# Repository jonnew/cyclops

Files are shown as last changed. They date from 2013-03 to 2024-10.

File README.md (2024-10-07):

## Cyclops LED Driver
Precision, wide-bandwidth current source with optional optical feedback mode
for driving high-power LEDs and laser diodes. Good for sneaking optogenetic
stimuli between fast things (e.g. galvo flyback on a 2P system). Good for
_really_ controlling the amount of light you deliver during 1P imaging or
optogenetic stimulation.

If you have questions or comments, please come talk on the [open-ephys discord server](https://discord.gg/H2pH4Cp8xb) 
in the #stimulation channel.

### Features
- Ultra-precise
- High power
- Up to 1.5A per LED
- Wide bandwidth
    - \~2.5 MHz -3 dB bandwidth
    - Maximum 100 ns 1.0A rise and fall times
- Current and optical feedback modes
- Built-in waveform generation
- Over-current protection
- Modular
    - Arduino compatible: internal waveform generation
    - Also, accepts external analog, gate, or trigger inputs

### Stimulus generation options
- External stimulus sequencer
- External digital trigger
    - TTL logic level
- External analog waveform generator
    - 0-5V analog signals
- Internal 12-bit DAC
    - Synchronized across up to 4 drivers
    - Arduino library
    - Programmable triggering logic
    - Respond to USB input

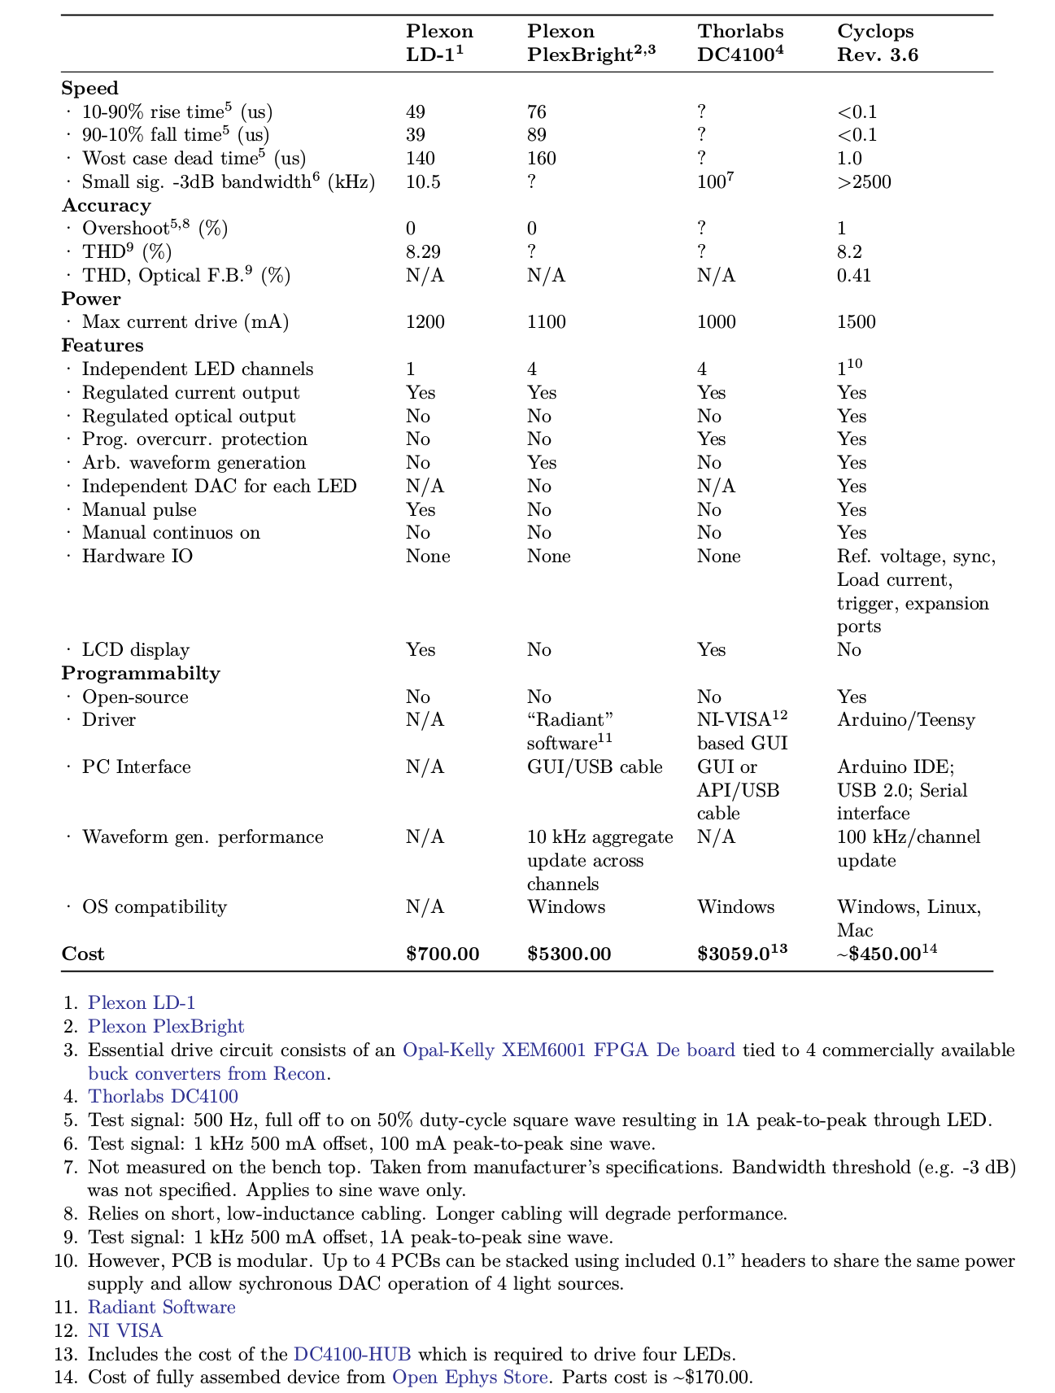
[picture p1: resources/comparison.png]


### Buying one
You can purchase a fully assembled cyclops driver from the [open-ephys
store](https://open-ephys.org/cyclops-led-driver). All profits go towards continued
operation of open-ephys.

### Documentation
Documentation and usage information are here: [MANUAL.pdf](./MANUAL.pdf). If you
have questions concerning usage, performance, etc., please direct them toward
the [Open Ephys forum](https://groups.google.com/forum/#!forum/open-ephys).

### Hardware Licensing
Copyright Jonathan P. Newman 2020.

This work is licensed under CC BY-NC-SA 4.0. To view a copy of this license,
visit https://creativecommons.org/licenses/by-nc-sa/4.0

__Note__: This license applies to hardware designs and documentation which reside
in the 'device', 'experimental', 'resources' folders of this repository along
with information in 'MANUAL.md' and 'MANUAL.pdf'

### Software Licensing
Copyright (c) Jonathan P. Newman 2017. All right reserved.

The code associated with the Cyclops project is free software: you can
redistribute it and/or modify it under the terms of the GNU General Public
License as published by the Free Software Foundation, either version 3 of the
License, or (at your option) any later version.

The code associated with the Cyclops project is distributed in the hope that it
will be useful, but WITHOUT ANY WARRANTY; without even the implied warranty of
MERCHANTABILITY or FITNESS FOR A PARTICULAR PURPOSE.  See the GNU General
Public License for more details.

You should have received a copy of the GNU General Public License along with
this code.  If not, see <http://www.gnu.org/licenses/>.

__Note__: This license applies to software/fireware source code which resides in in
the 'lib' folder of this repository

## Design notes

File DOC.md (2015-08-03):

__Cyclops__ is a high-power LED driver that enables precise control of light
power for optogenetic stimulation. The circuit was developed by Jon Newman
while in Steve Potter's lab at Georgia Tech in order to complete his thesis
work, which required the delivery of ultra-precise, continuously time-varying
light waveforms for optogenetic stimulation [1].  This was, and still is, not
possible with commercial hardware for optogenetic stimulation. Since its first
use, the circuit has been improved in terms of speed, precision,
programmability, and ease of use. This document provides construction, usage,
and performance documentation for the Cyclops LED driver. This document evolves
with the repository. To view old revisions, checkout tags or old commits using
their SHA.

<!-- START doctoc generated TOC please keep comment here to allow auto update -->
<!-- DON'T EDIT THIS SECTION, INSTEAD RE-RUN doctoc TO UPDATE -->
**Table of Contents**  *generated with [DocToc](https://github.com/thlorenz/doctoc)*

- [Features](#features)
- [Performance Specifications](#performance-specifications)
- [Usage](#usage)
  - [Feedback Modes](#feedback-modes)
    - [Current Feedback Mode](#current-feedback-mode)
    - [Auxiliary Feedback Mode](#auxiliary-feedback-mode)
  - [Stimulus Generation Options](#stimulus-generation-options)
- [Construction](#construction)
  - [Components](#components)
  - [PCB Assembly](#pcb-assembly)
  - [Enclosure](#enclosure)
  - [Circuit testing](#circuit-testing)
- [License](#license)
  - [Hardware Licensing <a rel="license"](#hardware-licensing-a-rellicense)
  - [Software Licensing](#software-licensing)
- [References](#references)
- [TODO](#todo)

<!-- END doctoc generated TOC please keep comment here to allow auto update -->

### Features
**Circuit Features**

- Ultra-precise
- High power
- Up to 1.5A per LED
- Wide bandwidth
  - ~2.5 MHz -3 dB bandwidth
  - <200 ns 1.0A rise-time
- Current and optical feedback modes
- Built-in waveform generation
- Over-current protection
- Modular
  - Arduino compatible
  - 4 synchronizable optical channels
  - Accepts external analog, gate, or trigger inputs

**Stimulus Generation Options**

- External stimulus sequencer
- External digital trigger
  - TTL logic level
- External analog waveform generator
  - 0-5V analog signals
- Internal 12-bit DAC
  - Synchronized across up to 4 drivers
  - Powerful Arduino library
  - Programmable triggering logic
  - Respond to USB input

### Performance Specifications
TODO

### Usage
#### Feedback Modes
The main functional component of the device is a feedback assisted, power,
enhancement-mode N-MOSFET
([IRF510](http://www.vishay.com/docs/91015/sihf510.pdf)). Current is drawn from
the source pin of the FET in accordance with one of two feedback modes: **current
feedback** or **auxiliary feedback**. In both modes, the FET acts as a variable
resistor whose resistance is changed in inverse relation to the gate voltage.
The difference between the two modes is in how the gate voltage is regulated.

- In **current feedback mode**, the gate voltage is adjusted such that the
  voltage drop across the sense resistor (RSENSE = 1 ohm in the schematic) is
  equal to a supplied reference voltage.
- In **auxiliary feedback mode**, some external voltage that has a positive and
  monotonic relationship with optical power is provided as a feedback signal.
  This is feedback voltage is typically supplied by an amplified photodiode

##### Current Feedback Mode
To use current feedback mode, push the rear slide switch to the CURR position (Current feedback mode.).
Using the circuit in current feedback mode ensures that the forward current
across the LED is precisely regulated according the voltage at the VREF pin.
This configuration is a standard method for driving LEDs because the
relationship between current and LED irradiance is smooth and monotonic. This
means that more current across the LED will generate more light power (while
staying within the LED's maximum ratings, of course). However, the relationship
between current and irradiance is not linear. For most LEDs, it looks like a
logarithmic function. Additionally, the efficiency of the LED is inversely
related to its temperature. So, as the LED operates and heats up, the amount of
light it produces drops even when the current is held constant. The severity of
an LED's temperature dependence and current/irradiance nonlinearity depend on
the type of LED (roughly, the color and who made it). These properties should
be clearly documented in the LED's data sheet. With a quality LED and proper
thermal management, the effects of temperature and static current/irradiance
nonlinearity are fairly minimal and can be ignored in most situations.

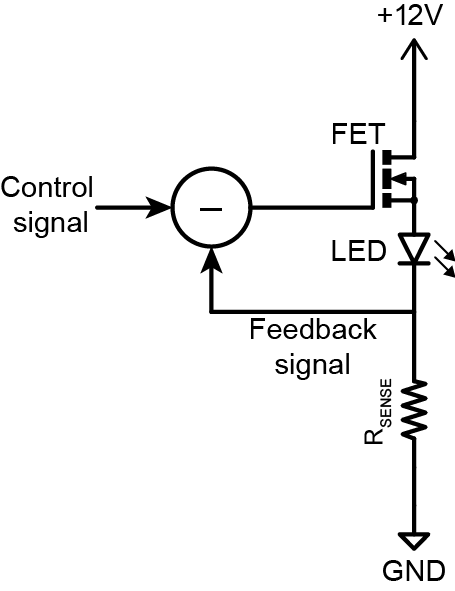
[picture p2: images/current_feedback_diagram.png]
Current feedback configuration.


##### Auxiliary Feedback Mode
To use auxilary feedback mode, push the rear slide switch to the AUX position (Auxilary feedback mode.).
When extremely stable, linear control of light power is required, the auxiliary
feedback input can be used to used to compensate for the temperature dependence
and static nonlinearity of the current/irradiance relationship of the LED. For
example, when the auxiliary voltage is supplied by an amplified photodiode that
is somewhere indecent to radiation from the LED, or is sampled from the fiber
transporting LED light, the gate voltage is adjusted such that the measured
light power matches a DAC-supplied reference voltage.  This is the case in the
circuit diagram. This configuration is referred to as optical feedback mode.
The [PDA36A](https://www.thorlabs.com/thorProduct.cfm?partNumber=PDA36A)
adjustable amplified photodiode from Thorlabs is a good option for supplying
optical feedback. However, you can make your own amplified photodiode for a
fraction of the price, and a design is included within the cyclops repository.
Optical feedback completely linearizes the relationship between a supplied
reference voltage and the light power produced by the LED by compensating for
the current/irradiance nonlinearities and temperature dependence.

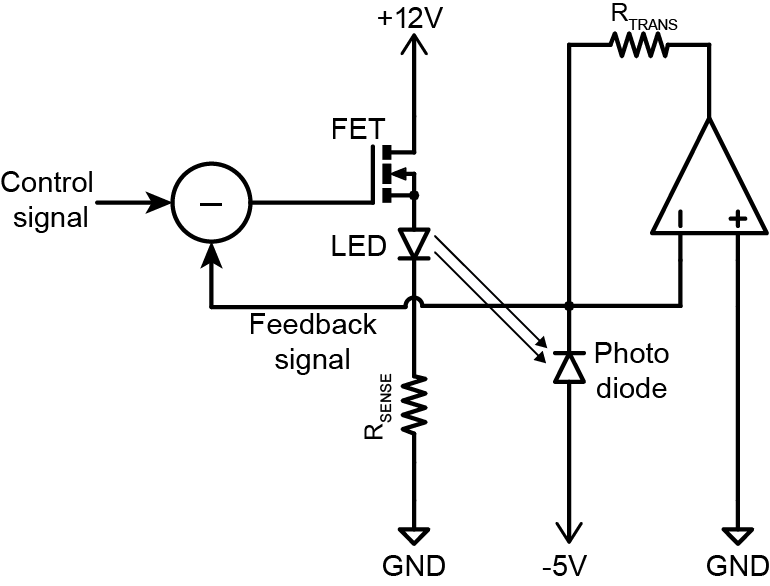
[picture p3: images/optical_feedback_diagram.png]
Optical feedback configuration.


#### Stimulus Generation Options
There are three ways to generate light signals using the driver. The behavior
of each of these options is dependent on the feedback mode being used. The
behavior of each input option is described in relation to the feedback mode of
the driver.

1. Test button. The test button is always available and will override all other input
   modes. Using the `TEST` button the behavior of the circuit is:

  - Current feedback mode. Source the current specified by the MAX CURR. dial.
  - Auxilary feedback mode. Generate the optical power specified by the h * mW
    level that is  specified by the MAX POWER dial. The intensity of the LED
    will be dependent on the auxiliary feedback signal used which defines the
    'h' parameter. 

2. EXT mode. External input mode is engaged when the SOURCE switch is moved to the EXT
position and user supplied voltage waveforms are present at the EXT BNC input.
If the user attempts to supply more than 5V to the EXT input, the circuit will
clamp the input signal to 5V. Using `EXT` mode, the behavior of the circuit is:

  - Current feedback mode. Source the current specified by (EXT Voltage / 5V) *
    MAX CURR. 
  - Auxilary feedback mode. Generate the optical power specified by (EXT
    Voltage/5V) * h  * mW. The intensity of the LED will be dependent on the
    auxiliary feedback signal used which defines the 'h' parameter. 

3. DAC mode. The internal DAC is engaged when the SOURCE switch is moved to the
DAC position and can be used to generate pre-programmed waveforms and waveform
sequences triggered by a digital pulse to the TRIG input. This feature relies
on optional Arduino installation and programming the device using its API.
Using the `DAC` mode, the behavior of the circuit is:

  - Current feedback mode. Source the current specified by (DAC Voltage / 5V) *
    MAX CURR. 
  - Auxilary feedback mode. Generate the optical power specified by (DAC
    Voltage/5V) * h  * mW. The intensity of the LED will be dependent on the
    auxiliary feedback signal used which defines the 'h' parameter. 

### Construction 
If you have questions during device assembly, please direct them to the
[open-ephys forum](https://groups.google.com/forum/#!forum/open-ephys) so that
others may benefit.

#### Components 
The bill of materials (BOM) required to build a 1,2,3, or 4 devices is
available on [this google
doc](https://docs.google.com/spreadsheets/d/1YQR_ujrZgILNx3XjomLKWgzDvirwKrKaRbVVzmBgk-s/edit?usp=sharing).
Most of the parts can be purchased from Digikey, but there are a few components
that need to be bought from other sources such as Newark, Adafruit, and Samtec.
All vendor, part number, and quantity information is listed on the BOM. If you
are having trouble getting a part, check the BOM since there are alternative
suppliers listed for some parts. As a convenience, the spreadsheet contains
links to a pre-populated Digikey cart (which are optimized for quantity
discounts).

The PCB can be purchased from OSH park
[here](https://oshpark.com/shared_projects/N5vW5JmD) or Seed Studio
[here](http://www.seeedstudio.com/service/). This is a four layer PCB. Note
that OSH park sells a minimum of 3 boards per order and Seed studio sells a
minimum of 5 boards per order. PCB stencils, useful for those performing reflow
or hot-air soldering, can be purchased from a service like [OSH
stencils](https://www.oshstencils.com) using the gerber files located in
`./cyclops/stencil`. If you plan to hand solder the board, then you do not need
to purchase these stencils.

The BOM includes several optional components, which are not in the
pre-populated Digikey cart. These include:

- An __extruded aluminum enclosure__, which houses the completed board. The
  enclosure is recommended because the large voltages and current transients
  used to drive high power LEDs can cause capacitive and inductive interference
  with nearby recording equipment. Acrylic front and rear panels can be
  purchased from Ponoko using the links supplied in the BOM. The instructions
  below show how these plastic pieces are modified to provide proper electrical
  shielding.
- An __M8-4 connector__. This is a rather expensive connector that allows
  cyclops to drive [Thorlabs LED
  modules](https://www.thorlabs.com/newgrouppage9.cfm?objectgroup_id=5206) or
  [Doric LED modules](http://doriclenses.com/life-sciences/243-led-modules).
    
#### PCB 
The cyclops PCB can be constructed by purchasing from one of the
pre-uploaded options:

- [OSH Park](https://oshpark.com/shared_projects/N5vW5JmD) - made in America, excellent quality.
- [Seeed Studio]() - made in China, very good quality.

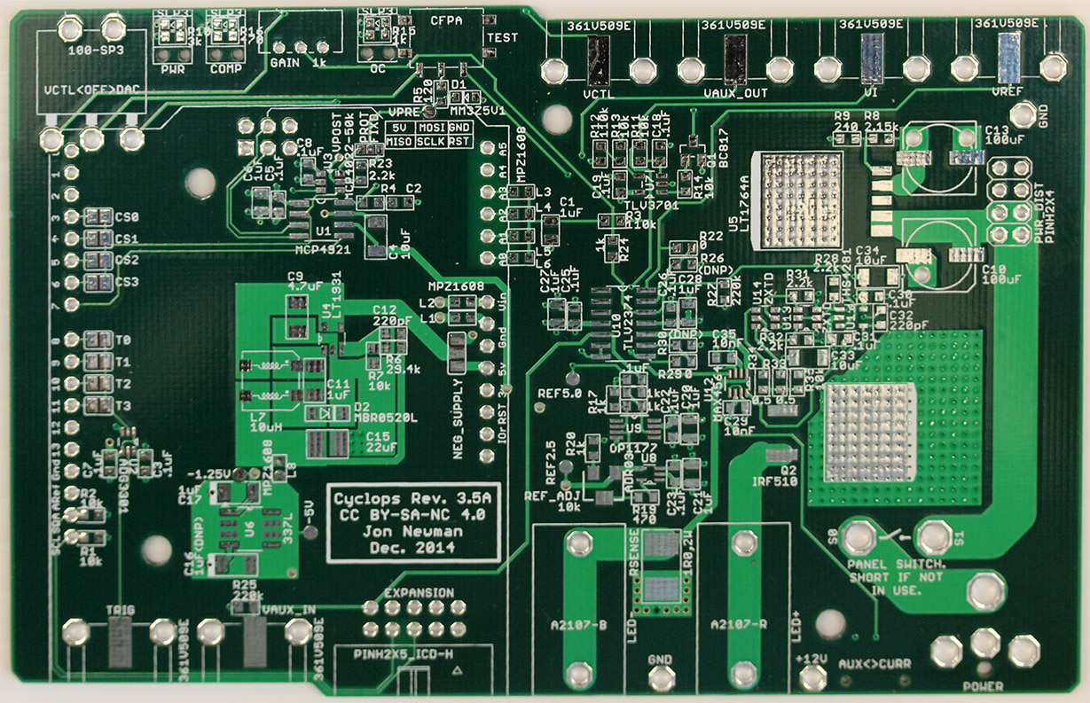
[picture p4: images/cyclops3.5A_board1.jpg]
A bare Cyclops PCB, top side, purchased from Seeed Studio.


Alternatively, the [gerber files](./cyclops/gerber/) can be uploaded to the PCB
fabrication service of your choice. The layer of each gerber file is identified
by its file extension:

     *.GKO = board outline 
     *.GTS = top solder mask 
     *.GBS = bottom solder mask
     *.GTO = top silk screen 
     *.GBO = bottom silk screen 
     *.GTL = top copper
     *.G2L = inner layer 2 copper 
     *.G3L = inner layer 3 copper 
     *.GBL = bottom copper 
     *.XLN = drill hits and sizes

#### PCB Assembly 
To assemble the PCB, you will need the following materials

- A soldering device. At minimum, a soldering iron regulated to ~370 deg.  c)
  will do the job. However, a hot-air rework tool or reflow oven are
  recommended and the assembly instructions below assume you are using one of
  these two options. A low cost, high-quality hot-air rework station can be
  purchased from SparkFun [here](https://www.sparkfun.com/products/10706).
- Copper braid ('solder wick') for solder removal (e.g
  [this](https://www.sparkfun.com/products/9327))
- Stereoscope or loupe (Optional) 
- Liquid flux (No-clean variants are easiest since they don't have to be
  removed after use)
- Isopropyl alcohol for cleaning flux off the board (e.g.
  [thos](http://amzn.com/B0047YB3OW); Optional)
- An anti-static mat (e.g. [this](http://amzn.com/B00009XT3H); Optional)

PCB component population and soldering is fairly straightforward and requires
standard surface mount construction techniques.

- A tutorial on hot-air soldering can be found [here](https://youtu.be/1z0IiuQ35HU).
- A great tutorial filled with general tips and tricks for surface mount soldering can be
found [here](https://youtu.be/pdGSFc7VjBE).

The following steps provide a visual guide to construct your own board. The
goal is to create a fully populated PCB like this one: 

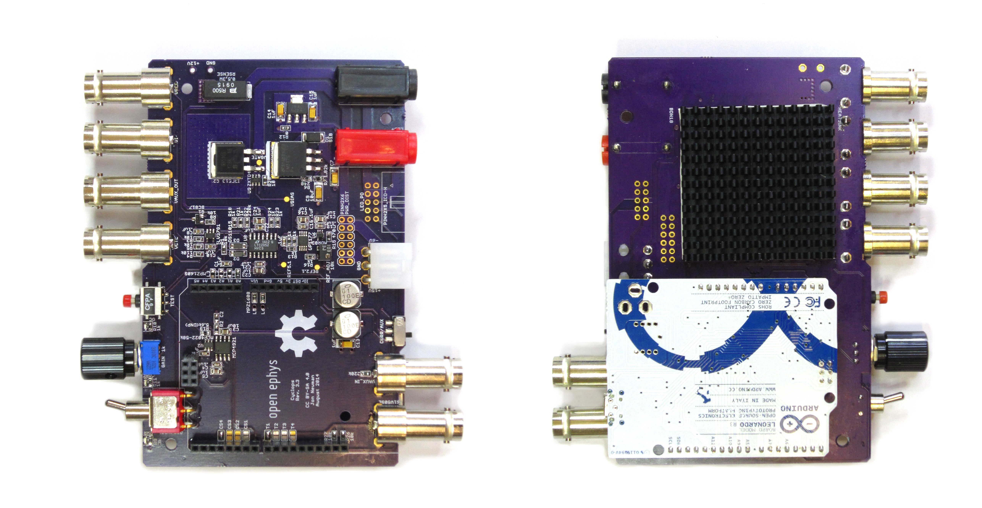
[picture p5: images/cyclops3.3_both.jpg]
Finished device (revision 3.3).


_After construction, you should run through the electrical tests outlined in
the next section before applying power to the board._

0. Place the bare PCB on a flat surface, preferably one that is static
   dissipative or anti-static. 

0. Below are pictured some of the materials you will need to construct a board.

    ![Wire solder and an soldering iron can be used to construct the PCB, but
    solder paste combined with a hot air rework station or a reflow oven makes
    things much easier. We use [Chipquik
    291ax10](http://www.digikey.com/product-detail/en/SMD291AX10T5/SMD291AX10T5-ND/3972568).](./images/SolderPaste.jpg)
  
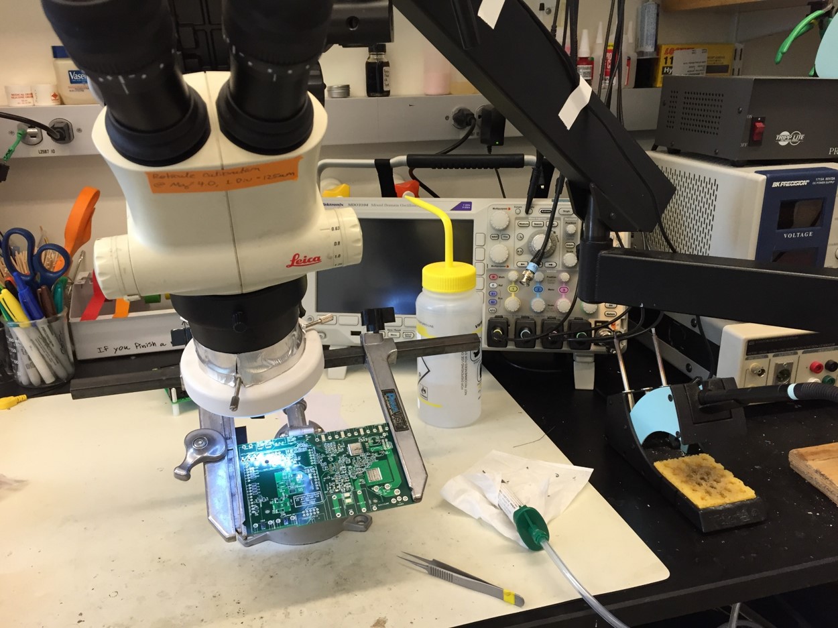
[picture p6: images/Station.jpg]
Instead of populating components on a table, holding the PCB using a PanaVise can be helpful.
    
  
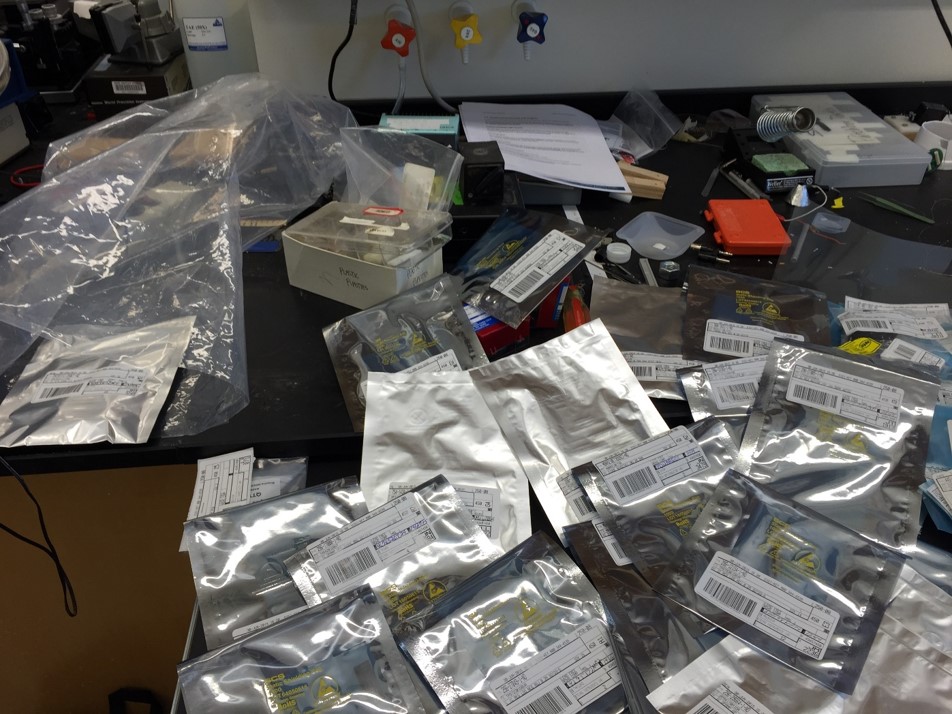
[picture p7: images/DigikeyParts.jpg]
Circuit components. A complete bill of materials is provided in the [BOM](https://docs.google.com/spreadsheets/d/1YQR_ujrZgILNx3XjomLKWgzDvirwKrKaRbVVzmBgk-s/edit?usp=sharing).
    
  
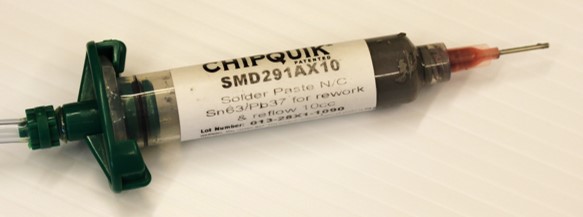
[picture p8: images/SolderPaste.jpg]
A soldering iron can be used to assemble the PCB, but a hot air rework station makes things much easier. These can be purchased from [Sparkfun](https://www.sparkfun.com/products/10706).
    

0. The silkscreen layer on the PCB (white text) has almost all the information
   you will need to properly populated the PCB. However, its a good ideal to to
   open the [cyclops design](./cyclops/cyclops_r3.brd) in
   [EAGLE](http://www.cadsoftusa.com/eagle-pcb-design-software/). This will
   allow you to get detailed information on components before placing them on
   the board.

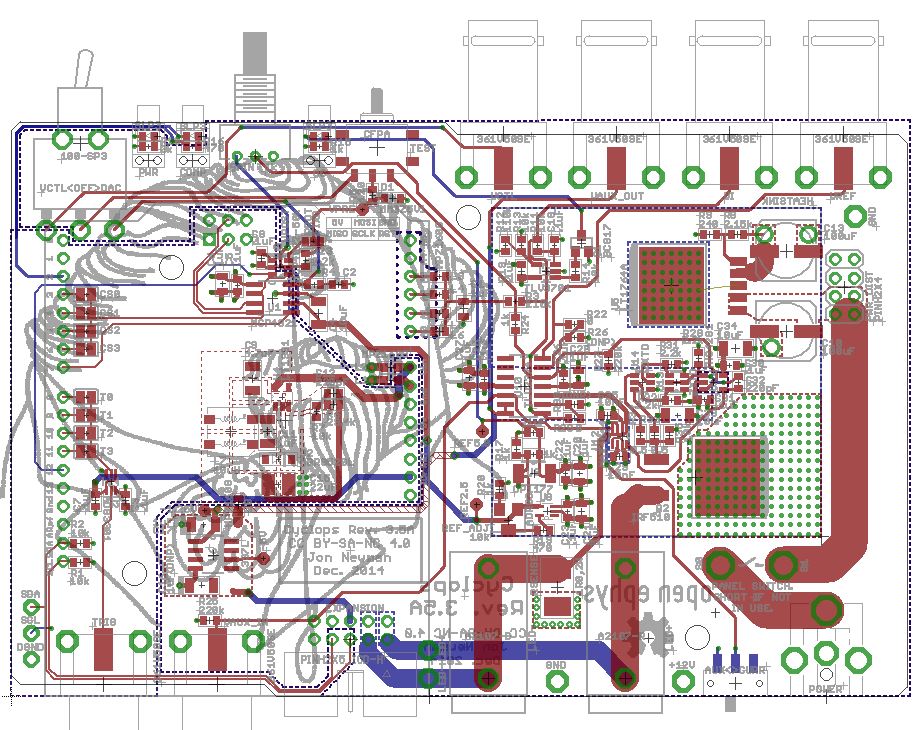
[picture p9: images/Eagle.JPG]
The cyclops PCB design in CadSoft EAGLE
    
  
    You can then the `information` tool to get detailed information on each
    component, e.g. to ensure you are placing the correct value resistor or
    capacitor.
  
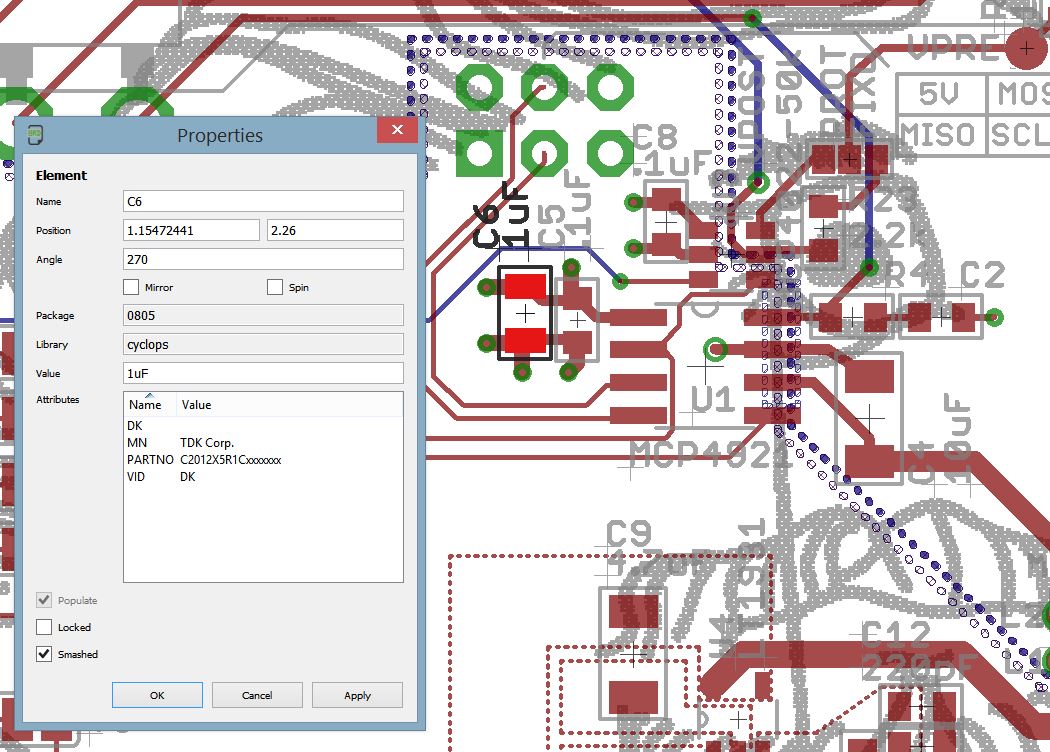
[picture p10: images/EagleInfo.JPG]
By selecting the information tool and clicking the cross at the center of a component, you can pull up detailed info (e.g. part number)
    

0. After cleaning the surface of the board with isopropyl acholhol or similar,
   apply solder paste to each of the pads. For an excellent series of tips on
   effective methods for dispensing solder paste, see [Mike's video on the
   subject](https://youtu.be/pdGSFc7VjBE). Do not apply solder paste to
   through-holes or the pads shown outlined in red in the following image.
   These will be hand soldered later in the assembly process.

    Do not apply paste these solder pads.
  
    The correct amount of solder paste to apply is 'enough'. Each component
    contact should sit in a small amount of paste, but blobs of paste that
    envelop the component pad or pin may later result in a short. The following images
    show examples of good and bad solder placement.
  
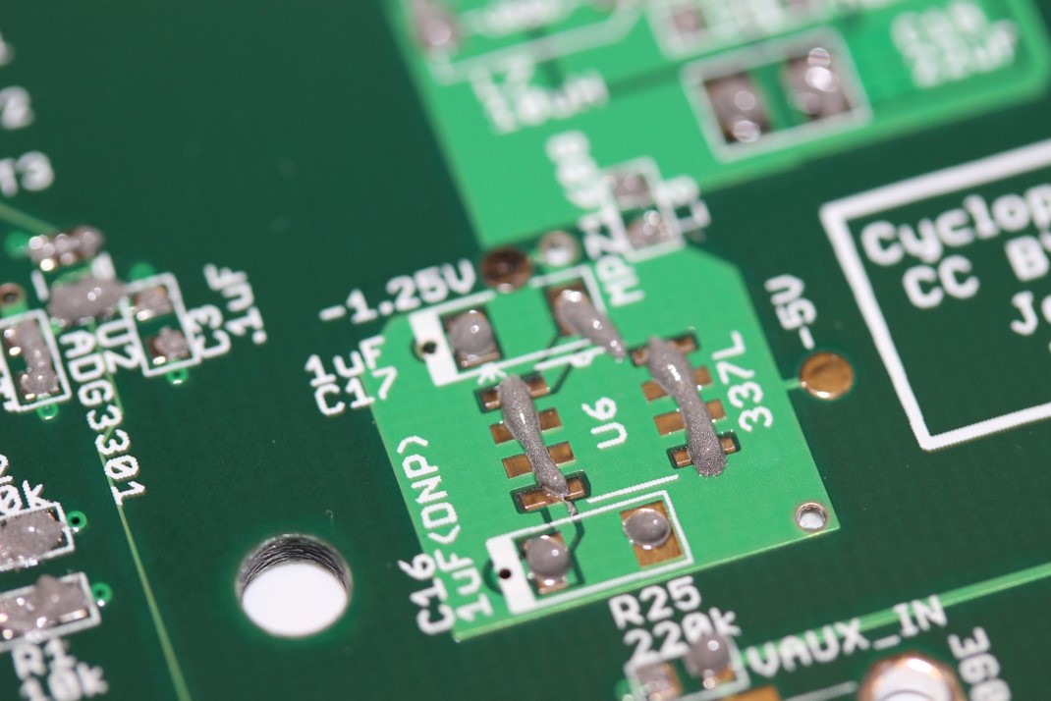
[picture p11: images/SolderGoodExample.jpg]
Good solder placement.
    
  
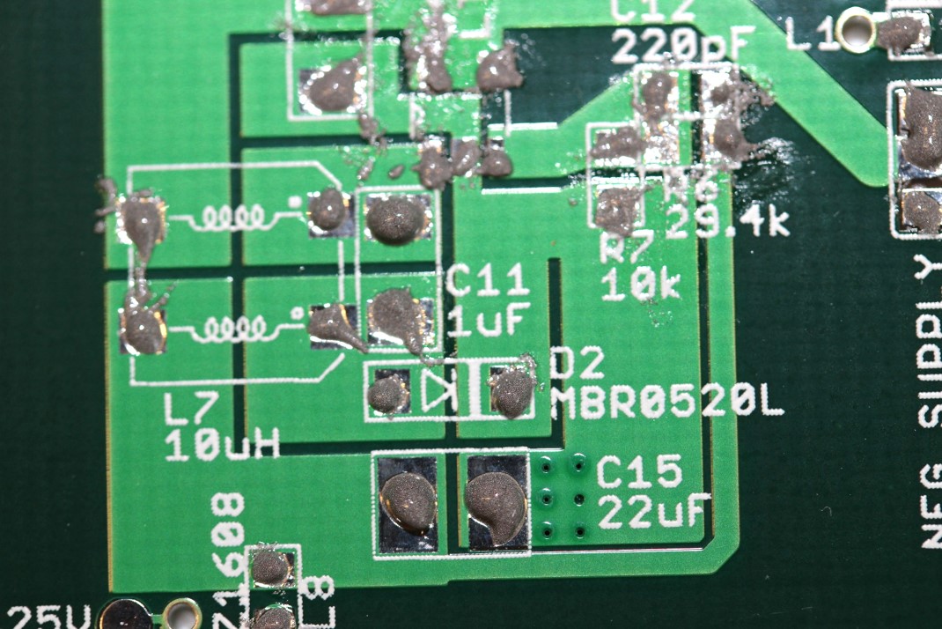
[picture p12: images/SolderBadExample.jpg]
Bad solder placement. Too much paste!
    

    If you need to pause at any point, you should store place the PCB in the
    fridge to prevent the flux in the solder paste from breaking down. 

0. You can look at the picture below and put solder on the exact same gold plates as in the picture. I actually missed some gold plates at this step, but don't worry for now. You can put solder just like this.

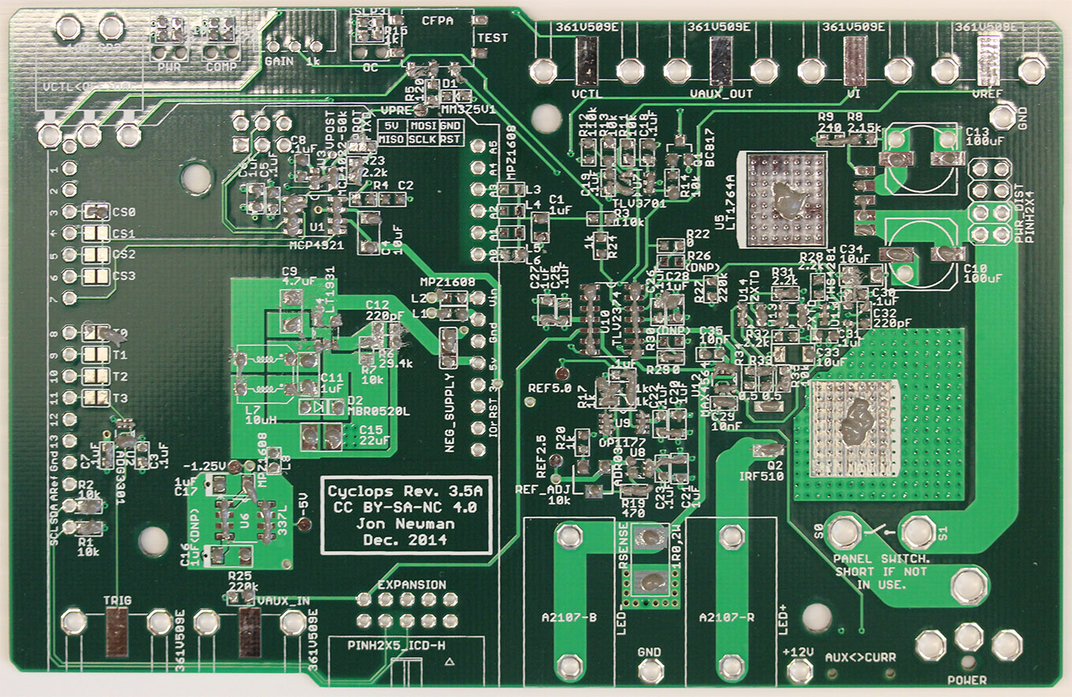
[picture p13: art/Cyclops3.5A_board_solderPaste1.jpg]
    <div align="center">  <br> <b>Fig. 7</b> <i>After putting solder paste to all necessary slots (a few are missing here) </i> </div>

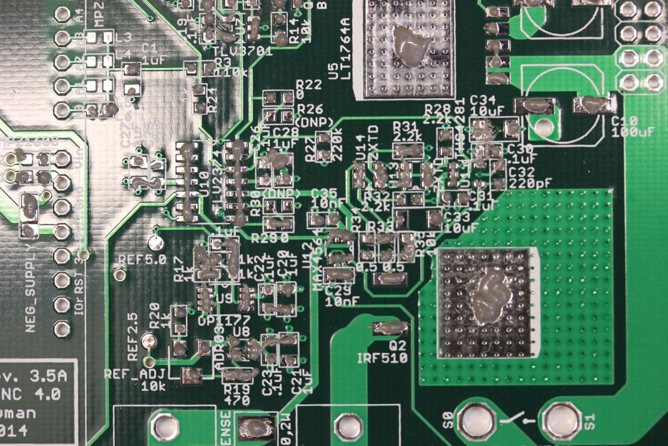
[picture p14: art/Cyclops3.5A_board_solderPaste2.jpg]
    <div align="center">  <br> <b>Fig. 8</b> <i>Closer look 1. Too much solder in general, but will work</i> </div>

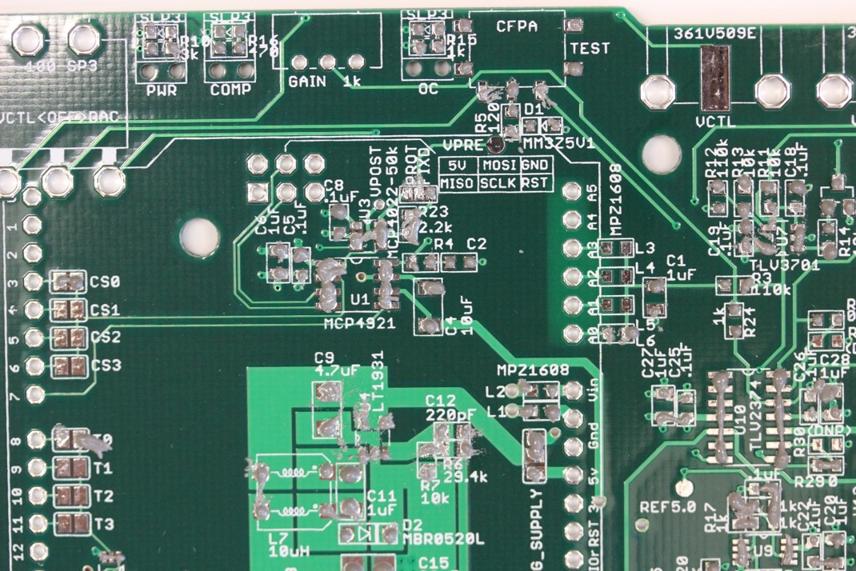
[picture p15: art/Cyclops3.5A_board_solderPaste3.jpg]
    <div align="center">  <br> <b>Fig. 9</b> <i>Closer look 2. Too much solder in general, but will work</i> </div>

0. Populate all __top-side surface mount__ components on the board. There is a
   single surface mount switch on the back of the board that will be hand
   soldered later. Additionally, all through hole components (e.g. power jack,
   BNC connectors, etc) will be populated later. Start by placing the
   integrated circuits (ICs). Use the stereoscope or loupe to ensure that pads
   are making contact with the pins of the placed components.  Precise
   component alignment is not necessary.  Components will self-align during the
   reflow process.

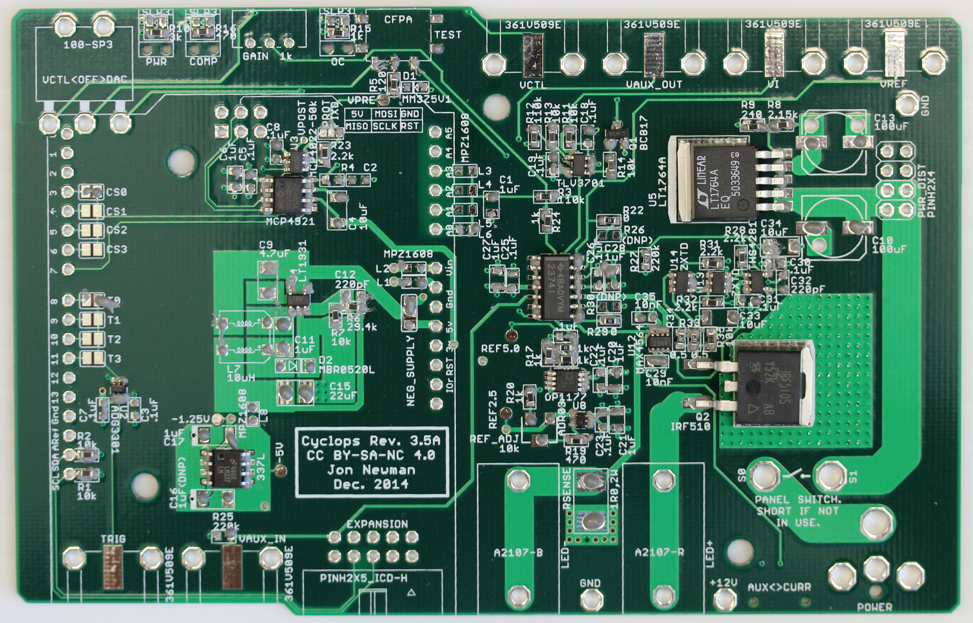
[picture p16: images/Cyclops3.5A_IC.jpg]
    

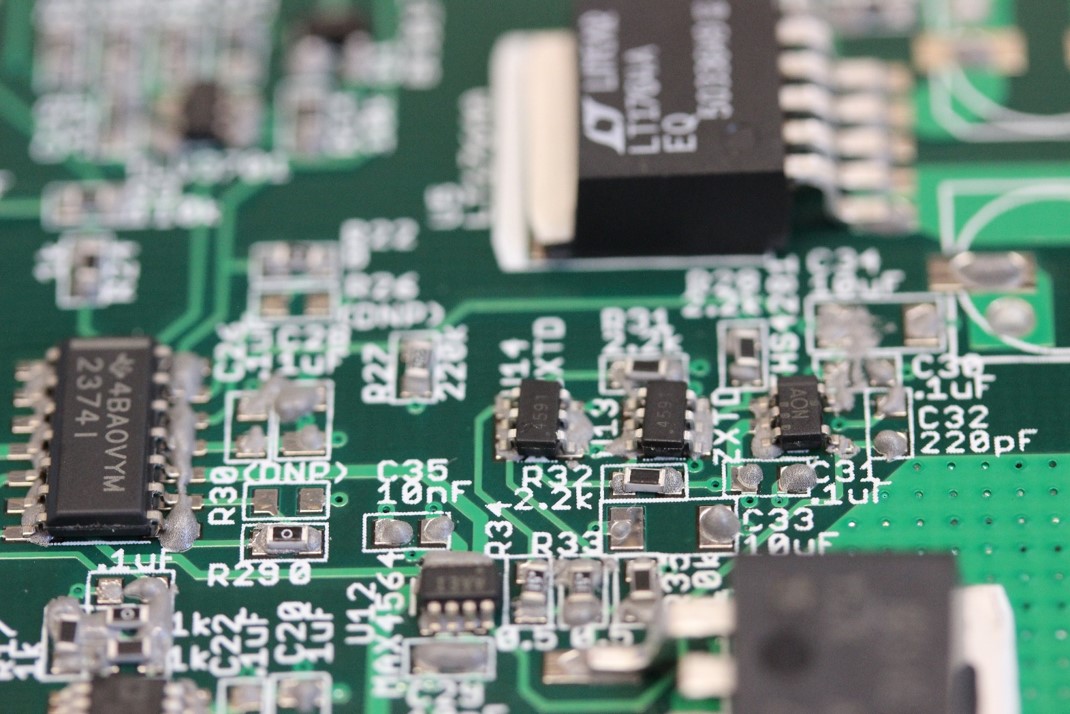
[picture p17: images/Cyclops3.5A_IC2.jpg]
Zoomed view of ingegrated circuit placement.
    

0. After placing the ICs, place the passive components (resistors,
   capacitors, inductors, and diodes).  

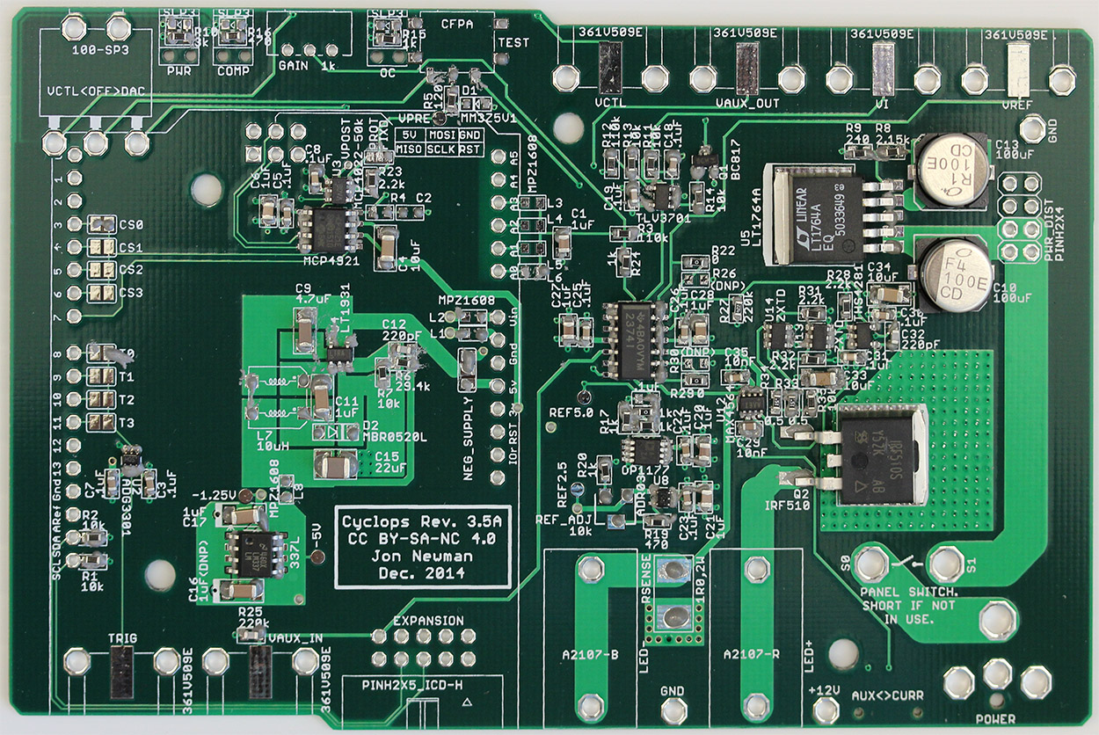
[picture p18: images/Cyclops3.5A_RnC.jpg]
    

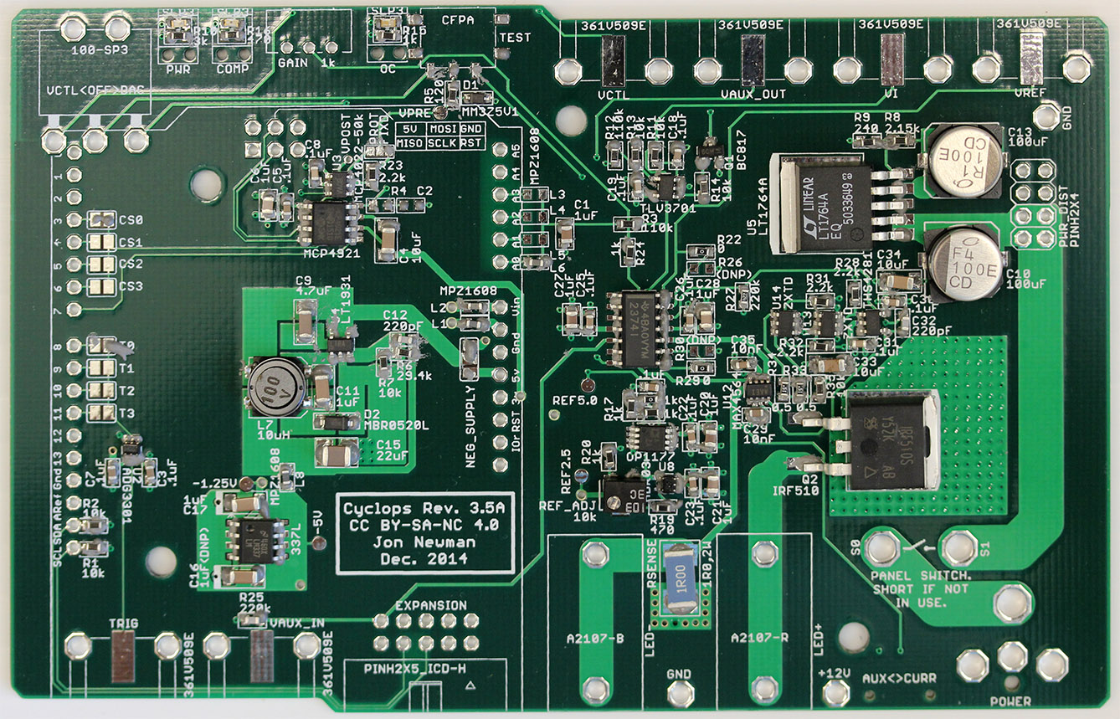
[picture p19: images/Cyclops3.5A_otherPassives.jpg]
    

0. Next step is to reflow solder. Let me show my homemade reflow oven. You can make a similar one or use a commercial one. Reflow the solder paste on the board using your oven or hot air gun as
described in the links above.  After the solder has cooled, examine solder pads
using the stereoscope of loupe for solder bridges between pins, solder that has
not melted, or pads lacking a decent solder joint Fix any issues using a
standard soldering iron If there are solder bridges present, get rid of them
using some solder wick before moving on.  Solder through-hole components in
place using a standard soldering iron. A low cost reflow oven can be made form a toaster oven as shown here. This link also
contains useful information on the basics of the reflow soldering process,

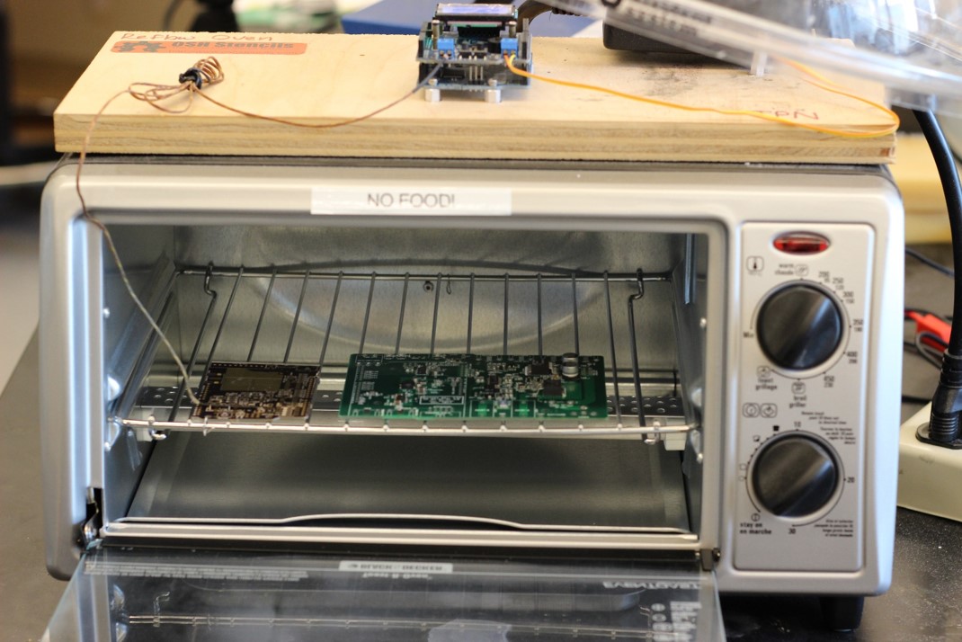
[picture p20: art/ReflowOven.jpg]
    <div align="center">  <br> <b>Fig. 14</b> <i>Carefully bring the PCB and place it in the oven like this.</i> </div>

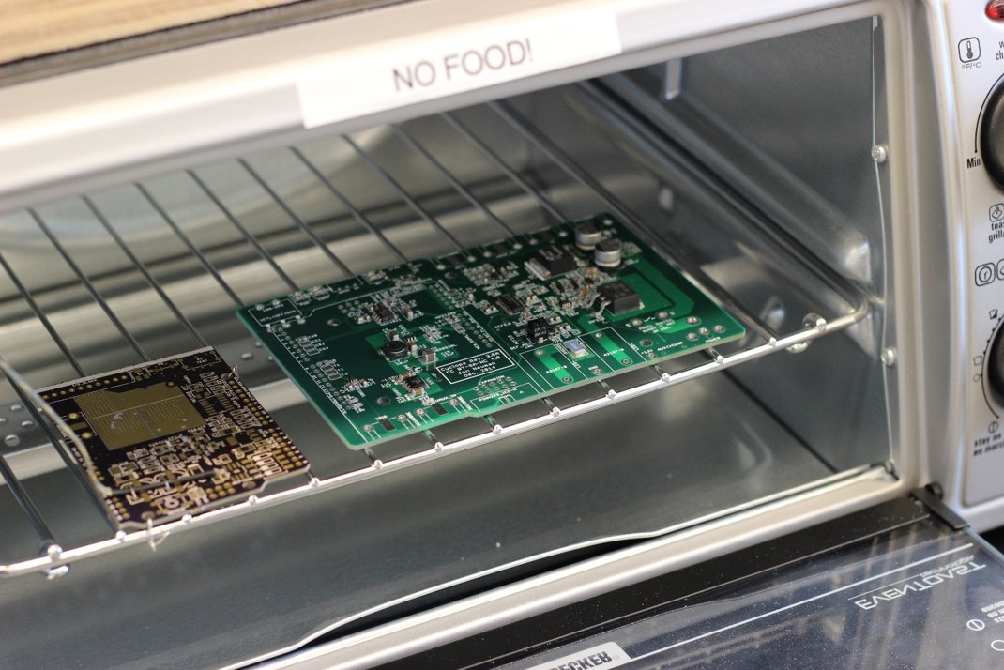
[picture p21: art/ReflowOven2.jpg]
    <div align="center">  <br> <i>Here is a closer look.</i> </div>

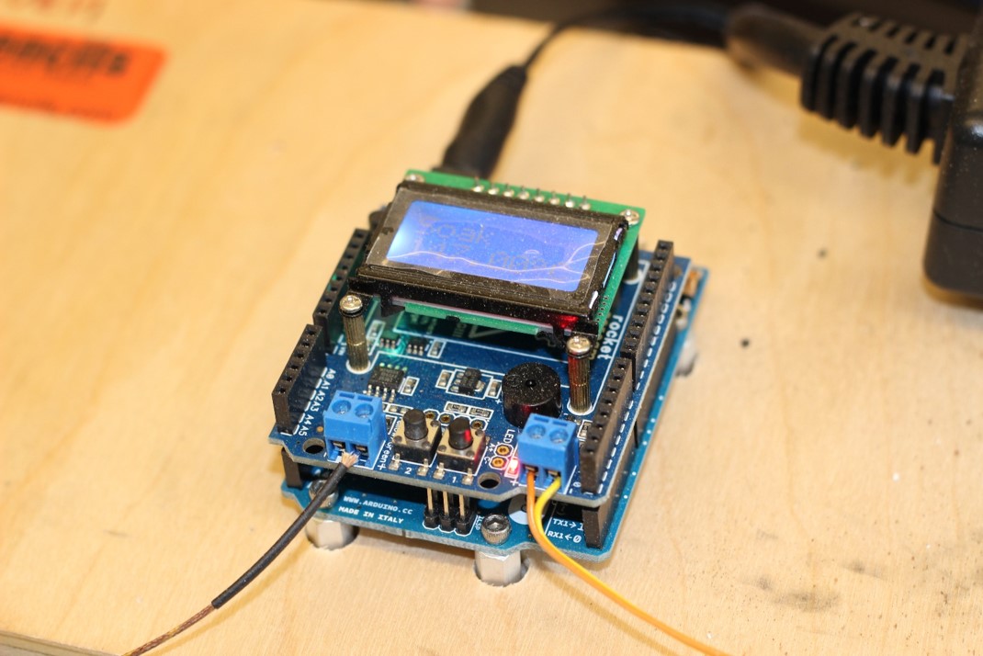
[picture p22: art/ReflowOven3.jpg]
    <div align="center">  <br> <i>A board...</i> </div>

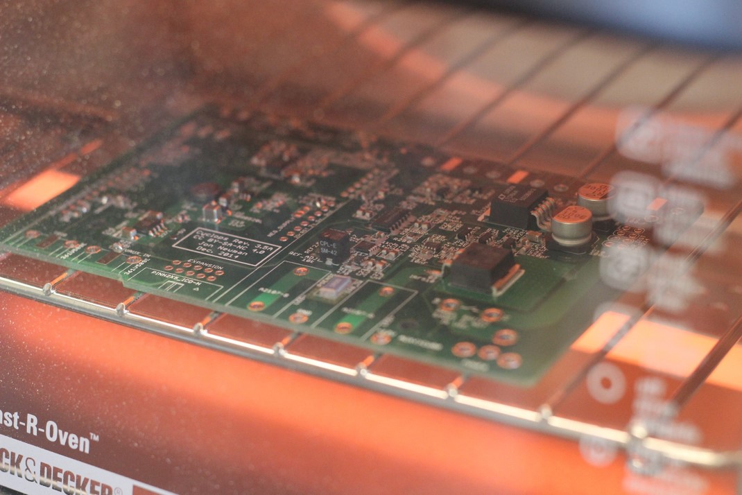
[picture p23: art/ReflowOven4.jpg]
    <div align="center">  <br> <i>As it goes above 200C, the solder starts to reflow. Like a live worm</i> </div>

0. After reflow, take the PCB out and check for possible shorts. We need to fix it.

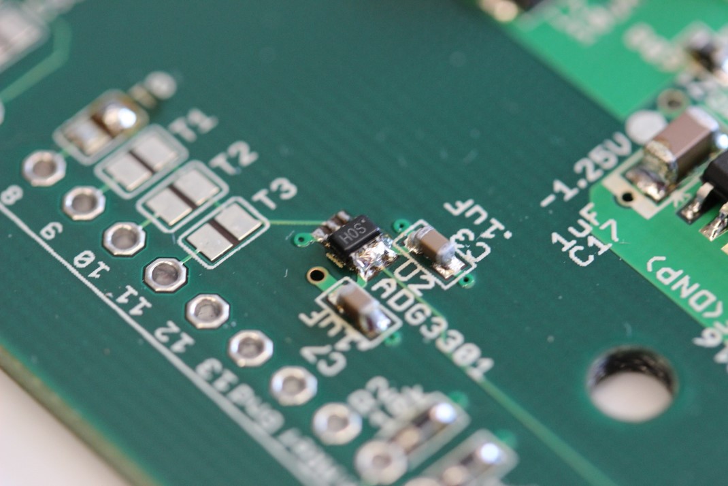
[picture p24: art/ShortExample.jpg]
    <div align="center">  <br> <b>Fig. 15</b> <i>See the blob of solder there?</i> </div>

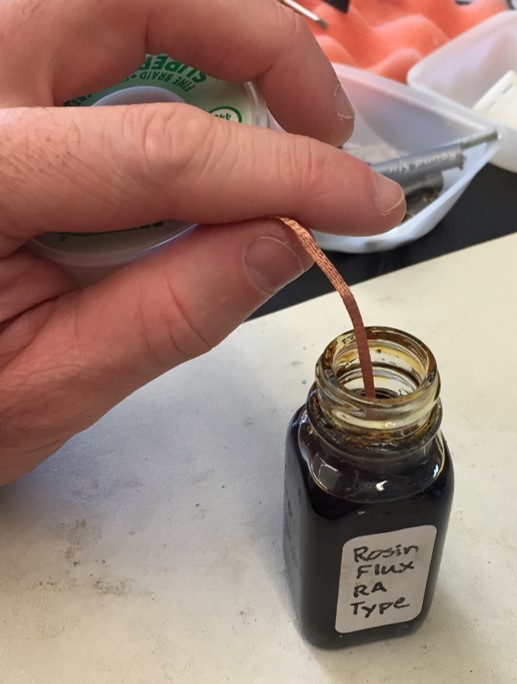
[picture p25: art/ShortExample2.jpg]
    <div align="center">  <br> <b>Fig. 16</b> <i>Use this solder remover and flux</i> </div>

    <div align="center">  <br> <b>Fig. 17</b> <i>Bring it to the solder blob and sort of press it down with solder. Then the solder gets absorbed to the remover.</i> </div>

    <div align="center">  <br> <b>Fig. 18</b> <i>Problem fixed! There is enough solder after removal, so mostly you don't need to worry about connection.</i> </div>

    <div align="center">  <br> <i>By the way, there are some differences between different versions of the board. For example, 1 kOhm there in the middle of the picture was replaced to a 0 ohm one in the newer version.</i> </div>

0. Now populate all electromechanical parts. The barrel power jack (name: "POWER", value: PJ-063BH on the schematic)
should be mounted on the _bottom_ of the board. It fits on both the top and the
bottom, and will properly supply the board with power if mounted on the top.
However, if the barrel jack is mounted on the top side of the board, it will
not fit inside the enclosure.

    <div align="center">  <br> <b>Fig. 19</b> <i>After populating all electromechanicals. Front side.</i> </div>

    <div align="center">  <br> <b>Fig. 20</b> <i>After populating all electromechanicals. Back side.</i> </div>

    <div align="center">  <br> <i>Front side..</i> </div>

    <div align="center">  <br> <i>Front side, with different camera focus..</i> </div>

    <div align="center">  <br> <i>Back side..</i> </div>

    <div align="center">  <br> <i>Back side, with different camera focus..</i> </div>

0. Don't forget to install the heatsink.

0. The light pipes over the front LEDs need to be seated firmly for the board
to fit inside the enclosure.

0. Each board has an address (0 through 3) that is defined by two solder
jumpers and the location of a ferrite chip. This allows cyclops boards to be
stacked to share a power supply while being driven by a common microcontroller.
For each board that will share a microcontroller, a unique address must be
specified and the solder jumpers and ferrite chip must be soldered in
appropriate positions to reflect this address. See the picture below to better
understand this addressing scheme.

0. Finally, let's install the power switch. You need to hookup wire capable of
handling the currents that the driver requires. AWG 20 (~0.8 mm diameter)
braided copper wire or thicker is recommended. Even if you don't want to use
the power switch, jumper the switch solder points using AWG 20 wire or thicker.

    <div align="center">  <br> <b>Fig. 21</b> <i>Power switch.</i> </div>

    <div align="center">  <br> <b>Fig. 22</b> <i>Front side.</i> </div>

    <div align="center">  <br> <b>Fig. 23</b> <i>Back side.</i> </div>

#### Enclosure
To construct the enclosure, you we will use the following materials

- Phillips head screwdriver (if
you are using the enclosure) 
- A white paint pen (e.g. these)
- Conductive coating for EMI suppression (e.g. this).

#### Circuit testing
To perform basic electrical testing, you we will use the following materials

- Multimeter. A low cost mulitmeter is available from
[sparkfun](https://www.sparkfun.com/products/12966).
- Jeweler's flat head screwdriver.
- Oscilloscope (optional, but recommended for performance verification)

0. Before powering on the device, check for shorts
between power traces on the board. Put your multimeter in continuity mode
Check for shorts between the Digital rail (TPXX) and ground (TPGND) Analog rail
and ground If there is a short, you must track it down and get rid of it before
applying power. If you find a short, test the same contact points on an unpopluated PCB to ensure that it is not due to a PCB fabrication defect. If so, contact your PCB for a return.

### License 
#### Hardware Licensing <a rel="license"
href="http://creativecommons.org/licenses/by-nc-sa/4.0/"></a><br /><span
xmlns:dct="http://purl.org/dc/terms/" property="dct:title">Cyclops LED
Driver</span> by <a xmlns:cc="http://creativecommons.org/ns#"
href="https://github.com/jonnew/cyclops" property="cc:attributionName"
rel="cc:attributionURL">Jonathan P. Newman</a> is licensed under a <a
rel="license" href="http://creativecommons.org/licenses/by-nc-sa/4.0/">Creative
Commons Attribution-NonCommercial-ShareAlike 4.0 International License</a>.<br
/>Based on a work at <a xmlns:dct="http://purl.org/dc/terms/"
href="https://github.com/jonnew/cyclops"
rel="dct:source">https://github.com/jonnew/cyclops</a>.

#### Software Licensing 
Copyright (c) Jonathan P. Newman All right reserved.

The code associated with the Cyclops project is free software: you can
redistribute it and/or modify it under the terms of the GNU General Public
License as published by the Free Software Foundation, either version 3 of the
License, or (at your option) any later version.

The code associated with the Cyclops project is distributed in the hope that it
will be useful, but WITHOUT ANY WARRANTY; without even the implied warranty of
MERCHANTABILITY or FITNESS FOR A PARTICULAR PURPOSE.  See the GNU General
Public License for more details.

You should have received a copy of the GNU General Public License along with
this code.  If not, see <http://www.gnu.org/licenses/>.

### References 
[1] T. Tchumatchenko\*, J.P. Newman\*, M.-f. Fong, S.M. Potter.
[Delivery of time-varying stimuli using
ChR2](http://journal.frontiersin.org/article/10.3389/fncir.2013.00184/full#).
(\* - equal contributions, co-first authors) Front. Neural Circuits (7:184)
2013.  doi: 10.3389/fncir.2013.00184

### TODO
**Revision 3.6**
- [ ] Get [DOC.md](DOC.md) in working order
- [ ] Create an fiber coupled LED interface with integrated optical power
  measurements
  - [In progress](https://github.com/jonnew/cyclops/tree/master/photodiode)
- [ ] High side current sense
- [ ] Arduino gets replaced with a
  [Teensy](https://www.pjrc.com/teensy/teensy31.html).

**Revision 3.5B**
- [ ] Get the board on CircuitHub
- [ ] Get the device on the Open Ephys store
- [ ] The rear panel holes seems to have slight vertical offsets
  - LED jacks: 1 mm to low 
  - Expansion header: 1 mm to low 
  - Aux/curr switch: 0.25 mm to low
  - *EDIT* After further inspection it seems like the expansion header might
    be 90% of the problem. Recheck before making changes.
- [x] The LED polarity labels on the panel are reversed 
- [x] Sometimes, because of intrinsic tolerance issues, the 5.1V zener's
  reverse breakdown is too low and it affects valid signals in the 0-5V range.
  Get a more reasonable value, e.g. 6V, zener.
  - *EDIT* This was due to a bad zener. Ignore this change. 
- [x] Trade out the LT1964A for a LT1764A, which has a 3A output capability and
  a will allow the circuit to read 1.5A instead of crapping out at 1.25 since
  the quiescent circuit is current hog.
- [x] Put some extra through holes in for wire-to-board access to +/- LED,
  digital GND, and I2C bus for EEPROM on thorlabs leds.

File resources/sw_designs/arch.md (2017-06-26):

# Handling multiple Waveform channels
The problem we have here is because multiple channels have to utilise a shared resource (SPI bus) asynchronously. This is a well studied Operating Systems problem and there are 2 solutions: *Synchronised Access* (using "locks" / "global flags") or *Scheduling*.  
Scheduling of arbitrarily timed requests is not possible, but enforcing some assumptions *(or restrictions)* on the nature of requests helps simplify design.  
Synchronisation ignores timing altogether and is hence not an option for Cyclops.

>Note, 2B can be transfered on SPI in no less than 640 ns (25MHz). Typical SPI speeds are 15MHz => 1067 ns.

# Naive Approach [4 timers]

Setup one timer for each channel. Also, a separate Latch Line should be made available as the channels might not always be in sync. (Separate Latch Lines are available already, or probably some change is needed on the PCB?)

Consider a square wave of period \\(P\\) and duty cycle of 40%.
At each timer interrupt,

1. the period would change from \\(0.4 \times P\\) to \\(0.6 \times P\\) or vice versa.
2. the corresponding voltage would be written via SPI to Cyclops DAC.
3. Latch line would be activated, for this particular DAC.

## Cons
What would happen if timer triggers overlap? There is only 1 SPI resource which must be shared by all 4 channels. This means, a channel trigger might have to wait, effectively *"glitching"* that channel's waveform.  
We cannot guarantee precise waveforms with this approach.

# Single Timer, with lazy Latch and quick SPI write

A single hardware timer is used. It's period is updated at each "event" (interrupt).
> Using multiple timers would require proper synchronisation. Scheduling is not possible with multiple timers, and hence no guarantees on precise updates can be made.

This would require implementation of waveform objects and a task queue. These objects have various other benefits too.
Assumption #3 *(below)* could be asserted by the Cyclops library, giving a warning like
```
Precise updates cannot be guaranteed because few waveforms have very small update times.
```

(atleast for stored waveforms) after compilation.

## Some Assumptions and Notations
1. Say \\(N\\) Waveform channels (\\(W_{i}\\)) are active.
2. SPI writes require \\(\gamma\\) seconds for a 2B write.
3. A waveform would *never* require an update within \\(N \times \gamma\\) seconds.
4. Separate Latch Lines to each DAC are available.
5. Timer Interrupt has highest priority. (This does not increase latency of implementing commands from PC. Teensy has programmable interrupt priorities.)

>**Note that the Naive approach does not guarantee precise updates even under assumption #3.**

#### Explanation of Assumption #3
To guarantee precise waveform updates, our minimum time-period is limited by the SPI transfer speed. To update \\(N\\) channels even once we require a minimum of \\(N \times \gamma\\) seconds, since the updates cannot be done parallely.

Minimum N-gamma period

If the set of writes violates #3, no schedule of these writes can ensure precise updates of *all channels*, even in the future. But even when assumption #3 is valid, proper scheduling is required or glitching would occur, as shown below.

More than N-gamma period

## Waveform objects
These provide methods `nextVoltage()` and `holdTime()` which return the voltage needed at next interrupt point and the time to hold that voltage level resp.
Waveform objects can be in one of 3 states: 

* `init`
    - Just after boot, nothing written to DAC.
* `prepared`
    - "Next" value has been written in DAC.
* `latched`
    - DAC has been latched after the timer interrupt. DAC needs to be prepared for next interrupt.
    - transition from `prepared` to `latched` happens in an ISR, whereas `latched` to `prepared` does not.

Waveform State Diagram

Every waveform object has a `time_remaining` field. `time_remaining` field is the time for which the voltage needs to held at the current level from "this" interupt-instance onwards.

## Modus Operandi

The CPU is primarily tasked with `Preparing_DACs`. It tries to prepare DACs as fast as possible with their `nextVoltage`. The DACs are latched by the CPU when the timer interupts.
Just after boot, timer interrupts are ignored till all active channels have moved from `init` to `prepared`.
When there are no more channels in `init`, CPU latches all of them together and sets the timer-period to the smallest `holdTime`.

### Interrupts
Take a leap of faith and say, at some point in operation, an interrupt has fired:
The timer interrupts CPU to latch a [prepared DAC](#prepared).
Say the interrupt was for latching \\(W_{2}\\).

0. Disable interrupts.
3. Find which channel *(explained below)* needs to be latched now. (\\(W_{2}\\))
1. If \\(W_{2}\\) is `prepared` => `3i` else `4`
    2. Latch the value already in the `DAC2` *(which was meant to be latched* **now** *)*, using it's dedicated Latch Line.
7. Store the `W2.holdTime()` in `W2.time_remaining`.
4. Find which Channel *(explained below)* would require an update first, say \\(W_{0}\\). **This is the most important step.**
5. Update the timer period to trigger for \\(W_{0}\\), use `W0.time_remining` to compute the new period.
10. Subtract `W0.time_remining` from all others `WX.time_remaining`.
6. Increment the sequence count of \\(W_{2}\\).
8. \\(W_{2}\\) is now `latched`!
9. Enable interrupts. 

>The ISR is very short.

>An `SPI_DONE` interrupt desects all chips.

At the next timer interrupt, \\(W_{0}\\)'s DAC would be latched first thing, guranteeing a precisely timed update.
The system behaviour can be dscribed as `latch the prepared DAC` -> `prepare the next DAC` -> `latch next DAC on next interrupt`.

Interrupt Activity Diagram

#### How does ISR determine next Timer Period?
The CPU finds out which channel needs to be "Latched" **now**. Every waveform object has a `time_remaining` field. `time_remaining` field is the time for which the voltage needs to held as such from "this" interupt-instance onwards.
At *"this"* interrupt instance, `W2.time_remaining == 0`, and say,
```
W0.time_remaining = 50 ns
W1.time_remaining = 65 ns
W2.time_remaining = 0 ns
W3.time_remaining = 184 ns
```

This means, \\(W_{2}\\) needs latching right now and \\(W_{0}\\) is the next candidate.
The ISR subtracts `W0.time_remaining` from all `prepared` Waveforms' `time_remaining`, because, at the next timer interrupt, `W0.time_remaining` nano-seconds would have elapsed.
>If assumption #3 is not violated, `time_remaining` would always be non-negative. 

This would make:
```
W0.time_remaining = 0 ns
W1.time_remaining = 15 ns
W2.time_remaining = 30 ns = W2.holdTime() - 50 (say 80 - 50 ns)
W3.time_remaining = 134 ns
```

The next interrupt would latch \\(W_{0}\\) and update all `time_remaining` for the correct execution of the next to next interrupt.  
Below is a sample timing diagram.

An example Timing Diagram

See the `time_remaining` tables, which are updated at each "latch event".

1. The first common latch event enables the timer and `W2.time_remaining` was set as the timer-period (3.2 \\(\gamma\\)).  
2. When \\(W_{2}\\) was latched, `W1.time_remaining` was set as the timer period (0.6 \\(\gamma\\)).  
Also notice that the CPU was able to initiate an SPI transfer (bus was free ,CPU was free and \\(W_{2}\\) was not `prepared`) right after exiting previous ISR. No time is wasted.  
3. \\(W_{1}\\) was latched as soon as timer triggered an interrupt because CPU was essentially free, it only *inititates* SPI transfers. `W3.time_remaining` was set as the timer period (0.8 \\(\gamma\\)). And so on...

### CPU's task
Continuing the scenario, the CPU has just serviced an interrupt for \\(W_{2}\\) and *(obviously)* atleast \\(W_{2}\\) is in `latched` state. That means CPU needs to prepare them by initiating an SPI transfer if the SPI bus is free. If it is not, CPU doesn't need to wait, whenever it is not servicing an interrupt it would try to "prepare" this DAC.

To enable a PC link, Reading and parsing Serial data also becomes a task. Timer interrupt is above all tasks, though.  
Below is the detailed CPU task diagram.

CPU tasks diagram

#### Implement PC Command
Commands like update waveform type, play, pause, reset, sync, phase shift etc would be handled by the CPU when it is not in the Timer ISR. In the rare case that a change was made to the very Waveform which is being serviced in an ISR, the change would be reflected as soon as CPU returns from the ISR: inducing a delay of atmost \\(N \times \gamma\\) seconds.

Commands which have long data streams can be assigned to the DMA controller. Say, a new waveform is being downloaded, the CPU only needs to setup memory for it and then leave the rest to DMA controller. The DMA controller would place all the data from the Serial buffer into the allocted memory. The `Waveforms::nextVoltage()` would do the rest.

### Overview

Combined with Task Queue, the lazy-latch-early-write gurantees minimal "glitches" in waveforms and never forces the CPU in `busy-wait` . DMA controller simply cannot produce "glitch free" waveforms.  
I believe this is the best that can be done.

The following is a Class diagram.
Class diagram

The following depicts a typical instantiation of the system.
Deployment diagram

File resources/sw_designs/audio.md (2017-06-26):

# Teensy Audio

The Teensy Audio library supports the following without any new hardware:

* synthesis of tones and waveforms and o/p using DAC / PWM
* DSP on waveforms
	- stored in memory (also SD card)
	- recieved as analog signal on ADC

The Audio Adapter board (SGTL5000) and the Teensy share signals on the I2S lines. Teensy uses I2C to control/program SGTL5000.

## Sending audio to Teensy
Analog signals from PC `Audio Out` can be fed to the Audio board and recieved by the Teensy via I2S.
```
PC --headphone out--> Audio Board --I2S--> Teensy --SPI--> Cyclops
```

As the waveform is generated by the OE GUI, it can be "played" on the Teensy via I2S.
> Since sound is stereo, 2 channels can be recieved in real time at 44kHz.

`44 kHz * 16b * 2 = 1.4112 MHz`
Tha baud rate of Serial interface is comparable ~1.152Mhz (and higher too).
_The benefit_ of using the Audio board is that `(1)` the USART link to OE GUI would be available for low latency control, waveform updates and not be busy with high bandwidth data from GUI.
Also, the DSP on the Teensy can be setup to perform transforms on incoming data (though the GUI would probably apply the transform before sending?).

This would make it easy for the Teensy to be responsive.`(2)` I2S Rx and Tx have DMA support. When the (`8 * 32b`) FIFO is filled, DMA interrupt is triggered, which could move the `32B` into the `Source.voltage_data`._Ideally we must forward the recieved 32b to `Source.voltage_data` asap_.

## Using Teensy DSP to synth waveforms

We should synthesise all waveforms (@ max 44kHz) audio using the DSP. The signal data-points can be sent to Cyclops over SPI. There is significant speedup in data-point generation when using the DSP (much faster 32b floating point complex mathematics).

## Audio System Design GUI

The functionality of this tool can be replicated easily. I suppose we would only be using the board as an input, and not for synthesis (no mixer / mux).
The OE GUI would be able to realise the design of the Audio System and auto-generate code for the Teensy.

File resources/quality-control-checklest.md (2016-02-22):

### Cyclops Quality Control Procedure
The following procedure is to be performed on boards purchased from an external vendor and sold in a kit or fully assembled state.

Board Serial Number:
Date:
Initials:

#### Setup
- Insert alligator clip across power switch solder points
- Insert device into PCB clamp
- Power from 15V, 1.5A capable bench-top power supply.

- [ ] Power indicator LED turns on.

#### DC Levels
- Using a multimeter, probe the 12V, 2.5V, -5V, and -1.25V test points

- [ ] 12V good
- [ ] -5V good
- [ ] -1.25V good
- [ ] While probing the 2.5V test point, use a ESD-safe screwdriver on the trimpot to get exactly 2.5V. 

#### Dynamic characteristics
- Set MDO3000's AFG to produce 0-2.5V, 100 Hz, 10% duty cycle square wave terminated in 50 Ohms.
- Insert test LED/amplified photodiode into banana sockets and AUX BNC port.
- Insert AFG output of MDO3000 output into VCTL BNC port of device with a 50 Ohm series coax terminator.
- Bring CURR output of device to Ch1 of MDO3000
- Bring photodiode output of device to Ch2 of MDO3000
- Triggering on CURR Channel set scope to measure rise and fall times
- Bring front panel potentiometer to 100% position.
- Input switch to EXT source

- [ ] Examine waveshape and rise/fall times in current FB mode. Rise/fall times < 300 ns. No ringing on waveform.
- [ ] Return input switch to OFF (middle) position

#### Overcurrent indication
- Bring gain potentiometer to full on position
- Briefly tap on the TEST button.

- [ ] Ensure that the >1A indicator LED turned on during pulse.
- [ ] __RETURN GAIN POT. TO ZERO POSITION__

#### Finish
- [ ] Remove all power connectors. 
- [ ] Remove alligator clip.
- [ ] Initial and serial number the board using sharpie on the large power trace on the right side of the board.
- [ ] Enter board serial number into the spreadsheet.

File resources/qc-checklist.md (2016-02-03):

### Quality Control Procedure
The following procedure is to be performed on boards purchased from an 
external vendor and sold in a kit or fully assembled state.

Board Serial Number:
Date:
Intitials:

#### Setup
- Insert alligator clip across power switch solder points
- Insert device into PCB clamp
- Power from 15V, 1.5A capable bench-top power supply.

- [ ] Power indicator LED turns on.

#### DC Levels
- Using a multimeter, probe the 12V, 2.5V, -5V, and -1.25V test points

- [ ] 12V good
- [ ] -5V good
- [ ] -1.25V good
- [ ] While probing the 2.5V test point, use a ESD-safe screwdriver on the
  trimpot to get exactly 2.5V. 
- [ ] Seal the pot with a dab of hot-glue.

#### Dynamic characteristics
- Set MDO3000's AFG to produce 1-5V, 100 Hz, 10% duty cycle square wave.
- Insert LED/amplified photodiode test fixture into banana sockets, IDC
  connector, and AUX BNC port.
- Insert AFG output of MDO3000 output into VCTL BNC port of device
- Bring CURR output of device to Ch1 of MDO3000
- Bring VREF output to MD3000
- Triggering on VREF Channel set scope to measure rise and fall times
- Bring front panel potentiometer to 50% position.
- Input switch to EXT source

- [ ] Examine wave shape and rise/fall times in __current__ FB mode. Rise/fall
  times < 300 ns. No ringing on waveform.
- [ ] Examine wave shape and rise/fall times in __optical__ FB mode. Rise/fall
  times < 300 ns. No ringing on waveform.
- [ ] __RETURN FB SWITCH TO CURR POSITION__
- [ ] Return input switch to OFF (middle) position

#### Overcurrent indication
- Bring gain potentiometer to full on position
- Briefly tap on the TEST button.

- [ ] Ensure that the >1A indicator LED turned on during pulse.
- [ ] __RETURN GAIN POT. TO ZERO POSITION__

#### Finish
- [ ] Remove all power connectors. 
- [ ] Remove alligator clip.
- [ ] Initial and serial number the board using sharpie on the large power
  trace on the right side of the board.
- [ ] Enter board serial number into the spreadsheet.

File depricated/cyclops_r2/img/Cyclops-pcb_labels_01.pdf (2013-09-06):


REG ADJ.

REF ADJ.

I_MEAS Gain CTL Gain | Curr vs. | TEST Aux | V_CURR | V_REF | V_CTL V_REG | LED +/- | POWER

V_AUX
V_CURR
V_REF
V_CTL

V_AUX

GND

Output
Adjust

Input

Switch

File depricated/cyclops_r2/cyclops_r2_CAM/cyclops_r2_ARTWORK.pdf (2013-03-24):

hossdrivercircuit25GERBERzip; Layer: hossdrivercircuit_25.plc; 07 Sep 2012,10:31 AM

hossdrivercircuit25GERBERzip; Layer: hossdrivercircuit_25.cmp; 07 Sep 2012,10:31 AM

hossdrivercircuit25GERBERzip; Layer: hossdrivercircuit_25.sol; 07 Sep 2012,10:31 AM

hossdrivercircuit25GERBERzip; Layer: hossdrivercircuit_25.stc; 07 Sep 2012,10:31 AM

hossdrivercircuit25GERBERzip; Layer: hossdrivercircuit_25.sts; 07 Sep 2012,10:31 AM

hossdrivercircuit25GERBERzip; Layer: hossdrivercircuit_25.drd; 07 Sep 2012,10:31 AM

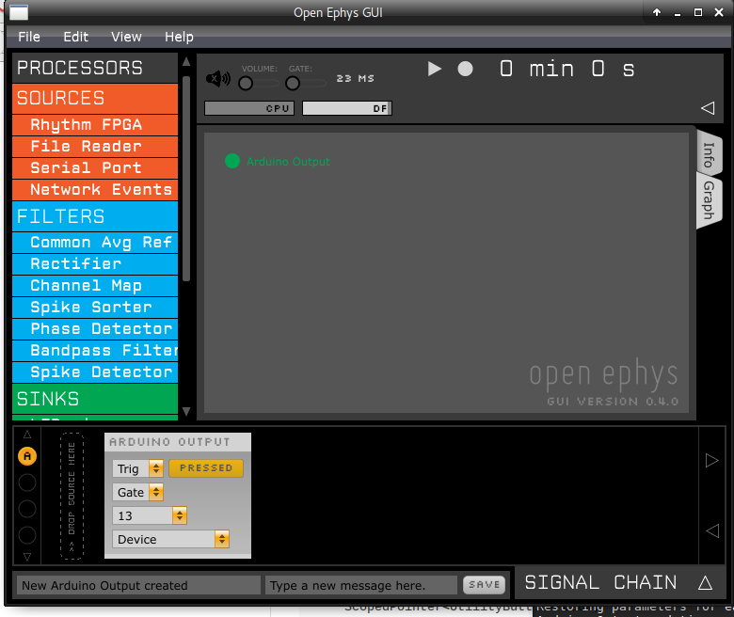
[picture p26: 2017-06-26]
resources/sw_designs/img/pressed.png

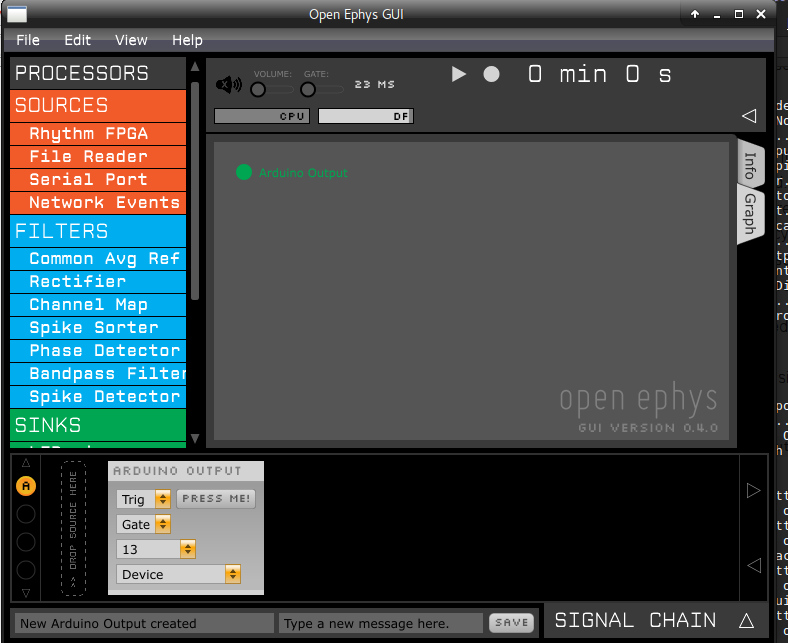
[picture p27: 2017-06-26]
resources/sw_designs/img/not_pressed.png

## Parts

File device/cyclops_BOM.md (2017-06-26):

### Cyclops Bill of Materials

Fully assembled cyclops PCBs can be purchased from Circuit Hub

    [Cyclops on Circuit Hub](https://circuithub.com/projects/jonnew_/cyclops-3v6)

This also includes an up-to-date parts list for each PCB with optimized prices. Note that these parts are for a single PCB without the enclosure, power supply, etc. Those parts can be found on the "Device Kit" tab of the Google spreadsheet above.

    [Google Doc List](https://docs.google.com/spreadsheets/d/1YQR_ujrZgILNx3XjomLKWgzDvirwKrKaRbVVzmBgk-s/edit?usp=sharing)

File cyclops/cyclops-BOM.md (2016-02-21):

### Cyclops Bill of Materials

1. This google sheet contains a reasonably up-to-date parts list. However, it is manually managed and therefore prone to errors. It is recommended that method 2 be used instead

    [Google Doc List](https://docs.google.com/spreadsheets/d/1YQR_ujrZgILNx3XjomLKWgzDvirwKrKaRbVVzmBgk-s/edit?usp=sharing)

2. Fully assembled cyclops PCBs can be purchased from circuithub

    [Cyclops on Circuit Hub](https://circuithub.com/projects/jonnew_/cyclops)

This also includes an up-to-date parts list for each PCB with optimized prices. Note that these parts are for a single PCB without the enclosure, power supply, etc. Those parts can be found on the "Circuit Hub Kit" tab of the Google spreadsheet above.

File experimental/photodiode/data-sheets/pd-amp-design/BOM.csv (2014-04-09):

Quantity | Reference Designator | Model
1 | Rf | 1.24k ohm, 0603, Thin Film, 0.5%
1 | Rg2 | 78.7 ohm, 0603, Thin Film, 0.5%
1 | Rf2 | 237 ohm, 0603, Thin Film, 0.5%
1 | Rfilter | 140 ohm, 0603, Thin Film, 0.5%
1 | Cf | 15pF, 0603, C0G, 5%
1 | Cfilter | 57pF, 0603, C0G, 5%
4 | Cbp+, Cbp-, Cbp2+, Cbp2- | 100nF, 0603, X7R, 20%
2 | Ctant+, Ctant- | 10uF, 6032, tantalum, 20%
1 | U1 | ADA4899
1 | U2 | AD829
1 | D1 | Custom

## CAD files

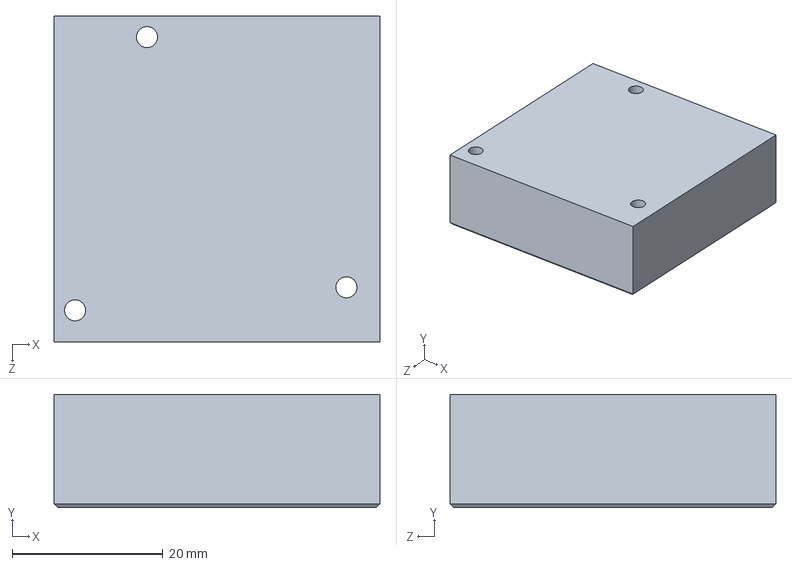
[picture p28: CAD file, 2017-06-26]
device/heatsink/alu-heatsink.SLDPRT
43.2 x 15.0 x 43.2 mm

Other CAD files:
device/heatsink/alu-heatsink.SLDDRW

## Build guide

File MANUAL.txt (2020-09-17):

---
title: Cyclops LED/Laser Diode Driver User Manual
author:
    - Jonathan P. Newman (github [jonnew](http://www.mit.edu/~jpnewman/))
date: \today{}
geometry: margin=2cm
header-includes:
    - \usepackage{setspace}
    - \usepackage{placeins}
    - \usepackage[multiple]{footmisc}
colorlinks: true
toc: true
toc-depth: 2
secnumdepth: 2
colwidth: 1000
reference-section-title: true
---

\newpage

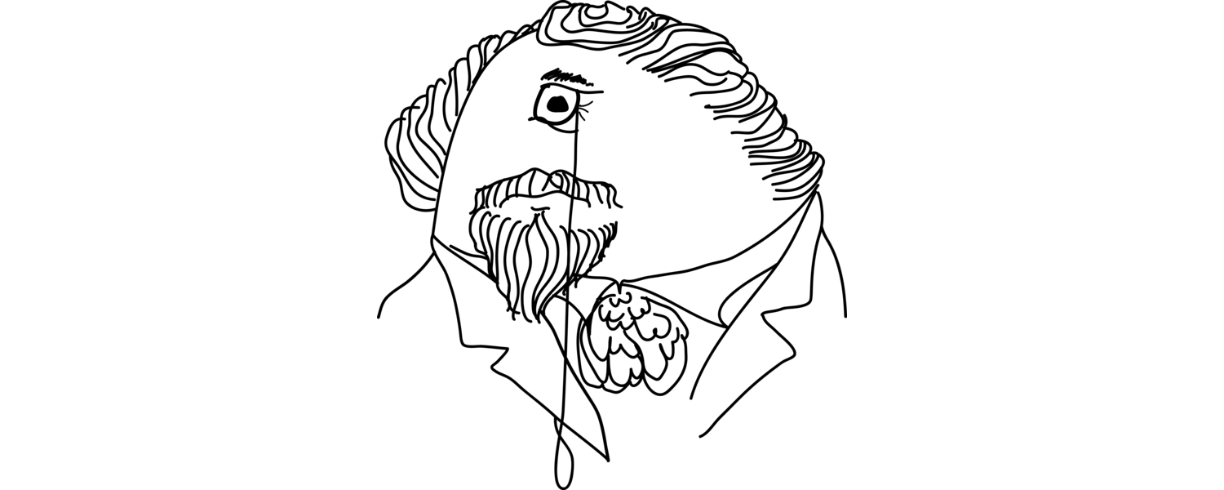
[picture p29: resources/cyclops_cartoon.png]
 \

**Cyclops** is a high-power LED/laser diode driver that enables precise control
of light power. The circuit was developed by Jon Newman while in Steve Potter's
lab at Georgia Tech in order to complete his thesis work, which required the
delivery of ultra-precise, continuously time-varying light waveforms for
optogenetic stimulation \[1,2\]. This was, and still is, not possible with
commercial hardware for optogenetic stimulation.  Since its first use, the
circuit has been improved in terms of speed, precision, programmability, and
ease of use. This document provides construction, usage, and performance
documentation for the Cyclops LED driver. This document evolves with the
repository. To view old revisions, checkout tags or old commits using their SHA.

\FloatBarrier
\newpage

# Note From the Maintainer
I am very happy that this device may enable your scientific endeavors and I'm
sincerely grateful for your interest in the project. In general, I hope this
project will eventually be one small module in a of growing set of
__high-quality__, __open-source__, and __afforable__ tools that facilitate your
research and enable an __open__, __community-oriented__ approach to science.

Profits from the sale of Cyclops devices from the [official
store](http://www.open-ephys.org/store/cyclops-led-driver) go to funding the
Open Ephys non-profit organization. Since I receive no monetary compensation
from the sale of these devices, it would mean a great deal to me if you would
consider referencing the following paper (for which the Cyclops was developed)
in published work that makes use of the device.

> J.P. Newman, et. al. Optogenetic feedback control of neural activity. _eLife_
> (4:e07192) 2015. doi: 10.7554/eLife.07192
> [[link]](http://elifesciences.org/content/4/e07192v1)

For instance, in your methods section:

> Optical stimuli were delivered using the open-source Cyclops LED driver
> (Newman et al., 2015; www.github.com/jonnew/Cyclops).

Pull requests and issue submissions are __welcome__ on the github repo and
open ephys forum. If you have criticisms, fixes, suggestions for improvement
in the docs etc, please let us know so we can implement them ASAP.

Happy stimulating.

Jon Newman MWL@MIT

\newpage

# License

## Hardware Licensing
Copyright Jonathan P. Newman.

This work is licensed under CC BY-NC-SA 4.0. To view a copy of this license,
visit https://creativecommons.org/licenses/by-nc-sa/4.0

__Note__: This license applies to hardware designs and documentation which reside
in the 'device', 'experimental', 'resources' folders of this repository along
with information in 'MANUAL.md' and 'MANUAL.pdf'

## Software Licensing
Copyright (c) Jonathan P. Newman. All right reserved.

The code associated with the Cyclops project is free software: you can
redistribute it and/or modify it under the terms of the GNU General Public
License as published by the Free Software Foundation, either version 3 of the
License, or (at your option) any later version.

The code associated with the Cyclops project is distributed in the hope that it
will be useful, but WITHOUT ANY WARRANTY; without even the implied warranty of
MERCHANTABILITY or FITNESS FOR A PARTICULAR PURPOSE.  See the GNU General
Public License for more details.

You should have received a copy of the GNU General Public License along with
this code.  If not, see <http://www.gnu.org/licenses/>.

__Note__: This license applies to software/fireware source code which resides in in
the 'lib' folder of this repository

\newpage

# Features

## Circuit Features
- Ultra-precise
- High power
- Up to 1.5A per LED
- Wide bandwidth
    - \~2.5 MHz -3 dB bandwidth
    - Maximum 100 ns 1.0A rise and fall times
- Current and optical feedback modes
- Built-in waveform generation
- Over-current protection
- Modular
    - Arduino compatible: internal waveform generation
    - Also, accepts external analog, gate, or trigger inputs

## Multiple stimulus generation options
- External stimulus sequencer
- External digital trigger
    - TTL logic level
- External analog waveform generator
    - 0-5V analog signals
- Internal 12-bit DAC
    - Synchronized across up to 4 drivers
    - Arduino library
    - Programmable triggering logic
    - Respond to USB input

\newpage

# Performance Specifications

## Dynamic Characteristics
The following oscilloscope traces give indications of the circuit's precision
and speed. These traces are taken from Rev. 3.5c. Rev 3.6 provides considerable
improvements but I have not had time to update. Note that time series traces
are **not** averaged - these traces display per-pulse temporal characteristics.
Optical characteristics and optical feedback signal for the Cyclops driver were
provided by a Thorlabs PDA36 amplified photodiode set to 0 dB of transimpedance
gain. Measurements were performed using a single blue Osram golden dragon LED.
The current-feedback mode -3dB bandwidth was determined by applying a flat
noise signal over 50 MHz with mean = 1.0V and Vpp = 500 mV into the `SIGNAL IN`
port with maximal current gain. It occurs at around 2.3 MHz.

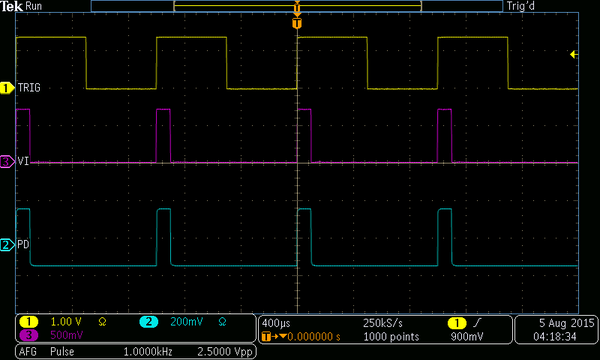
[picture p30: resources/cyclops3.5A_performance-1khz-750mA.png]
Trigger (yellow), current (pink), and light power (blue) traces during pulsed operation in current feedback mode. Input waveform is a 1 kHz 0 to 750 mV, 10% duty cycle square wave.


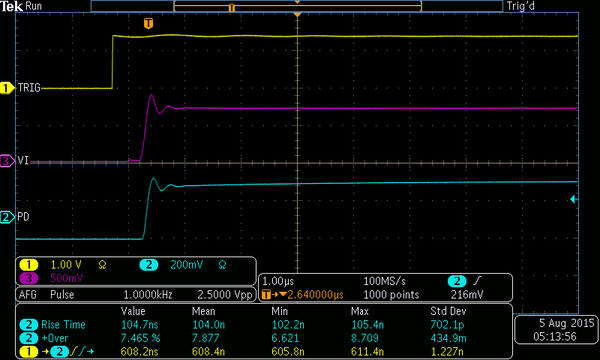
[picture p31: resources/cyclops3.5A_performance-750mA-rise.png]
Zoomed traces showing waveform 10-90% rise times. Optical rise time statistics are shown at the bottom of the image.


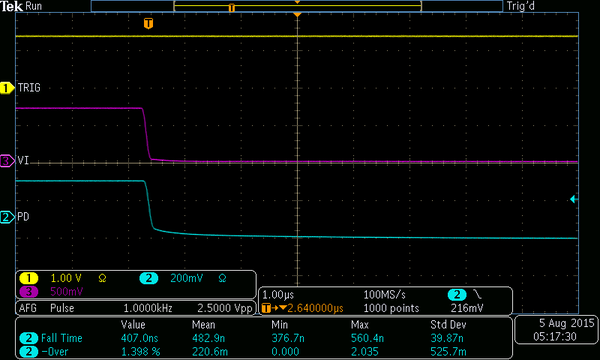
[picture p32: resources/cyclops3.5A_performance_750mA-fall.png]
Zoomed traces showing waveform 10-90% fall times. Optical fall time statistics are shown at the bottom of the image.


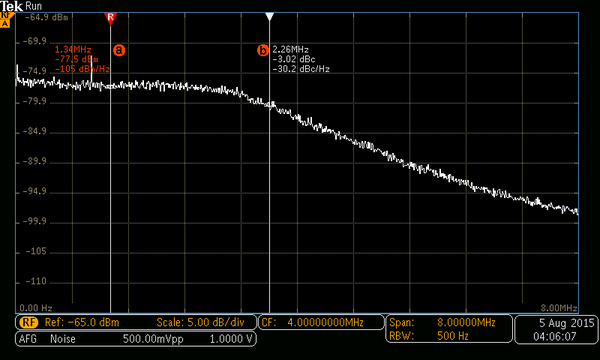
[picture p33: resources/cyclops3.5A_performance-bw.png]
Optical bandwidth in current feedback mode. -3dBm occurs at \~2.3 MHz. Input signal was was noise, flat over 50 MHz, mean = 1.0V, Vpp = 500 mV.


\FloatBarrier

The following traces are the same as the previous ones except that the
amplified photodiode was used to provide optical feedback. The slowdown
compared to current feedback is due to a speed of the photodiode. A
faster amplified photodiode would provide crisper rise and fall times

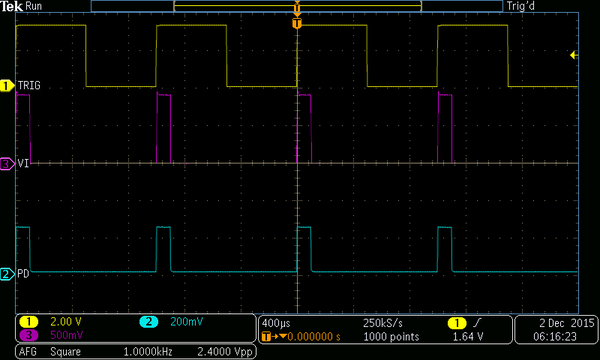
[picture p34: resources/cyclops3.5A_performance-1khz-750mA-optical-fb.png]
Trigger (yellow), current (pink), and light power (blue) traces during pulsed operation in optical feedback mode. Input waveform is a 1 kHz 0 to 750 mV, 10% duty cycle square wave.


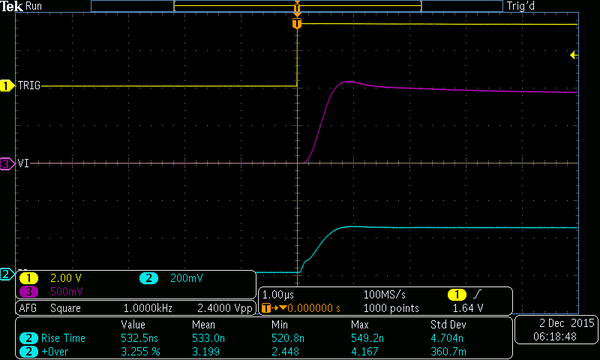
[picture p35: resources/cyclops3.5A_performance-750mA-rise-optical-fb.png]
Zoomed traces showing waveform 10-90% rise times in optical feedback mode. Optical rise time statistics are shown at the bottom of the image.


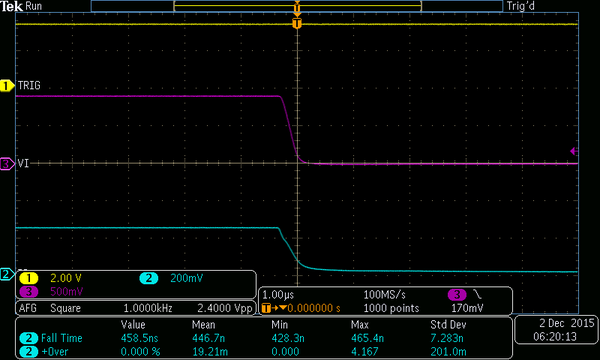
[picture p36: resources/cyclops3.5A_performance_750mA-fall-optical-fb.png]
Zoomed traces showing waveform 10-90% fall times in optical feedback mode. Optical fall time statistics are shown at the bottom of the image.


\newpage

## Head to Head Comparison
The following table provides a comparison between Cyclops Rev. 3.6 and
commercial LED drivers.

---------------------------------------------------------------------------------------------------------------------------------------
                                                    **Plexon**      **Plexon**             **Thorlabs**       **Cyclops**
                                                    **LD-1^1^**     **PlexBright^2,3^**    **DC4100^4^**      **Rev. 3.6**
--------------------------------------------------- --------------  ---------------------- ------------------ -------------------------
**Speed**

· 10-90% rise time^5^ (us)                           49              76                     ?                  <0.1

· 90-10% fall time^5^ (us)                           39              89                     ?                  <0.1

· Wost case dead time^5^ (us)                        140             160                    ?                  1.0

· Small sig. -3dB bandwidth^6^ (kHz)                 10.5            ?                      100^7^             >2500

**Accuracy**

· Overshoot^5,8^ (%)                                 0               0                      ?                  1

· THD^9^ (%)                                         8.29            ?                      ?                  8.2

· THD, Optical F.B.^9^ (%)                           N/A             N/A                    N/A                0.41

**Power**

· Max current drive (mA)                             1200            1100                   1000               1500

**Features**

· Independent LED channels                           1               4                      4                  1^10^

· Regulated current output                           Yes             Yes                    Yes                Yes

· Regulated optical output                           No              No                     No                 Yes

· Prog. overcurr. protection                         No              No                     Yes                Yes

· Arb. waveform generation                           No              Yes                    No                 Yes

· Independent DAC for each LED                       N/A             No                     N/A                Yes

· Manual pulse                                       Yes             No                     No                 Yes

· Manual continuos on                                No              No                     No                 Yes

· Hardware IO                                        None            None                   None               Ref. voltage,
                                                                                                               sync,
                                                                                                               Load current,
                                                                                                               trigger,
                                                                                                               expansion
                                                                                                               ports

· LCD display                                        Yes             No                     Yes                No

**Programmabilty**

· Open-source                                        No              No                     No                 Yes

· Driver                                             N/A            "Radiant"               NI-VISA^12^        Arduino/Teensy
                                                                    software^11^            based GUI

· PC Interface                                       N/A            GUI/USB cable           GUI or API/USB     Arduino IDE;
                                                                                            cable              USB 2.0;
                                                                                                               Serial
                                                                                                               interface

· Waveform gen. performance                          N/A            10 kHz aggregate        N/A                100 kHz/channel
                                                                    update across                              update
                                                                    channels

· OS compatibility                                   N/A            Windows                 Windows            Windows,
                                                                                                               Linux, Mac

**Cost**                                             **\$700.00**   **\$5300.00**           **\$3059.0^13^**   **\~\$450.00**^14^

------------------------------------------------------------------------------------------------------------------------------------

1.  [Plexon LD-1](http://www.plexon.com/products/plexbright-ld-1-single-channel-led-driver)
2.  [Plexon PlexBright](http://www.plexon.com/products/plexbright-4-channel-controller-radiant-20)
3.  Essential drive circuit consists of an [Opal-Kelly XEM6001 FPGA De
    board](http://www.opalkelly.com/products/xem6001/) tied to 4
    commercially available [buck converters from
    Recon](http://www.recom-power.com/pdf/Lightline/RCD-24.pdf).
4.  [Thorlabs DC4100](http://www.thorlabs.com/newgrouppage9.cfm?objectgroup_id=3832&pn=DC4100)
5.  Test signal: 500 Hz, full off to on 50% duty-cycle square wave
    resulting in 1A peak-to-peak through LED.
6.  Test signal: 1 kHz 500 mA offset, 100 mA peak-to-peak sine wave.
7.  Not measured on the bench top. Taken from manufacturer's specifications.
    Bandwidth threshold (e.g. -3 dB) was not specified. Applies to sine
    wave only.
8.  Relies on short, low-inductance cabling. Longer cabling will degrade
    performance.
9.  Test signal: 1 kHz 500 mA offset, 1A peak-to-peak sine wave.
10. However, PCB is modular. Up to 4 PCBs can be stacked using included 0.1"
    headers to share the same power supply and allow sychronous DAC operation of 4
    light sources.
11. [Radiant Software](https://plexon.com/plexbright-radiant-v2-0-for-optogenetic-stimulation/)
12. [NI VISA](https://www.ni.com/visa/)
13. Includes the cost of the
    [DC4100-HUB](http://www.thorlabs.com/thorproduct.cfm?partnumber=DC4100-HUB)
    which is required to drive four LEDs.
14. Cost of fully assembed device from [Open Ephys
    Store](http://www.open-ephys.org/store/cyclops-led-driver). Parts cost is
    ~\$170.00.
\newpage

# Usage {#usage}

The cyclops is a device that is capable of transforming voltage signals (e.g.
sine waves, square pulses, etc.) into optical signals from high-power LEDs or
laser diodes.  Voltage signals to drive the device can be generated internally
using an on-board digital to analog converter or can be delivered from an
external source, such as a function generator or stimulus sequencer. The
cyclops provides numerous measurements of circuit operation that can be
recorded during an experiment such as LED current and stimulus reference
voltages. The device can also be controlled over a USB interface using its
onboard, Arduino-compatible [Teensy
3.2](https://www.pjrc.com/teensy/teensy31.html#specs) microcontroller board in
combination with the Cyclops Arduino library: `./lib/cyclops`. The device can
be used to drive commercially available LED modules from Thorlabs and Doric
using its expansion ports.

Below we provide device control and input/output definitions, an explanation of
the operational modes of the device, and the different ways it can be used to
generate optical stimuli. Refer to the above diagram to locate the physical
switches, dials, and connectors corresponding to verbal or iconic descriptions
device settings.

## Control and IO Definitions
Please refer to the [IO diagram](#fig-io) while reading these definitions.

**`REF OUT`: **
This output operates in two modes depending on the position of the slide switch
below the BNC connector:

- When the switch is set to SYNC, this output is set to 5V when the LED is on
  (>10 mA) and 0 volts when off. 
- When the switch is set to V. REF, this output will copy the reference signal
  that the current source attempts to follow _after_ it has been subjected to
  the GAIN setting. In constant current mode, this means that the voltage at
  this pin specifies 1 A/V. During successul operation in Current F.B. mode,
  this signal will match that off `LED CURR`.  During successul operation in
  `AUX F.B.` mode, this signal will match that of `AUX OUT`.

**`LED CURR.`: **
The voltage on this output measures to the current passed by the load at 1 V/A.

**`AUX. OUT`: **
This output provides a buffered version of the signal at the
`AUX. IN` connector.

**`SIGNAL IN`: **
To use this input, the `INPUT SELECT` toggle switch must be set to `SIG. IN`.
This input operates in two modes depending on the position of the verical slide
switch below the BNC connector:

- When the slide switch below the `SIGNAL IN` connector is set to the square,
  triangle, sine icon, `SIGNAL IN` is used to provide an external target
  voltage signal for the feedback circuit that drives the load. This voltage is
  always subjected to the attenuation imposed by the `GAIN` dial. 
- When the local switch is set to 5V CONT, 5V is generated internally and
  constantly as a reference to drive the load and, again, is subject to the
  GAIN setting.

**`TEST`: **
When this button is pressed, the `SIGNAL IN` line is temporarly disconnected
from the BNC connector and tied to an internal internal 5V reference. This
reference is then subject to the current `GAIN` setting as it would be if it
was produced externally and passed to the `SIGNAL IN` BNC.

**`GAIN`: **
Specifies the transimpedance gain between the reference voltage at `SIGNAL IN`
or produced by the DAC and currented to the load. During `CURR F.B.`, the gain
is given by:

$$
Load\ Current = Dial\ Position * \frac{SIGNAL\ IN\ Voltage }{5V}
$$

During `AUX F.B.` operation, the gain depends on how the optical to AUX signal
conversion gain.

**`INPUT SELECT`: **
Select the source of the reference voltage. `SIG. IN` selects the `SIGNAL IN`
connector. `OFF` ties the reference voltage to 0 so that no current is driven
through the load. `DAC` indicates that the onboard DAC should be used in
concert with the integrated Teensy 3.2 to generate a reference voltage
waveform. Refer to the [Programming the Onboard Microcontroller](#sec-mcu)
section for details on how to do this.

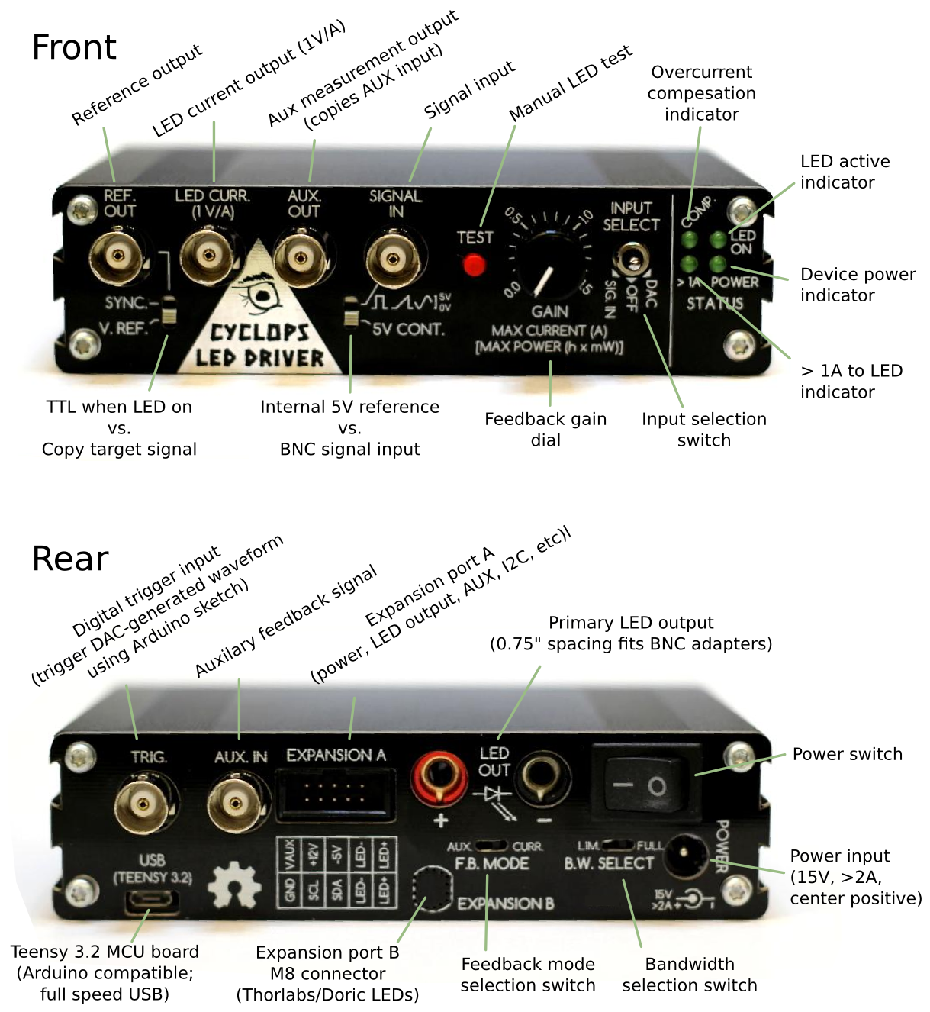
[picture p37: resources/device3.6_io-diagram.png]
Cyclops panel defintions (Rev. 3.6).


\FloatBarrier

**`COMP`: **
This LED indicates that overcurrent compensation is being performed
by the integrated microcontroller. In this case, the load is toggled off to
mainain an _average_ (~100's of milliseconds time constant) current below the
maximimum specified by the firmware running on the Arduino.  This value
defaults to 1A on devices purchased through the Open Ephys store.

**`LED ON`: **
This LED indicates that the load is passing more than 10 mA.

**`>1A`: **
This LED indicates that the load is passing more than 1A, a typical
upper limit for high power LEDs.

**`POWER`: **
This LED indicates that the device has power.

**`TRIG`: **
This input provides GPIO access to the onboard microcontroller. It
can be used as an input or output depending on how the microcontroller is
programmed. It has a bi-directional logic level converter. Output will be 5V
logic high. 5V or 3.3V logic input can be used.

**`AUX. IN`: **
Auxiliary feedback signal for use in auxiliary (e.g. optical)
feedback mode. This pin is pulled high when not in use which protects the load
if the user accidentally switches the device to AUX. feedback mode during
operation.

**`USB`: **
Programming and serial access to the onboard Teensy 3.2.

**`EXPANSION A`: **
0.1" pitch, IDC expansion header. Exposes several signals,
power rails and LED outputs. This can be used to create and integrated load
/photodiode amplifier, for instance.

**`LED OUT`: **
Main LED or laser diode output. Standard banana connectors are
used.

**`F.B. MODE`: **
Slide switch used to toggle the device between constant current (`CURR`) and
auxilary (`AUX`) feedback modes. See the [Feedback Modes](#sec-fb-modes)
section for a detailed explaination.

**`B.W. SELECT`: **
Bandwidth selection switch. When in the `LIM` position, the bandwidth of the
device is limited and one can expect ~1 usec 1A rise and fall times. If long
cables (> 0.5 m) are used between the device and the load, this option must be
used to ensure device stability. When set to `FULL`, the device operates at
full bandwidth with rise times in the 10s of nanoseconds. When operating a full
bandwidth, the user takes steps to ensure circuit stability: short low
inductance cabling to the load. See the [Bandwidth Selection](#sec-bw) section
for details.

**`POWER`: **
Power connector. Center positive, 15V supply with >2A current
sourcing capabilities. Batteries can be used but must be capable of handing
large load transients to maintain device stability.

## Feedback modes {#sec-fb-modes}

### Current Feedback Mode
To use current feedback mode, push the `F.B. MODE` slide switch to the `CURR`
position (Current feedback mode.). Using
the circuit in current feedback mode ensures that the forward current across
the LED is precisely regulated according the voltage at the `VREF` pin. This
configuration is a standard method for driving LEDs because the relationship
between current and LED irradiance is smooth and monotonic.  This means that
more current across the LED will generate more light power (while staying
within the LED's maximum ratings, of course).  However, the relationship
between current and irradiance is not linear.  For most LEDs, it looks like a
logarithmic function. Additionally, the efficiency of the LED is inversely
related to its temperature. So, as the LED operates and heats up, the amount of
light it produces drops even when the current is held constant. The severity of
an LED's temperature dependence and current/irradiance nonlinearity depend on
the type of LED (roughly, the color and who made it). These properties should
be clearly documented in the LED's data sheet. With a quality LED and proper
thermal management, the effects of temperature and static current/irradiance
nonlinearity are fairly minimal and can be ignored in most situations.

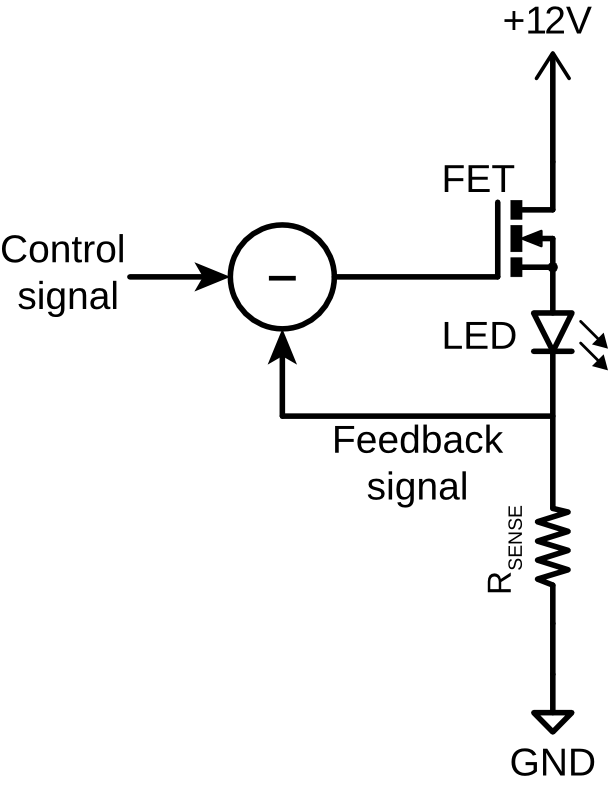
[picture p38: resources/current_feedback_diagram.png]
Current feedback configuration.


### Auxiliary Feedback Mode
To use auxiliary feedback mode, push the `F.B. MODE` slide switch to the `AUX`
position (Auxilary feedback mode.). When
extremely stable, linear control of light power is required, the auxiliary
feedback input can be used to used to compensate for the temperature dependence
and static nonlinearity of the current/irradiance relationship of the LED. For
example, when the auxiliary voltage is supplied by an amplified photodiode that
is somewhere indecent to radiation from the LED, or is sampled from the fiber
transporting LED light, the gate voltage is adjusted such that the measured
light power matches a DAC-supplied reference voltage. This is the case in the
circuit diagram. This configuration is referred to as optical feedback mode.
The [PDA36A](https://www.thorlabs.com/thorProduct.cfm?partNumber=PDA36A)
adjustable amplified photodiode from Thorlabs is a good option for supplying
optical feedback. However, you can make your own amplified photodiode for a
fraction of the price, and a design is included within the cyclops repository.
Optical feedback completely linearizes the relationship between a supplied
reference voltage and the light power produced by the LED by compensating for
the current/irradiance nonlinearities and temperature dependence.

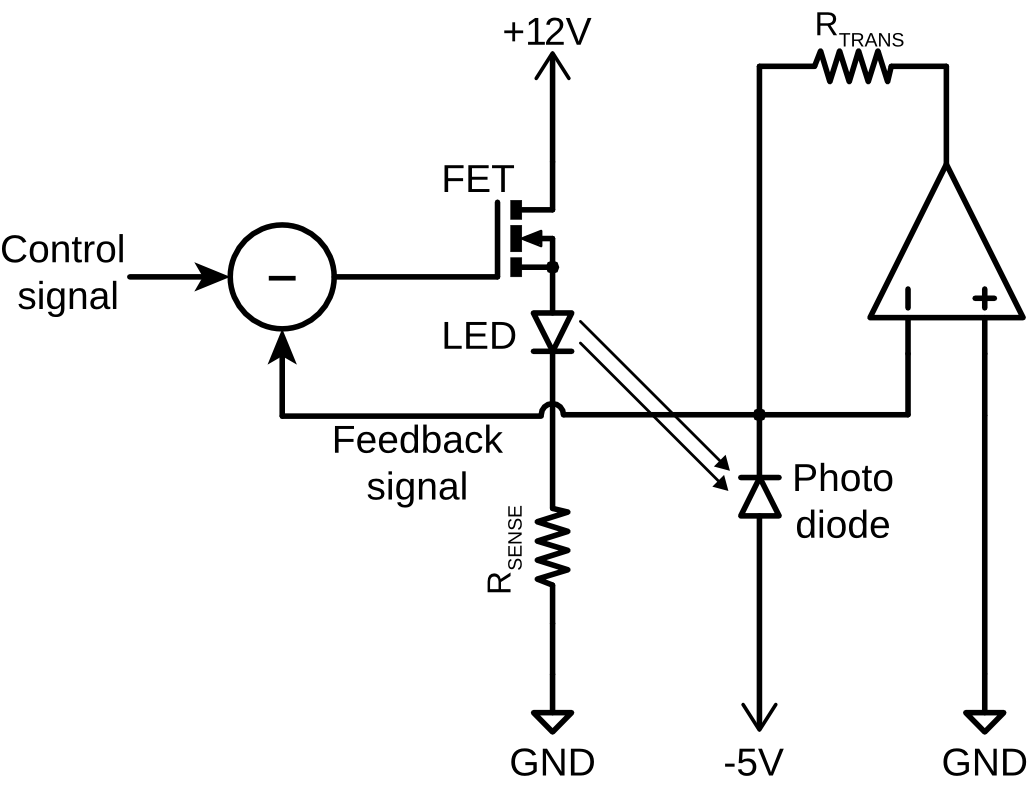
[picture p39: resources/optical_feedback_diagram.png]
Optical feedback configuration.


## Bandwidth Selection {#sec-bw}
The Cyclops can be operated in two bandwidth modes: `FULL` and `LIM`. This
provides user-selectable control over the speed at which the LED can be turned
on/off.

### Full Bandwidth Mode
To operate the device in full bandwidth mode, move the `B.W. SELECT` switch to
the `FULL` position (Full bandwidth mode.).
When the device is operated at full bandwidth, the user can take advantage very
short turn on/off times (1.0 A in about 100 ns rise/fall times). Additionally,
continuously varying optical signals are accurately represented up to about 2
MHz. That said, Cyclops is a fairly high-power circuit. The currents and
voltage used to drive high power LEDs are many orders of magnitude (like 6 or
more...) greater than those recorded during electrophysiology experiments.
Also, the Cyclops is a fast circuit. Fast circuits hate long cables because
they introduce appreciable delays and parasitics that can adversely affect
operating characteristics. Very long cables will introduce ringing into light
waveforms with fast edges!  Ideally, the LED should be right next to the
device. I typically mount my fiber coupled LEDs directly into the banana
sockets on the back of the device using copper-clad printed circuit board so
that my 'cables' are about 2 cm in length.  In any case, the following is
allways good advice: **keep the cabling to the LED as short as possible and
'fat' enough to handle high currents (AWG 18 or thicker)**.

### Limited Bandwidth Mode
To operate the device in full bandwidth mode, move the `B.W. SELECT` switch to
the `LIM.` position (Limited bandwidth bandwidth mode.).  In this mode, the feedback circuit
within the cyclops will operate at lower speeds. This is useful in situations
where the use wishes to place the Cyclops device far away from the LED being
driven (e.g. when it is mounted on the head of an animal rather than light
being transmitted via optic fiber).  In this case, the bandwidth of the device
can be lowered to avoid ringing and instability when a long, potentially thin
cable is used. I have driven LEDs at 1.5A over AWG 30 cable that is several
meters long without issue in bandwidth limit mode. This would cause the device
to oscillate wildy in full bandwidth operation. When the device is operated in
bandwidth limit mode, the rise and fall times of LED pulse will increase to
about 1.5 microseconds, and the -3 dB bandwidth will degrade to ~200 kHz or so.
This is plenty fast for almost all neuroscience applications.

## Stimulus Generation Options
There are three ways to generate light signals using the driver. The
behavior of each of these options is dependent on the feedback mode
being used. The behavior of each input option is described in relation
to the feedback mode of the driver.

1. Test button.: The test button is
   always available and will override all other input modes. Using the
   `TEST` button the behavior of the circuit is:
    - Current feedback mode.: Source
      the current specified by the `GAIN` dial.
    - Auxilary feedback mode.: Generate
      the optical power specified by the _h_ \* mW level that is specified
      by the `GAIN` dial. The intensity of the LED will be dependent
      on the auxiliary feedback signal used which defines the
      'h' parameter.
2. EXT mode.: External input mode is
   engaged when the `INPUT SELECT` switch is moved to the `EXT` position and
   user supplied voltage waveforms are present at the `EXT` BNC input.
   If the user attempts to supply more than 5V to the `EXT` input, the
   circuit will clamp the input signal to 5V. Using `EXT` mode, the
   behavior of the circuit is:
    - Current feedback mode.: Source
      the current specified by: 
      $$
      Load\ Current = GAIN\ Position * \frac{SIGNAL\ IN\ Voltage }{5V}
      $$
    - Auxilary feedback mode.: Generate
      the optical power specified by:
      $$
      Power = GAIN\ Position * h * \frac{SIGNAL\ IN\ Voltage }{5V}
      $$
      The intensity of the LED will be dependent on the auxiliary feedback
      gain which defines the _h_ parameter.
3. DAC mode.: The internal digital
   to analog converter (DAC) is engaged when the `INPUT SELECT` switch is
   moved to the `DAC` position and can be used to generate
   pre-programmed waveforms and waveform sequences triggered by a
   digital pulse to the `TRIG` input. This feature relies on optional
   Arduino installation and programming the device using the [API](#sec-api). Using
   the `DAC` mode, the behavior of the circuit is:
    - Current feedback mode. Source
      the current specified by:
      $$
      Load\ Current = GAIN\ Position * \frac{DAC\ Voltage }{5V}
      $$
    - Auxilary feedback mode. Generate
      the optical power specified by:
      $$
      Power = GAIN\ Position * h * \frac{DAC\ Voltage }{5V}
      $$
      The intensity of the LED will be dependent on the auxiliary feedback
      signal used which defines the 'h' parameter.

\FloatBarrier
\newpage

## Using the Onboard Microcontroller {#sec-api}
Cyclops devices include an onboard, Arudino-compatible microcontroller board
(Teensy 3.2) that can:

- Generate custom waveforms
- Respond to trigger input
- Provide background over-current protection

The Teensy can be programmed and uploaded to the device using the [Arduino
IDE](https://www.arduino.cc/en/Main/Software) in combination with the Cyclops
Arduino library: `./lib/cyclops`. _Note that you will need to add the
[Teensyduino add-on](https://www.pjrc.com/teensy/teensyduino.html) to to the
Arduino IDE to program the Teensy_. The Cyclops library contains several
examples to help you get started. The relevant public programming interface is
shown below. Functions are fully documented in the comments.

``` c++
// Each 'channel' defines a board address. A single microcontroller supports up
// to 4 stacked Cyclops boards.
typedef enum
{
    CH0 = 0,
    CH1,
    CH2,
    CH3,
} Channel;

// One Cyclops object should be created for each LED channel. For single LED
// devices (most cases) only CH0 is used.
class Cyclops {

public:
    // Construct a Cyclops object
    //   chan:             Cyclops channel to control
    //   current_limit_mA: Optional current limit for this Cyclops channel
    Cyclops(Channel chan, float current_limit_mA = 1500);

    // Program the DAC output register
    //    voltage: 12-bit integer (0-4095) specify the voltage to program the
    //             DAC with. Voltage is scaled into a 0-5V range.
    //    returns: 0 on success, 1 otherwise.
    int dac_prog_voltage(const uint16_t voltage) const;

    // Load the DAC output register to affect a voltage change on the output
    // pin. This function affects all running cyclops devices that have had
    // their DAC's programmed using the dac_prog_voltage() function.
    static void dac_load(void);

    // Convenience method for programming and loading a DAC voltage. Equivalent
    // to calling dac_prog_voltage() followed by dac_load()
    //    voltage: 12-bit integer (0-4095) specify the voltage to program the
    //             DAC with. Voltage is scaled into a 0-5V range.
    //    returns: 0 on success, 1 otherwise.
    int dac_load_voltage(const uint16_t voltage) const;

    // Use the DAC to generate a period waveform
    //    sample_period_us: Sample period of voltage sequence in microseconds.
    //    voltage: Pointer to array of 12-bit integers (0-4095) specify the
    //             voltage sequence to program the DAC with. Voltage is scaled
    //             into a 0-5V range.
    //    length: Length of voltage sequence.
    void dac_generate_waveform(const uint32_t sample_period_us,
                               const uint16_t *voltage,
                               uint16_t length) const;

    // Get an LED current measurement in milliamps
    //    returns: LED current measurement in milliamps.
    inline float measure_current(void) const;

    // Attach/detach user provided interrupt function to TRIG pin
    // mode indicates the pin trasition state at which the function is called,
    // RISING, FALLING or CHANGED
    //    user_func: User define function specifying action to take when the
    //               TRIG pin transtions according the the mode arguement. e.g.
    //               can be a function that generates a wavefomr using
    //               dac_load_voltage() or similar.
    //    mode:      Indicates the TRIG trasition state at which the user_func
    //               is called. Can be either RISING, FALLING, CHANGED, HIGH,
    //               or LOW. See AttachInterput() Arduino function for more
    //               detail.
    void set_trigger(void (*user_func)(void), const int mode);

    // Call this static method after creating all cyclops channels to start the
    // internal overcurent protection engine and waveform generation machinery.
    // This funciton is used to start all channels.
    static void begin(void);

    // *this's channel ID
    const Channel channel;
};
```

\newpage
A simple example Arduino sketch, which uses the Cyclops to produce a [sinusodal
chirp](https://en.wikipedia.org/wiki/Chirp), is shown here:

```c++
#include <Cyclops.h>

#define PI_CONST 3.14159265358979323846

// Parameters of the chirp waveform
#define CHIRP_TIME_MS 5000 // Length of chirp waveform in msec
#define FREQ_START 0.5f    // Start frequency in Hz
#define FREQ_END 30.0f     // End frequency in Hz

// Create a single cyclops object. CH0 corresponds to a physical board with
// jumper pads soldered so that OC0, CS0, TRIG0, and A0 are used. Set the
// current limit to 1A on this channel.
Cyclops cyclops0(CH0, 1000);

// Chirp frequency ramp parameter
float beta = 1.0;

void setup()
{
    // Chirp parameter
    beta = (FREQ_END - FREQ_START) / (((float)CHIRP_TIME_MS) / 1000.0);

    // Start the device and zero out its DAC
    Cyclops::begin();
    cyclops0.dac_load_voltage(0);
}

void loop()
{
    // Calculate current chirp amplitude
    float now = ((float)(millis() % CHIRP_TIME_MS)) / 1000.0;
    float freq
        = 2.0 * PI_CONST * (FREQ_START * now + (beta / 2.0) * pow(now, 2));
    unsigned int voltage = (unsigned int)(4095.0 * (sin(freq) / 2.0 + 0.5));

    // Program the DAC and load the voltage
    cyclops0.dac_load_voltage(voltage);
}
```

\FloatBarrier
\newpage

# LEDs and Laser Diodes {#sec-led}
There are several things to consider when determining the type of LED or laser
diode you wish to drive with the Cyclops:

- Will optical stimulation be used in-vivo or through a microscope?
- Do you need to take advantage of the full device bandwidth or are slower (~1
  usec) optical dynamics acceptable?
- Will it be performed on freely behaving animals?
- Do you need to perform bilateral stimulation?
- Will you need to incorporate an amplified photodiode into your
  stimulator to measure optical power or use use optical feedback to
  produce ultra precise light waveforms?
- What wavelength do you require?
- Will the LED or laser diode need a heatsink to maintain operation at the
  power levels you require?
- Should light be launched into a fiber or placed directly at the target?

The answers to these questions will determine the type of LED or laser diode
you use, how it is coupled to the preparation (e.g. collimated for the back
aperture of your microscope objective lens or, fiber coupled for in-vivo
stimulation), and whether or not it needs to be commutated in some way. The
following provide a few simple options for LED configurations, but there are
many more to consider for your experiments.

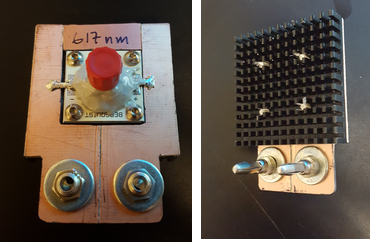
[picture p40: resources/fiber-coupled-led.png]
A simple 'pigtailed' LED module. A female SMA connector is cemented over a lens-free high power LED to form a near optimal butt-coupling between the fiber and the LED die.


## Fiber-Coupled LED

### DIY Solution
Anders Asp has contributed the following PDF document containing detailed
instructions for fabricating a bilateral, commutated fiber-coupled LED for use
in freely moving animals that works with the Cyclops driver:

[Bilateral fiber-coupled
LED](https://github.com/andersjasp/cyclops/blob/master/resources/Open_source_fiber-coupled_bilateral_LED_for_in_vivo_applications.pdf)

### Thorlabs fiber-Coupled LED modules
The cyclops can be used to drive [Thorlabs fiber-coupled LED
modules](https://www.thorlabs.com/newgrouppage9.cfm?objectgroup_id=5206).
You will need to install the [M8 4-position
connector](http://www.thorlabs.com/newgrouppage9.cfm?objectgroup_id=2615&pn=CON8ML-4#5315)
in EXPANSION PORT B to drive these LEDs. Solder the wires from the connector to
the cyclops PCB as shown in the following image __after__ you have
installed the connector into the rear panel of the device.

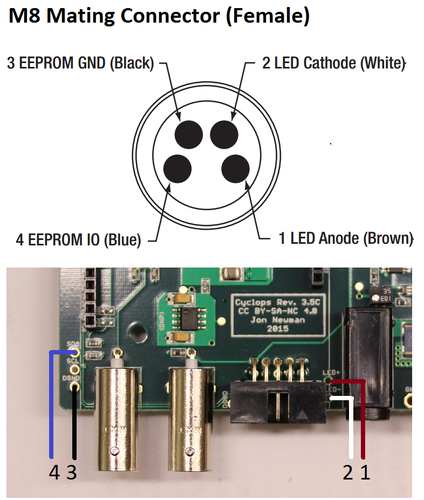
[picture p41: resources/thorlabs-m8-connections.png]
Thorlabs LED M8 connector pinout


### Doric LED fiber-coupled modules
The cyclops can be used to Drive [Doric fiber-coupled LED
modules](http://doriclenses.com/life-sciences/home/783-connectorized-single-led.html).
You will need to install the [M8 4-position
connector](http://www.thorlabs.com/newgrouppage9.cfm?objectgroup_id=2615&pn=CON8ML-4#5315)
in EXPANSION PORT B to drive these LEDs.

TODO: Pictures/instructions for M8 installation process in Doric
configuration

## Microscope mounted LEDs
The cyclops can be used to Drive [Thorlabs collimated
LEDs](http://www.thorlabs.com/newgrouppage9.cfm?objectgroup_id=2615&pn=CON8ML-4#5315)
for microscope-based stimulation. You will need to install the [M8
4-position
connector](http://www.thorlabs.com/newgrouppage9.cfm?objectgroup_id=2615&pn=CON8ML-4#5315)
in expansion port B to drive these LEDs. See [Thorlab fiber-coupled LED
instructions](#thorlabs-fieber-coupled-led) for instructions.

## Laser Diodes
In addition to LEDs, cyclops can be used to drive laser diodes. This can be an
appealing alternative to DPSS lasers for optogenetic stimulation. Cheap DPSS
lasers common for optogenetic use typically have very poor power stability and
temporal control characteristics. Laser diodes driven by cyclops behave
similarly to LEDs but offer much better fiber coupling efficiency. It is easy
to produce 100's of mW at the fiber tip simply by butt-coupling to a laser
diode.  Alternatively, a [focusing
tube](https://www.thorlabs.com/newgrouppage9.cfm?objectgroup_id=1379) can be
used to launch laser diode light into a bench top fiber-coupling system as a
direct replacement for a DPSS laser. Further, due to the cyclops' on/off speed,
a collimator can be used to send LD light into a 2P imaging system in between
row scans. This process occurs so quickly that it is averaged out by the opsin
kinetics to look like continuous power.

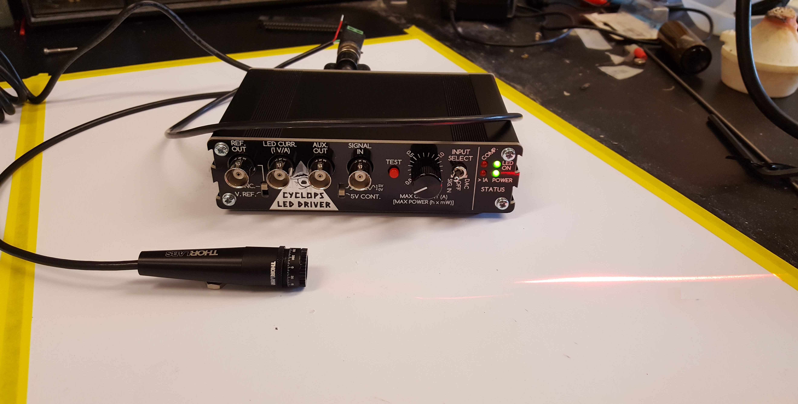
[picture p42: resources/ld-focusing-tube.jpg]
Thorlabs LD focusing tube


\FloatBarrier
\newpage

# Construction
If you have questions during device assembly, please direct them to the
[open-ephys forum](https://groups.google.com/forum/#!forum/open-ephys)
so that others may benefit. Pull requests improving this documentation
are welcome.

This portion of the manual provides instructions for assembling a Cyclops
device. If you have any questions, do not hesitate to post them to the
open-ephys mailing list:

> https://groups.google.com/forum/#!forum/open-ephys

Also, __pull requests and bug reports are welcome__. I would love your help in
improving this device and its documentation!

> https://github.com/jonnew/cyclops/issues

## Components

### PCB {#sec-pcb}
Unpopulated Cyclops PCBs can be fabricated by uploading the [gerber
files](./cyclops/pcb/gerber/) to the PCB fabrication service of your choice. I have
had success with:

-   [OSH Park](https://oshpark.com) - made in America, excellent quality.
    Minimum of 3 boards per order
-   [Seeed Studio](http://www.seeedstudio.com/service/index.php?r=pcb) - made
    in China, passable quality. Minimum of 5 boards per order.

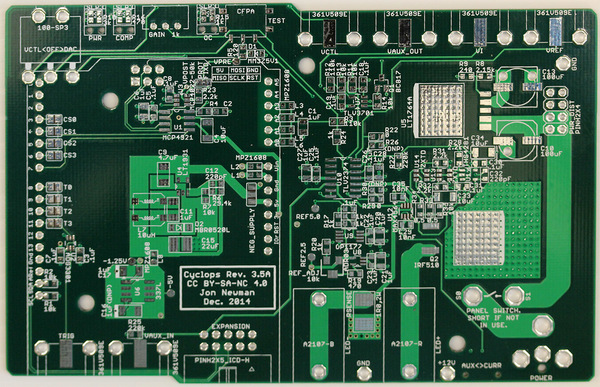
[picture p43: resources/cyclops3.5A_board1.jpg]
A bare Cyclops PCB, top side, fabricated by Seeed Studio.


The layer of each gerber file is identified by its file extension:

     *.GKO = board outline
     *.GTS = top solder mask
     *.GBS = bottom solder mask
     *.GTO = top silk screen
     *.GBO = bottom silk screen
     *.GTL = top copper
     *.G2L = inner layer 2 copper
     *.G3L = inner layer 3 copper
     *.GBL = bottom copper
     *.XLN = drill hits and sizes

PCB stencils, which are useful for applying solder paste to the boards, can be
purchased from a service like [Seeed
Studio](http://www.seeedstudio.com/service/index.php?r=stencil) using the
gerber files located in `/cyclops/device/stencil/` folder. If you plan to hand solder
the board, or don't mind dispensing solder paste yourself, then you do not need
to purchase these stencils.

### PCB Bill of Materials {#sec-pcb-bom}
The PCB bill of materials is availabe on [this google sheet](https://docs.google.com/spreadsheets/d/1YQR_ujrZgILNx3XjomLKWgzDvirwKrKaRbVVzmBgk-s/edit#gid=1630015426)

### Other Materials
A complete device requires several additional components aside from the
assembled PCB itself. These pre-populated Digikey cart. These can be found
following the PCB parts on [this google
sheet](https://docs.google.com/spreadsheets/d/1YQR_ujrZgILNx3XjomLKWgzDvirwKrKaRbVVzmBgk-s/edit#gid=765977278).
These parts include
- An **extruded aluminum enclosure**, which houses the completed board. The
  enclosure is recommended because the large voltages and current transients
  used to drive high power LEDs can cause capacitive and inductive interference
  with nearby recording equipment. Acrylic front and rear panels can be
  purchased from Ponoko using the links supplied in the BOM. The instructions
  below show how these plastic pieces are modified to provide proper electrical
  shielding.
- **Custom heatsink**, a waterjet-cut aluminum heatsink. Designs can be found
  in the `./device/heatsink` folder.
- **Teensy 3.2 MCU**, a 32-bit microcontroller development board. Can be
  purchased [here](https://www.pjrc.com/store/teensy32.html)
- An **M8-4 connector** (Optional). This is a rather expensive connector that
  allows cyclops to drive [Thorlabs LED
  modules](https://www.thorlabs.com/newgrouppage9.cfm?objectgroup_id=5206) or
  [Doric LED modules](http://doriclenses.com/life-sciences/243-led-modules).

## Device Assembly Manual

### Required Parts and Tools

Before starting, please ensure you have the following components. Suggested
part numbers and suppliers are provided on this [google spreadsheet](https://docs.google.com/spreadsheets/d/1YQR_ujrZgILNx3XjomLKWgzDvirwKrKaRbVVzmBgk-s/edit?usp=sharing).
In the lists below, numbers (#XX) correspond to the labels on the image below.

1. Assembled Cyclops PCB (#6, 1x)
2. Extruded aluminum enclosure (#1,1x)
3. Enclosure panels (front: #20, 1x; rear: #21, 1x)
4. Rocker switch (#18, 1x)
5. 18 AWG silicone insulated hookup wire (#17, 2x)
6. Shrink tube (#19, 2x)
7. Gain knob (#7, 1x), jam nut (#8, 1x), and toothed washer (#9, 1x)
10. Button cover (#10, 1x)
11. Waterjet-cut aluminum heatsink (#13, 1x)
12. 6mm length, M3 thread-forming screws (#11, 11x)
13. Nylon washers (#12, 3x)
14. Silicon thermal compound (#4)
15. Thermal tape (#5)
16. Teensy 3.2 MCU board (#15, 1x)
17. 0.1" sockets for Teensy 3.1 (#16, 2x 1x14 pin; 1x 1x2 pin; 1x 2x7 pin SMD)

You will also need the following tools.

1. Scissors
2. Soldering iron
3. Hot air gun or lighter
4. T10 Torx key or driver (#2)
5. XX Allen key or driver (#3)
6. Teensy soldering jig made from breadboard with male headers (#14)

Additionally, to use your device once it is assembled, you will need:

1. An LED or laser diode to drive [Required]

    - See the [LED/laser diode section](#sec-led) for options.

1. A power supply [Required]

    - Any wall-wart, battery pack, or bench-top power supply providing 15-20 VDC
      that can source >=2A will work.
    - The power jack is __center positive__ (but reversing this will not ruin the
      device, it just wont turn on).
    - Look around and see if you have a wall-wart laying around the lab that
      meets the specs. They are pretty common and the jack is likely to fit.
    - [Digikey part number
      1470-3096-ND](http://www.digikey.com/product-search/en?keywords=1470-3096-ND)
      or equivalent is a good option for those that need to buy a supply.

1. An M8, 4-pin connector [Optional]

    - An inexpensive, standard, non-insane, 2x5 header (`EXPANSION A`) provides
      access to most of the internal signals on the Cyclops board, e.g. for
      driving an LED or providing auxiliary feedback using an amplified
      photodiode etc.
    - An expensive, strange, moderately insane, M8 expansion connector that is
      used by two major companies in the optics space (`EXPANSION B`) is left
      unpopulated. You can populate this port if you wish to drive Thorlabs or
      Doric LED modules using the Cyclops. For instructions, see this the
      complete manual.
    
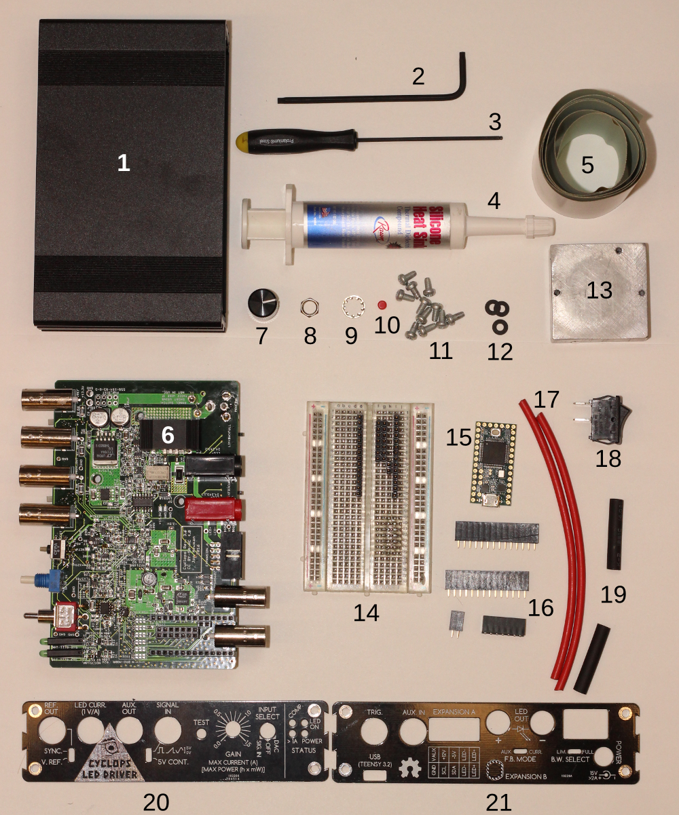
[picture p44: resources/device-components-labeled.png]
Cyclops device parts and tools
      

\FloatBarrier

### Device Assembly Instructions

1. Assemble the teensy 3.2

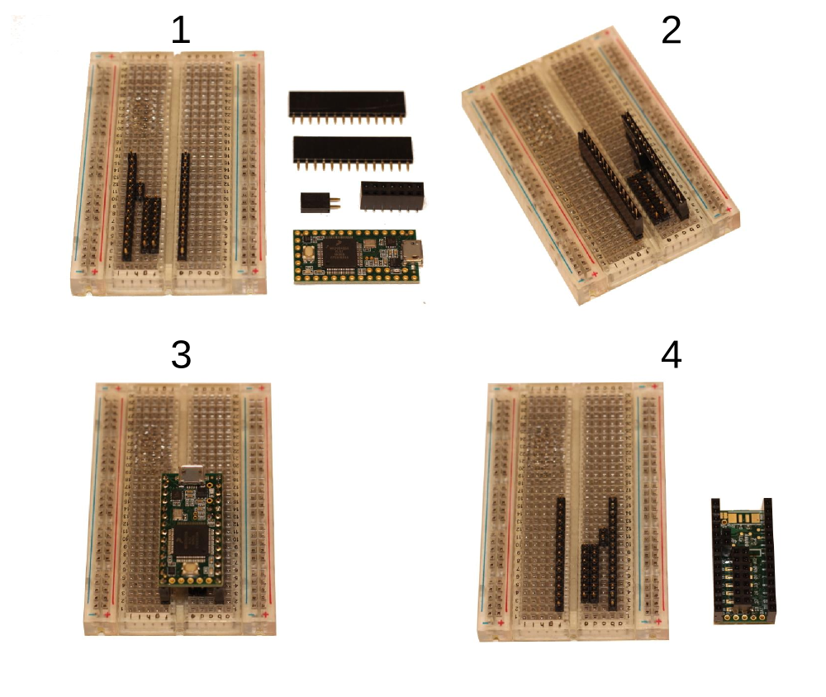
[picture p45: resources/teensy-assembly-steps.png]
Teensy MCU assembly
    

    - Solder the surface mount, 2x7 pin header to the bottom of the teensy. It
      is important to do this first because its very hard to get to after the
      other headers are installed.
    - Put the single row headers on the soldering jig (panel 2, above),
      followed by the Teensy (panel 3, above).  The microcontroller chip should
      be facing up.
    - Solder the headers in place.

2. Assemble the power switch

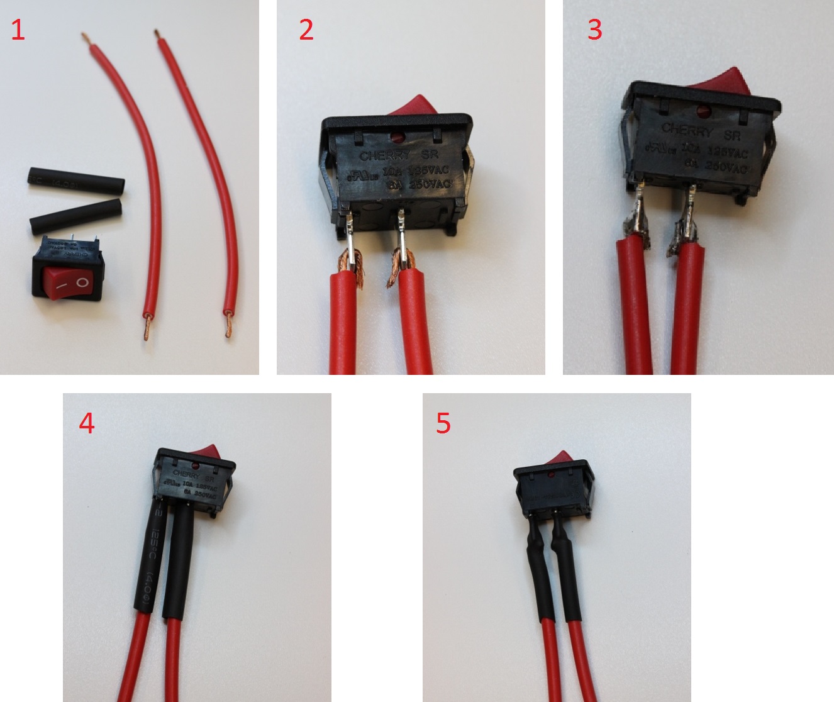
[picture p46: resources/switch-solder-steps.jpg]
Power switch assembly
    

    - Strip about 1 cm of insulation from each end of the hookup wires
    - Thread the stripped portion of the wire halfway through each of the
      switch's solder terminals. Fold the wire back, so that the stripped part
      is touching both sides of the terminal.
    - Solder the hookup wire to the terminals. Make sure the solder flows
      between the wires' copper braid and the switch terminals.
    - Slide the heat shrink from the back of each wire, over the solder joints.
      Hit then with a hot air gun or pass a lighter underneath them to shrink
      them into place over the solder joints.

3. Prepare the back panel

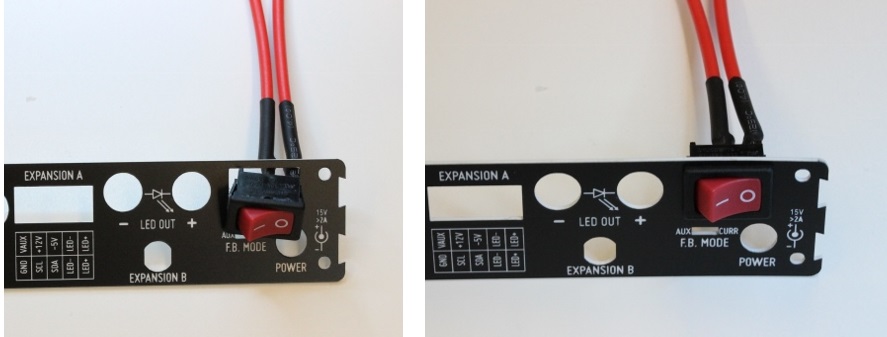
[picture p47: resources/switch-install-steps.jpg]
Power switch installation
    

    - Press the  power switch into position on the back panel. Orient the
      switch so that the 'on' symbol (-) is toward the middle of the panel and
      the 'off' symbol (o) is toward the outside. This will make the panel
      easier to mount on the enclosure.
    - The switch will snap into place.

4. Install the teensy on the cyclops

    - Press the previously assembled teensy onto the 0.1" pitch male headers. It
      should be _upside down_ on the bottom of the cyclops PCB.

5. Put thermally conductive tape on the heatsink

    - Cut a square of thermal tape from the roll
    - Peal off the backing and press the tape on the back of the heatsink.
    - Poke holes through the tape to expose the bolt holes in the heatsink.

6. Install the heatsink on the PCB

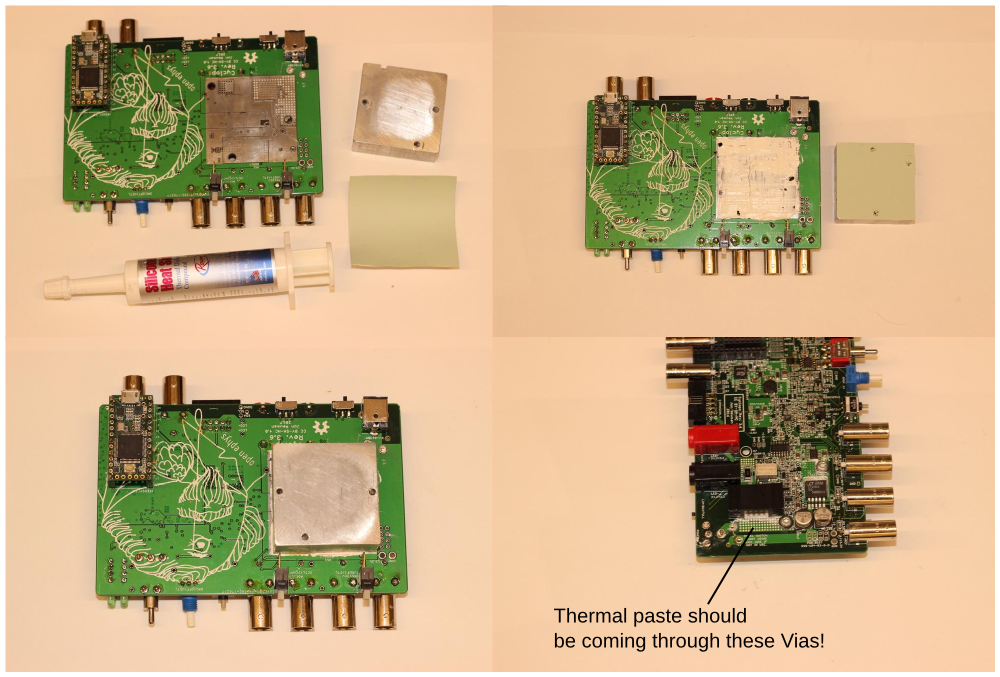
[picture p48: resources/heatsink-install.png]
Heatsink installation
    

    - Flip the PCB so that the bottom is exposed.
    - Locate the large white square surrounding the exposed copper pad indicating
      the heatsink mounting location
    - Apply an even layer of thermal paste to the area.
    - Remove the paper backing from the tape on the heatsink to expose the adhesive surface
    - Press the heatsink into place on the PCB
    - Filp the PCB so the top is up and locate the three holes used to mount the
      heatsink to the PCB. Thead three self-tapping screws through a nylon washer
      and then into the heatsink itself. Hand tighten until the heat sink is
      firmly head against the back of the PCB. You should see thermal compount
      coming through the numerious vias in the PCB. This is disired because it
      provides a low thermal resistance path between the PCB and the heatsink.

6. Solder the power switch to the PCB.

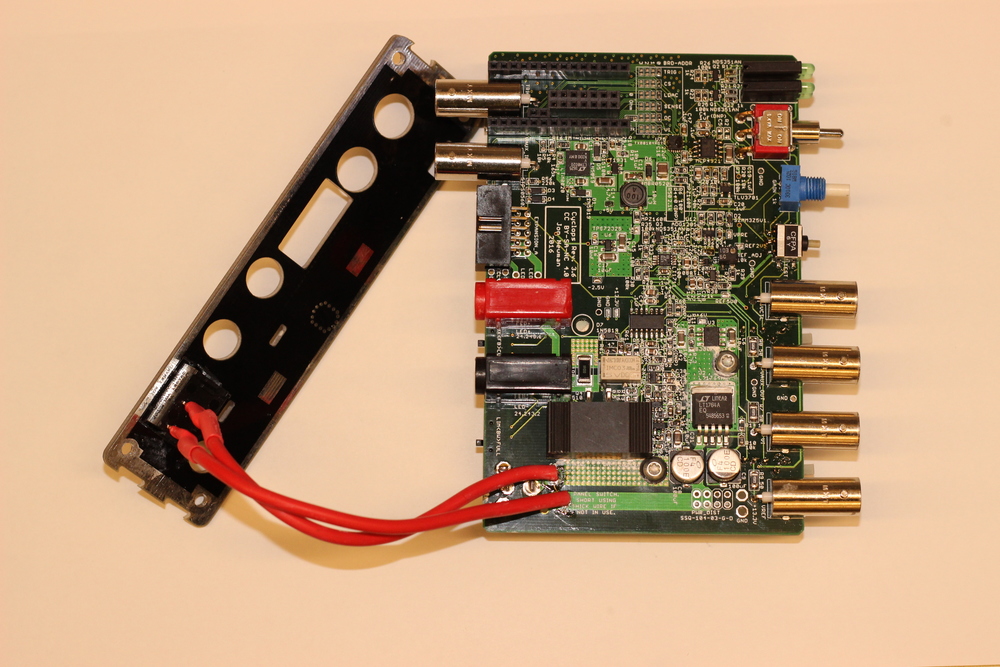
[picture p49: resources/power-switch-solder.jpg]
Power switch soldering
    

    - Solder the power switch to the two indicated terminals on the PCB.
    - Make sure you do this __after__ you have installed the switch in the rear
      panel.
    - The wires can be soldered to either solder point, orientation does not
      matter since this is a SPST switch.

7. Install the front panel on the enclosure

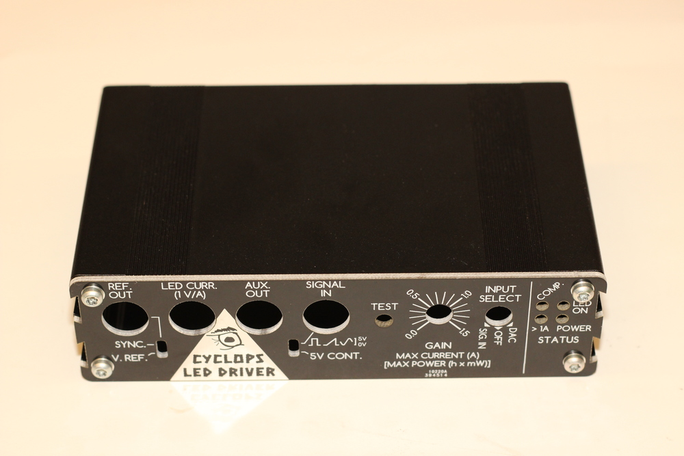
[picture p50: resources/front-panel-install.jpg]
Front panel installation
    

    - Using 4 of the 11 self-trapping screws, install the front panel on the enclosure.
    - __Note:__ The orientation of the enclosure matters. The top of the
      enclosure is indicated by rows of decorative lines as indicated in the
      above figure.

8. Install the PCB in the enclosure.

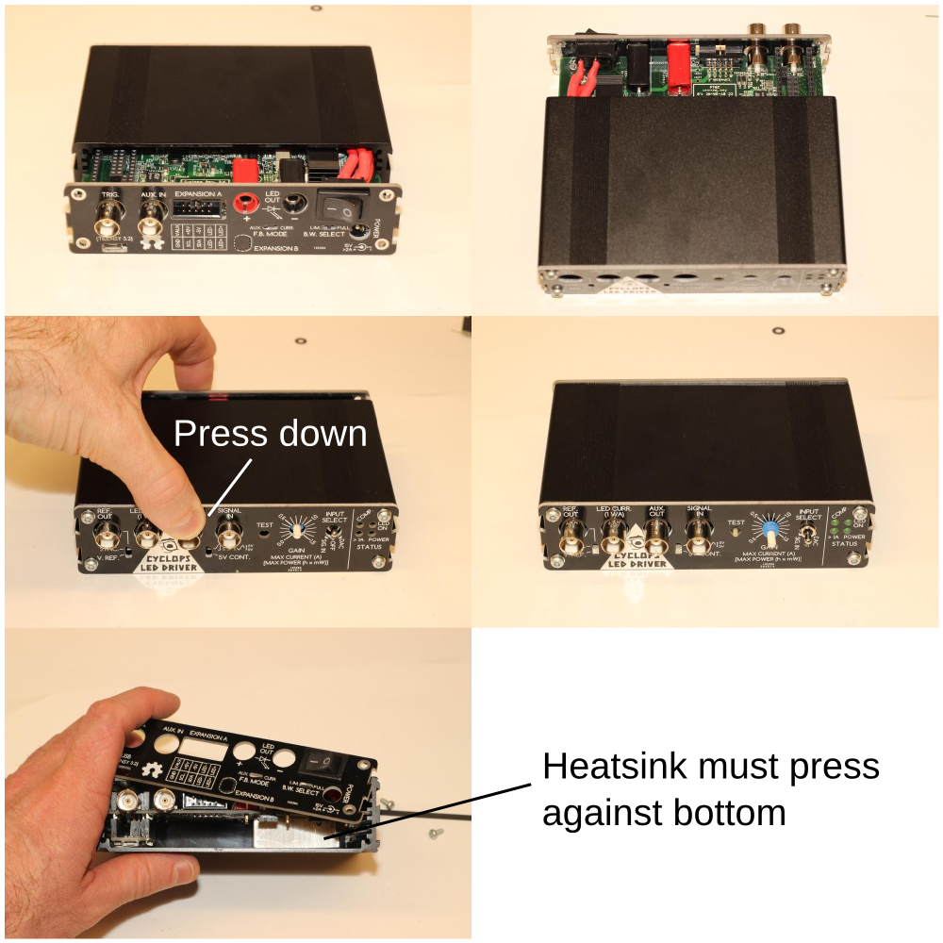
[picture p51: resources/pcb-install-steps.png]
    

    - Slide the PCB into the box using the __middle__ mounting rail.
    - __Note:__ The heatsink should be making firm contact with the bottom of
      the enclosure. If it is not, you should add thermal paste to the bottom of
      the heatsink to fill the gap. The heatsink must have a low thermal
      resistance path to the enclosure to dissipate heat during operation.
    - __Note:__ When the BNC connectors come through the front panel, you will
      need to push them down a bit, slightly flexing the PCB to get the panel
      mount controls through the front panel.

9. Install the rear panel.

    - Loop the two hook up wires and push them into the enclosure on top of the
      PCB.
    - Use the panel the push the remaining wire into the enclosure.
    - Use the remaining 4 screws to install the rear panel.

10. Install gain knob and button cover.

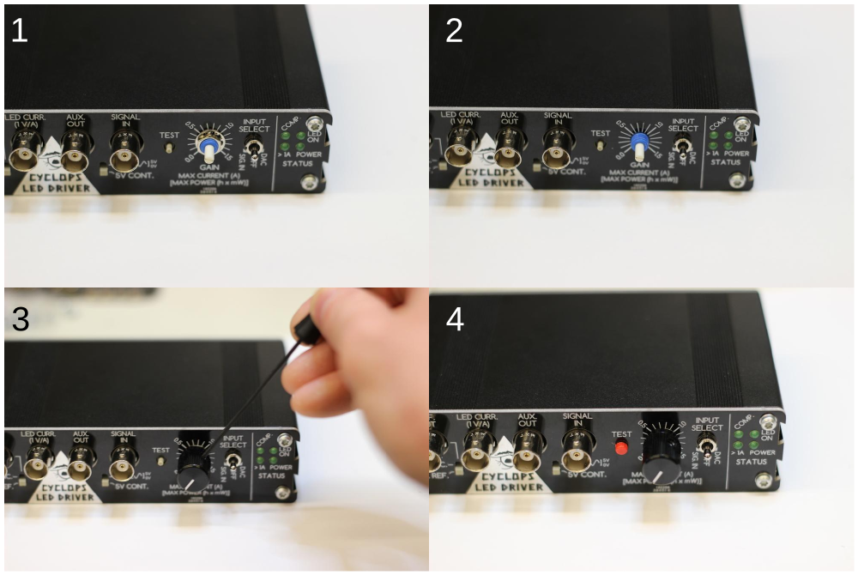
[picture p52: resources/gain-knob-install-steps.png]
Gain knob installation
    

    - Slip the toothed washer over the gain dial.
    - Tighten the jam nut on the gain dial's threads until just past finger tight
      using a pair of needle nose pliers.
    - __Note:__ Do not over-tighten using a combination spanner or you will
      strip the threads.
    - Turn the dial on the front panel _fully counter-clockwise_.
    - Slip the gain knob over the dial with the tick mark pointed slightly below
      the 0 position.
    - Tighten the set screw on the side of the knob to lock it into place using
      an Allen key.
    - When you turn the knob fully clockwise, the tick mark should be pointing
      close to the 1.5A position.
    - Press the red cover over the `TEST` switch until it snaps into place.

This concludes device assembly. To begin using your device, please refer to the
[usage](#usage) section above.

\FloatBarrier
\newpage

## Board Assembly Manual

### Board Assembly Materials
To assemble a Cyclops board, you will need the following materials

- Cyclops [PCB](#sec-pcb)
- PCB [Bill of Materials](#sec-pcb-bom)
- A soldering iron and, if possible, a hot-air reflow device.
    - At minimum, a soldering iron regulated to \~370 deg. c) will do
      the job.
    - In addition to the iron, a hot-air rework tool or reflow oven
      are recommended and the assembly instructions below assume you
      are using one of these two options. A low cost, high-quality
      hot-air rework station can be purchased from SparkFun
      [here](https://www.sparkfun.com/products/10706).

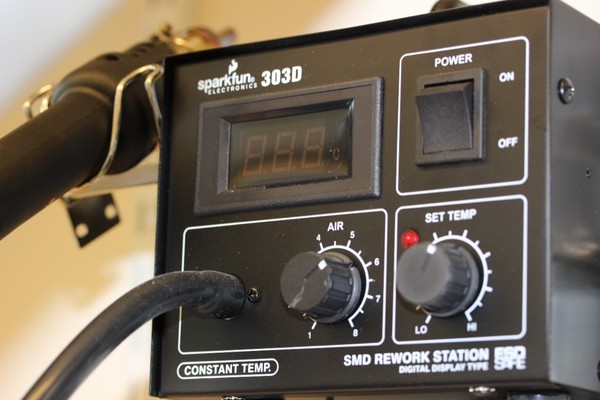
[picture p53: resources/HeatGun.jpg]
A soldering iron can be used to assemble the PCB, but a hot air rework station makes things much easier. These can be purchased from [Sparkfun](https://www.sparkfun.com/products/10706).
    

- Copper braid ('solder wick') for solder removal (e.g
  [this](https://www.sparkfun.com/products/9327))
- Liquid flux (`no-clean` variants are easiest since they don't have
  to be thoroughly removed after use)
- Solder paste (e.g.
  [this](http://www.digikey.com/product-detail/en/SMD291AX10T5/SMD291AX10T5-ND/3972568))

    ![Wire solder and an soldering iron can be used to construct the
    PCB, but solder paste combined with a hot air rework station or a
    reflow oven makes things much easier. We use [Chipquik
    291ax10](http://www.digikey.com/product-detail/en/SMD291AX10T5/SMD291AX10T5-ND/3972568).](./resources/SolderPaste.jpg)

- Stereoscope or loupe (optional but nice for tracking down shorts.)
- Isopropyl alcohol for cleaning flux off the board (e.g.
  [this](http://amzn.com/B0047YB3OW); optional)
- An anti-static mat (e.g. [this](http://amzn.com/B00009XT3H);
  optional but recommended to protect your work...)

### Board Assembly Instructions
PCB component population and soldering is fairly straightforward and
requires standard surface mount construction techniques.

- A tutorial on hot-air soldering can be found
  [here](https://youtu.be/1z0IiuQ35HU).
- A great tutorial filled with general tips and tricks for surface
  mount soldering can be found [here](https://youtu.be/pdGSFc7VjBE).

The following steps provide a visual guide to construct your own board.
The goal is to create a fully populated PCB like this one:

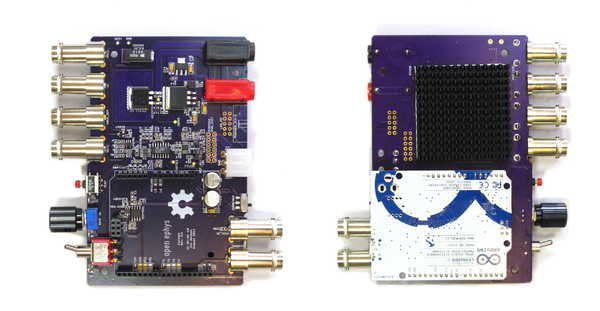
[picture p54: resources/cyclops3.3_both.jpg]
Finished device (revision 3.3).


*Following board construction, you should run through the electrical
tests outlined in the next section before applying power.*

1. Place the bare PCB on a flat surface, preferably one that is static
   dissipative or anti-static. Alternatively, the board can be mounted
   in a PCB vice.

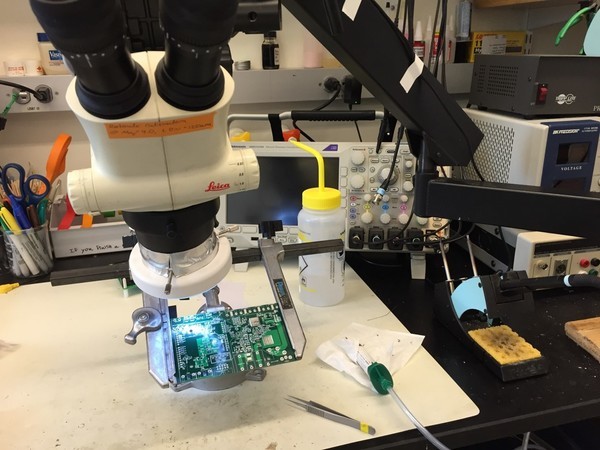
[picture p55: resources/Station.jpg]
Instead of populating components on a table, holding the PCB using a PanaVise can be helpful.
   

2. The silkscreen layer on the PCB (white text) has almost all the
   information you will need to properly populated the PCB. However,
   its a good ideal to to open the [cyclops
   design](./cyclops/cyclops_r3.brd) in
   [EAGLE](http://www.cadsoftusa.com/eagle-pcb-design-software/). This
   will allow you to get detailed information on components before
   placing them on the board.

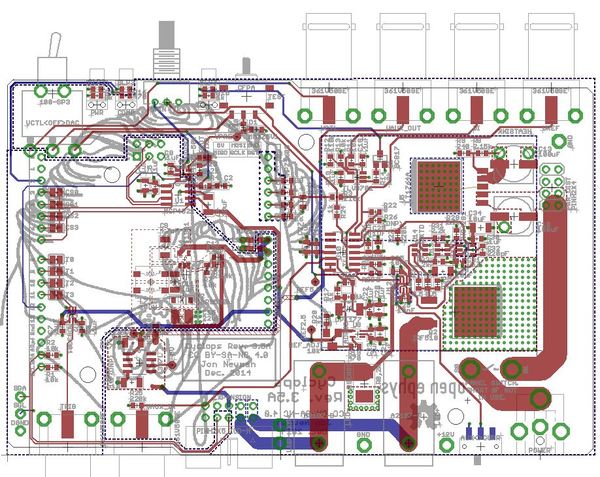
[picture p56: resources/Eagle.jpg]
The cyclops PCB design in CadSoft EAGLE
   

   You can then the `information` tool to get detailed information on
   each component, e.g. to ensure you are placing the correct value
   resistor or capacitor.

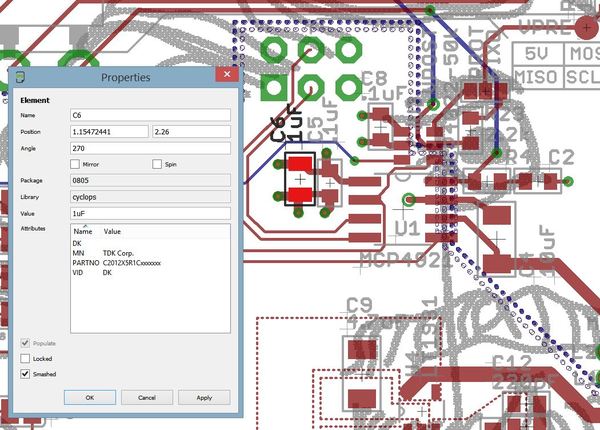
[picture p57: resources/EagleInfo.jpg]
By selecting the information tool and clicking the cross at the center of a component, you can pull up detailed info (e.g. part number)
   

3. After cleaning the surface of the board with isopropyl acholhol or
   similar, apply solder paste to each of the pads. For an excellent
   series of tips on effective methods for dispensing solder paste, see
   [Mike's video on the subject](https://youtu.be/pdGSFc7VjBE). Do not
   apply solder paste to through-holes or the pads shown outlined in
   red in the following image. These will be hand soldered later in the
   assembly process.

   The correct amount of solder paste to apply is \`enough'. Each
   component contact should sit in a small amount of paste, but blobs
   of paste that envelop the component pad or pin may later result in
   a short. The following images show examples of good and bad
   solder placement.

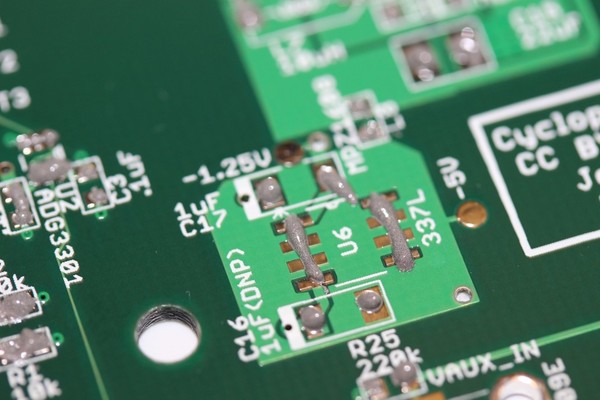
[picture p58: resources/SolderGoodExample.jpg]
Good solder placement.
   

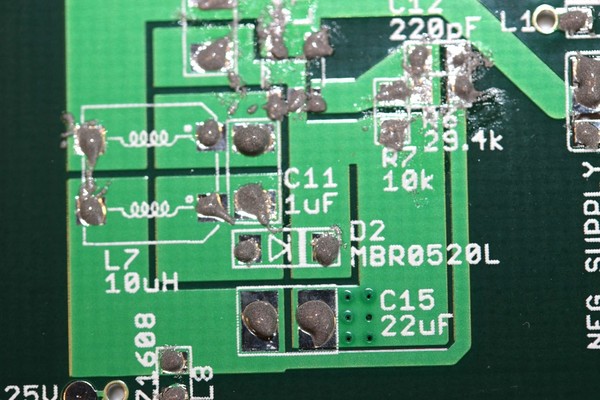
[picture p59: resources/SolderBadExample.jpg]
Bad solder placement. Too much paste!
   

   If you need to pause at any point, you should store place the PCB in
   the fridge to prevent the flux in the solder paste from
   breaking down.

4. Populate all **top-side surface mount** components on the board.
   There is a single surface mount switch on the back of the board that
   will be hand soldered later. Additionally, all through hole
   components (e.g. power jack, BNC connectors, etc) will be
   populated later. Start by placing the integrated circuits (ICs). Use
   the stereoscope or loupe to ensure that pads are making contact with
   the pins of the placed components. Precise component alignment is
   not necessary. Components will self-align during the reflow process.

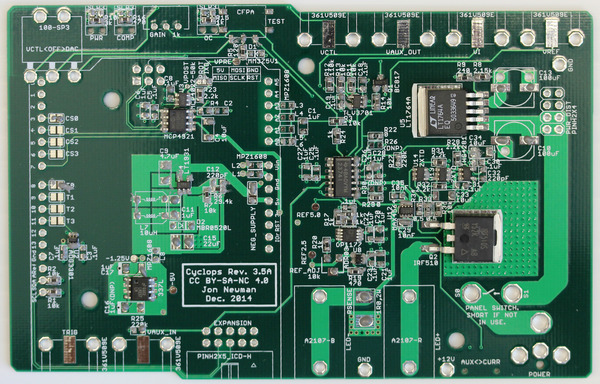
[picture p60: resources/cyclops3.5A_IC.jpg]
Integrated circuit population.
   

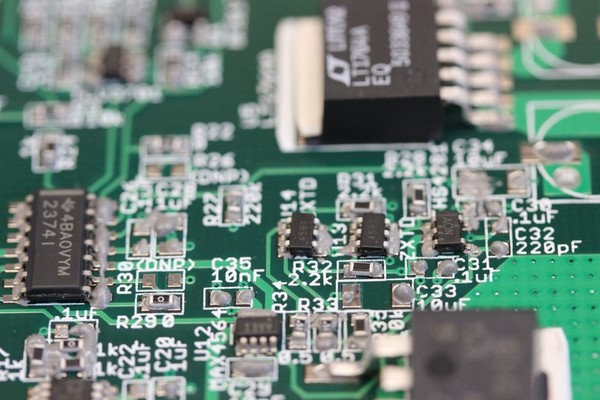
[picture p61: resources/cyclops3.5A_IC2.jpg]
Zoomed view of integrated circuit placement.
   

5. After placing the ICs, place the passive components (resistors,
   capacitors, inductors, diodes, and ferrite chips).

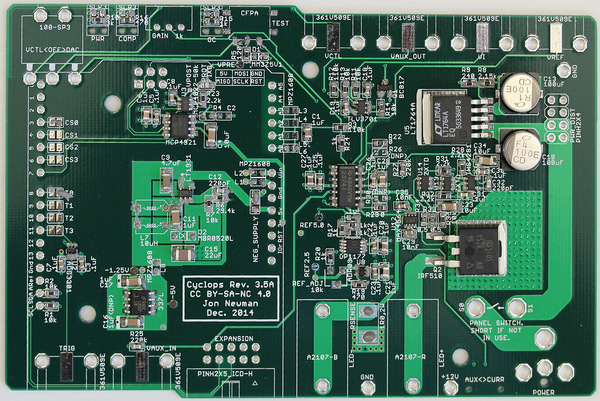
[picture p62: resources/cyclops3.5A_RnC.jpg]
Board following resistor and capacitor population.
   

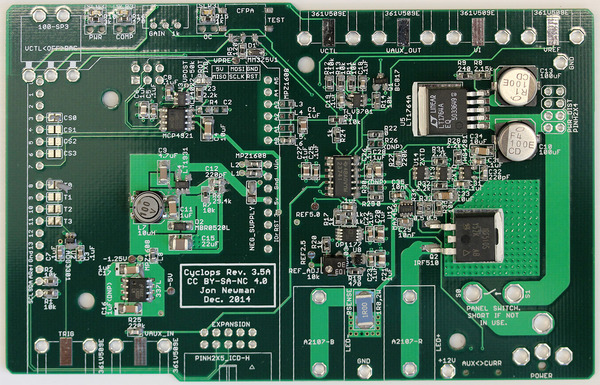
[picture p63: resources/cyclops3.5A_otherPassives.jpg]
Board with all top-side surface mount components installed.
   

6. Next, reflow solder the board. We use a homemade reflow oven constructed
   from a toaster oven, Arduino board, [reflow oven control
   shield](http://www.rocketscream.com/shop/reflow-oven-controller-shield-arduino-compatiblee),
   and [mains relay](https://www.adafruit.com/products/268). You can make a
   similar one, use a commercial reflow oven, or use the hot air station.
   Reflow the solder paste on the board using your oven or hot air gun as
   described in the links above.

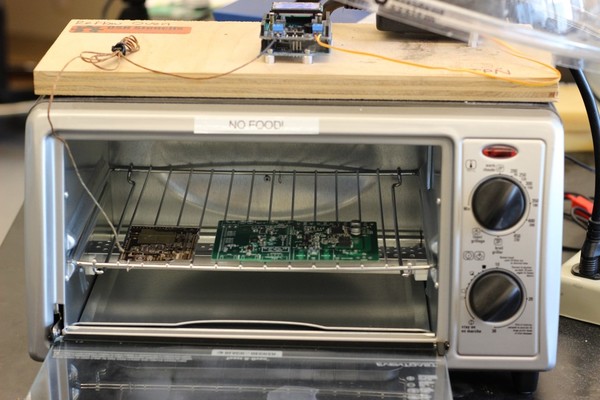
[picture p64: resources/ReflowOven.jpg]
Homemade reflow oven with the populated board inside.
   

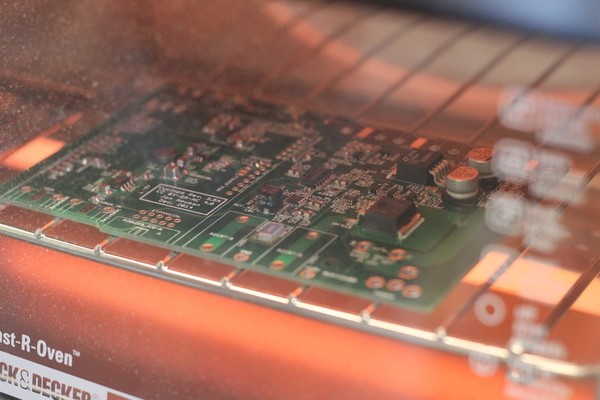
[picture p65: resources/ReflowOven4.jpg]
The board is shown after the reflow temperature has been reached. Reflow will occur at different temperatures depending on the specification of the solder paste you are using.
   

7. After the solder has cooled, examine solder pads using the
   stereoscope of loupe for solder bridges between pins, solder that
   has not melted, or pads lacking a decent solder joint. Fix any
   issues using a standard soldering iron If there are solder bridges
   present, get rid of them using some solder wick before moving on.
   Solder through-hole components in place using a standard
   soldering iron. A low cost reflow oven can be made from a toaster
   oven as shown [here](http://whizoo.com/reflowoven).

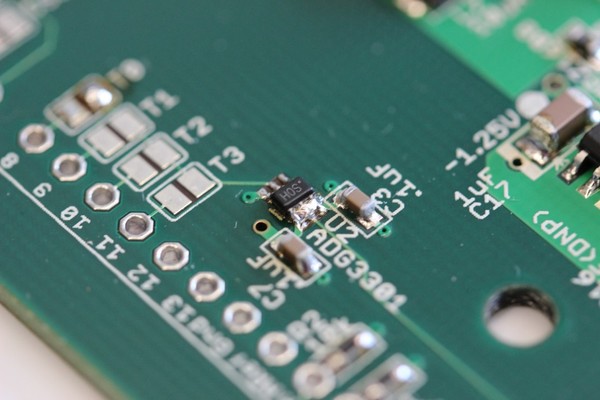
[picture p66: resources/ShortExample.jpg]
Example of a short between IC pins. This must be resolved before moving forward.
   

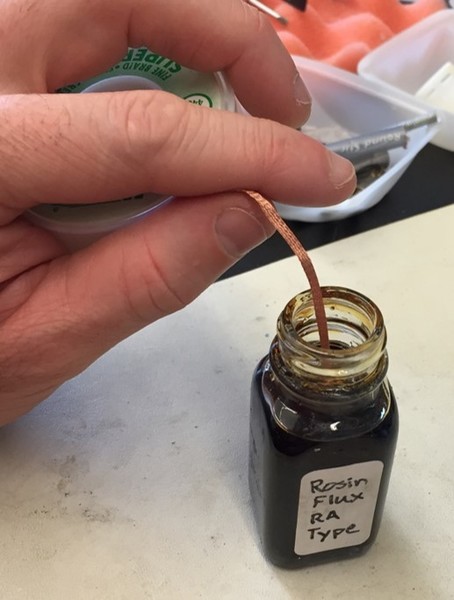
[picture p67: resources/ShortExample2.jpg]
Dipping the copper braid in flux will make the solder wick much more redily.
   

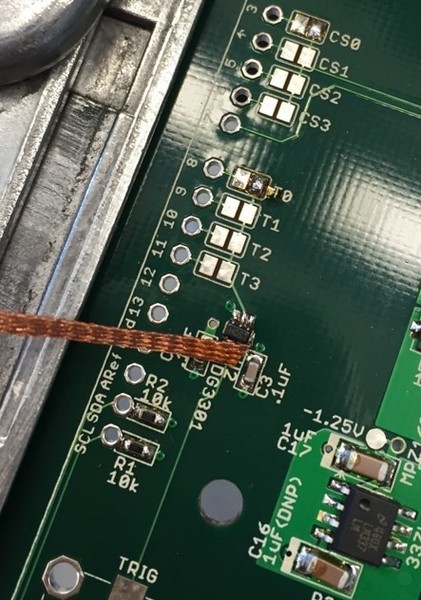
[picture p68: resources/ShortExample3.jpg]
Place the copper braid over the solder blob and then press with the soldering iron. You should see the excess solder wick up the copper braid.
   

   Often you will not have to re-apply solder after this process because there will be enough left over to maintain a good electrical contact. Once you are satisfied the flux residue can be cleaned using isopropyl alcohol

8. Each board has an address (0 through 3) that is defined by two
   solder jumpers and the location of a ferrite chip. This allows
   cyclops boards to be stacked to share a power supply while being
   driven by a common microcontroller. For each board that will share a
   microcontroller, a unique address must be specified and the solder
   jumpers and ferrite chip must be soldered in appropriate positions
   to reflect this address. See the picture below to better understand
   this addressing scheme.

   TODO: Pictures of circled 0 ohm jumpers

9. Flip the board over and install the final surface mount component,
   the `AUX<>CURR` and `BW LIM` slide switches, by hand soldering.

10. Next, populate all electromechanical components. This can be
    soldered in place with a standard soldering iron and a large
    chisel tip.

    Top side of board following electromechanical component installation.

    Bottom side of board following electromechanical component installation.

    **Note:** The the barrel power jack (name: `POWER`, value: PJ-063BH
    on the schematic) should be mounted on the **bottom** of the board.
    It fits on both the top and the bottom, and will properly supply the
    board with power if mounted on the top. However, if the barrel jack
    is mounted on the top side of the board, it will not fit inside
    the enclosure.

11. If you are not planning on putting the PCB in an enclosure, jumper the
    solder points for the power switch together using AWG 20 (\~1.8 mm
    diameter) braided copper wire or thicker.

\FloatBarrier
\newpage

# Quality Control Procedure
The following procedure can be performed on assembled boards to ensure
functionality. It is performed on devices sold by open ephys.

## Setup
- Insert alligator clip across power switch solder points
- Power from 15V, 1.5A capable bench-top power supply.
    - Power indicator LED turns on?

## DC Levels
- Using a multimeter, probe the 12V, 2.5V, -5V, and -1.25V test points
    - 12V good?
    - -5V good?
    - -1.25V good?
- While probing the 2.5V test point, use a ESD-safe screwdriver on the trimpot
  to get exactly 2.5V.
- Seal the pot with a dab of hot-glue.

## Dynamic characteristics
- Use external waveform generator to produce 1-5V, 100 Hz, 10% duty cycle
  square wave.
- Insert LED/amplified photodiode test fixture into banana sockets,
  IDC connector, and AUX BNC port.
- Insert AFG output of MDO3000 output into VCTL BNC port of device
- Bring CURR output of device to scope
- Bring VREF output to scope
- Triggering on VREF Channel set scope to measure rise and fall times
- Bring front panel potentiometer to 50% position.
- Input switch to EXT source
- Examine wave shape and rise/fall times in **current** FB mode.
    - Rise/fall times &lt; 300 ns? No ringing on waveform?
- Examine wave shape and rise/fall times in **optical** FB mode.
    - Rise/fall times &lt; 300 ns? No ringing on waveform?
-  **Return FB switch to curr position**
-  Return input switch to OFF (middle) position

## Overcurrent indication
- Bring gain potentiometer to full on position
- Briefly tap on the TEST button.
- Ensure that the &gt;1A indicator LED turned on during pulse.
- **Return gain potentiometer to zero position**

## Finish
- Remove all power connectors.
- Remove alligator clip.
- Initial and serial number the board using sharpie on the large
  power trace on the right side of the board.
- Enter board serial number into the spreadsheet.

\FloatBarrier
\newpage

\FloatBarrier
\newpage

# References

\[1\] J.P. Newman, M.-f. Fong, D.C. Millard, C.J. Whitmire, G.B.
Stanley, S.M. Potter. S.M. Potter. [Optogenetic feedback control of
neural activity.](http://elifesciences.org/content/4/e07192v1) *eLife*
(4:e07192) 2015. doi: 10.7554/eLife.07192

\[2\] T. Tchumatchenko\*, J.P. Newman\*, M.-f. Fong, S.M. Potter.
[Delivery of time-varying stimuli using
ChR2](http://journal.frontiersin.org/article/10.3389/fncir.2013.00184/full#).
(\* - equal contributions, co-first authors) *Front. Neural Circuits*
(7:184) 2013. doi: 10.3389/fncir.2013.00184

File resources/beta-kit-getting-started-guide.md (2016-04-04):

## Thank you for purchasing a Cyclops kit!
This guide provides instructions for assembling your Cyclops kit.  For more
details on performance specifications, usage, and assembly, please have a look
at the complete manual available in PDF or markdown form on the Github
repository.

> https://github.com/jonnew/Cyclops/blob/master/MANUAL.md
> https://github.com/jonnew/Cyclops/blob/master/MANUAL.pdf

If you have any questions, do not hesitate to post them to the open-ephys
mailing list where I will try to reply with great precision and speed:

> https://groups.google.com/forum/#!forum/open-ephys

Also, __pull requests and bug reports are welcome__. I would love your help in
improving this device and its documentation!

> https://github.com/jonnew/cyclops/issues

## Attribution
It has been a long road to design and test the Cyclops, coordinate the
acquisition of materials, coordinate the manufacturing processes, and to
distribute the device to the community. This process has been a lot of work but
also a very rewarding learning experience. I am very happy that this
device may enable your scientific endeavors and I'm sincerely grateful
for your interest in the project. In general, I hope this project will
eventually be one small module in a of growing set of __high-quality__,
__open-source__, and __afforable__ tools that facilitate your research and
enable an __open__, __community-oriented__ approach to science.

All profits from the sale of Cyclops kits go to funding the Open Ephys
non-profit organization. Since I receive no monetary compensation from the sale
of these devices, it would mean a great deal to me if you would consider
referencing the following paper (for which the Cyclops was developed) in
published work that makes use of the device.

> J.P. Newman, M.-f. Fong, D.C. Millard, C.J. Whitmire, G.B. Stanley, S.M.
> Potter. S.M. Potter. Optogenetic feedback control of neural activity. _eLife_
> (4:e07192) 2015. doi: 10.7554/eLife.07192
> [[link]](http://elifesciences.org/content/4/e07192v1)

For instance, in your methods section:

> Optical stimuli were delivered using the Cyclops LED driver (Newman et al.,
> 2015; www.github.com/jonnew/Cyclops).

Thanks again for taking the leap and helping to take this project to the next
level. OK, let's get started.

## Kit Assembly Manual
### Beta "Features"
Tricked you. Before we actually get started, I wanted to let you in on a few
awesome features only available to pioneering beta users like yourself. I
assure you (see feature 4), that despite these very neat beta-only
characteristics, your Cyclops will kick just as much butt as those from the
next production round.

1. __Rad hidden power switch solder points__

    Somehow the solder resist mask got put over the through-holes where the
    power switch is soldered to the board.

	Gah.

   This makes soldering to these points a bit tricky, because you must make
   sure the solder flows into the hole, where there is exposed copper. If you
   think you might have trouble with this, take an utility blade and scrape the
   solder resist layer off the pad in the back of the board, as show in the
   figure.

   Scrape off solder resist.

2. __Cool manually soldered linear regulator__

    It turns out that LT1764AEQ-1.8 is not the same as LT1764AEQ.

	Not equal.

    For this reason, I had to manually replace every board's linear regulator
    after they had been been professionally assembled. Thank goodness for
    podcasts! The little marker dot on the large power trace at the front right
    corner of the board indicates that the replacement was made, just for you.

3. __Awesome minimal silkscreen layer__

    When I got the boards back from the assembler, I noticed they looked very
    minimal and streamlined. "Must be a result of those super precise pick and
    place machines", I thought to myself. "Amazing how much cleaner a robot can
    solder than......where the f\*\*\* are the component labels?"

    Come on...

    This one was my fault. I failed to adequately RTFM. At least the Cyclops
    artwork is still on the back of the PCB. Without that, it doesn't work. If you
    want to know the value of the components and names of solder points on the
    board (e.g. to hack it, which I thoroughly encourage), this image shows the
    complete silkscreen.

    Beta vs. complete silkscreen

4. __Sweet quality control check__

    Given the aforementioned kinks in the manufacturing process, I wanted to ensure
    the functionality of each board. Therefore, we performed pretty extensive quality
    control testing on each PCB that we shipped. The results are included with
    your kit. This is a true beta-only feature. I don't plan on doing this for
    any more production runs, especially since 75/75 boards passed the test with
    flying colors :).

### Kit Contents
OK, for real this time, lets get started.

Your kit contains the following items

1. Assembled Cyclops PCB (1x)
1. Extruded aluminum enclosure (1x)
1. Laser-cut enclosure panels (1x front, 1x rear)
1. Rocker switch (1x)
1. Hookup wire (2x)
1. Shrink tube (2x)
1. Gain knob (1x)
1. Toothed washer (1x)
1. Jam nut (1x)
1. Light pipes (3x)
1. Button cover (1x)
1. Heatsink (1x)
1. Screws to install panels (8x)

Ensure that the kit is complete before starting. If not, contact me at
jpnewman@mit.edu, and I will send the missing parts immediately.

Your kit does __not__ contain the following items:

1. An LED to drive [Required]

  - See the [complete manual](../MANUAL.md) for options.

1. A power supply [Required]

  - Any wall-wart, battery pack, or bench-top power supply providing 15-20 VDC that
    can source >=2A will work.
  - The power jack is __center positive__ (but reversing this will not ruin the
    device, it just wont turn on).
  - Look around and see if you have a wall-wart laying around the lab that
    meets the specs. They are pretty common and the jack is likely to fit.
  - [Digikey part number 1470-3096-ND](http://www.digikey.com/product-search/en?keywords=1470-3096-ND)
    or equivalent is a good option for those that need to buy a supply.

1. Arduino [Optional]

  - The Cyclops contains onboard overcurrent protection circuitry, a 12-bit
    digital to analog converter to generate arbitrary optical patterns, and a
    trigger input to provide fast waveform generation to an incoming logic
    signal. These features require an Arduino Leonardo or
    equivalent to be installed on the cyclops, and for the device to be programmed using the
    [Cyclops Arduino Library](https://github.com/jonnew/cyclops/tree/master/arduino).
  - This is __not__ required to use the Cyclops for optical stimulation:
    without the Arduino, you just need to provide stimulus waveforms or
    triggers to the EXT IN BNC from some other source.

1. An M8, 4-pin connector [Optional]

  - An inexpensive, standard, non-insane, 2x5 header (`EXPANSION A`) provides
    access to most of the internal signals on the Cyclops board, e.g. for
    driving an LED or providing auxiliary feedback using an amplified photodiode
    etc.
  - An expensive, strange, moderately insane, M8 expansion connector that is used by two
    major companies in the optics space (`EXPANSION B`) is left unpopulated. You can populate
    this port if you wish to drive Thorlabs or Doric LED modules using the
    Cyclops. For instructions, see this the complete manual.

### Assembly Instructions

1. Assemble the power switch

    Power switch assembly

  - Strip about 1 cm of insulation from each end of the hookup wires
  - Thread the stripped portion of the wire halfway through each of the
    switch's solder terminals. Fold the wire back, so that the stripped part is
    touching both sides of the terminal.
  - Solder the hookup wire to the terminals. Make sure the solder flows between the
    wires' copper braid and the switch terminals.
  - Slide the heat shrink from the back of each wire, over the solder joints.
    Hit then with a hot air gun or pass a lighter underneath them to shrink
    them into place over the solder joints.

1. Prepare the panels

    Power switch installation

  - Pull the paper backing off the panels.
  - Press the  power switch into position on the back panel. Orient the switch
    so that the 'on' symbol (-) is toward the middle of the panel and the 'off'
    symbol (o) is toward the outside. This will make the panel easier to mount
    on the enclosure. Hold the panel close to hole you are pushing the switch
    into as the panel material is pretty thin and could break if it is bent too
    much.
  - The switch will snap into place.

1. Install the heatsink on the PCB

    Heatsink installation

  - Flip the PCB so that the bottom is exposed.
  - Locate the large white square surrounding the exposed copper pad indicating
    the heatsink mounting location
  - Remove the paper backing from the heatsink to expose the adhesive surface
  - Press the heatsink into place on the PCB

1. Solder the power switch to the PCB.

    Power switch soldering

  - Solder the power switch to the two indicated terminals on the PCB.
  - Make sure you do this __after__ you have installed the switch in the rear
    panel.
  - The wires can be soldered to either solder point, orientation does not
    matter since this is a SPST switch.
  - __Note:__ The solder points are mistakenly covered in solder mask material.
    See [beta "feature" #1](#beta-"features") above if you are having trouble
    soldering the wires in these through holes.

1. Install the light pipes on the PCB.

    Light pipe installation

  - Insert the light pipes in the mounting positions in the front of the PCB.
  - Squeeze them into place firmly using some needle nose pliers or sturdy forceps.

1. Install the front panel on the enclosure

    Front panel installation

  - Using 4 of the 8 mount screws that came in the little plastic bag _outside_
    of the enclosure box, install the front panel on the enclosure.
  - __Note:__ Although they may work, I don't recommend use the screws that
    came with the box: they are are too tight and weak. I had to get the the
    enclosure manufacturer to send me the replacement screws because of this,
    which are supplied in the little baggie along with the other hardware.
  - __Final Note:__ The holes should not have to be tapped. The screws should just
    kind of jam themselves into the holes. Godspeed.
  - __The long story__: The reason for all this screw complexity is that the
    supplier of the enclosures (Box Inc.) was in the middle of replacing the
    dies used to create extrusions from which the enclosures are cut. If your
    enclosure happened to be made the with the old die, the screw holes will
    feel to tight and you should use the screws in the baggie. If those don't
    work try the ones that actually shipped with the enclosure in the white
    box. If nothing works, then you might have to drill out the holes with a
    drill. I have not had to resort to this yet.
  - __Final Note II:__ The screws that come with the enclosure are what I would
    call "cheese grade". They are zinc or something. The ones in the baggie are
    mild steel (I think) so those might be stronger. The reason I'm saying this
    is that it is possible to break the screws that actually ship with the
    enclosure (in the white box) so be cautious when turning them in.

1. Install the PCB in the enclosure.

    Front panel installation

  - Slide the PCB into the box using the __middle__ mounting rail.
  - __Note:__ When the BNC connectors come through the front panel, you will
    need to push them down a bit, slightly flexing the PCB to get the light
    pipes through the front panel. This is required to hold the light pipes in
    place.

1. Install the rear panel.

    Rear panel installation

  - Loop the two hook up wires and push them into the enclosure on top of the
    PCB.
  - Use the panel the push the remaining wire into the enclosure.
  - Use the remaining 4 screws to install the rear panel.

1. Install gain knob and button cover.

    Gain knob installation

  - Slip the toothed washer over the gain dial.
  - Tighten the jam nut on the gain dial's threads until just past finger tight
    using a pair of needle nose pliers.
  - __Note:__ Do not over-tighten using a combination spanner or you will
    strip the threads.
  - Turn the dial on the front panel _fully counter-clockwise_.
  - Slip the gain knob over the dial with the tick mark pointed slightly below
    the 0 position.
  - Tighten the set screw on the side of the knob to lock it into place using
    an Allen key.
  - When you turn the knob fully clockwise, the tick mark should be pointing
    close to the 1.5A position.
  - Press the red cover over the `TEST` switch until it snaps into place.

Congratulations, you are the proud owner of a high-precision, high-power,
high-speed LED driver that will make commercial drives feel a bit ridiculous
for costing so much and very self-conscious about their performance
characteristics. For further usage instructions, performance specs, theory of
operations, etc, etc, please refer to the complete manual located on the
repository. As stated previously:

1. If you have trouble during the assembly process, please don't hesitate to
   contact the [open-ephys
   forum](https://groups.google.com/forum/#!forum/open-ephys), where I will do
   my best to provide a quick and accurate response.
1. Pull requests and issue submissions are __welcome__ on the github repo and
   open ephys forum. If you have criticisms, fixes, suggestions for improvement
   in the docs etc, please let us know so we can implement them ASAP.

Happy stimulating.

Jon Newman  MWL@MIT  2016-02-20

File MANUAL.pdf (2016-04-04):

Cyclops is a high-power LED driver that enables precise control of light power for optogenetic stimulation. The circuit was developed by Jon Newman while in Steve Potter’s lab at Georgia Tech in order to complete his thesis work, which required the delivery of ultra-precise, continuously time-varying light waveforms for optogenetic stimulation [1,2]. This was, and still is, not possible with commercial hardware for optogenetic stimulation. Since its first use, the circuit has been improved in terms of speed, precision, programmability, and ease of use. This document provides construction, usage, and performance documentation for the Cyclops LED driver. This document evolves with the repository. To view old revisions, checkout tags or old commits using their SHA.

Note Github does not render alt text specified in Markdown figures as captions. Therefore, if you are viewing this document on Github, you will need to hover over figures to see their captions.

1

Contributors

- jonnew (http://www.mit.edu/~jpnewman/)
- Sung-Yon Kim (http://www.sungyonkimlab.org/)
- andersjasp (https://mndrive.umn.edu/brain/people)

Table of Contents

- Attribution
- Features
- Circuit Features
- Multiple stimulus generation options
- Performance Specifications
- Usage
- Feedback modes

– Current Feedback Mode
– Auxiliary Feedback Mode
- Stimulus Generation Options
- Construction
- Components
- Board Assembly
- Enclosure
- LED
- Quality Control Procedure
- License
- Hardware Licensing
- Software Licensing
- References

2

Attribution

It has been a long road to design and test the Cyclops to the point where it is in active use in many neuroscience labs around the world. This process has been a lot of work but also a very rewarding learning experience. I am very happy that this device may enable your scientific endeavours and I hope it will eventually be one small module in a of growing set of high-quality, open-source, and afforable tools that facilitate your research and enable an open, community-oriented approach to neuroscience.

I receive no monetary compensation from the sale of these devices. It would mean a great deal to me if you would consider referencing the following paper (for which the Cyclops was developed) in published work that makes use of the Cyclops.

J.P. Newman, M.-f. Fong, D.C. Millard, C.J. Whitmire, G.B. Stanley, S.M. Potter. S.M. Potter. Optogenetic feedback control of neural activity. eLife (4:e07192) 2015. doi: 10.7554/eLife.07192 [link] (http://elifesciences.org/content/4/e07192v1)

For instance, in your methods section:

Optical stimuli were delivered using the Cyclops LED driver (Newman et al., 2015; www.github.com/jonnew/Cyclops).

3

Features

Circuit Features

- Ultra-precise
- High power
- Up to 1.5A per LED
- Wide bandwidth

– ~2.5 MHz -3 dB bandwidth
– Maximum 200 ns 1.0A rise-time
- Current and optical feedback modes
- Built-in waveform generation
- Over-current protection
- Modular

– Arduino compatible
– 4 synchronizable optical channels
– Accepts external analog, gate, or trigger inputs

Multiple stimulus generation options

- External stimulus sequencer
- External digital trigger

– TTL logic level

- External analog waveform generator

– 0-5V analog signals

- Internal 12-bit DAC

– Synchronized across up to 4 drivers – Powerful Arduino library
– Programmable triggering logic
– Respond to USB input

4

Performance Specifications

The following oscilloscope traces give indicates of the circuit’s precision and speed. Note that time series traces are not averaged - these traces display per-pulse temporal characteristics. Optical characteristics and optical feedback signal for the Cyclops driver were provided by a Thorlabs PDA36 amplified photodiode set to 0 dB of transimpedance gain. Measurements were performed a single Osram golden dragon LED.


Figure 1: Trigger (yellow), current (pink), and light power (blue) traces during pulsed operation in current feedback mode. Input waveform is a 1 kHz 0 to 750 mV, 10% duty cycle square wave.

The following traces are the same as the previous ones except that the amplified photodiode was used to provide optical feedback. The slowdown compared to current feedback is due to a speed of the photodiode. A faster amplified photodiode would provide crisper rise and fall times

The current-feedback mode -3dB bandwidth was determined by applying a flat noise signal over 50 MHz with mean = 1.0V and Vpp = 500 mV into the EXT port with maximal current gain. It occurs at around 2.5 MHz.

5


Figure 2: Zoomed traces showing waveform 10-90% rise times. Optical rise time statistics are shown at the bottom of the image.


Figure 3: Zoomed traces showing waveform 10-90% fall times. Optical fall time statistics are shown at the bottom of the image.

6


Figure 4: Trigger (yellow), current (pink), and light power (blue) traces during pulsed operation in optical feedback mode. Input waveform is a 1 kHz 0 to 750 mV, 10% duty cycle square wave.

Figure 5: Zoomed traces showing waveform 10-90% rise times in optical feedback mode. Optical rise time statistics are shown at the bottom of the image.

7


Figure 6: Zoomed traces showing waveform 10-90% fall times in optical feedback mode. Optical fall time statistics are shown at the bottom of the image.

Figure 7: Optical bandwidth in current feedback mode. -3dBm occurs at ~2.4 MHz. Input signal was was noise, flat over 50 MHz, mean = 1.0V, Vpp = 500 mV.

8

Usage

The cyclops is a device that is capable of transforming voltage signals (e.g. sine waves, square pulses, etc.) into optical signals from high-power LEDs. Voltage signals to drive the device can be generated internally using an on-board digital to analog converter or can be delivered from an external source, such as a function generator or stimulus sequencer. The cyclops provides numerous measurements of circuit operation that can be recorded during an experiment such as LED current and stimulus reference voltages. The device can be controlled over a USB interface using its Arduino library. The device also can be configured to drive commercially available LED modules from Thorlabs and Doric.

Figure 8: Cyclops physical interface.

Below we provide an explanation of the operational modes of the device and the different ways it can be used to generate optical stimuli. Refer to the above diagram to locate the physical switches, dials, and connectors corresponding to verbal or iconic descriptions device settings.

Feedback modes

Current Feedback Mode

To use current feedback mode, push the F.B. MODE slide switch to the CURR

position ( | ). Using the circuit in current feedback mode ensures
that the forward current across the LED is precisely regulated according the voltage at the VREF pin. This configuration is a standard method for driving LEDs because the relationship between current and LED irradiance is smooth and monotonic. This means that more current across the LED will generate more light power (while staying within the LED’s maximum ratings, of course). However, the relationship between current and irradiance is not linear. For most LEDs, it looks like a logarithmic function. Additionally, the efficiency of the LED

9

is inversely related to its temperature. So, as the LED operates and heats up, the amount of light it produces drops even when the current is held constant. The severity of an LED’s temperature dependence and current/irradiance nonlinearity depend on the type of LED (roughly, the color and who made it). These properties should be clearly documented in the LED’s data sheet. With a quality LED and proper thermal management, the effects of temperature and static current/irradiance nonlinearity are fairly minimal and can be ignored in most situations.

Figure 9: Current feedback configuration.

Auxiliary Feedback Mode

To use auxiliary feedback mode, push the F.B. MODE slide switch to the AUX

position ( | ). When extremely stable, linear control of light power
is required, the auxiliary feedback input can be used to used to compensate for the temperature dependence and static nonlinearity of the current/irradiance relationship of the LED. For example, when the auxiliary voltage is supplied by an amplified photodiode that is somewhere indecent to radiation from the LED, or is sampled from the fiber transporting LED light, the gate voltage is adjusted such that the measured light power matches a DAC-supplied reference voltage. This is the case in the circuit diagram. This configuration is referred to as optical feedback mode. The PDA36A (https://www.thorlabs.com/thorProduct.cfm?partNumber=PDA36A) adjustable amplified photodiode from Thorlabs is a good option for supplying optical feedback. However, you can make your own amplified photodiode for a fraction of the price, and a design is included within the cyclops repository. Optical feedback completely linearizes the relationship between a supplied reference voltage and the light power produced by the LED by compensating for the current/irradiance nonlinearities and temperature dependence.

Figure 10: Optical feedback configuration.

10

Stimulus Generation Options

There are three ways to generate light signals using the driver. The behavior of each of these options is dependent on the feedback mode being used. The behavior of each input option is described in relation to the feedback mode of the driver.

1. The test button is always available and will override all other input modes. Using the TEST button the behavior of the circuit is:
- Source the current specified by the MAX CURR. dial.
- Generate the optical power specified by the h * mW level that is specified by the MAX POWER dial. The intensity of the LED will be dependent on the auxiliary feedback signal used which defines the ‘h’ parameter.
2. External input mode is engaged when the SOURCE switch is moved to the EXT position and user supplied voltage waveforms are present at the EXT BNC input. If the user attempts to supply more than 5V to the EXT input, the circuit will clamp the input signal to 5V. Using EXT mode, the behavior of the circuit is:
- Source the current specified by (EXT Voltage / 5V) * MAX CURR.
- Generate the optical power specified by (EXT Voltage/5V) * h * mW. The intensity of the LED will be dependent on the auxiliary feedback signal used which defines the ‘h’ parameter.
3. The internal digital to analog converter (DAC) is engaged when the SOURCE switch is moved to the DAC position and can be used to generate pre-programmed waveforms and waveform sequences triggered by a digital pulse to the TRIG input. This feature relies on optional Arduino installation and programming the device using its API. Using the DAC mode, the behavior of the circuit is:
- Source the current specified by (DAC Voltage / 5V) * MAX CURR.
- Generate the optical power specified by (DAC Voltage/5V) * h * mW. The intensity of the LED will be dependent on the auxiliary feedback signal used which defines the ‘h’ parameter.

11

Programming the onboard microcontroller

TODO

Construction

If you have questions during device assembly, please direct them to the open-ephys forum (https://groups.google.com/forum/#!forum/open-ephys) so that others may benefit. Pull requests improving this documentation are welcome.

Components

1. This google sheet contains a reasonably up-to-date parts list. However, it is manually managed and therefore prone to errors. It is recommended that method 2 be used instead

Google Doc List (https://docs.google.com/spreadsheets/d/1YQR_ujrZgILNx3XjomLKWgzDvirwKrKaRbVVzmBgk-s/edit?usp=sharing)

2. Fully assembled cyclops PCBs can be purchased from Circuit Hub

Cyclops on Circuit Hub (https://circuithub.com/projects/jonnew_/cyclops)

This also includes an up-to-date parts list for each PCB with optimized prices. Note that these parts are for a single PCB without the enclosure, power supply, etc. Those parts can be found on the “Circuit Hub Kit” tab of the Google spreadsheet above.

Most of the parts can be purchased from Digikey, but there are a few components that need to be bought from other sources such as Newark, Adafruit, and Samtec. All vendor, part number, and quantity information is listed on the BOM. If you are having trouble getting a part, check the Google Sheet as there are alternative suppliers listed for some parts.

The cyclops PCB can be constructed by purchasing from one of the pre-uploaded options:

- OSH Park (https://oshpark.com/shared_projects/fOfw7acB) - made in America, excellent quality. Minimum of 3 boards per order
- Seeed Studio (http://www.seeedstudio.com/service/index.php?r=pcb) - made in China, very good quality. Minimum of 5 boards per order.

Alternatively, the gerber files can be uploaded to the PCB fabrication service of your choice. The layer of each gerber file is identified by its file extension:

*.GKO = board outline
*.GTS = top solder mask

12


Figure 11: A bare Cyclops PCB, top side, fabricated by Seeed Studio.

*.GBS = bottom solder mask
*.GTO = top silk screen
*.GBO = bottom silk screen *.GTL = top copper
*.G2L = inner layer 2 copper *.G3L = inner layer 3 copper *.GBL = bottom copper
*.XLN = drill hits and sizes

PCB stencils, which are useful for applying solder paste to the boards, can be purchased from a service like OSH stencils (https://www.oshstencils.com) using the gerber files located in ./cyclops/stencil/. If you plan to hand solder the board, or don’t mind dispensing solder paste yourself, then you do not need to purchase these stencils.

The BOM includes several optional components, which are not in the pre-populated Digikey cart. These include:

- An extruded aluminum enclosure, which houses the completed board. The enclosure is recommended because the large voltages and current transients used to drive high power LEDs can cause capacitive and inductive interference with nearby recording equipment. Acrylic front and rear panels can be purchased from Ponoko using the links supplied in the BOM. The instructions below show how these plastic pieces are modified to provide proper electrical shielding.

13

- An M8-4 connector. This is a rather expensive connector that allows cyclops to drive Thorlabs LED modules (https://www.thorlabs.com/newgrouppage9.cfm?objectgroup_id=5206) or Doric LED modules. (http://doriclenses.com/life-sciences/243-led-modules)

Board Assembly

Materials

To assemble a Cyclops board, you will need the following materials

- A soldering iron and, if possible, a hot-air reflow device.

– At minimum, a soldering iron regulated to ~370 deg. c) will do the job.
– In addition to the iron, a hot-air rework tool or reflow oven are recommended and the assembly instructions below assume you are using one of these two options. A low cost, high-quality hot-air rework station can be purchased from SparkFun here. (https://www.sparkfun.com/products/10706)


Figure 12: A soldering iron can be used to assemble the PCB, but a hot air rework station makes things much easier. These can be purchased from Sparkfun. (https://www.sparkfun.com/products/10706)

- Copper braid (‘solder wick’) for solder removal (e.g this) (https://www.sparkfun.com/products/9327)
- Liquid flux (no-clean variants are easiest since they don’t have to be thoroughly removed after use)
- Solder paste (e.g. this) (http://www.digikey.com/product-detail/en/SMD291AX10T5/SMD291AX10T5-ND/3972568)
- Stereoscope or loupe (optional but nice for tracking down shorts.)

14

Figure 13: Wire solder and an soldering iron can be used to construct the PCB, but solder paste combined with a hot air rework station or a reflow oven makes things much easier. We use Chipquik 291ax10. (http://www.digikey.com/product-detail/en/SMD291AX10T5/SMD291AX10T5-ND/3972568)

- Isopropyl alcohol for cleaning flux off the board (e.g. this; (http://amzn.com/B0047YB3OW) optional)
- An anti-static mat (e.g. this; (http://amzn.com/B00009XT3H) optional but recommended to protect your work. . . )

Assembly Instructions

PCB component population and soldering is fairly straightforward and requires standard surface mount construction techniques.

- A tutorial on hot-air soldering can be found here. (https://youtu.be/1z0IiuQ35HU)
- A great tutorial filled with general tips and tricks for surface mount soldering can be found here. (https://youtu.be/pdGSFc7VjBE)

The following steps provide a visual guide to construct your own board. The goal is to create a fully populated PCB like this one:


Figure 14: Finished device (revision 3.3).

Following board construction, you should run through the electrical tests outlined in the next section before applying power.

15

1. Place the bare PCB on a flat surface, preferably one that is static dissipative or anti-static. Alternatively, the board can be mounted in a PCB vice.


Figure 15: Instead of populating components on a table, holding the PCB using a PanaVise can be helpful.

2. The silkscreen layer on the PCB (white text) has almost all the information you will need to properly populated the PCB. However, its a good ideal to to open the cyclops design in EAGLE. (http://www.cadsoftusa.com/eagle-pcb-design-software/) This will allow you to get detailed information on components before placing them on the board.

You can then the information tool to get detailed information on each component, e.g. to ensure you are placing the correct value resistor or capacitor.

3. After cleaning the surface of the board with isopropyl acholhol or similar, apply solder paste to each of the pads. For an excellent series of tips on effective methods for dispensing solder paste, see Mike’s video on the subject. (https://youtu.be/pdGSFc7VjBE) Do not apply solder paste to through-holes or the pads shown outlined in red in the following image. These will be hand soldered later in the assembly process.

The correct amount of solder paste to apply is ‘enough’. Each component contact should sit in a small amount of paste, but blobs of paste that envelop the component pad or pin may later result in a short. The following images show examples of good and bad solder placement.

If you need to pause at any point, you should store place the PCB in the fridge to prevent the flux in the solder paste from breaking down.

16

Figure 16: The cyclops PCB design in CadSoft EAGLE

17


Figure 17: By selecting the information tool and clicking the cross at the center of a component, you can pull up detailed info (e.g. part number)

Figure 18: Good solder placement.

18


Figure 19: Bad solder placement. Too much paste!

4. Populate all top-side surface mount components on the board. There is a single surface mount switch on the back of the board that will be hand soldered later. Additionally, all through hole components (e.g. power jack, BNC connectors, etc) will be populated later. Start by placing the integrated circuits (ICs). Use the stereoscope or loupe to ensure that pads are making contact with the pins of the placed components. Precise component alignment is not necessary. Components will self-align during the reflow process.
5. After placing the ICs, place the passive components (resistors, capacitors, inductors, diodes, and ferrite chips).
6. Next, reflow solder the board. We use a homemade reflow oven constructed from a toaster oven, Arduino board, reflow oven control shield, (http://www.rocketscream.com/shop/reflow-oven-controller-shield-arduino-compatiblee) and mains relay. (https://www.adafruit.com/products/268) You can make a similar one, use a commercial reflow oven, or use the hot air station. Reflow the solder paste on the board using your oven or hot air gun as described in the links above.
7. After the solder has cooled, examine solder pads using the stereoscope of loupe for solder bridges between pins, solder that has not melted, or pads lacking a decent solder joint. Fix any issues using a standard soldering iron If there are solder bridges present, get rid of them using some solder wick before moving on. Solder through-hole components in place using a standard soldering iron. A low cost reflow oven can be made form a toaster oven as shown here. This link also contains useful information on the basics of the reflow soldering process,

19


Figure 20: Integrated circuit population.

Figure 21: Zoomed view of integrated circuit placement.

20


Figure 22: Board following resistor and capacitor population.

Figure 23: Board with all top-side surface mount components installed.

21


Figure 24: Homemade reflow oven with the populated board inside.

Figure 25: The board is shown after the reflow temperature has been reached. Reflow will occur at different temperatures depending on the specification of the solder paste you are using.

22


Figure 26: Example of a short between IC pins. This must be resolved before moving forward.

8. Each board has an address (0 through 3) that is defined by two solder jumpers and the location of a ferrite chip. This allows cyclops boards to be stacked to share a power supply while being driven by a common microcontroller. For each board that will share a microcontroller, a unique address must be specified and the solder jumpers and ferrite chip must be soldered in appropriate positions to reflect this address. See the picture below to better understand this addressing scheme.
TODO: Pictures of circled 0 ohm jumpers
9. Flip the board over and install the final surface mount component, the AUX<>CURR slide switch, by hand soldering.
10. Next, populate all electromechanical components. This can be soldered in place with a standard soldering iron and a large chisel tip.
Note: The the barrel power jack (name: POWER, value: PJ-063BH on the schematic) should be mounted on the bottom of the board. It fits on both the top and the bottom, and will properly supply the board with power if mounted on the top. However, if the barrel jack is mounted on the top side of the board, it will not fit inside the enclosure.
11. If you are not planning on putting the PCB in an enclosure, jumper the solder points for the power switch together using AWG 20 (~1.8 mm diameter) braided copper wire or thicker.

TODO: Picture of jumpered switch solder points

12. Install the heatsink on the PCB

23


Figure 27: Dipping the copper braid in flux will make the solder wick much more redily.

24

Figure 28: Place the copper braid over the solder blob and then press with the soldering iron. You should see the excess solder wick up the copper braid.

25


Figure 29: Often you will not have to re-apply solder after this process because there will be enough left over to maintain a good electrical contact. Once you are satisfied the flux residue can be cleaned using isopropyl alcohol

Figure 30: Top side of board following electromechanical component installation.

26


Figure 31: Bottom side of board following electromechanical component installation.

27


Figure 32: Heatsink installation

Flip the PCB so that the bottom is exposed. Locate the large white square surrounding the exposed copper pad indicating the heatsink mounting location. Remove the paper backing from the heatsink to expose the adhesive surface Press the heatsink into place on the PCB.

13. [Optional] Install the Arduino

TODO: Image of desoldering and mounting

Remove the power jack from the Arduino using a hot air gun or desoldering tool. Press the Arduino the dedicated headers.

28

Enclosure

Materials

To construct the enclosure, you will use the following materials

Parts

1. Assembled Cyclops PCB (1x)
2. Extruded aluminum enclosure (1x)
3. Laser-cut enclosure panels (1x front, 1x rear)
4. Rocker switch (1x)
5. Hookup wire (2x, 15 cm lengths, 20 Ga or thicker)
6. Shrink tube (2x)
7. Gain knob (1x)
8. Toothed washer (1x)
9. Jam nut (1x)
10. Light pipes (3x)
11. Button cover (1x)
12. Screws to install panels (8x)
13. [optional] Conductive coating for EMI suppression (e.g. this). (http://amzn.com/B008OA931A)

Tools

- Soldering iron
- Hot air gun or lighter
- Phillips head screwdriver

Assembly Instructions

1. Assemble the power switch
- Strip about 1 cm of insulation from each end of the hookup wires
- Thread the stripped portion of the wire halfway through each of the switch’s solder terminals. Fold the wire back, so that the stripped part is touching both sides of the terminal.
- Solder the hookup wire to the terminals. Make sure the solder flows between the wires’ copper braid and the switch terminals.
- Slide the heat shrink from the back of each wire, over the solder joints. Hit then with a hot air gun or pass a lighter underneath them to shrink them into place over the solder joints.
2. Prepare the panels
- Pull the paper backing off the panels.

29

Figure 33: Power switch assembly


Figure 34: Power switch installation

30

- Optional: Spray the inside of each panel with conductive EMI suppression. Additionally, you may want to file the inner edge of the enclosure to reveal the bare alumnimum to ensure good contact between the coating the rest of the enclosure. Allow the coating to dry before proceeding.
- Press the power switch into position on the back panel. Orient the switch so that the ‘on’ symbol (-) is toward the middle of the panel and the ‘off’ symbol (o) is toward the outside. This will make the panel easier to mount on the enclosure. Hold the panel close to hole you are pushing the switch into as the panel material is pretty thin and could break if it is bent too much.
- The switch will snap into place.
3. Install the heatsink on the PCB if you have not already done so

Figure 35: Heatsink installation

- Flip the PCB so that the bottom is exposed.
- Locate the large white square surrounding the exposed copper pad indicating the heatsink mounting location
- Remove the paper backing from the heatsink to expose the adhesive surface
- Press the heatsink into place on the PCB
4. Solder the power switch to the PCB.
- Solder the power switch to the two indicated terminals on the PCB.

31

Figure 36: Power switch soldering

32

- Make sure you do this after you have installed the switch in the rear panel.
- The wires can be soldered to either solder point, orientation does not matter since this is a SPST switch.
- Optional: If you are using an EMI suppression coating, you should solder a third, fine gauge hookup wire to one of the GND test points on the board that you will eventually use to make electrical contact with the enclosure.
5. Install the light pipes on the PCB.


Figure 37: Light pipe installation

- Insert the light pipes in the mounting positions in the front of the PCB.
- Squeeze them into place firmly using some needle nose pliers or sturdy forceps.
6. Install the front panel on the enclosure
- Using 4 of the 8 mount screws that came in with the enclosure, install the front panel on the enclosure.
- Optional: If you are using an EMI suppression coating, strip the end of the fine wire that was soldered to GND and insert it into one of the screw holes before inserting the screws. When the screws are turned in, this will provide electrical contact with the enclosure.

33

Figure 38: Front panel installation

- Note: The holes should not have to be tapped. The screws should just kind of jam themselves into the holes. Godspeed.
- Note: The screws that come with the enclosure are what I would call “cheese grade”. It is possible to break these screws so be cautious when turning them in. If you think you will break the screws, then you might have to drill out the holes with twist drill to loosen them a bit. I have not had to resort to this yet.
7. Install the PCB in the enclosure.


Figure 39: Front panel installation

34

- Slide the PCB into the box using the middle mounting rail.
- Note: When the BNC connectors come through the front panel, you will need to push them down a bit, slightly flexing the PCB to get the light pipes through the front panel. This is required to hold the light pipes in place.
- Note: If you have installed an Arduino on your board, make sure you have removed the barrel jack power connector on the arduino first. If you leave it on the Arduino, it will press into the floor of the enclosure and possibly cause a short.
8. Install the rear panel.


Figure 40: Rear panel installation

- Loop the two hook up wires and push them into the enclosure on top of the PCB.
- Use the panel the push the remaining wire into the enclosure.
- Use the remaining 4 screws to install the rear panel.
9. Install gain knob and button cover.
- Slip the toothed washer over the gain dial.
- Tighten the jam nut on the gain dial’s threads until just past finger tight using a pair of needle nose pliers.
- Note: Do not over-tighten using a combination spanner or you will strip the threads.
- Turn the dial on the front panel fully counter-clockwise.
- Slip the gain knob over the dial with the tick mark pointed slightly below the 0 position.
- Tighten the set screw on the side of the knob to lock it into place using an Allen key.

35

Figure 41: Gain knob installation

- When you turn the knob fully clockwise, the tick mark should be pointing close to the 1.5A position.
- Press the red cover over the TEST switch until it snaps into place.

Congratulations, you are the proud owner of a high-precision, high-power, high-speed LED driver that will make commercial drives feel a bit ridiculous for costing so much and very self-conscious about their performance characteristics.

36

LED

There are several things to consider when determining the type of LED you wish to drive with the Cyclops and the configuration of the LED.

- Will optical stimulation be used in-vivo or through a microscope?
- Will it be performed on freely behaving animals?
- Do you need to perform bilateral stimulation?
- Will you need to incorporate an amplified photodiode into your stimulator to measure optical power or use use optical feedback to produce ultra precise light waveforms?

The answers to these questions will determine the type of LED you use, how it is coupled to the preparation (e.g. collimated for the back aperture of your microscope or, fiber coupled for in-vivo stimulation), and weather or not it needs to be commutated in some way. The following provide a few simple options for LED configurations, but there are many more to consider for your experiments.

Regardless of which you choose, the following is always true: keep the cabling to the LED as short as possible and ‘fat’ enough to handle high currents (AWG 18 or thicker). The currents and voltage used to drive high power LEDs are many orders of magnitude (like 6 or more. . . ) greater than those recorded during electrophysiology experiments. Also, the Cyclops is a fast circuit. Fast circuits hate long cables because they introduce appreciable delays and parasitics that can adversely affect operating characteristics. Very long cables will introduce ringing into light waveforms with fast edges! Ideally, the LED should be right next to the device. I typically mount my fiber coupled LEDs directly into the banana sockets on the back of the device using copper-clad printed circuit board so that my ‘cables’ are about 2 cm in length.

Fiber-coupled LED

DIY Solution

Anders Asp has contributed the following PDF document containing detailed instructions for fabricating a bilateral, commutated fiber-coupled LED for use in freely moving animals that works with the Cyclops driver:

Bilateral fiber-coupled LED (https://github.com/andersjasp/cyclops/blob/master/resources/Open_source_fiber-coupled_bilateral_LED_for_in_vivo_applications.pdf)

Thorlabs fiber-coupled LED modules

The cyclops can be used to Drive Thorlabs fiber-coupled LED modules. (https://www.thorlabs.com/newgrouppage9.cfm?objectgroup_id=5206) You will need to install the M8 4-position connector (http://www.thorlabs.com/newgrouppage9.cfm?objectgroup_id=2615&pn=CON8ML-4#5315) in expansion port B to drive these LEDs.

TODO: Pictures/instructions for M8 installation process in Thorlabs configuration

37


Figure 42: A simple ‘pigtailed’ LED module. A female SMA connector is cemented over a lens-free high power LED to form a near optimal butt-coupling between the fiber and the LED die.

38

Doric LED fiber-coupled modules

The cyclops can be used to Drive Doric fiber-coupled LED modules. (http://doriclenses.com/life-sciences/home/783-connectorized-single-led.html) You will need to install the M8 4-position connector (http://www.thorlabs.com/newgrouppage9.cfm?objectgroup_id=2615&pn=CON8ML-4#5315) in expansion port B to drive these LEDs.

TODO: Pictures/instructions for M8 installation process in Doric configuration

Microscope mounted LEDs

The cyclops can be used to Drive Thorlabs collimated LEDs (http://www.thorlabs.com/newgrouppage9.cfm?objectgroup_id=2615&pn=CON8ML-4#5315) for microscope-based stimulation. You will need to install the M8 4-position connector (http://www.thorlabs.com/newgrouppage9.cfm?objectgroup_id=2615&pn=CON8ML-4#5315) in expansion port B to drive these LEDs. See Thorlab fiber-coupled LED instructions for instructions.

39

Quality Control Procedure

The following procedure can be performed on assembled boards to ensure func-tionality.

Setup

- Insert alligator clip across power switch solder points
- Insert device into PCB clamp
- Power from 15V, 1.5A capable bench-top power supply.
- [ ] Power indicator LED turns on.

DC Levels

- Using a multimeter, probe the 12V, 2.5V, -5V, and -1.25V test points
- [ ] 12V good
- [ ] -5V good
- [ ] -1.25V good
- [ ] While probing the 2.5V test point, use a ESD-safe screwdriver on the trimpot to get exactly 2.5V.
- [ ] Seal the pot with a dab of hot-glue.

Dynamic characteristics

- Set MDO3000’s AFG to produce 1-5V, 100 Hz, 10% duty cycle square wave.
- Insert LED/amplified photodiode test fixture into banana sockets, IDC connector, and AUX BNC port.
- Insert AFG output of MDO3000 output into VCTL BNC port of device
- Bring CURR output of device to Ch1 of MDO3000
- Bring VREF output to MD3000
- Triggering on VREF Channel set scope to measure rise and fall times
- Bring front panel potentiometer to 50% position.
- Input switch to EXT source
- [ ] Examine wave shape and rise/fall times in current FB mode. Rise/fall times < 300 ns. No ringing on waveform.
- [ ] Examine wave shape and rise/fall times in optical FB mode. Rise/fall times < 300 ns. No ringing on waveform.
- [ ] Return FB switch to curr position
- [ ] Return input switch to OFF (middle) position

40

Overcurrent indication

- Bring gain potentiometer to full on position
- Briefly tap on the TEST button.
- [ ] Ensure that the >1A indicator LED turned on during pulse.
- [ ] Return gain potentiometer to zero position

Finish

- [ ] Remove all power connectors.
- [ ] Remove alligator clip.
- [ ] Initial and serial number the board using sharpie on the large power trace on the right side of the board.
- [ ] Enter board serial number into the spreadsheet.

License

Hardware Licensing

Cyclops LED Driver by Jonathan P. Newman is licensed under a Creative Com-mons Attribution-NonCommercial-ShareAlike 4.0 International License.Based on a work at https://github.com/jonnew/cyclops.

Software Licensing

Copyright (c) Jonathan P. Newman All right reserved.

The code associated with the Cyclops project is free software: you can redistribute it and/or modify it under the terms of the GNU General Public License as published by the Free Software Foundation, either version 3 of the License, or (at your option) any later version.

The code associated with the Cyclops project is distributed in the hope that it will be useful, but WITHOUT ANY WARRANTY; without even the implied warranty of MERCHANTABILITY or FITNESS FOR A PARTICULAR PURPOSE. See the GNU General Public License for more details.

You should have received a copy of the GNU General Public License along with this code. If not, see http://www.gnu.org/licenses/.

41

References

[1] J.P. Newman, M.-f. Fong, D.C. Millard, C.J. Whitmire, G.B. Stanley, S.M. Potter. S.M. Potter. Optogenetic feedback control of neural activity. (http://elifesciences.org/content/4/e07192v1) eLife (4:e07192) 2015. doi: 10.7554/eLife.07192
[2] T. Tchumatchenko*, J.P. Newman*, M.-f. Fong, S.M. Potter. Delivery of time-varying stimuli using ChR2. (http://journal.frontiersin.org/article/10.3389/fncir.2013.00184/full) (* - equal contributions, co-first authors) Front. Neural Circuits (7:184) 2013. doi: 10.3389/fncir.2013.00184

42

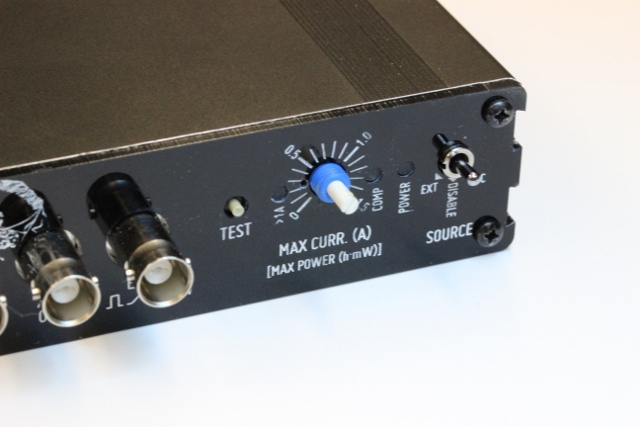
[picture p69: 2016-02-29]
resources/knob-install-1.jpg

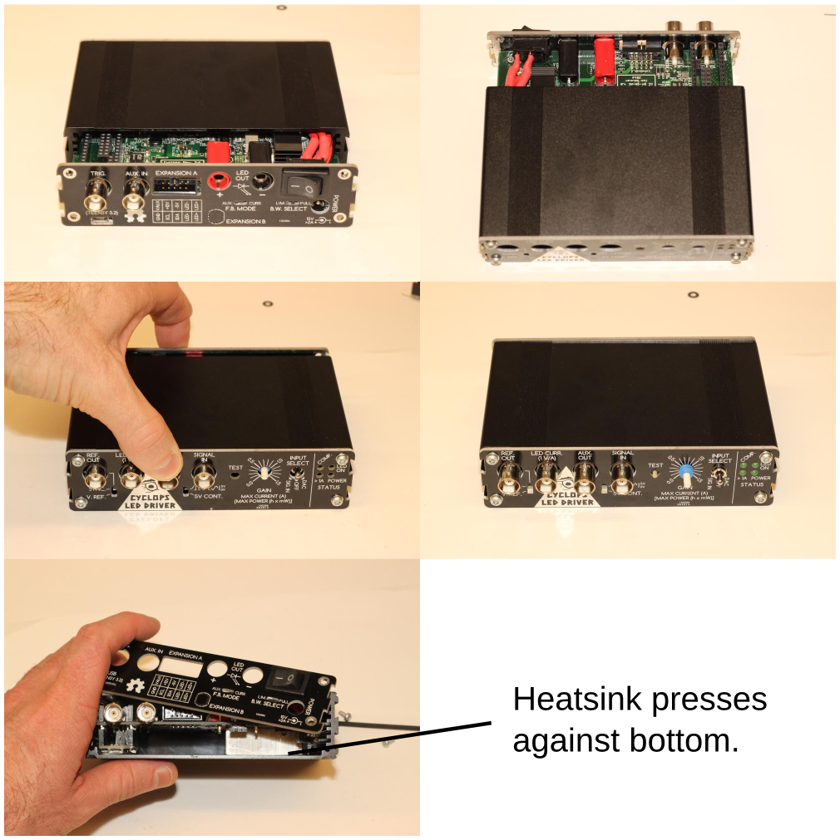
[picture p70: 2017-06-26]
resources/heatsink-install-steps.png

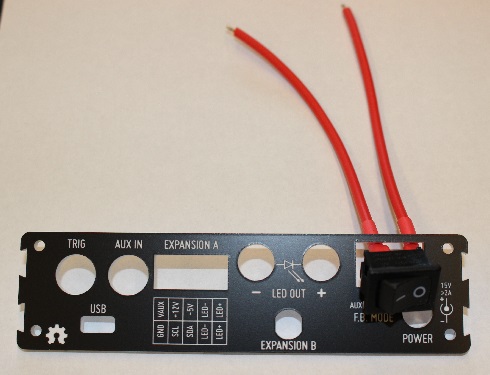
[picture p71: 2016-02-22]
resources/power-switch-install.jpg

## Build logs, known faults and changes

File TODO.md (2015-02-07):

TODO: R3.3 --> R3.5
=============

- [x] Move the banana jacks medial a touch to avoid hitting the enclosure when PCB is mounted on the middle rung.
  - Moved both banana jacks inward 0.075"
  - Also moved LED_PD connector inward 0.05"
- [x] Move the DAC/VCTL switch forward a touch so it is in line with the extent of the potentiometer knob.
  - Moved forward 0.025" since that is all the solder lug through hole connectors would allow.
- [x] CS1-4 are labeled backwards.
- [x] Put labels on the SPI (ICSP) connector.  
- [x] Trade out front panel pot for one with switch.
  - Instead, I just switched the DAC/VCTL switch to have a middle, disable position
- [x] The point of the OC protect circuit should be to deal with _mean_ overcurrent conditions. This means that the time constant of the filter in front of the analog current measurement pin should be on the order of 1 second.
  - Changed to 100 msec as compromise.
- [x] Add back panel cutouts for USB.
- [x] Move pcb mount plane down one level in enclosure.
- [x] Add a logic level converter to the trig input. This will allow the use of the arduino zero when it comes out.
- [x] Switching to the LT2052 was good because it allows the LED to turn fully off when the input signal is grounded. Its bad because it introduces small anomalies in the rising edge of the current/light waveform for large pulses from the off state. Can I find something that has really low input offset, is pretty fast, has RRIO, can handle the rails provided, and maybe, can allow the circuit to operate of of a single supply rail?
  - LMP7709? 
    - This is an de-compensated amplifier
    - Works very well for the current FB loop, but the follower configs are unstable
    - Use a single channel version for the optical loop and compensated amps for everything else.
    - Will require thought concerning the optical feedback loop since the loop gain cannot be determined a priori. Options are:
      - Adjustable attenuator (trimpot) on the VAUX input
      - Optical feedback path uses a compensated amplifier (e.g. LM7701)
  - The more I thought about this, the more apparent it became that my current design philosophy is being hindered by previous assumptions about circuit stability.
    - Now that the feedback path does not contain a secondary amplifier, it should be much more trivial to make the feedback loop stable even with an extremely fast amplifier
    - Enter the THS4281. 90 MHz GBWP, 35 V/us slew. And super stable in my control loop  according to spice simulations. Also has comparable voltage noise to the LMP7707 and rail to rail IO. Also can handle wider voltage rails. OK, lets use that!
- [x] The negative rail is not needed if you use a  low drift, precision amplifier that is RRO to ground. If this is the solution, then get rid of it, and use a simple barrel connector so people don't have to use a lab supply.
  - This is not actually true. To ensure the LED off, control signal must go slightly below ground.
- [x] Front panel holes are all too big, make their tolerances tighter.
- [x] Add on/off switch.
- [x] Simulate the usage of a class AB amplifier (diodes in series with base drive on totem pole) to decrease dead time during pulses.
  - Using a class A+AB amplifier really improves things. Response is very fast, reduced quiescent current compared to strait AB with diodes. Its been incorporated into r3.5.
- [x] The negative supply will be necessary because even RRIO amps can only approach the rails, they generally cannot go to them. This is true for the LMP7707, which I will be using for the gate drive circuit. Therefore, I need to generate a small negative supply.
  - Either a inverting switching regulator or a switched cap voltage inverter followed by a linear regulator.
  - Ended up using a Cuk inverter.
- [x] May want to consider the use of cold-switching on all front/rear panel switches
  - Switches control DC logic signals that open/close transistor switches near the circuitry of interest
  - Prevents high speed, precision signals from wandering to/from the front/back panels
  - I did this for the current/voltage optical feedback path since the switch was introducing a lot cabling, especially for the current feedback signal. 
- [x] Replace current negative LDO with something like the TPS7A30xx to combat the 1 MHz ripple produced by the new switching inverter from 15.
  - Just reuse the design on the puggleboard.
  - I'm not sure the increase in cost and complexity is worth it. The switching regulator has 1 mVP2P ripple at 1 MZ. The switching transients will be filtered by the ferrite separating linear and switching stages. The LM337 has ~20 dB PSRR at 1 MHz, which translates to a 10x reduction in ripple. I think we can deal with 100 uVP2P ripple given that the neg rail is being used for precision opamps with PSRRs in the 100's of dB.
- [x] Move the power jack to the right side of the board with a switch. Move the expansion port and banana jacks left to accommodate. Update the panel design to reflect this change.
  - Make sure the power jack is not going to run into the extruded enclosure (z direction)
- [x] Use the same package for the IRF510 and the LM317
- [x] Add non-pcb mount components to BOM
  - Suitable power supply
  - Trim pot dial
  - Power switch
  - Panels
  - M8 connector (optional)
  - Arduino
  - Test button cap
- [x] Replace LM317 with LT1963. Update supporting passives to make up for increased IC cost
  - Caps - do I even need the tantalum cap on the regulator output, or is my electrolytic in parallel with all of the bypass caps good enough?
    - I don't think I do, especially for a 12V output voltage. In this case, the ceramic bypass caps will work fine.
  - Loose over-voltage protection diode
  - Bring the positive rail up to 12V. The over-current warning circuit depends on this voltage so that will need to be updated. It would be better if this circuit used an actual reference instead of the positive rail to create a trigger for the OC led.  
  - Leave space for a tantalum or ceramic output cap, but do not populate.
    - These really should not be necessary, but I left a spot for a 10uF tantalum on the output side marked DNP.
  - Move one of the 100 uF caps to the input side of the regulator.
  - Loose all the output tantalums because their are enough paralleled ceramic bypass capacitors on isolated ICs to meet the stability requirements  
- [x] Increase Rsense to 1 ohm to get the most of the THS4281
  - Update the VI output amp to account for this, but leave the feedback network so that other sense resistors can be used without board modification.
- [x] Double check voltage ratings on ceramic caps.
- [ ] Final BOM update.
  - Account for (DNP) components on the spreadsheet that might be seen by others.
- [x] Increase the size of the 0603 outline silkscreen. Currently, it is not being printed because its too close to the pads.
- [x] For some reason, the labels on the CS and T jumpers are back to the old, wrong convention.
- [x] For the power jack, the middle pin and guide pins are too close to the board edge. Fix the package.
- [x] The holes for the banana jack connectors are a bit to small. Make them bigger and make their annulus bigger as well for easier soldering.
- [x] With a 1 Ohm current feedback resistor, I see a bit of ringing on the current waveform for low-mid currents (~100 mA or so). I should probably just a use a 0.5 Ohm resistor to increase the stability of the feedback loop at the cost of slightly degraded bandwidth (still sub 100 ns rise time though).
  - I'm starting to think that th THS4281 would be a cool idea if the LED was located inside the driver. This would ensure short cable lengths and prevent instabilities. But its not, so I'm questioning whether its worth it to use such a fast opamp instead of something slower that ensures stability even with ridiculous choices for cabling.
  - I don't know if this is the problem though. I ran a quick spice simulation and the change that most accurately captures the peaking I'm seeing is to add a series inductor to LED- terminal of around 80nF or so.

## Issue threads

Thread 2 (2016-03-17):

GUI - RPC Interface

command-paul, 2016-03-17:
A remote procedure call interface for the Cyclops Led driver for integration into the open-ephys software suite .

Prelim Report ::
Broadly settled on as to how to implement it and ways to further improve it.

Approach ::
•  Given the use of the attached microcontroller primarily serving purpouses for Signal generation / feedback, any operation [ISR/LWP] that ran concurrently with the main thread / procedure must be extremely small.

//-Possible approach 1
• queue RPC`s on the client side  and later transmit to the server when the server sends a "Free"/"Ready" State Signal. Doing this improves the precision of the output signal.
• In the case of a procedure having an infinite time of execution - bringing up the need for a terminate signal, a "Override"/ "accept next procedure “signal can be sent. since the serial TX is at the end of the procedure the precision of the signal is maintained.
• In order to implement the same, I could either modify the Serial ISR (finite/infinite time procedure) or check the number of waiting bytes in the serial buffer after each finite loop in an infinite time procedure.
• Could additionally take an execution time parameter and appropriately setup a timer interrupt / check, that returns to the parent.
• all procedures can be interleaved with breakpoints where (either the termination condition / ISR Terminate flag, is checked)

Issues/ Drawbacks::
• Sending the RPC after a "Free" signal increases latency. and a very small delay in the execution of the next RPC.
• Modifying the serial ISR May limit our maximum baud rate. (latency)
• Maintaining the queue on the client side is a small overhead.
• no way to soft reset the Arduino Micro controller in order to return to main.

ToDo::
•  add parameters to the procedure call input,
• modify the ISR and setup flags,
• work out a neat system to introduce break points.
• Write queue software for the client side

WIP code for the ^^ will be updated to https://github.com/command-paul/cyclops shortly.

jonnew, 2016-03-17:
In general, this looks quite promising. I'm greatly looking forward to a proof of concept on your fork. Don't worry about perfection. It will be much easier to talk about this once you have some proof of concept written.

If we switch to the 32 bit MCU, we will have a lot more processing power and therefore, the optimization will become less critical.

That said: its always good to think small IMO so I really like the approach you present. The RPC portion of the code should be primarily used to modify start/stop state of a waveform generation loop, as you suggest. Perhaps we should also have some atomic flag set by the waveform generation loop that indicates whether or not the MCU is in critical section of code. For instance, timing of pulses should take precedence over RPC input unless that input is specifically meant to interrupt the waveform generator.

Closed 2018-03-09.

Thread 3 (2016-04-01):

Power switch installation instructions

jsiegle, 2016-04-01:
The power switch needs to be placed through the appropriate hole in the enclosure before being soldered to the PCB. The instructions should be updated to reflect this.

jonnew, 2016-04-01:
Are you looking at the [Kit assembly guide](https://github.com/jonnew/cyclops/blob/master/resources/beta-kit-getting-started-guide.md) or the [main manual](https://github.com/jonnew/cyclops/blob/master/MANUAL.md)? This is mentioned in the kit assembly manual (step 2 is the switch in the panel, step 4 is solder the switch to the board. Some of the initial kits were shipped without a slip of paper directing people to the beta kit manual and that might be the problem.

I would like to combine the kit assembly manual with the main manual soon.

jsiegle, 2016-04-01:
I was reading the main manual. Looks good in the kit assembly guide!

jonnew, 2016-04-01:
I also now see that the main manual has a picture of the switch soldered in before being put in the panel, which is what you were saying, and is wrong. I will fix that.

Closed 2016-04-04.

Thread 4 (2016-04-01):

EMI shielding

jsiegle, 2016-04-01:
The manual recommends the use of conductive coating for EMI suppression. Is this really necessary?

jonnew, 2016-04-01:
Probably not in most situations. This is especially true if you are using a digital acquisition system, e.g. with Intan headstages and the cyclops is very far away from the analog portion of the circuit.

jsiegle, 2016-04-01:
I am, as it turns out

jonnew, 2016-04-01:
@jsiegle, sorry, I deleted your last comment when I clicked on it, can you repost?

jsiegle, 2016-04-01:
Just wanted to add that the power connector for the Arduino touches the bottom of the enclosure, so anyone using a conductive coating should be careful not to spray it there.

jonnew, 2016-04-01:
Ah, yes. I need to add this to the manual. When installing the arduino, I always remove the power jack using a hot air gun to prevent this.

jonnew, 2016-04-01:
Also to note: keeping cables short and low inductance is the best way to reduce EMI. I actually mount my LED right to the back of the device.

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

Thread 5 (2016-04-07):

Porting Cyclops to Teensy [32b MCU]

arrow-, 2016-04-07:
[Teensy](http://www.pjrc.com/teensy/index.html) is a powerful microcontroller development system built on the ARM Cortex Mx architecture. It can be programmed via USB using the [Teensyduino]() plugin on the Arduino IDE or the TeensyLoader application. With more hardware timers and DMA, the Teensy could provide lower latency in waveform updation and many more features like signal measurement and larger waveform storage.
## Feature Comparison (with Arduino)

The table [here](http://www.pjrc.com/teensy/teensyLC.html) (and [here](http://www.pjrc.com/teensy/teensy31.html)) from the Teensy main page summarises the major hardware features.

> The Arduino Due has similar capabilities as the Teensy. They use the same Cortex M4 architecture but different manufacturer. Also, Due is programmed using the [`bossac`](http://shumatech.com/web/products/bossa) toolchain whereas Teensy is programmed using the `avr-gcc` toolchain like all ATmega based Arduinos.

| Feature | Teensy LC | Teensy 3.2 | Arduino Uno [8b] | Arduino Mega [32b] |
| --- | --- | --- | --- | --- |
| Processor | Cortex-M0+ (MKL26Z64VFT4) | Cortex-M4 (MK20DX256VLH7) | Atmega328 | Atmega2560 |
| Clock Speed | 48MHz | upto 96MHz | 16MHz | 16MHz |
| Flash Mem | 62kB | 256kB | 32kB | 256kB |
| SRAM | 8kB | 64kB | 2kB | 8kB |
| EEPROM | ? | 2kB | 1kB | 4kB |
| DMA channels | 4 | 16 | 0 | 0 |
| ADC "inputs" | 13 | 21 | 6 | 16 |
| DAC "outputs" | 1 | 1 | 0 | 0 |
| Timers _(of all kinds)_ | 7 | 12 | 2 | 5 |
| USART | 3 | 4 | 1 | 3 |
| SPI | 2 | 2 | 1 | 1 |
| I2C | 2 | 2 | 1 | 1 |
## Porting Effort

Teensy uses the `avr-gcc` toolchain and allows user to run Arduino Sketches through the [Teensyduino](http://www.pjrc.com/teensy/teensyduino.html) plugin of Arduino IDE.
They have also [documented steps](http://www.pjrc.com/teensy/gcc.html) to utilise the `avr-gcc` toolchain directly _([baremetal Teensy development](http://www.seanet.com/~karllunt/bareteensy31.html))_, without using the Arduino headers.
Teensyduino has a large collection of general purpose [libraries](http://www.pjrc.com/teensy/td_libs.html).
Thus, we can choose to cherry-pick libraries that work without Arduino headers or work with Arduino compatible librarires.
## Teensy References and Links

[Teensy home page](http://www.pjrc.com/teensy/index.html)
[TeensyLoader CLI](http://www.pjrc.com/teensy/loader_cli.html)
[Teensy CPU datasheets](http://www.pjrc.com/teensy/datasheets.html), particularly the [K20 family](http://www.pjrc.com/teensy/K20P64M72SF1RM.pdf). All information on DMA was sourced from the `K20` datasheet.

arrow-, 2016-04-07:
Benefits to Cyclops
--------------------
* Higher Clock Speed and 32b word size give a great performance boost.
* There's a Native USB port and 3 other *(TTL)* Serial ports, allowing us to flash code while staying connected to other devices on (other) Serial ports.
* A lot of special timers are available. These timers can be chained (**not** in arbitrary configurations) to perform sets of tasks without the intervention from the CPU.
    - **FlexTimers** are general purpose timers which can be triggered from other modules like ADC, etc. The FlexTimer interrupts can be used to trigger user code in an `ISR` or trigger other modules.
    - **Periodic Interrupt Timers** (PIT) can be set up to trigger modules like DMA (4 channels of DMA can be *periodically triggered*), etc.
    - **Programmable Delay Blocks** (PDB) can be set up to control ADC, DAC, comparator.
* More digital I/O pins. And All I/O pins *can* be used as external interrupt pins on a Teensy.
>I/O pins on Teensy 2.0, 3.1 and Teensy++ 2.0 are 5V tolerant but on Teensy 3.2 and Teensy LC they are 3.3V tolerant.
* Typical "flashing" of the Teensy requires pressing of a `reset` push-button. There is a [guide](http://www.pjrc.com/teensy/jump_to_bootloader.html) that explains how to flash via a *software jump to bootloader*. This emulates "pressing of the push-button".
>Hence, the GUI can be used to program the Teensy and there would be no need to run TeensyLoader or invoke a `makefile` before an experiment.
* DMA can be used to write to almost any register on the CPU or peripherals without CPU intervention. DMA `transfer_done` interrupts can trigger other DMA transfers too!

Setting up DMA for SPI
----------------------
With a Teensy, we might be able to expolit the DMA to regularly write to the Cyclops DAC (via) SPI. This would free up the CPU to monitor the Serial interface and do waveform updates. The pipeline *could* be:
```
PIT -> DMA (2B transfer) to SPI `TXFIFO` -> `DMA_done` interrupt
```
Since the CPU is free to perform updates, it would just wait for `DMA-done`, after which it could update the contents of the DMA source for *"this"* iteration. Next DMA-SPI event would be triggered by the *next* PIT interrupt - maintaining a precise time-interval. The PIT periods can be updated by the CPU anytime.
>A Teensyduino library for use of DMA with SPI ([DmaSpi](https://github.com/crteensy/DmaSpi)) is available. There is also a `chip-select` option available, but the selection operation requires CPU intervention.

-------------------

IMO **it might not be possible to perform a DAC transfer to the Cyclops Driver without "any" intervention from CPU** in the way described. A complete transfer not only requires the DAC value to be pushed into SPI `TXFIFO`, but also

* selection of the DAC-slave-chip,
* the actual SPI transfer and,
* call to `load_dac()`.

The above described coordinated operations would require help from CPU. A complicated pipeline might work but, just like a CPU, even DMA can get overloaded.
**Moreover, since Teensy provides better clock speed, many hardware timers, and more memory; the best way to deliver precise signals would be making CPU handle all the waveform timing and SPI writes.**

This would *in theory* increase latency (delay in waveform updates), but compared to an Arduino, a Teensy runs 4 times faster anyway.
DMA can be utilised for other tasks *(see below)*.

Setup other USART ports as `DATASTREAM`
---------------------------------------
Other USART ports can be used for streaming data *into* the Teensy or streaming *out* to PC.
It might be possible to utilise the DMA triggers to do this operation without CPU intervention.

Measuring and recording signals
-----------------------------------
The Cyclops Driver,
>provides numerous measurements of circuit operation that can be recorded during an experiment such as LED current and stimulus reference voltages.

A PDB -> ADC -> DMA pipeline could be setup to record these analog signals and store them on the Teensy or send them to PC in chunks. PDB would ensure precise sampling intervals.
The `chunk-send` could also be be performed by the DMA over USART.

jonnew, 2016-04-08:
Just a quick note that I received this and I'm processing it. Looks good,
but I need to think about it a bit before replying.

On Thu, Apr 7, 2016 at 2:36 PM, Ananya Bahadur <notifications@github.com>
wrote:

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

--
Jonathan Newman
Postdoctoral Fellow, MIT
http://www.mit.edu/~jpnewman/

jonnew, 2016-04-11:
OK, I was able to go through this in detail. First of all, thanks for such a detailed feature request, its good that you have brought up so many potential ways to do this for our discussion. What these suggestions seem to boil down to are 4 major actions:

1. The PCB layout would need to change to accommodate the teensy over the Arduino (easy)
2. Remove Arduino dependencies from existing MCU library for the cyclops (easy). That said -- we need to think about users who might want to hack the cyclops using the Arduino IDE. Of course its bloated and the libraries are slow, etc. But its _easy_ and that is almost the most important thing.
3. Port current SPI implementation (which is CPU intensive arduino library, if I recall correctly) to a DMA based solution. I like the idea of using or adapting the [DmaSpi library](https://github.com/crteensy/DmaSpi/blob/master/ChipSelect.h) you mentioned, at least as a starting point.
  - While its always good to think about performance from the beginning, its more important to think about architecture and maintainability. It is OK to write low level, and even nasty code for doing things like driving SPI via DMA, but it __must__ be encapsulated away from  user-facing portions of the library. It needs to be wrapped up in a header with a nice interface that can be called transparently from the main functions that the user might want to use that are currently in cyclops.h.
  - One question: How will waveform updates in memory be synchronized with SPI writes to prevent waveform 'glitching'?
4. Use remaining processing power and potentially DMA for implementing the RPC handling engine.
  - I like the idea of having both input and output. That would be a pretty cool feature, but: most of the useful signals on the cyclops exist in the analog domain. How would these be digitized to be sent back to the OE interface.
  - The most important part is definitely a low bandwidth, low latency "trigger" stream from the host PC to the cyclops telling it to deliver pre-defined waveforms
  - A high bandwidth data stream with less emphasis on latency for uploading waveforms to flash memory that can be triggered later.

IMO: Best thing to do at this point is

1. Create a diagram of each component and how they will be linked (DMA, FIFOs, etc)
2. Assign classes and functions to each portion of the diagram
3. Get a POC going using simplified implementations of these components.

This will make problems in our thinking extremely obvious without wasting to much effort.

arrow-, 2016-04-17:
# Supporting Arduino IDE
We are (almost) completely dependent on the teensy (aka teensyduino) libraries, all device specific definitions are in there. The cyclops library would hence be fully compatible with the teensy environment. It's only that the user/developer can choose where they edit code and which tool they use to compile and flash it.
Developers can hack cyclops code on the Open Ephys GUI or the IDE (utilising teensyduino libraries in both cases) or even the [command line](http://www.seanet.com/%7Ekarllunt/bareteensy31.html). Cyclops Development on Arduino IDE is supported by default, out-of-the-box, no special effort needed.

# Not using DMA for SPI
I strongly discourage using the DmaSpi, simply because it doesn't fit our needs. DMA handled SPI makes sense only when there is a large amount of data (each byte of which requires no assistance from CPU) that needs to be moved into or out of memory via SPI, typically on a single channel.
Large writes or large reads hog CPU for no reason but we don't have *large* transfers; we have **frequent, small** transfers.
Each of these small transfers requires special assistance:

1. Chip Selection
2. Latch Activation on the Cyclops DACs

Moreover, the DMA controller can only offload burden from CPU but without CPU intervention, it will not be able to guarantee that waveforms don't "glitch".
And invloving CPU in scheduling DMA backed transfers would defeat the purpose of DMA, since the performance gain would be negligible (small transfers).
DMA Controller cannot schedule transfers.
If CPU is scheduling transfers, it could also do a few more instructions of Chip Select, Latching and Initiate-SPI-write at little extra cost.
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
jonnew, 2017-11-13:
The migration to Teensy 3.2 occurred in revision 3.6 of the device

Closed 2017-11-13.

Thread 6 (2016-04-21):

TRIG Pin Driving Capacitive Loads

jonnew, 2016-04-21:
There is a very nice automatic, bidirectional logic-level translator on the TRIG path that virtually ensures a user will not destroy the MCU due to incorrect logic level choice to the TRIG input. However, this device is very bad a driving capacitive loads and will go into an unstable oscillation if, e.g., a long coax is put on the TRIG BNC port when it is used as an output. May need to think of how to buffer the TRIG output when its used to send pulses rather than receive them.

Buffering may not even be necessary -- a series 100 Ohm resistor to decouple the output pin of the ADG3301 from the capacitance of the Coax will probably work in most circumstances at the cost of a slower rise time due to effective RC.

jonnew, 2017-08-07:
Fixed in 3.6.

Closed 2017-08-07.

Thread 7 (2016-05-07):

USB port on Cyclops betas

Callahanra, 2016-05-07:
Hi!
I have two cyclops kits and both are lacking the usb input port on the board. Do I need to install that myself? If so, I missed any reference to specs on what to use, do you have a recommendation?

Thanks!
Rebecca

jonnew, 2016-05-07:
Hi,

The cyclops is not supplied with an Arduino, which provides the USB input. To get access to that, you will need to get an Arduino Leonardo and install it on the cyclops during the assembly process.

Have you had a look at the getting started guide? Specifically, have a look at the "Kit Contents" section: https://github.com/jonnew/cyclops/blob/master/resources/beta-kit-getting-started-guide.md#kit-contents

jonnew, 2016-05-07:
Also, for general questions like this, feel free to email the open ephys forum: https://groups.google.com/forum/#!forum/open-ephys

That way the answer will be visible to a lot of other people that might also be confused. Let me know if this resolves your issues, BTW.

Callahanra, 2016-05-07:
Clears it up, thanks!

________________________________
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

Closed 2016-05-07.

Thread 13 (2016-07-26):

Overcurrent indicator always on

jsiegle, 2016-07-26:
I just assembled a Cyclops. The overcurrent indicator light turns on as soon as the module receives power and stays on indefinitely. I haven't tried hooking it up to an LED yet. Any idea what could be wrong?

jonnew, 2016-07-26:
Did you assemble it with the Arduino? If so, the LED is probably on because the default pin state corresponding to the overcurrent monitor is defaulted to HIGH. Try reprogramming the arduino with one of the [examples](https://github.com/jonnew/cyclops/tree/master/arduino/examples) and see if it turns off.

See this example for how to use the overcurrent protection feature:

https://github.com/jonnew/cyclops/blob/master/arduino/examples/over_current_protect/over_current_protect.ino

jsiegle, 2016-07-26:
Thanks, that fixed it.

Closed 2016-07-26.

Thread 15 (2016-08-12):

LED continuously on

jsiegle, 2016-08-12:
Whenever I turn on my Cyclops, there's a baseline LED current that won't go away. I can still modulate the signal with the Ext input, but the power never dips below the baseline level.

It was working fine last week, and I can't figure out what might have changed. Any suggestions for troubleshooting?

jonnew, 2016-08-12:
1. Are you referring to a measured baseline current? Does this translate to
perceiabel light being emitted from the LED? There is a baseline current
2. Physically remove the ext input. Does the problem go away? If so, your
ext input singal has a small non-zero voltage in its "off" position that
the cyclops is dutifully following
3. Move the source switch to the middle ("off") position. Still baseline
current?

On Fri, Aug 12, 2016 at 2:37 PM, Josh Siegle <notifications@github.com>
wrote:

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

--
Jonathan Newman
Postdoctoral Fellow, MIT
http://www.mit.edu/~jpnewman/

jsiegle, 2016-08-12:
1. The emitted light is quite bright (about 50% of max). I'm not measuring the current output.
2. Same thing happens when Ext is unconnected.
3. Same thing happens regardless of the position of the source switch.
4. Grounding the Ext input doesn't fix it either

jonnew, 2016-08-12:
That seems like a real issue with your circuit in particular (at least I hope so). What does the voltage on VREF look like?

jsiegle, 2016-08-12:
Ref Out = -0.005 V
LED Curr = 0.083 V
Ext In = 0.59 V (with nothing connected)

Seems like the DC offset on Ext In is the issue. But what could be causing it?

jonnew, 2016-08-12:
OK interesting.

- Voltage VREF is a direct reflection, with unity gain, of the control signal going into the current driver's feedback loop (see final page of the schematic https://github.com/jonnew/cyclops/blob/master/cyclops/cyclops_schematic.pdf). When this is zero, the current should be zero.
- Voltage on Ext In may or may not reflect anything given the state of the source switch (e.g. it could be floating when that is set to OFF or DAC; pg.1 one of schematic).

My new guess is that the circuit may be oscillating. Plug LED Curr measurement into an oscope and see if this is the case.

jonnew, 2016-08-24:
Any updates on this?

jsiegle, 2016-09-14:
No, I just switched to a different Cyclops board, which has been working great. The broken one still has the same issue. I don't see any oscillations, just a DC offset on the LED current.

jonnew, 2016-09-14:
Steven Flavell just brought down with a similar issue and it seems like it might be a PCB defect, which is very troubling. The issue there was the the 1.25V rail is shorted onto GND. This eventually destroys the Cuk inverter by overheating it. When you loose your negative rail all bets are off. To see if you are having a similar issue:

When you have a minute:

- Pull the PCB out of the enclosure
- Apply power
- Test the -5V, -1.25V, 2.5V, 5V, and 12V test points. Report measured voltages.

jsiegle, 2016-09-15:
-5V = -5.047
-1.25V = -1.26
2.5V = 2.50
5V = 5.00
12V = 12.06

If I plug in an LED, -1.25V goes up to -1.2. Not sure if that matters.

jonnew, 2016-09-15:
OK, I don't understand this issue then. Feel free to ship the board to me if you're not using it and I will see if I can figure this out. If its something general, I really want to fix it before the next production round...

jsiegle, 2016-09-16:
Shipping it back to you, should arrive early next week.

jonnew, 2016-09-16:
Awesome, thanks for that!

jonnew, 2016-09-19:
OK, it seems the issue is that my voltage rail -1.25V to 12V exceeds the maximum rating for this chip by 0.25V. This is likely what I causing the failure. This is bad because it will affect all devices. I will likely email the list with this as a know issue. The solution is to remove the chip and tie the feedback signal directly to the current sense resistor, loosing the ability to do optical FB. I don't think many people are using that option anyway.

It is fixed in the latest revision by the addition of a 6V rail.

jsiegle, 2016-09-19:
Cool, glad you figured it out!

cdeister, 2017-08-07:
Hey Jon. I had the same issue crop up. Do you still recommend to tie the feedback signal to the current sense resistor? Or, perhaps, is there some other chip I could swap it out for? Thanks as always for your work on this kind of stuff!

jonnew, 2017-08-07:
Hi Chris. Sorry to hear that. Please have a look at this post to for a fix. Also, if it works for you, please let me know!

https://groups.google.com/forum/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

jonnew, 2017-10-21:
This issue is fixed in revision 3.6

Closed 2017-10-21.

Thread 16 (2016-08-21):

Waveform Scheduler is not precise [Cyclops rev3.6]

oyeb, 2016-08-21:
**This affects only Teensy 3.2**
The Teensy loses time while in the ISR, while the code (and design) assumed that this _loss_ would be negligible. But, tests with an oscilloscope have confirmed that the _loss_ is significant ~20usec on avg. per ISR.

The only solution is to apply a compensation in the scheduling of _"the-coming-ISR"_. IMO, any design would require a compensation of this sort.

A portable solution is to **Measure time spent in ISR using another Timer and compensate**. This is better than hardcoding time spent in interrupts, because time depends on the clock speed (Teensy's clock speed can be changed easily!).

arrow-, 2016-08-21:
The :point_up_2: fix will also mitigate
* the error of cascading signal updates (will expand later)
* update period of 50usec but got period of ~70usec (or more)

Closed 2018-03-09.

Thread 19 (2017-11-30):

Can't trigger my Cyclops

Guennideluxe, 2017-11-30:
Hi Jon,

I'm Mathias from RWTH Aachen, Germany. We just bought 2 of the new  (already assembled) Cyclops 3.6 with tennsy 3.2 installed.
I worked in the past already with the old Cyclops with an arduino Leonardo and was quite happy with it.
But now I have a problem with the trigger.
I installed the recent version of the arduino IDE 1.8.5, installed the add on to program the teensy and the recent Cyclops library.
I loaded the trigger_pulse example to the teensy without a problem and set the feedback loop to current. I tried to trigger the Cyclops over the trig bnc port with a 5v spuare puls but nothing happens. I maked sure that the LED worked fine. I tried another example like chirp and it worked flawless. I have this problem on both Cyclops so i guess it's not a hardware problem.
I read already all documentation i could  find but didn't found a solution.
I hope you can help me out with this.
I'm looking forward to here from you.

Greetings from Germany

Mathias

jonnew, 2017-12-02:
Hi Mathias

This should now be fixed. It was simply a matter of the example script not being updated to match the new library (e.g. required called to static `Cyclops::begin()` and the addition of a direction argument (`RISING`, `FALLING`, `CHANGED`) to the `set_trigger` method.

Closed 2017-12-02.

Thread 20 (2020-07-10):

add Cyclops to open-neuroscience.com

amchagas, 2020-07-10:
Hello!

We are reaching out because we would love to have your project listed on [Open Neuroscience](<https://open-neuroscience.com>), and also share information about this project:

Open Neuroscience is a community run project, where we are curating and highlighting open source projects related to neurosciences!

Briefly, we have a website where short descritptions about projects are listed, with links to the projects themselves, their authors, together with images and other links.

Once a new entry is made, we make a quick check for spam, and publish it.

Once published, we make people aware of the new entry by [Twitter](https://twitter.com/openneurosci) and a [Facebook](https://www.facebook.com/OpenNeuroscience) group.

**To add information about their project, developers only need to fill out this [form](https://forms.gle/ByM8thAhZJkHBMQN8)**

In the form, people can add subfields and tags to their entries, so that projects are filterable and searchable on the website!

The reason why we have the form system is that it makes it open for everyone to contribute to the website and allows developers themselves to describe their projects!

Also, there are so many amazing projects coming out in Neurosciences that it would be impossible for us to keep track and log them all!

Please [get in touch](mailto:openeuroscience@gmail.com) if you have any questions or would like to collaborate!

jonnew, 2020-07-10:
You are free to use the materials here under the terms of the licenses.

Closed 2020-07-10.

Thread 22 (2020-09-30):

Get trigger input status in loop()

guidomeijer, 2020-09-30:
Hi Jon, I have a question. I want to have a pulse train going as long as the TRIG input is HIGH. I've tried doing this by using `set_trigger` to attach a function that starts the pulse train on the rising edge and another function that stops the pulse train on the falling edge. This didn't work out for me. I could only get one of the two functions to work, never both. And it doesn't seem like a very good way of doing this because I want to have the pulse train going as long as the trigger input is high (which varies from trail to trial). Is there a way to simply get whether the trigger is high or low in the loop() section?

guidomeijer, 2020-09-30:
Never mind, I figured it out, it was super easy. I just did `pinMode(TRIG0, INPUT); ` during `setup()` and then read it out with `digitalRead(TRIG0)`

jonnew, 2020-09-30:
yep that's a good solution. Just for the record, if you want to use the `set_trigger` function to do this, you can use the `mode` parameter `HIGH` as well. See the "parameters" section of the `attachInterrupt` docs, which is being used by this function

https://www.arduino.cc/reference/en/language/functions/external-interrupts/attachinterrupt/?setlang=it

When in doubt, your solution is better because it does not deal with asynchronous operations which interrupts inevitably do.

Closed 2020-09-30.

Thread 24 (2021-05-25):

LED warming up time course issue

polbech, 2021-05-25:
Hello!

I am currently using two Cyclops to deliver alternated pulsed light (8ms pulses) from 2 LEDs for imaging. I have noticed in my images a consistent artifact in the normalized fluorescence where it seems that a considerable number of frames start from very negative values. When checking the raw fluorescent traces in non-biological samples, it seems that the intensity of one of the LEDs progressively ramps up over the initial ~ 20 frames. The other LED shows an opposing trend, starting up higher and ramping down over a longer time span. Initially I figured it might be from the controller but when I checked in the oscilloscope, the output pulses seem to work fine. Image corresponds to an example of the fluorescent traces in a non biological sample, x axis represents frames, and y axis is normalized fluorescence.

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

With my limited knowledge about LEDs, I have figured out that at least the ramping down trend could be a junction temperature issue, but I still don't know if the ramping up behaviour is expected, if it can be fixed by compensating with the driver pulses, or if I should just replace the LED altogether. Has anyone observed a similar type of behaviour with their LEDs? Can this be fixed, perhaps compensating by tweaking the output from the driver in the initial frames, or should I just replace the LED altogether? In case this is an intrinsic LED thing, what would be the best way to correct this to minimize the contamination during real acquisition?

Thank you very much in advance and let me know if I can provide any further information!
Best,
Pol

PS: I am using the Luxeon Star LEDs from Quadica attached to a cylindrical aluminum heat sink with fins spanning the whole perimeter.

jonnew, 2021-05-25:
Hi,

This is interesting. It definitely seems like a thermal issue, although, as you've noted, this typically is inversely related with the LEDs output. The long time constant seems to indicate that the effect is integrating due to the heat sink.

A couple things:

- Do you have a a way to monitor the current output of the cyclops ("LED Curr") just to make sure you are actually getting correct constant current behavior over the course of the experiment? You can do this with an digital oscope by setting the trace persist to infinite and triggering on the rising edge of the current pulse.
- If the device is operating normally (delivering constant current), then you will need temperature or optical compensation. You can get optical compensation (the device controls optical power output instead of current) by using the optical-feedback mode along with an amplified photodiode. See page. 14 of the manual.

jonnew, 2021-05-25:
Another easier option is to simply let the system reach thermal equilibrium before opening the shutter for the LEDs' light path.

polbech, 2021-05-27:
Hi,

Thank you very much for your reply. The current output of the cyclops seemed to be stable from the beginning as measured from the oscilloscope. As you suggested in your second comment, I figured a way around it by letting the LED run in a low power offset in the non recorded periods, so at least the increasing trend is gone and the more normal, decreasing trend is now present.

Thanks for the tips!

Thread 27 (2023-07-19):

TRIG input remains at ~3V after receiving a single pulse

ThomasHainmueller, 2023-07-19:
Hi John,

When we use an arduino digital output (or any other 5V trigger pulse for that matter) we run into the following issue: The cyclops is triggered once as expected (attached LED blinks) but then the voltage at the 'TRIG' BNC input remains at a level of 2.9-3V persistently. We were able to mitigate this somewhat by connecting the 'TRIG' bnc pin and shield with a 100 kOhm resistor to allow that voltage to dissipate but it's not ideal and really doesn't work at all when the trigger comes from a 3.3V arduino (e.g. due).

Do you have any idea where that residual voltage comes from and is there any way to zero it out in arduino software or otherwise?

Thanks a lot for your help!
Thomas

jonnew, 2023-07-19:
Sounds like a hardware issue. Where did you get this device?

On Wed, Jul 19, 2023, 5:38 PM Thomas Hainmueller ***@***.***>
wrote:

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

jonnew, 2023-07-19:
Also trig is an input pin, how are you measuring it?

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

ThomasHainmueller, 2023-07-20:
Hi John,

Thanks a lot for the quick reply! The device has been in our lab for a bit. I'd have to ask around when/were it was bought, but it's not self-built. I have the same problem with two different cyclopses. I have a BNC with two separate leads attached and measure the voltage between the two with a voltmeter (see image below). The other ends of the cables go into the GND and Digital output pin of an arduino, respectively. The voltage is zero at baseline, rises to 5V when the pulse is given by the arduino but then stays at 2.9 and the cyclops can't be triggered anymore. With the resistor attached as shown on the photo, the voltage will settle back to zero after the pulse and the cyclops can be triggered repeatedly. Unfortunately I found no config where this would work with a 3.3V input pulse, mostly because that seems to leave only a very narrow range for resistors that would do the trick.

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

ThomasHainmueller, 2023-07-20:
The other ends are attached to the GND and Digital out pin of another Arduino (Due). However, I tried other 3.3V and 5V pulse generators instead and I get the same problem. The TRIG input on the cyclops will hold the 3V voltage even when the pulse generator is disconnected altogether, so it's unlikely to come from the input device. Also, when I attach the same input cable to the SIGNAL IN port on the cyclops, the voltage will go to zero when the input coming from the cables is set to zero.

jonnew, 2023-07-20:
Has any custom firmware been uploaded to the device that may have turned
those pins into outputs?

On Thu, Jul 20, 2023 at 4:08 PM Thomas Hainmueller ***@***.***>
wrote:

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

ThomasHainmueller, 2023-07-20:
To the best of my knowledge no (I 'inherited' the device). How would I re-upload the default firmware?

ThomasHainmueller, 2023-07-20:
Also, just to clarify: Does 'firmware' in this case mean the cyclops.h c++ library that's embedded in the teensy scripts or is there another piece of firmware that lives outside of that?

jonnew, 2023-07-20:
In the end, there is a teensy 3.2 in there that can be programmed in any
way (e.g. defining trig to be an output). You can use some of the example
scripts in there to get things back to normal if that has been changed.

https://github.com/jonnew/cyclops/tree/master/lib/cyclops/examples

On Thu, Jul 20, 2023 at 4:37 PM Thomas Hainmueller ***@***.***>
wrote:

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

ThomasHainmueller, 2023-07-20:
Unfortunately, that doesn't fix the issue. I just re-downloaded the entire library from github and re-uploaded the 'trigger pulse' example script, but I still get the same result. It doesn't make any sense to me, but it seems that somehow in this example the pin on the teensy stays high once it's triggered which prevents it from accepting further input until it's externally zeroed out...

jonnew, 2023-07-20:
OK. Sorry to hear that. At the end of the day, this is a copper trace connected to a pin on a micro controller. If that pin is programmed to be an input and is getting stuck at a voltage, then something seems like its wrong with the teensy. Perhaps an overvoltage condition of some sort occurred? These pins are 5V tolerant though.

You could get another Teensy 3.2 and replace the one thats in there if you want to see if that fixes your issue.

ThomasHainmueller, 2023-07-20:
No problem - I'm still somewhat optimistic we can figure this out. It's weird because the same problems comes up on three different cyclopses (just tried a third one) which are otherwise working fine. I was thinking to make some low-level tests with the built-in teensy to see if I can pin down the problem.

Is there a layout in the documentation that shows which pins of the teensy are connected to which in/outputs/actuators on the cyclops board and chassis? Maybe I'm blind but somehow I couldn't find it in the (otherwise excellent) manual. Thanks again for your help!

ThomasHainmueller, 2023-07-21:
...JK. Found it (cyclops_schematic.pdf).

ThomasHainmueller, 2023-07-21:
It's not a problem of your device directly, but others had issues with the pullup resistors of the teensy, too.
https://forum.pjrc.com/threads/46709-Teensy-3-2-INPUT_PULLUP-Problems-with-Pushbutton
It also does not have built-in pull-down resistors, so it is likely necessary to attach one externally as shown in the image, otherwise the pin floats like it did for me. I checked and the problem is also present with a bare-bone code that only reads from the digital pin without using any of the cyclops libraries, so it is a hardware issue (of the teensy itself).

ThomasHainmueller, 2023-07-21:
...Oook - finally got it to work. The issue with the pull-down resistor is really only an issue if the other end of the cable isn't (functionally) connected to anything - e.g. with a mechanical switch or something of that sort. With the Arduino on the input side, the problem only arises if you fail to declare the triggering input from the other device as an output (I'm an idiot...) once you do, the problem is solved. Leaving this here just in case it's useful to anybody else.

ThomasHainmueller, 2023-07-21:
Also, thank you again Jon for your input and bearing with me while figuring this out.

jonnew, 2023-07-21:
Yeah as you are getting at, if you are driving the pin with a low output impedance source, like a function generator or the output pin on another microcontroller, then the pull down/up state of that pin should not matter.

Glad you figured it out, you're not an idiot, have a good day.

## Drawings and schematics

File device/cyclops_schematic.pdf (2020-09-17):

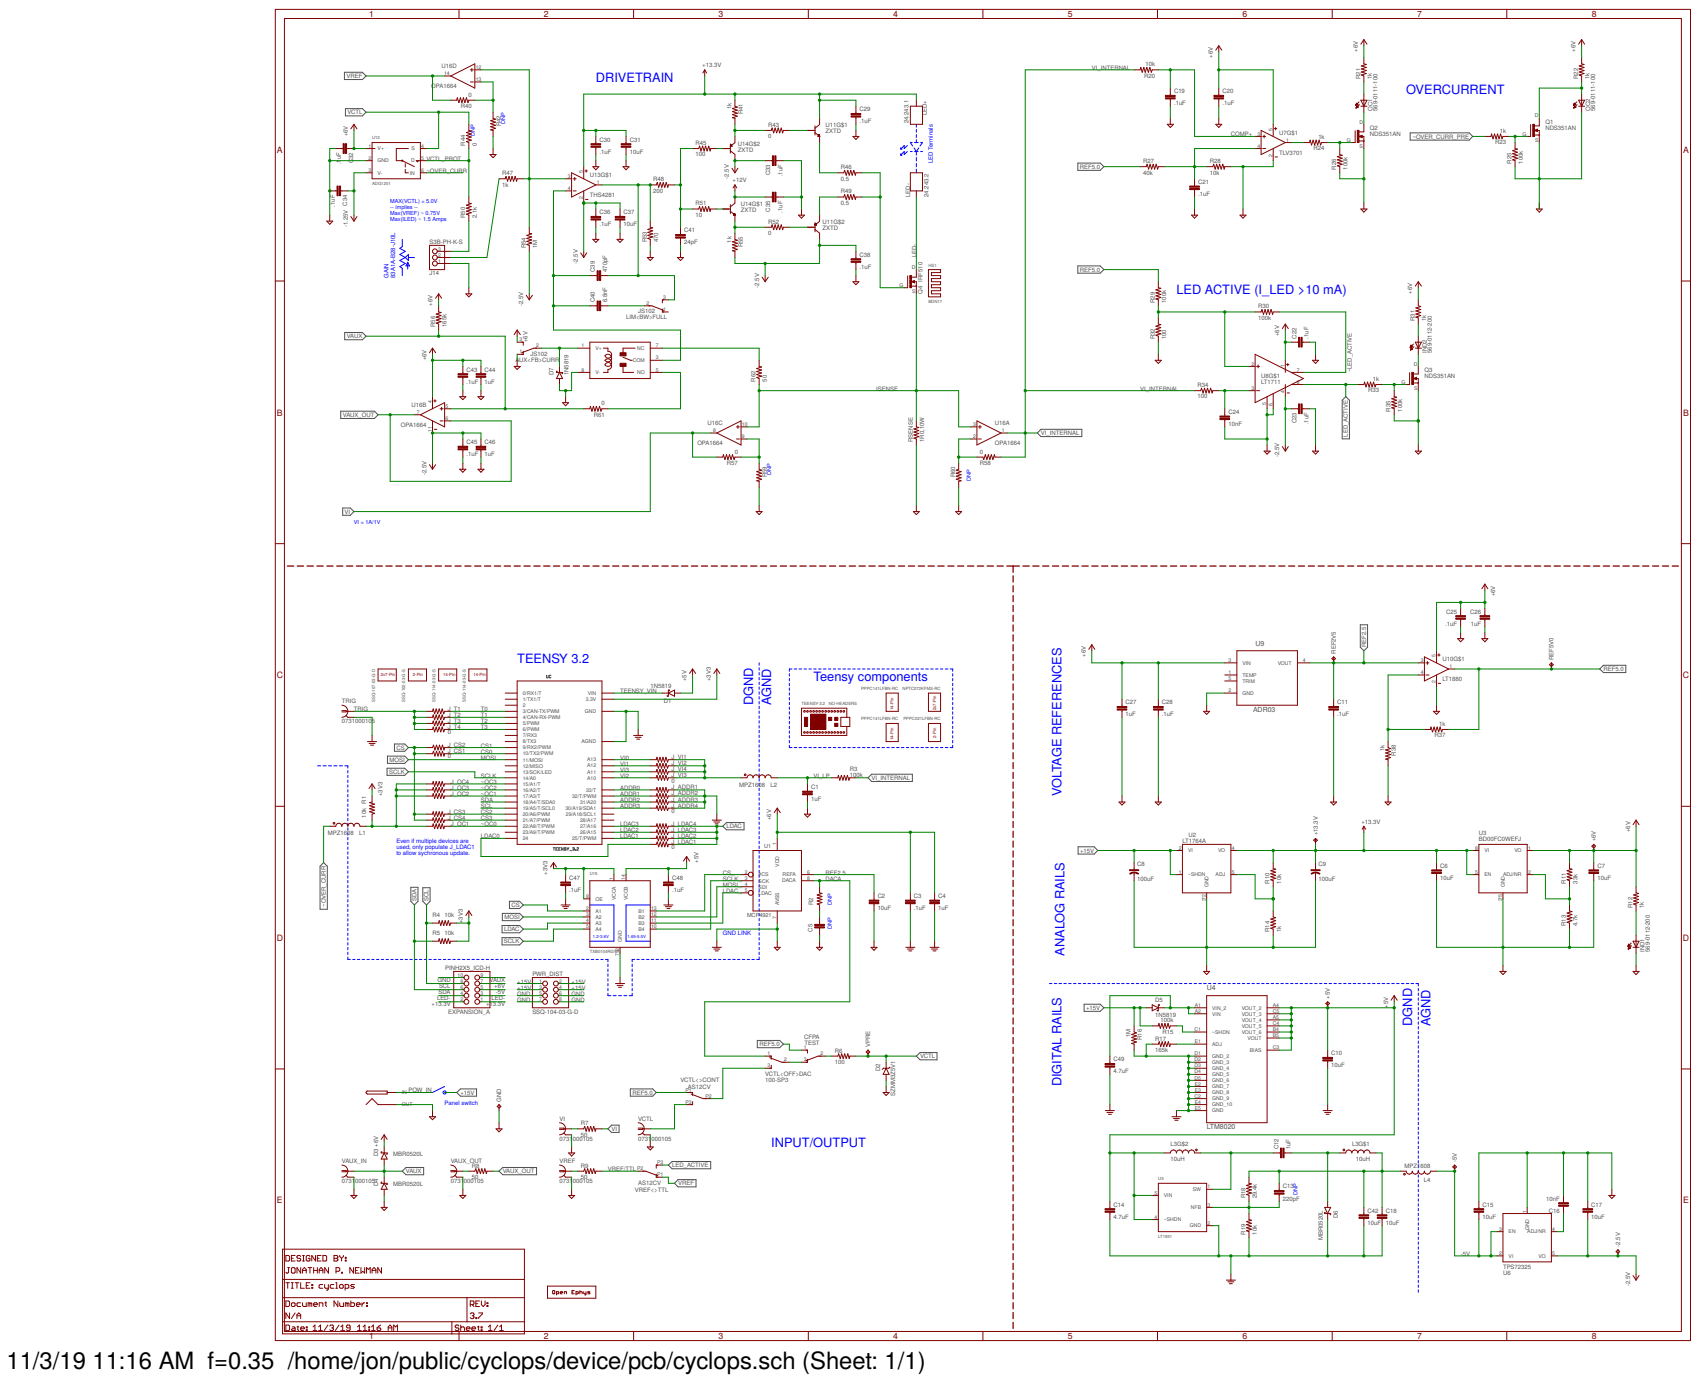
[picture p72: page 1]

MAX(VCTL) = 5.0V
-- implies -- Max(VREF) ~ 0.75V Max(ILED) ~ 1.5 Amps

SCLK | VI0 VI1 VI3 VI2 J_VI2

Even if multiple devices are
used, only populate J_LDAC1

LDAC_ SCLK_ MOSI_ CS_ | 8 REFA DACA

11/3/19 11:16 AM f=0.35 /home/jon/public/cyclops/device/pcb/cyclops.sch (Sheet: 1/1)

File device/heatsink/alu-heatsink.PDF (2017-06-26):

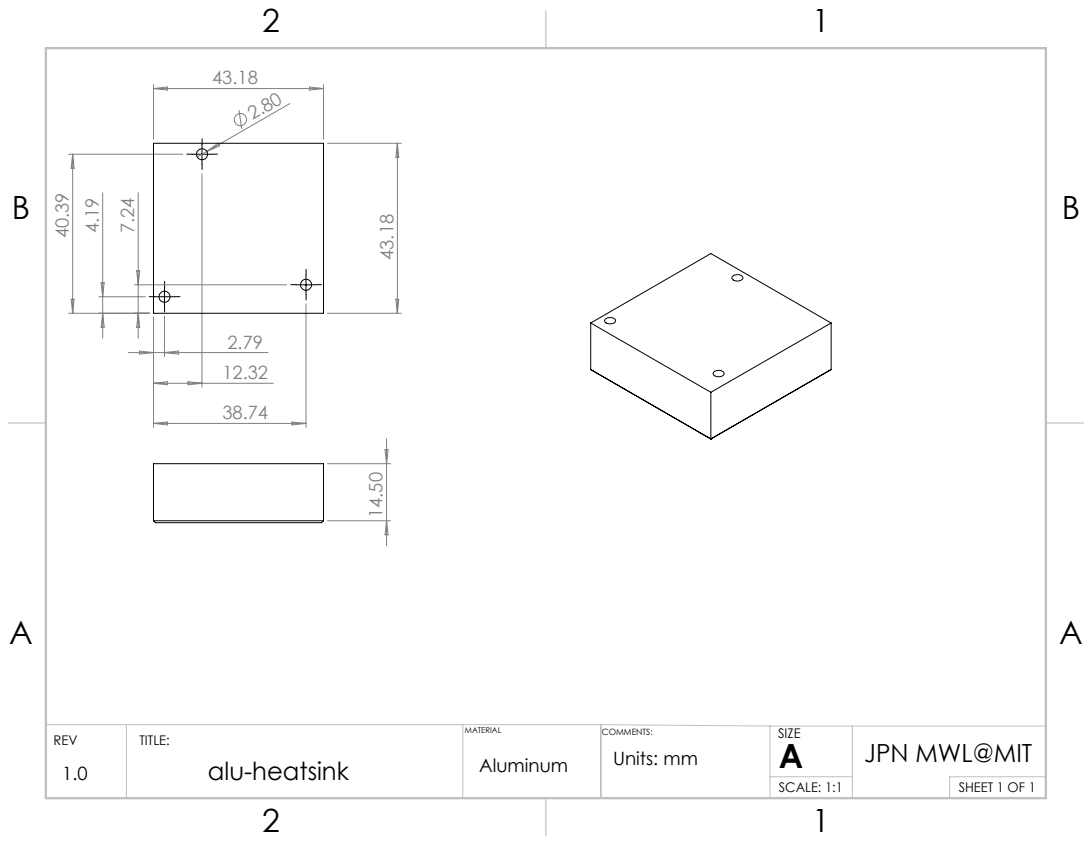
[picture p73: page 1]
SCALE: 1:1; SHEET 1 OF 1; SIZE TITLE:; MATERIAL; COMMENTS:; alu-heatsink; Aluminum; Units: mm

JPN MWL@MIT

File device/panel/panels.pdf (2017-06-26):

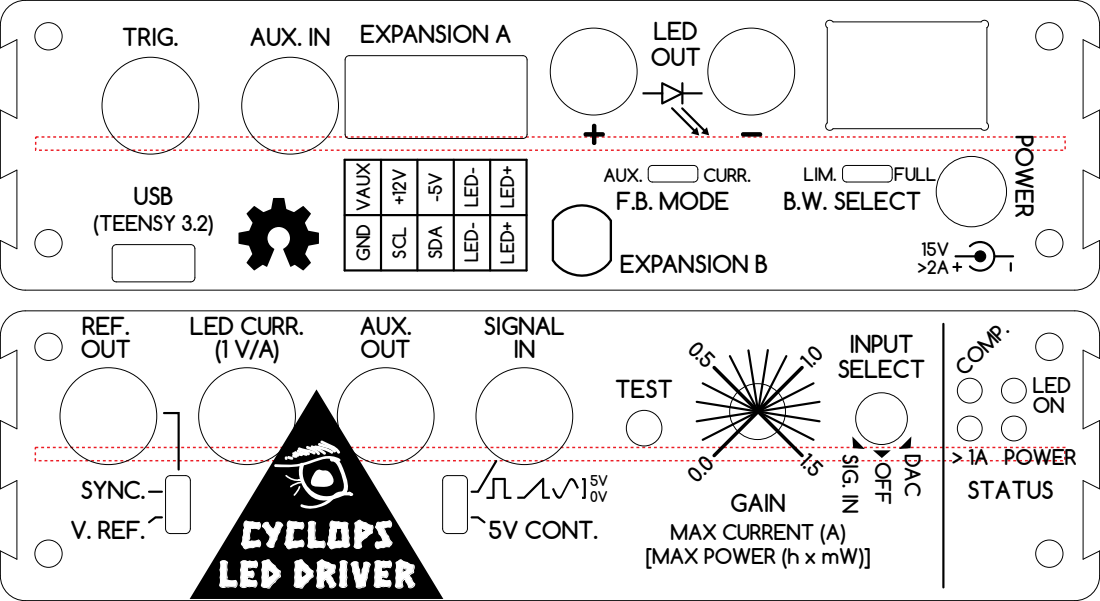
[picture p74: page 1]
CYCLOPS LED DRIVER; REF. OUT; LED CURR. (1 V/A); AUX. OUT; SIGNAL IN; V. REF.; 5V CONT.; TEST; INPUT SELECT; SYNC.; OFF; TRIG.; AUX. IN EXPANSION A; EXPANSION B; F.B. MODE; B.W. SELECT; POWER; USB (TEENSY 3.2); AUX.; CURR.; LIM.; FULL; VAUX; LED-; LED+; GND; SDA; SCL; LED OUT; SIG. IN; DAC; > 1A POWER; COMP.; LED ON; STATUS

GAIN
MAX CURRENT (A)
[MAX POWER (h x mW)]

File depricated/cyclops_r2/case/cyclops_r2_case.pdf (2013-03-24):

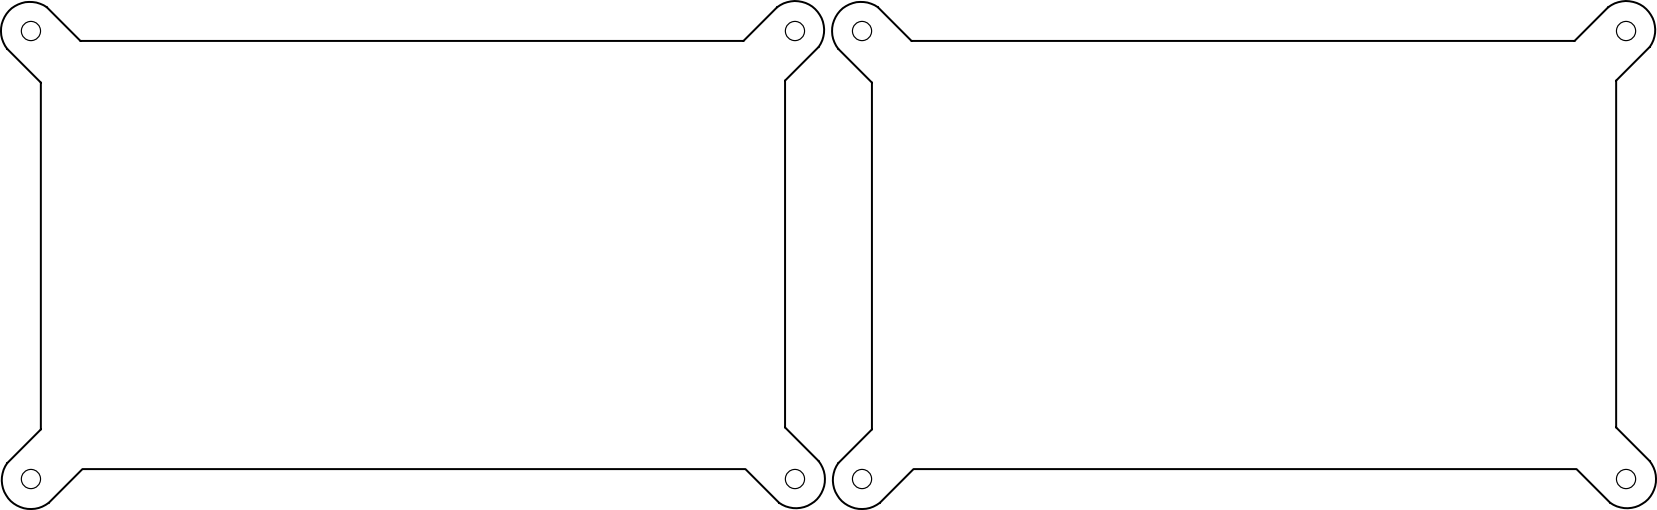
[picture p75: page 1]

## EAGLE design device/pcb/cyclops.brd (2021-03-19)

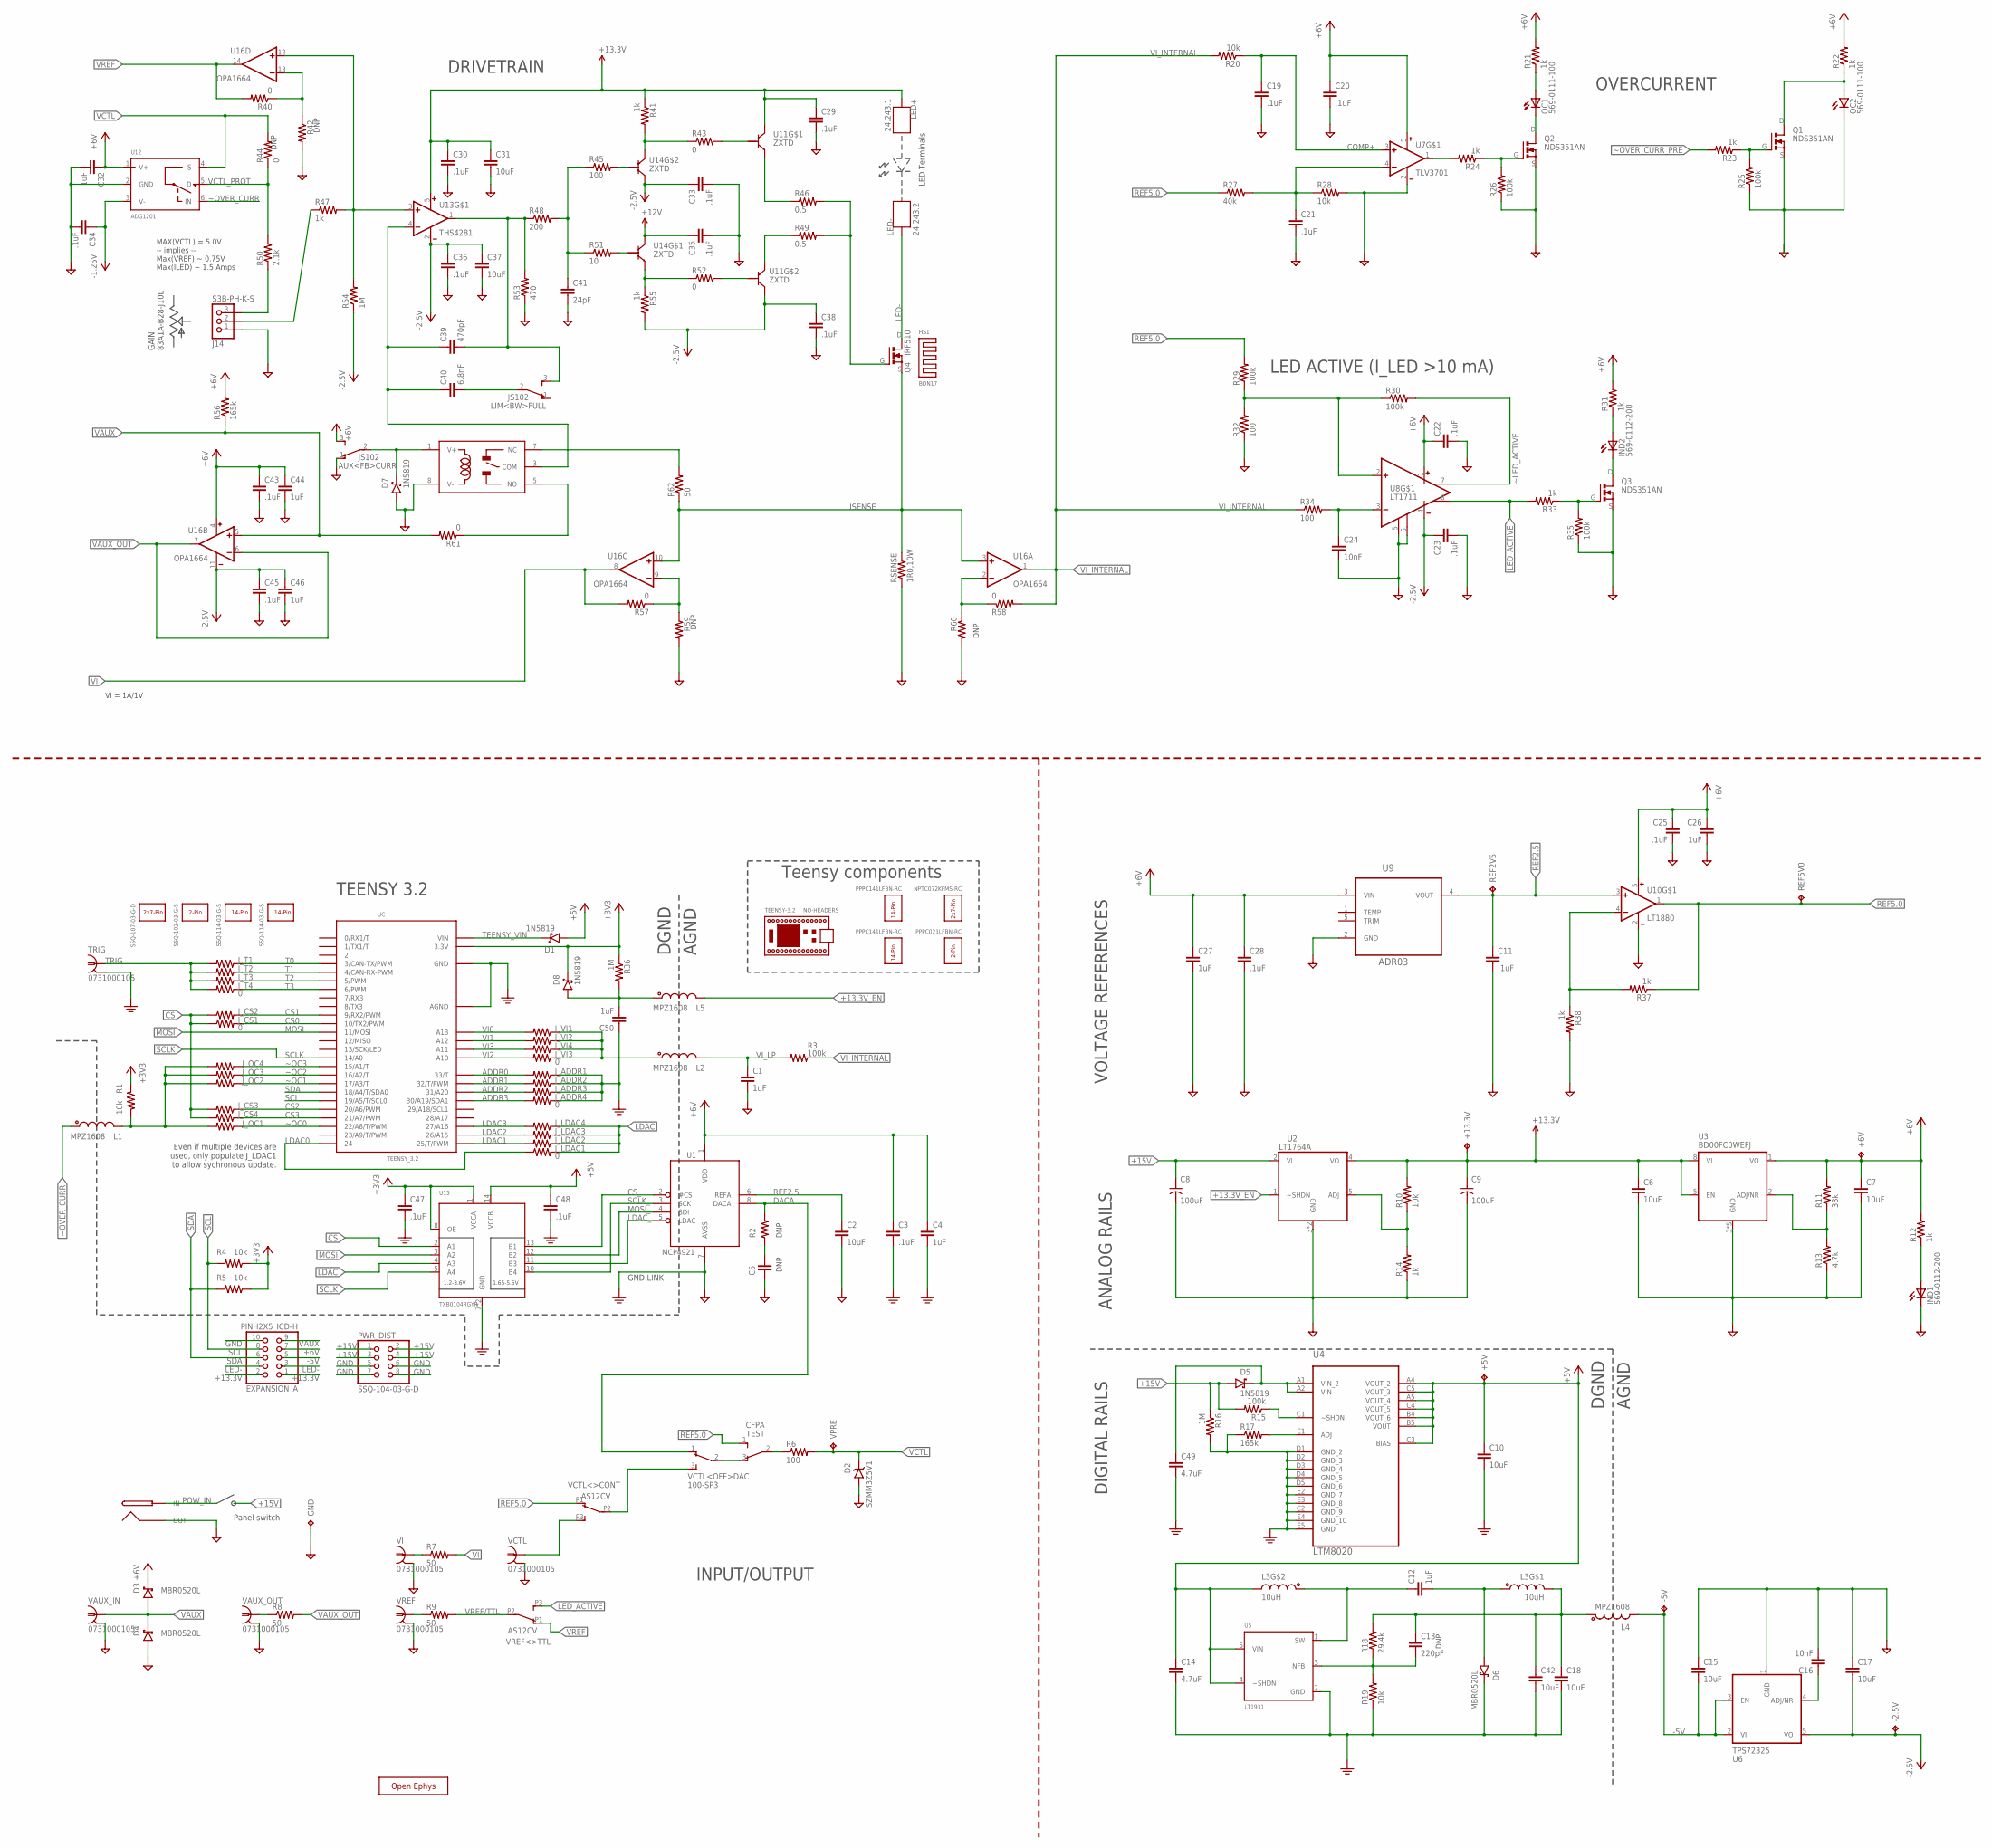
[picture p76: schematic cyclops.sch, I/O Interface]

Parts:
+5V, +6V, +13.3V: RCU-0C; RC0603
-2.5V, -5V: RCU-0C; RC0603
AUX<FB>CURR: JS102; JS102011SAQN
C1, C4, C12, C26, C27, C44, C46: 1uF; 0805
C2, C6, C7, C10, C15, C17, C18, C31, C37, C42: 10uF; 1206
C3, C11, C19, C20, C21, C22, C23, C25, C28, C29, C30, C32, C33, C34, C35, C36, C38, C43, C45, C47, C48, C50: .1uF; 0603
C5: C_0603; 0603
C8, C9: 100uF; 153CLV-0807
C13: 220pF; 0603
C14, C49: 4.7uF; 1206
C16, C24: 10nF; 0603
C39: 470pF; 0603
C40: 6.8nF; 0603
C41: 24pF; 0603
D1, D5, D7, D8: 1N5819; SOD123
D2: SZMM3Z5V1; SOD-323
D3, D4, D6: MBR0520L; SOD123
EXPANSION_A: PINH2X5_ICD-H; 2X05-IDC
GND: RCU-0C; RC0603
HS1: BDN17
IND: 569-0112-200; 569-011X-X00_LED_ARRAY
J14: S3B-PH-K-S
J_ADDR1, J_ADDR2, J_ADDR3, J_ADDR4: 0; 0402
J_CS1, J_CS2, J_CS3, J_CS4: 0; 0402
J_LDAC1, J_LDAC2, J_LDAC3, J_LDAC4: 0; 0402
J_OC1, J_OC2, J_OC3, J_OC4: 0; 0402
J_T1, J_T2, J_T3, J_T4: 0; 0402
J_VI1, J_VI2, J_VI3, J_VI4: 0; 0402
L1, L2, L4, L5: MPZ1608; 0603
L3: 10uH; CLS62
LED+: 24.243.1; A-2107
LED-: 24.243.2; A-2107
LIM<BW>FULL: JS102; JS102011SAQN
OC: 569-0111-100; 569-011X-X00_LED_ARRAY
POWER: PJ-063BH
PWR_DIST: SSQ-104-03-G-D; 2X04-BIG
Q1, Q2, Q3: NDS351AN; SOT23-GSD
Q4: IRF510; TO-262_01
R1, R4, R5, R10, R19, R20, R28: 10k; 0603
R2, R42, R59, R60: R_0603; 0603
R3, R15, R25, R26, R29, R30, R35: 100k; 0603
R6, R32, R34, R45: 100; 0603
R7, R8, R9, R62: 50; 1206
R11: 33k; 0603
R12, R14, R21, R22, R23, R24, R31, R33, R37, R38, R41, R47, R55: 1k; 0603
R13: 4.7k; 0603
R16, R36, R54: 1M; 0603
R17, R56: 165k; 0603
R18: 29.4k; 0603
R27: 40k; 0603
R40, R43, R44, R52, R57, R58, R61: 0; 0603
R46, R49: 0.5; 0603
R48: 200; 0603
R50: 2.1k; 0603
R51: 10; 0603
R53: 470; 0603
REF2V5, REF5V0: RCU-0C; RC0603
RSENSE: 1R0,10W; TO-252-THICK-FILM
S1: 1462042-8; 1462042
TEST: CFPA
TRIG: 0731000105
U1: MCP4921; SO08
U2: LT1764A; 5-DDPAK
U3: BD00FC0WEFJ; SOIC127P600X175-9N
U4: LTM8020; LGA21C127P5X5_625X625X242
U5: LT1931; SOT95P310X175-5N
U6: TPS72325; SOT-23-5
U7: TLV3701; SOT-23-5
U8: LT1711; SOP65P490X110-8N
U9: ADR03; SOT65P210X110-5N
U10: LT1880; SOT95P310X175-5N
U11, U14: ZXTD; SOT23-6
U12: ADG1201; SOT23-6
U13: THS4281; SOT95P310X175-5N
U15: TXB0104RGYR; 14QFN_2X6_2X2
U16: OPA1664; SO14
UC: TEENSY_3.2; TEENSY_3.1_CYCLOPS
VAUX_IN: 0731000105
VAUX_OUT: 0731000105
VCTL: 0731000105
VCTL<>CONT: AS12CV; AS12A*_SPDT
VCTL<OFF>DAC: 100-SP3; 2M1-SP1-T2-B4-M6RE
VI: 0731000105
VPRE: TPTP16R; RC0603
VREF: 0731000105
VREF<>TTL: AS12CV; AS12A*_SPDT
X1: OE-LOGO_14X10; OE-LOGO-14X10

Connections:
+3V3: C47.1, D8.C, R1.2, R4.1, R5.1, R36.1, U15.1 (VCCA), U15.8 (OE), UC.3.3V, UC.3.3V2 (3.3V)
+5V: +5V.1, C10.1, C14.1, C48.1, D1.A, L3.3 (2), U4.A4 (VOUT_2), U4.A5 (VOUT_4), U4.B4 (VOUT_6), U4.B5 (VOUT), U4.C3 (BIAS), U4.C4 (VOUT_5), U4.C5 (VOUT_3), U5.4 (~SHDN), U5.5 (VIN), U15.14 (VCCB)
+6V: +6V.1, AUX<FB>CURR.3, C3.1, C4.1, C7.1, C20.1, C22.1, C25.1, C26.1, C27.1, C28.1, C32.1, C43.1, C44.1, D3.C, EXPANSION_A.7, R11.2, R12.2, R21.2, R22.2, R31.2, R56.2, U1.1 (VDD), U3.1 (VO), U7.5 (V+), U8.1 (V+), U9.3 (VIN), U10.5 (V+), U12.1 (V+), U16.4 (V+)
+13.3V: +13.3V.1, C6.1, C9.+, C29.1, C30.1, C31.1, C35.1, EXPANSION_A.1, EXPANSION_A.2, LED+.1, LED+.2, R10.2, R41.1, U2.4 (VO), U3.5 (EN), U3.8 (VI), U11.1 (C), U13.5 (V+), U14.1 (C)
+13.3V_EN: L5.2, U2.1 (~SHDN)
+15V: C8.+, D5.A, PWR_DIST.1, PWR_DIST.2, PWR_DIST.3, PWR_DIST.4, R15.2, R16.1, U2.2 (VI)
-2.5V: -2.5V.1, C17.2, C23.1, C33.1, C34.1, C36.1, C37.1, C38.1, C45.1, C46.1, R54.1, R55.2, U6.5 (VO), U8.4 (V-), U11.3 (C), U12.3 (V-), U13.2 (V-), U14.3 (C), U16.11 (V-)
-5V: -5V.1, C15.2, EXPANSION_A.5, L4.2, U6.2 (VI), U6.3 (EN)
ADDR0: J_ADDR1.2, UC.33 (33/T)
ADDR1: J_ADDR2.2, UC.32 (32/T/PWM)
ADDR2: J_ADDR3.2, UC.31 (31/A20)
ADDR3: J_ADDR4.2, UC.30 (30/A19/SDA1)
COMP+: C19.1, R20.1, U7.3 (+IN)
CS: J_CS1.1, J_CS2.1, J_CS3.2, J_CS4.2, U15.2 (A1)
CS0: J_CS1.2, UC.10 (10/TX2/PWM)
CS1: J_CS2.2, UC.9 (9/RX2/PWM)
CS2: J_CS3.1, UC.20/A6 (20/A6/PWM)
CS3: J_CS4.1, UC.21/A7 (21/A7/PWM)
CS_: U1.2 (#CS), U15.13 (B1)
DACA: R2.2, U1.8 (DACA), VCTL<OFF>DAC.1
GND: AUX<FB>CURR.1, C1.2, C2.2, C3.2, C4.2, C5.2, C6.2, C7.2, C8.-, C9.-, C10.2, C11.2, C14.2, C15.1, C16.2, C17.1, C18.2, C19.2, C20.2, C21.2, C22.2, C23.2, C24.2, C25.2, C26.2, C27.2, C28.2, C29.2, C30.2, C31.2, C32.2, C33.2, C34.2, C35.2, C36.2, C37.2, C38.2, C41.2, C42.2, C43.2, C44.2, C45.2, C46.2, C47.2, C48.2, C49.2, C50.1, D2.A, D4.A, D6.C, D7.A, EXPANSION_A.10, GND.1, IND.C1 (C), J14.1, J_ADDR1.1, J_ADDR2.1, J_ADDR3.1, J_ADDR4.1, OC.C2 (C), POWER.2 (OUT), PWR_DIST.5, PWR_DIST.6, PWR_DIST.7, PWR_DIST.8, Q1.S, Q2.S, Q3.S, R13.1, R14.1, R16.2, R17.1, R19.1, R25.1, R26.1, R28.2, R32.1, R35.1, R38.2, R42.2, R53.1, R59.2, R60.2, RSENSE.1, S1.8 (V-), TRIG.2, TRIG.3 (2), U1.7 (AVSS), U2.3 (GND), U2.TAB (GND), U3.3 (GND), U3.4 (GND), U3.6 (GND), U3.7 (GND), U3.9 (GND), U4.C2 (GND_9), U4.D1 (GND_2), U4.D2 (GND_3), U4.D3 (GND_4), U4.D4 (GND_5), U4.D5 (GND_6), U4.E2 (GND_7), U4.E3 (GND_8), U4.E4 (GND_10), U4.E5 (GND), U5.2 (GND), U6.1 (GND), U7.2 (V-), U8.5 (LATCH), U8.6 (GND), U9.2 (GND), U10.2 (V-), U12.2 (GND), U15.7 (GND), U15.PAD (GND), UC.AGND, UC.GND, UC.GND2 (GND), VAUX_IN.2, VAUX_IN.3 (2), VAUX_OUT.2, VAUX_OUT.3 (2), VCTL.2, VCTL.3 (2), VI.2, VI.3 (2), VREF.2, VREF.3 (2)
IN: AUX<FB>CURR.2, D7.C, S1.1 (V+)
ISENSE: Q4.S, R62.1, RSENSE.2, U16.3 (+IN), U16.10 (+IN)
LDAC: J_LDAC1.2, J_LDAC2.1, J_LDAC3.1, J_LDAC4.1, U15.4 (A3)
LDAC0: J_LDAC1.1, UC.24
LDAC1: J_LDAC2.2, UC.25 (25/T/PWM)
LDAC2: J_LDAC3.2, UC.26 (26/A15)
LDAC3: J_LDAC4.2, UC.27 (27/A16)
LDAC_: U1.5 (LDAC), U15.11 (B3)
LED-: EXPANSION_A.3, EXPANSION_A.4, LED-.1, LED-.2, Q4.D
LED_ACTIVE: R33.2, U8.8 (~Q), VREF<>TTL.P3 (3)
MOSI: U15.3 (A2), UC.11 (11/MOSI)
MOSI_: U1.4 (SDI), U15.12 (B2)
unnamed: C5.1, R2.1
unnamed: OC.A1 (A), R21.1
unnamed: IND.A1 (A), R12.1
unnamed: R41.2, R43.1, U14.4 (E)
unnamed: C21.1, R27.2, R28.1, U7.4 (-IN)
unnamed: C50.2, D8.A, L5.1, R36.2
unnamed: C24.1, R34.2, U8.3 (-IN)
unnamed: R40.1, R42.1, U16.13 (-IN)
unnamed: OC.C1 (C), Q2.D
unnamed: R52.1, R55.1, U14.6 (E)
unnamed: R58.1, R60.1, U16.2 (-IN)
unnamed: R10.1, R14.2, U2.5 (ADJ)
unnamed: C39.2, LIM<BW>FULL.3, R48.1, R53.2, U13.1 (OUT)
unnamed: R6.1, TEST.2
unnamed: R57.1, R59.1, U16.9 (-IN)
unnamed: R37.2, R38.1, U10.4 (-IN)
unnamed: VCTL.1, VCTL<>CONT.P3 (3)
unnamed: C49.1, D5.C, U4.A1 (VIN_2), U4.A2 (VIN)
unnamed: R15.1, U4.C1 (~SHDN)
unnamed: R49.1, U11.4 (E)
unnamed: R46.1, U11.6 (E)
unnamed: Q4.G, R46.2, R49.2
unnamed: R24.2, U7.1 (OUT)
unnamed: Q2.G, R24.1, R26.2
unnamed: C12.1, L3.2 (1), U5.1 (SW)
unnamed: C12.2, D6.A, L3.1
unnamed: TEST.3 (1), VCTL<OFF>DAC.2
unnamed: C13.1, C18.1, C42.1, L3.4 (2), L4.1, R18.2
unnamed: C13.2, R18.1, R19.2, U5.3 (NFB)
unnamed: J14.2, R47.1
unnamed: R17.2, U4.E1 (ADJ)
unnamed: Q1.G, R23.1, R25.2
unnamed: C40.2, LIM<BW>FULL.2
unnamed: OC.A2 (A), Q1.D, R22.1
unnamed: R29.1, R30.1, R32.2, U8.2 (+IN)
unnamed: R11.1, R13.2, U3.2 (ADJ/NR)
unnamed: R52.2, U11.5 (B)
unnamed: R43.2, U11.2 (B)
unnamed: IND.A2 (A), R31.1
unnamed: IND.C2 (C), Q3.D
unnamed: R51.2, U14.2 (B)
unnamed: Q3.G, R33.1, R35.2
unnamed: R45.2, U14.5 (B)
unnamed: C16.1, U6.4 (ADJ/NR)
unnamed: R8.1, VAUX_OUT.1
unnamed: C39.1, C40.1, S1.3 (COM), U13.4 (-IN)
unnamed: R7.1, VI.1
unnamed: R9.1, VREF.1
unnamed: R62.2, S1.7 (NC)
unnamed: R61.1, S1.5 (NO)
unnamed: C41.1, R45.1, R48.2, R51.1
POW_IN: POWER.1 (IN)
REF2.5: C2.1, C11.1, REF2V5.1, U1.6 (REFA), U9.4 (VOUT), U10.3 (+IN)
REF5.0: R27.1, R29.2, R37.1, REF5V0.1, TEST.1 (3), U10.1 (OUT), VCTL<>CONT.P1 (1)
SCL: EXPANSION_A.8, R4.2, UC.19/A5 (19/A5/T/SCL0)
SCLK: U15.5 (A4), UC.14/A0
SCLK_: U1.3 (SCK), U15.10 (B4)
SDA: EXPANSION_A.6, R5.2, UC.18/A4 (18/A4/T/SDA0)
T0: J_T1.1, UC.3 (3/CAN-TX/PWM)
T1: J_T2.1, UC.4 (4/CAN-RX-PWM)
T2: J_T3.1, UC.5 (5/PWM)
T3: J_T4.1, UC.6 (6/PWM)
TEENSY_VIN: D1.C, UC.VIN
TRIG: J_T1.2, J_T2.2, J_T3.2, J_T4.2, TRIG.1
VAUX: D3.A, D4.C, EXPANSION_A.9, R56.1, R61.2, U16.5 (+IN), VAUX_IN.1
VAUX_OUT: R8.2, U16.6 (-IN), U16.7 (OUT)
VCTL: D2.C, R6.2, R44.2, U12.4 (S), VPRE.1
VCTL_PROT: R44.1, R50.2, U12.5 (D)
VCTL_PROTECT: J14.3, R50.1
VI: R7.2, R57.2, U16.8 (OUT)
VI0: J_VI1.2, UC.A13
VI1: J_VI2.2, UC.A12
VI2: J_VI3.2, UC.A10
VI3: J_VI4.2, UC.A11
VINPUT: VCTL<>CONT.P2 (2), VCTL<OFF>DAC.3
VI_IN: J_VI1.1, J_VI2.1, J_VI3.1, J_VI4.1, L2.1
VI_INTERNAL: R3.1, R20.2, R34.1, R58.2, U16.1 (OUT)
VI_LP: C1.1, L2.2, R3.2
VREF: R40.2, U16.14 (OUT), VREF<>TTL.P1 (1)
VREF/TTL: R9.2, VREF<>TTL.P2 (2)
_VREF: R47.2, R54.2, U13.3 (+IN), U16.12 (+IN)
~LED_ACTIVE: R30.2, U8.7 (Q)
~OC0: J_OC1.1, UC.22/A8 (22/A8/T/PWM)
~OC1: J_OC2.1, UC.17/A3 (17/A3/T)
~OC2: J_OC3.1, UC.16/A2 (16/A2/T)
~OC3: J_OC4.1, UC.15/A1 (15/A1/T)
~OVER_CURR: L1.1, U12.6 (IN)
~OVER_CURR_PRE: J_OC1.2, J_OC2.2, J_OC3.2, J_OC4.2, L1.2, R1.1, R23.2

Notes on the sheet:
GND LINK
INPUT/OUTPUT
Panel switch
AGND
DGND
Teensy components
DNP
Even if multiple devices are used, only populate J_LDAC1 to allow sychronous update.
ANALOG RAILS
DIGITAL RAILS
LED ACTIVE (I_LED >10 mA)
OVERCURRENT
VOLTAGE REFERENCES
LED Terminals
MAX(VCTL) = 5.0V -- implies -- Max(VREF) ~ 0.75V Max(ILED) ~ 1.5 Amps
VI = 1A/1V
DRIVETRAIN
GAIN 83A1A-B28-J10L
TEENSY 3.2

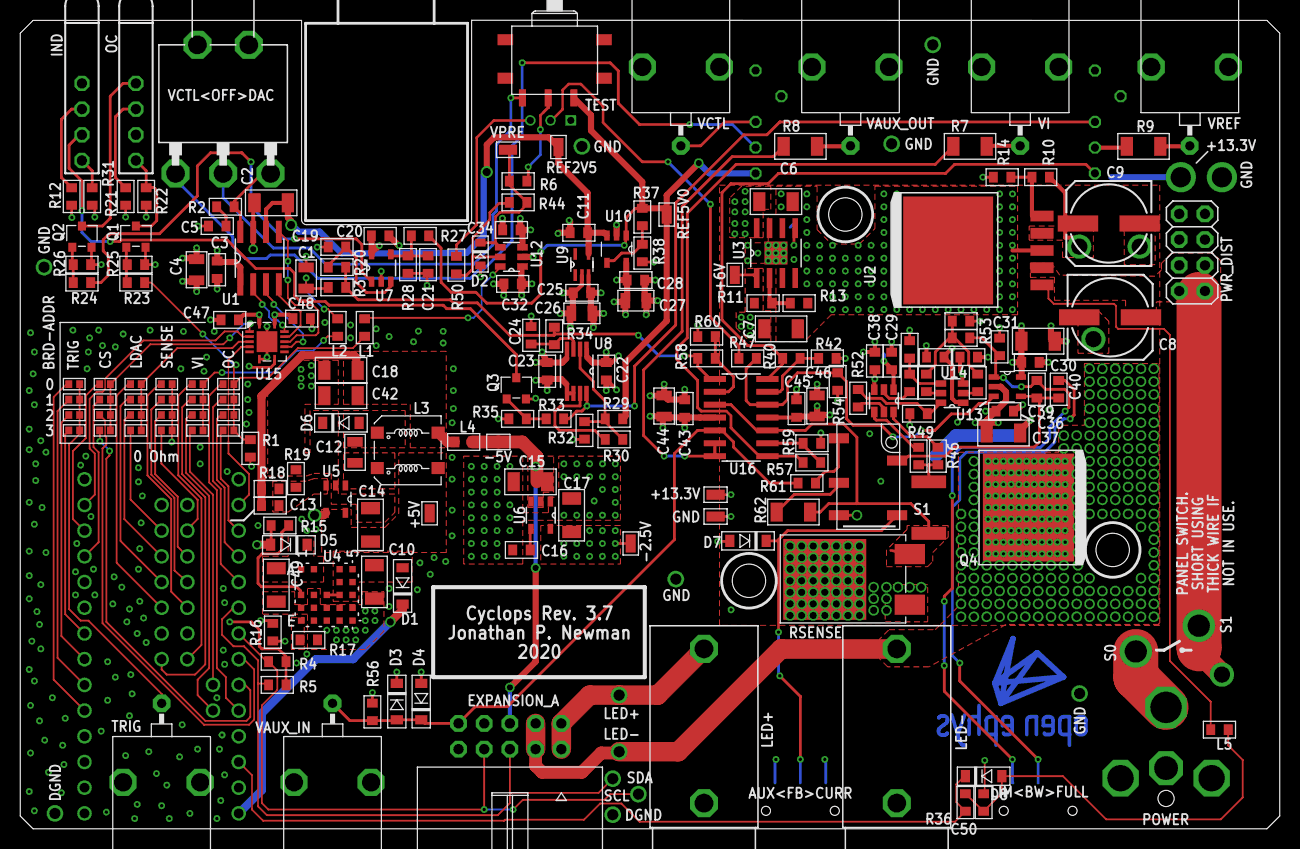
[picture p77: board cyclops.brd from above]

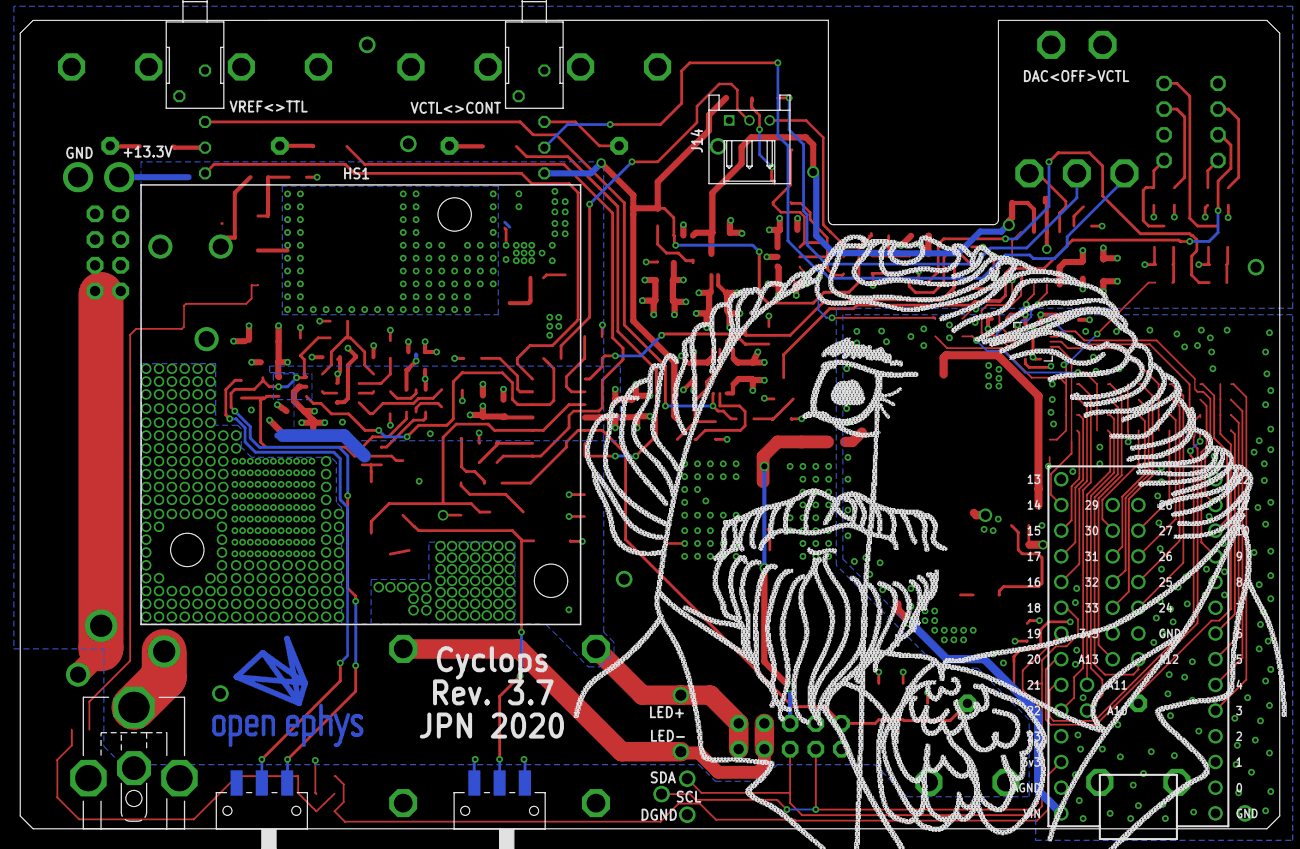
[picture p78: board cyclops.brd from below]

Board: 4 copper layers, 124.5 x 79.9 mm, 203 parts (10 on the bottom side), 120 nets.

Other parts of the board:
U$56: CYCLOPS_LOGO

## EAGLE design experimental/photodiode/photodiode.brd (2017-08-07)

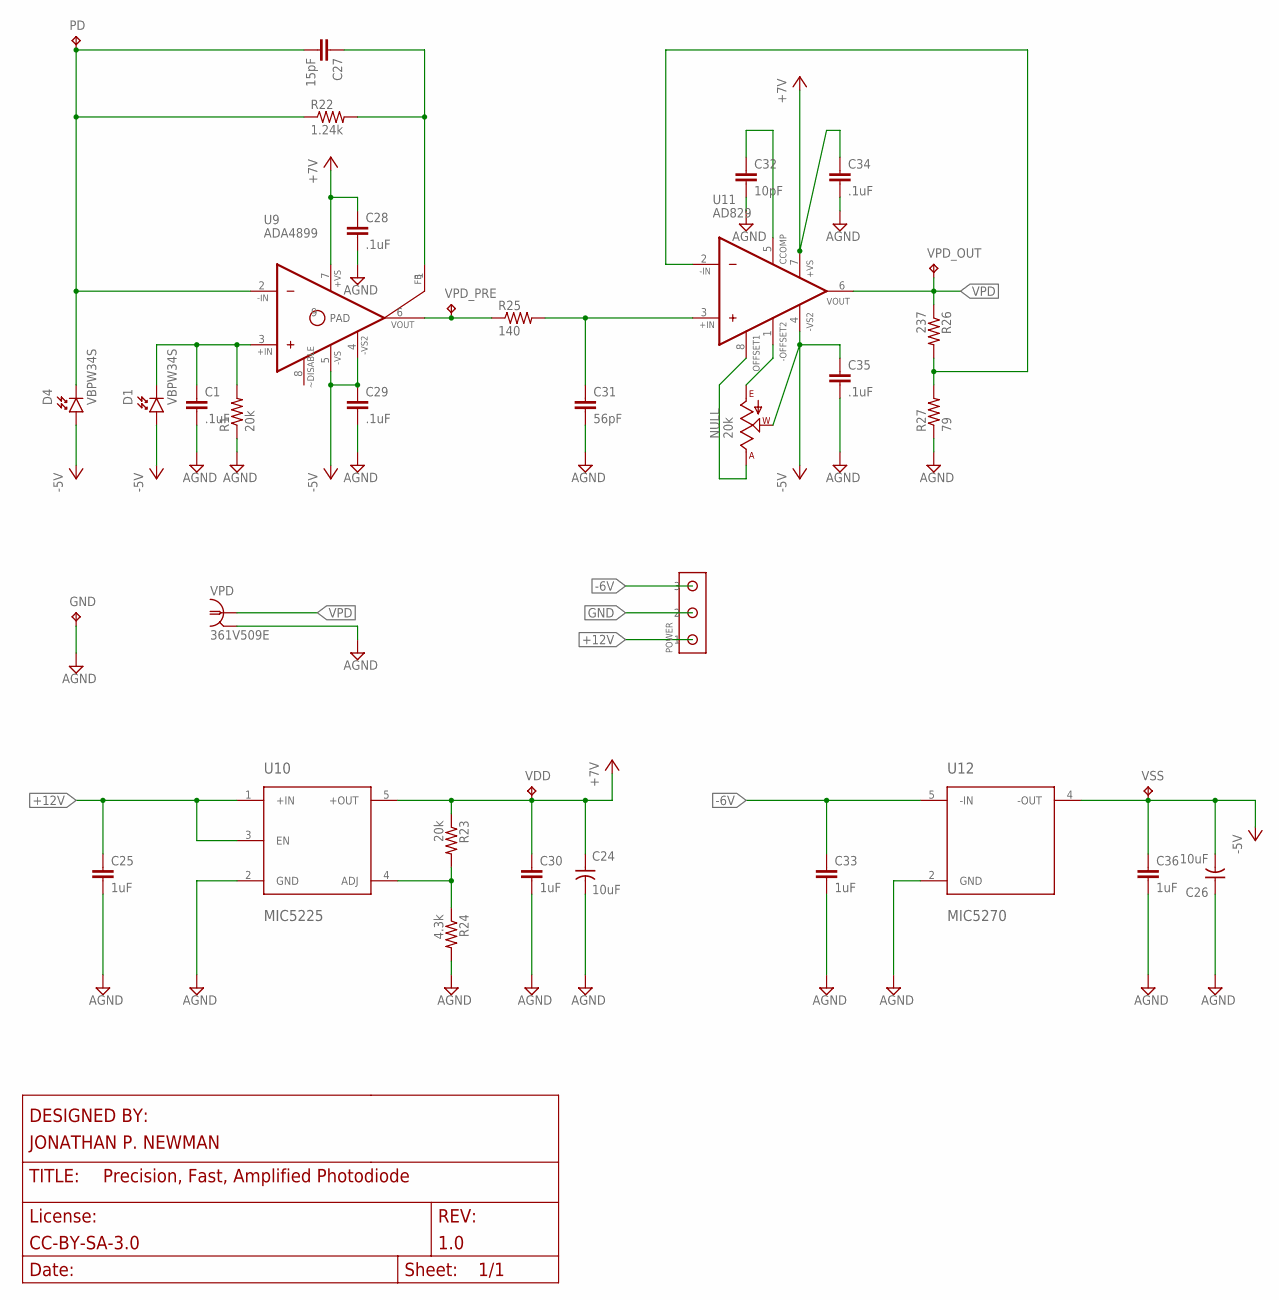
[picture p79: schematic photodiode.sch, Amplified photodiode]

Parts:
C1, C28, C29, C34, C35: .1uF; 0603
C24, C26: 10uF; 6032M-POL
C25, C30, C33, C36: 1uF; 0805
C27: 15pF; 0603
C31: 56pF; 0603
C32: 10pF; 0603
D1, D4: VBPW34S
GND: TPTP08R; TP08R
NULL: 20k; SM-42/43A
PD: TPTP08R; TP08R
POWER: S2B-PH-K-S; SCREW3
R1, R23: 20k; 0603
R22: 1.24k; 0603
R24: 4.3k; 0603
R25: 140; 0603
R26: 237; 0603
R27: 79; 0603
U9: ADA4899; SOIC127P600X175-9N
U10: MIC5225; SOT-23-5
U11: AD829; SOIC127P600X175-8N
U12: MIC5270; SOT-23-5
VDD: TPTP08R; TP08R
VPD: 361V509E
VPD_OUT: TPTP08R; TP08R
VPD_PRE: TPTP08R; TP08R
VSS: TPTP08R; TP08R

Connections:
+7V: C24.+, C28.1, C30.1, C34.1, R23.1, U9.7 (+VS), U10.5 (+OUT), U11.7 (+VS), VDD.TP
+12V: C25.1, POWER.P$1 (1), U10.1 (+IN), U10.3 (EN)
-5V: C26.-, C29.1, C35.1, C36.1, D1.A, D4.A, NULL.2 (W), U9.4 (-VS_2), U9.5 (-VS), U11.4 (-VS), U12.4 (-OUT), VSS.TP
-6V: C33.1, POWER.P$3 (3), U12.5 (-IN)
GND: C1.2, C24.-, C25.2, C26.+, C28.2, C29.2, C30.2, C31.2, C32.2, C33.2, C34.2, C35.2, C36.2, GND.TP, POWER.P$2 (2), R1.1, R24.2, R27.1, U10.2 (GND), U12.2 (GND), VPD.2, VPD.3 (2)
unnamed: C1.1, D1.C, R1.2, U9.3 (+IN)
unnamed: C27.1, R22.2, U9.1 (FEEDBACK)
unnamed: C27.2, D4.C, PD.TP, R22.1, U9.2 (-IN)
unnamed: NULL.3 (E), U11.1 (OFS_2)
unnamed: R25.1, U9.6 (VOUT), VPD_PRE.TP
unnamed: R23.2, R24.1, U10.4 (ADJ)
unnamed: R26.2, R27.2, U11.2 (-IN)
unnamed: NULL.1 (A), U11.8 (OFS)
unnamed: C32.1, U11.5 (CCOMP)
VPD: R26.1, U11.6 (OUTPUT), VPD.1, VPD_OUT.TP
VPD_PRE: C31.1, R25.2, U11.3 (+IN)

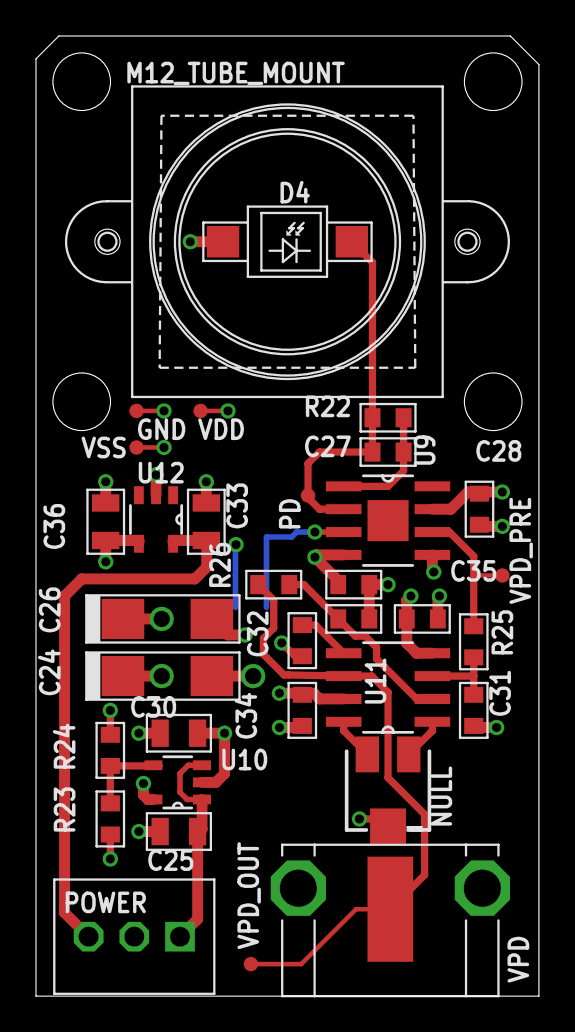
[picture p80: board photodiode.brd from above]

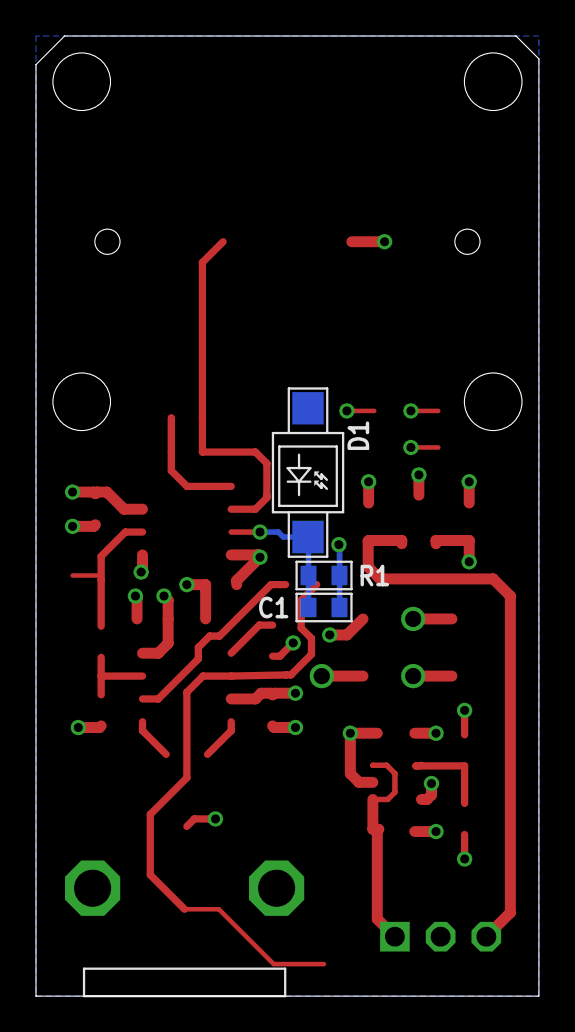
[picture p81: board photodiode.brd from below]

Board: 4 copper layers, 27.9 x 53.3 mm, 37 parts (3 on the bottom side), 16 nets.

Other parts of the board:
M12_TUBE_MOUNT: PT-LH001

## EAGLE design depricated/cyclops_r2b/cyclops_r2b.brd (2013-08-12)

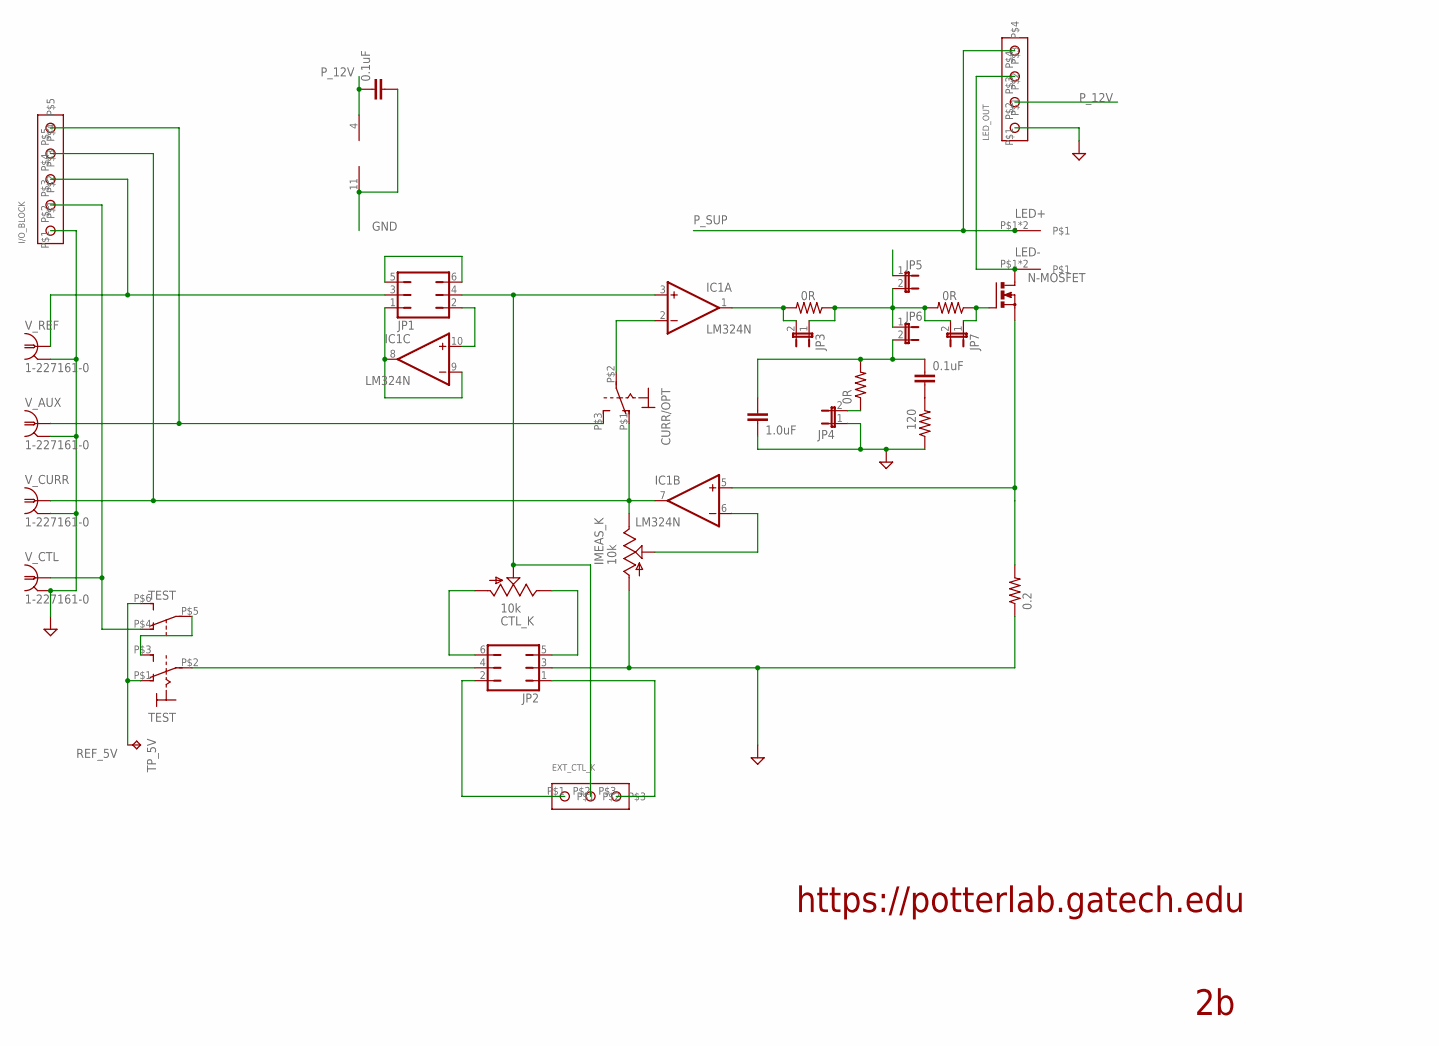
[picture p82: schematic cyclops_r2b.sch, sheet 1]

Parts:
C1, C3: 0.1uF; C050-024X044
C2: 1.0uF; C025-024X044
CTL_K: 10k; RJ6S
CURR/OPT: SPST_SWITCH; A_TOGGLE_SPST
EXT_CTL_K: SCREW3
I/O_BLOCK: SCREW5
IC1: LM324N; DIL14
IMEAS_K: 10k; RJ6S
JP1, JP2: JP3Q
JP3, JP4, JP5, JP6, JP7: JP1E; JP1
LED+: BANANA_TO_BOARD
LED-: BANANA_TO_BOARD
LED_OUT: SCREW4
N-MOSFET: PMOSFET_NTO220BH; TO220BH
R1, R2, R4: 0R; 0207/7
R3: 120; 0207/7
R_CURR: 0.2; IMEAS_R
TEST: SP3T_SWITCH; 320-938
TP_5V: TPPAD1-13; P1-13
V_AUX: 1-227161-0; AMP_227161
V_CTL: 1-227161-0; AMP_227161
V_CURR: 1-227161-0; AMP_227161
V_REF: 1-227161-0; AMP_227161

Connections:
GND: C1.2, C2.2, I/O_BLOCK.P$1, IC1.11 (V-), IMEAS_K.A, JP2.3, JP4.1, LED_OUT.P$1, R3.1, R_CURR.1, V_AUX.2 (GND), V_CTL.2 (GND), V_CURR.2 (GND), V_REF.2 (GND); also elsewhere on the board
unnamed: CURR/OPT.P$2, IC1.2 (-IN)
unnamed: IC1.5 (+IN), N-MOSFET.S, R_CURR.2
unnamed: IC1.1 (OUT), JP3.2, R1.2
unnamed: CURR/OPT.P$1 (O), I/O_BLOCK.P$4, IC1.7 (OUT), IMEAS_K.E, V_CURR.1
unnamed: CURR/OPT.P$3 (S), I/O_BLOCK.P$5, V_AUX.1
unnamed: JP2.4, TEST.P$2
unnamed: CTL_K.E, JP2.5
unnamed: CTL_K.S, EXT_CTL_K.P$2, IC1.3 (+IN), JP1.4
unnamed: IC1.8 (OUT), IC1.9 (-IN), JP1.1
unnamed: I/O_BLOCK.P$2, TEST.P$4 (O), V_CTL.1
unnamed: C2.1, C3.1, JP6.2, R2.2
unnamed: CTL_K.A, JP2.6
unnamed: C3.2, R3.2
unnamed: IC1.10 (+IN), JP1.2
unnamed: IC1.6 (-IN), IMEAS_K.S
unnamed: JP1.5, JP1.6
unnamed: I/O_BLOCK.P$3, JP1.3, V_REF.1
unnamed: LED-.P$1, LED-.P$2, LED_OUT.P$3, N-MOSFET.D
unnamed: TEST.P$3 (S), TEST.P$5
unnamed: EXT_CTL_K.P$1, JP2.2
unnamed: EXT_CTL_K.P$3, JP2.1
unnamed: JP4.2, R2.1
unnamed: JP3.1, JP5.2, JP6.1, JP7.2, R1.1, R4.2
unnamed: JP7.1, N-MOSFET.G, R4.1
P_12V: C1.1, IC1.4 (V+), LED_OUT.P$2; also elsewhere on the board
P_SUP: LED+.P$1, LED+.P$2, LED_OUT.P$4; also elsewhere on the board
REF_5V: TEST.P$1 (O), TEST.P$6 (S), TP_5V.TP; also elsewhere on the board

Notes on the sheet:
https://potterlab.gatech.edu

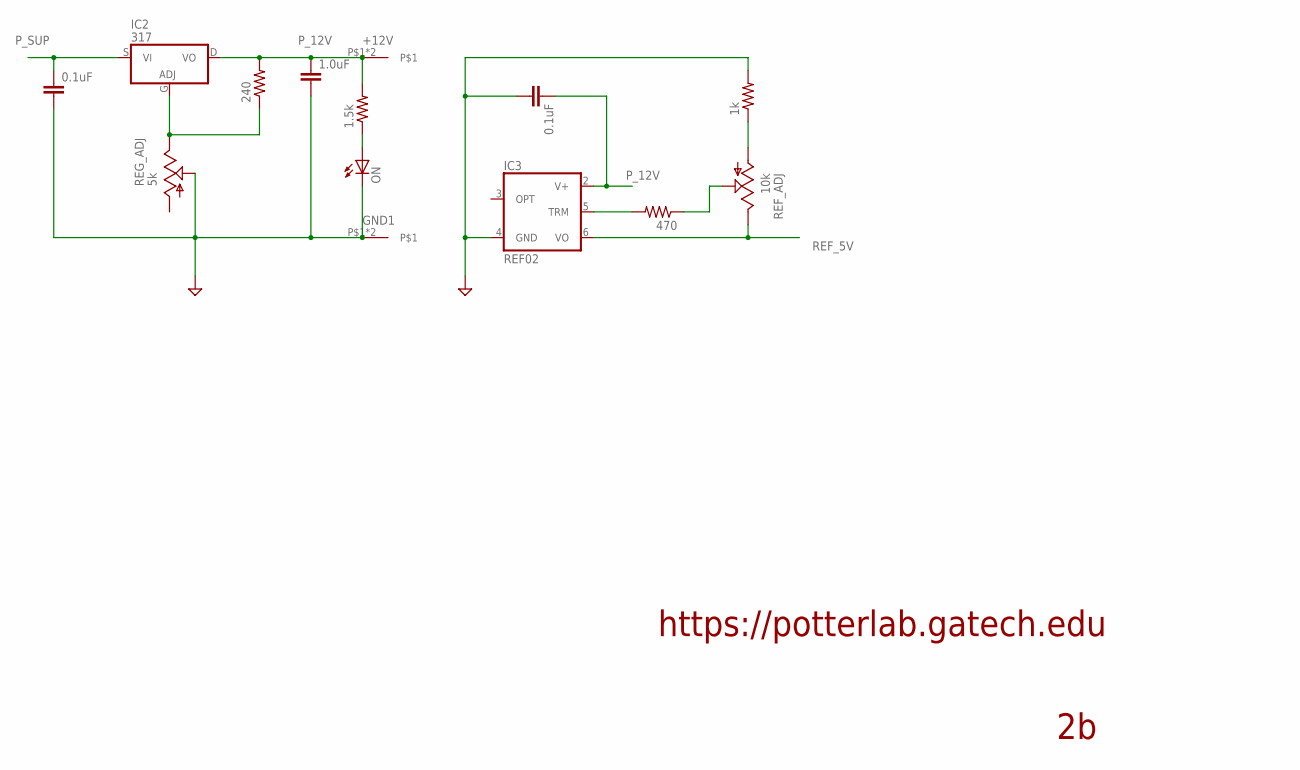
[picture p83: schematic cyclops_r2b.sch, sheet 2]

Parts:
+12V: BANANA_TO_BOARD
C4, C6: 0.1uF; C050-024X044
C5: 1.0uF; C025-024X044
GND1: BANANA_TO_BOARD
IC2: 317; TO220BH
IC3: REF02; DIL08-OVAL
ON: LED3MM
R5: 240; 0207/7
R6: 1.5k; 0207/7
R7: 470; 0207/7
R8: 1k; 0207/7
REF_ADJ: 10k; RJ6S
REG_ADJ: 5k; RJ6S

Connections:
GND: C4.2, C5.2, C6.2, GND1.P$1, GND1.P$2, IC3.4 (GND), ON.K (C), R8.2, REG_ADJ.S; also elsewhere on the board
unnamed: IC2.G (ADJ), R5.1, REG_ADJ.E
unnamed: IC3.5 (TRM), R7.2
unnamed: R7.1, REF_ADJ.S
unnamed: R8.1, REF_ADJ.A
unnamed: ON.A, R6.1
P_12V: +12V.P$1, +12V.P$2, C5.1, C6.1, IC2.D (VO), IC3.2 (V+), R5.2, R6.2; also elsewhere on the board
P_SUP: C4.1, IC2.S (VI); also elsewhere on the board
REF_5V: IC3.6 (VO), REF_ADJ.E; also elsewhere on the board

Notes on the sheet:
https://potterlab.gatech.edu

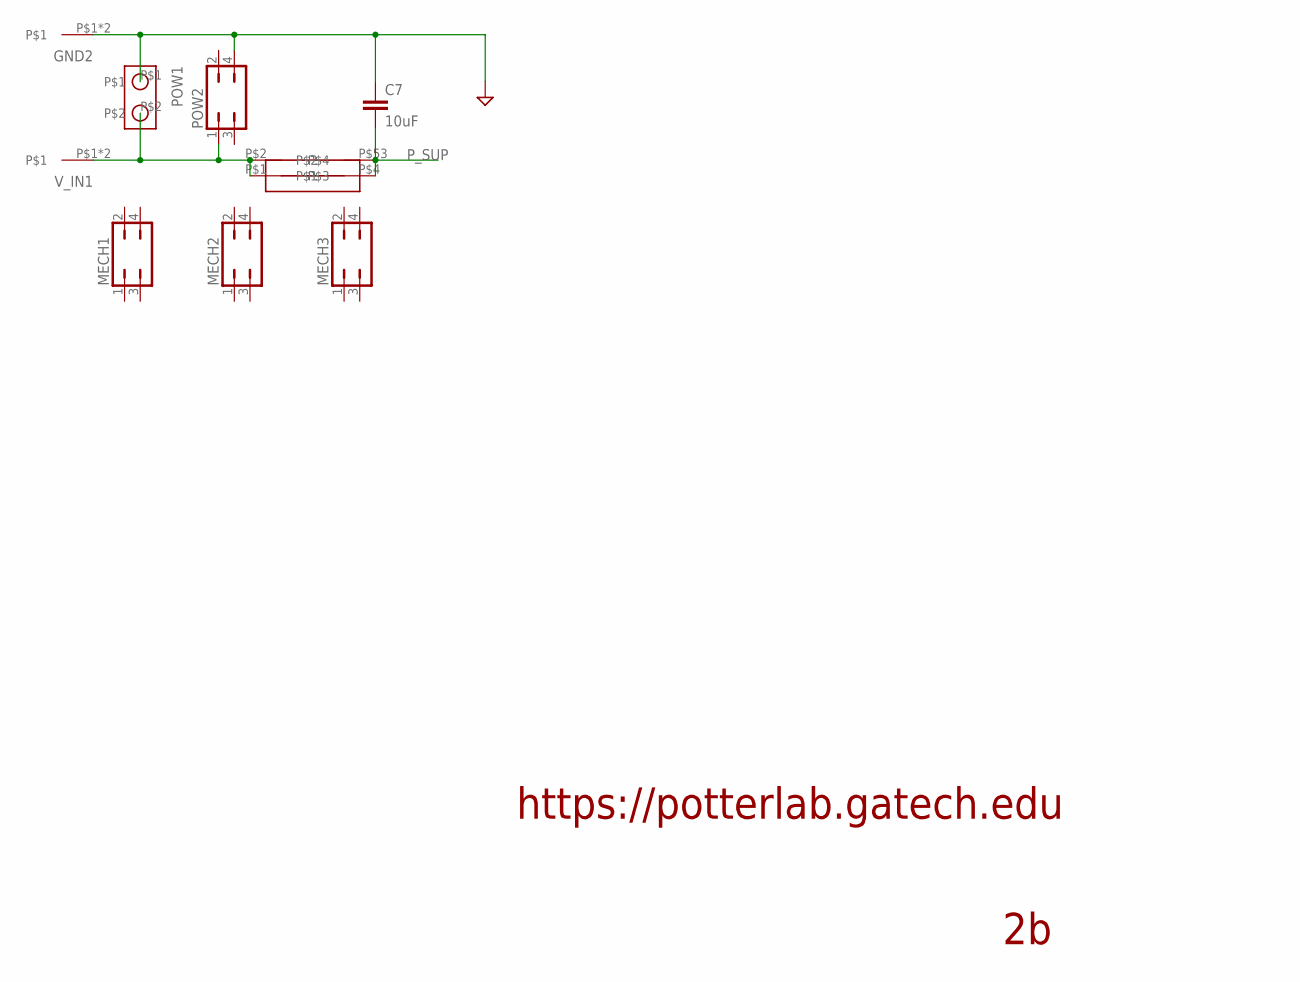
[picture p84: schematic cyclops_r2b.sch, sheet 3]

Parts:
C7: 10uF; C025-024X044
GND2: BANANA_TO_BOARD
MECH1, MECH2, MECH3: JP2Q
POW1: SCREW2
POW2: JP2Q
U$1: FUSE >2A; NXT-FUSE
V_IN1: BANANA_TO_BOARD

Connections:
GND: C7.1, GND2.P$1, GND2.P$2, POW1.P$1, POW2.4; also elsewhere on the board
P_SUP: C7.2, U$1.P$4, U$1.P$53; also elsewhere on the board
P_SUP_BEFORE: POW1.P$2, POW2.1, U$1.P$1, U$1.P$2, V_IN1.P$1, V_IN1.P$2

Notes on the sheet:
https://potterlab.gatech.edu

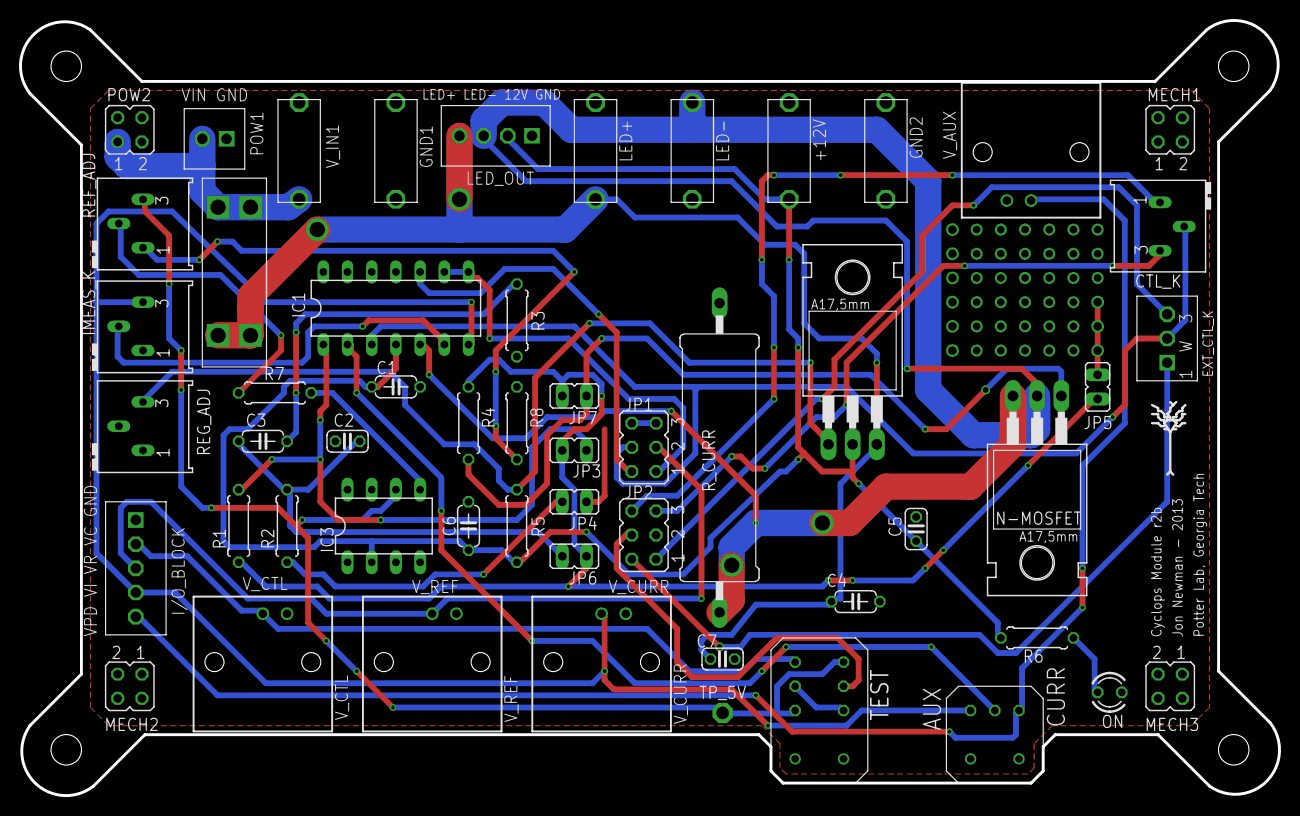
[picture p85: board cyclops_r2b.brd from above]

Board: 2 copper layers, 132.2 x 81.4 mm, 55 parts (1 on the bottom side), 34 nets.

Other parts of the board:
U$2: OSHW_FILLX750_NOTEXT

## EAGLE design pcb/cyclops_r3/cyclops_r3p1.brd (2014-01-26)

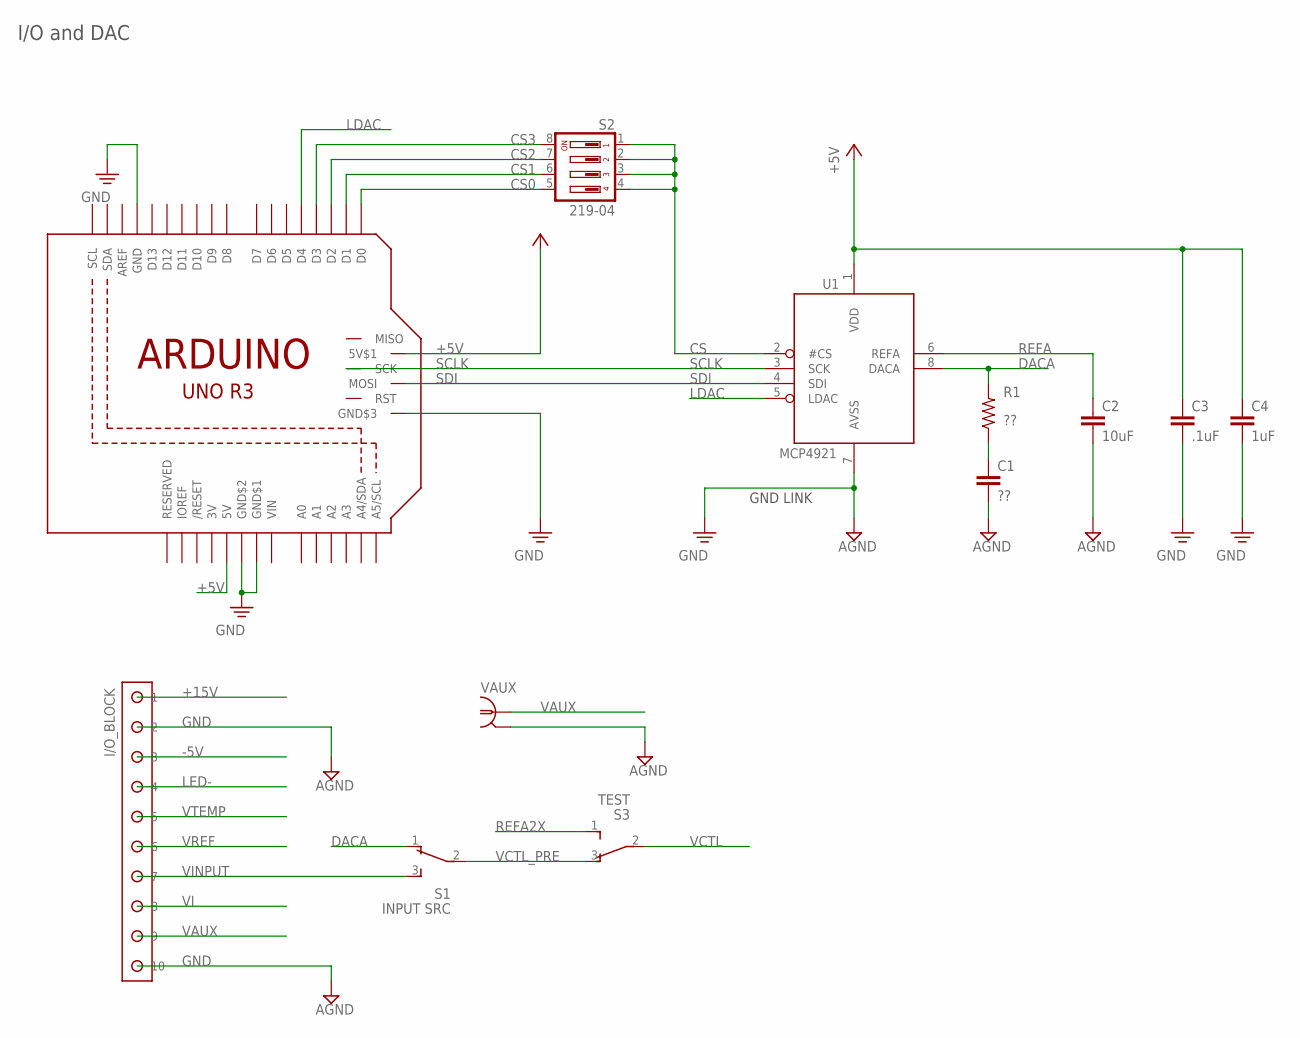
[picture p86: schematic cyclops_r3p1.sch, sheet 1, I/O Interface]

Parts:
C1: ??; 0603
C2: 10uF; 0805
C3: .1uF; 0603
C4: 1uF; 0805
I/O_BLOCK: SCREW10_0.1-THRU; SCREW10
R1: ??; 0603
S1: INPUT SRC; PCM12
S2: 219-04; CTS-219-04
S3: TEST; CFPA
U1: MCP4921; SO08
U$1: ARDUINO_R3_ICSP; ARDUINOR3_ICSP
VAUX: BNC_V-BITE; 361V509E

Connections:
3V: U$1.3V
+5V: C3.1, C4.1, U1.1 (VDD), U$1.5V (5V$1), U$1.+5V (5V)
+15V: I/O_BLOCK.P$1 (1); also elsewhere on the board
-5V: I/O_BLOCK.P$3 (3); also elsewhere on the board
CS: S2.1, S2.2, S2.3, S2.4, U1.2 (#CS)
CS0: S2.5, U$1.D0
CS1: S2.6, U$1.D1
CS2: S2.7, U$1.D2
CS3: S2.8, U$1.D3
DACA: R1.2, S1.1, U1.8 (DACA)
GND: C1.2, C2.2, C3.2, C4.2, I/O_BLOCK.P$2 (2), I/O_BLOCK.P$10 (10), U1.7 (AVSS), U$1.GND, U$1.GND$1, U$1.GND$2, U$1.GND$3, VAUX.2, VAUX.3 (2); also elsewhere on the board
LDAC: U1.5 (LDAC), U$1.D4
LED-: I/O_BLOCK.P$4 (4); also elsewhere on the board
unnamed: C1.1, R1.1
REFA: C2.1, U1.6 (REFA); also elsewhere on the board
REFA2X: S3.1 (3); also elsewhere on the board
SCLK: U1.3 (SCK), U$1.SCK
SDI: U1.4 (SDI), U$1.MOSI
VAUX: I/O_BLOCK.P$9 (9), VAUX.1; also elsewhere on the board
VCTL: S3.2; also elsewhere on the board
VCTL_PRE: S1.2, S3.3 (1)
VI: I/O_BLOCK.P$8 (8); also elsewhere on the board
VIN: U$1.VIN
VINPUT: I/O_BLOCK.P$7 (7), S1.3
VREF: I/O_BLOCK.P$6 (6); also elsewhere on the board
VTEMP: I/O_BLOCK.P$5 (5); also elsewhere on the board

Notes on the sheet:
GND LINK
I/O and DAC

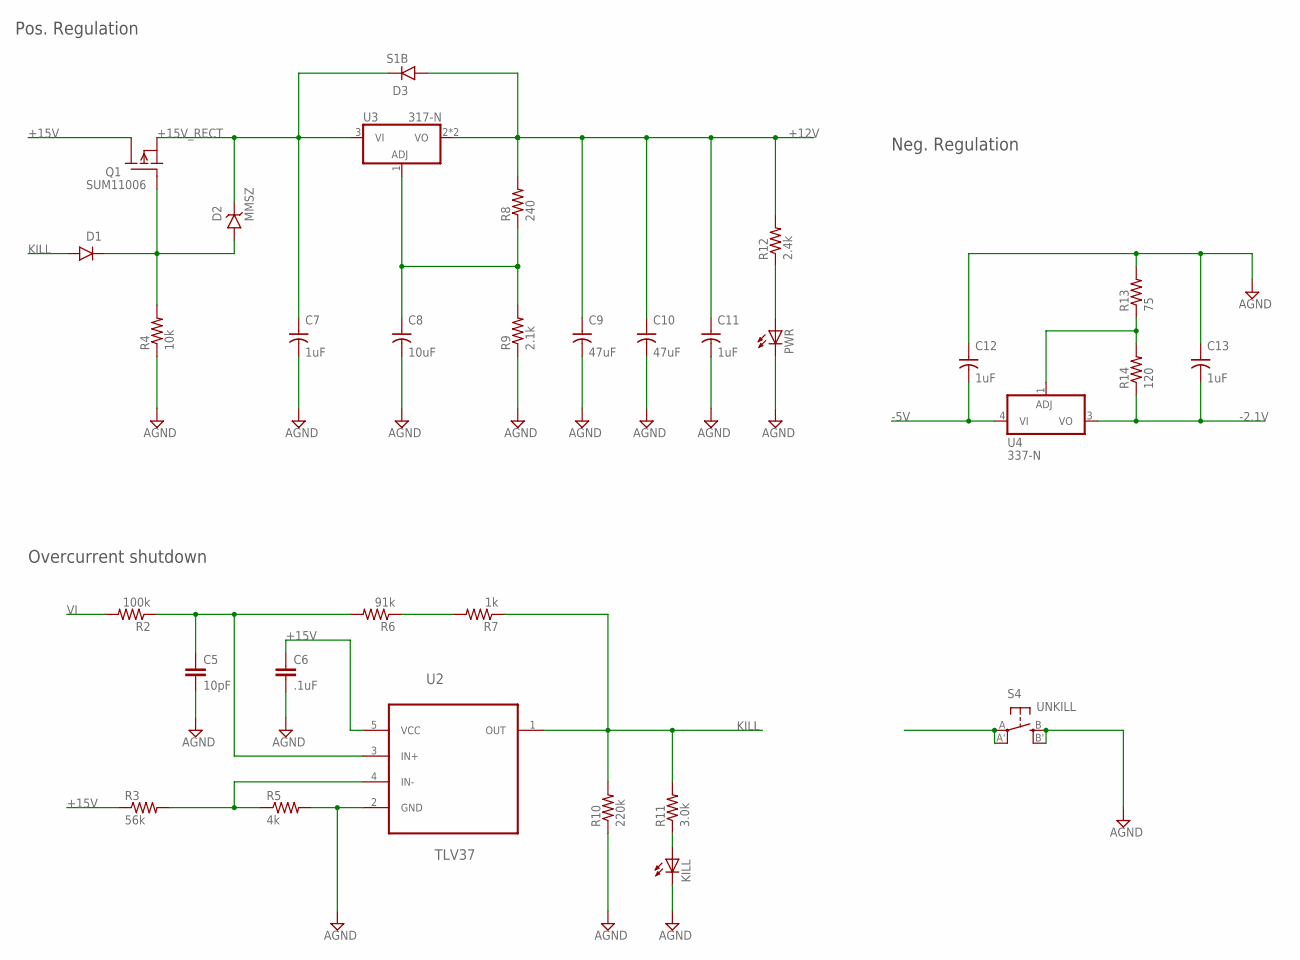
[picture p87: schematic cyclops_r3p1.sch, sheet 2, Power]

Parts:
C5: 10pF; 0603
C6: .1uF; 0603
C7, C11, C12, C13: 1uF; 1206-POL
C8: 10uF; 1206-POL
C9, C10: 47uF; 153CLV-0807
D1: DIODESOD-323; SOD-323F
D2: MMSZ; SOD123
D3: S1B; SMA-DO214AC
KILL: LEDYELLOW_0805; CHIP-LED0805
PWR: LEDYELLOW_0805; CHIP-LED0805
Q1: SUM11006; TO-262_01
R2: 100k; 0603
R3: 56k; 0603
R4: 10k; 0603
R5: 4k; 0603
R6: 91k; 0603
R7: 1k; 0603
R8: 240; 0603
R9: 2.1k; 0603
R10: 220k; 0603
R11: 3.0k; 0603
R12: 2.4k; 0603
R13: 75; 0603
R14: 120; 0603
S4: UNKILL; EVQ-Q2
U2: TLV37; SOT95P280X145-5N
U3: 317-N; TO-263
U4: 337-N; SOT223

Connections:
+12V: C9.+, C10.+, C11.+, D3.A, R8.2, R12.2, U3.2 (VO), U3.4 (VO); also elsewhere on the board
+15V: C6.1, Q1.D, R3.1, U2.5 (VCC); also elsewhere on the board
+15V_RECT: C7.+, D2.C, D3.C, Q1.S, U3.3 (VI)
-2.1V: C13.-, R14.1, U4.3 (VO); also elsewhere on the board
-5V: C12.-, U4.4 (VI); also elsewhere on the board
COMP+: C5.1, R2.1, R6.2, S4.A, S4.A' (P1), U2.3 (IN+)
GND: C5.2, C6.2, C7.-, C8.-, C9.-, C10.-, C11.-, C12.+, C13.+, KILL.C, PWR.C, R4.1, R5.2, R9.1, R10.1, R13.2, S4.B (S), S4.B' (S1), U2.2 (GND); also elsewhere on the board
KILL: D1.A, R7.1, R10.2, R11.2, U2.1 (OUT)
unnamed: PWR.A, R12.1
unnamed: R3.2, R5.1, U2.4 (IN-)
unnamed: R6.1, R7.2
unnamed: KILL.A, R11.1
unnamed: R13.1, R14.2, U4.1 (ADJ)
unnamed: D1.C, D2.A, Q1.G, R4.2
unnamed: C8.+, R8.1, R9.2, U3.1 (ADJ)
VI: R2.2; also elsewhere on the board

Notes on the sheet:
Pos. Regulation
Overcurrent shutdown
Neg. Regulation


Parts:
C14, C15: 1uF; 0805
C16, C17: .1uF; 0603
R15: 470; 0603
R16: 1k; 0603
REF_ADJ: 10k; SM-42/43W
U5: ADR03; SOT65P210X110-5N
U6: OP1177; SOP65P490X110-8N
VREF: TPTP08R; TP08R
VTEMP: TPTP08R; TP08R

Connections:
+12V: C14.1, C15.1, C16.1, C17.1, U5.3 (VIN), U6.7 (V+); also elsewhere on the board
GND: C14.2, C15.2, C16.2, C17.2, R16.1, U5.2 (GND), U6.4 (V-); also elsewhere on the board
unnamed: R16.2, REF_ADJ.3 (E)
unnamed: R15.2, U5.5 (TRIM)
unnamed: R15.1, REF_ADJ.2 (S)
REFA: REF_ADJ.1 (A), U5.4 (VOUT), VREF.TP; also elsewhere on the board
TEMP: U5.1 (TEMP), U6.3 (+IN)
VTEMP: U6.2 (-IN), U6.6 (OUT), VTEMP.TP; also elsewhere on the board

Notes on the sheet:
Reference voltage
Board Temperature


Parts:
BIAS: 10k; SM-42/43W
C18, C19, C21: .1uF; 0603
C20: 1uF; 0805
CTL_K: 1k; SM-42/43A
D4, D5: DS11015; SOD123
Q2: IRF510; TO-262_01
R17, R18, R19, R20, R21, R24: 1k; 0603
R22: 9k; 0603
R23: 10; 0603
RSENSE: 0.1,1W; 2512
S5: CURR/AUX; PCM12
U7: LM324N; SO14
U8: ZXTD45; SOT23-6
VBIAS: TPTP08R; TP08R
VGATE: TPTP08R; TP08R

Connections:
+12V: BIAS.1 (A), C19.1, C20.1, C21.1, D4.C, U7.4 (V+), U8.1 (C1); also elsewhere on the board
-2.1V: C19.2, C20.2, U7.11 (V-); also elsewhere on the board
GND: BIAS.3 (E), C18.2, C21.2, CTL_K.3 (E), D5.A, R18.2, R21.2, R24.1, RSENSE.1, U8.3 (C2); also elsewhere on the board
LED-: Q2.D; also elsewhere on the board
unnamed: Q2.S, RSENSE.2, U7.5 (+IN)
unnamed: BIAS.2 (S), U7.8 (OUT), U8.2 (B1), U8.5 (B2), VBIAS.TP
unnamed: CTL_K.2 (S), R19.1
unnamed: R17.2, U7.2 (-IN)
unnamed: R23.1, U8.4 (E2), U8.6 (E1)
unnamed: Q2.G, R23.2, R24.2, VGATE.TP
unnamed: R22.1, U7.6 (-IN)
REFA: U7.3 (+IN); also elsewhere on the board
REFA2X: C18.1, R20.2; also elsewhere on the board
VAUX: S5.3; also elsewhere on the board
VCTL: CTL_K.1 (A); also elsewhere on the board
VFB: S5.2, U7.9 (-IN)
VI: R21.1, R22.2, S5.1, U7.7 (OUT); also elsewhere on the board
VREF: U7.13 (-IN), U7.14 (OUT); also elsewhere on the board
VREFA2X: R17.1, R18.1, R20.1, U7.1 (OUT)
_VREF: D4.A, D5.C, R19.2, U7.10 (+IN), U7.12 (+IN)



Board: 4 copper layers, 69.8 x 53.3 mm, 78 parts (23 on the bottom side), 50 nets.

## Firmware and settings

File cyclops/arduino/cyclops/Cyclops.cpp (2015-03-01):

/*
Copyright (c) 2014 Jon Newman (jpnewman ~at~ mit <dot> edu) 
All right reserved.

This file is part of the Cyclops Library (CL) for Arduino.

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
You should have received a copy of the GNU General Public License
along with CL.  If not, see <http://www.gnu.org/licenses/>.
*/

#include "Cyclops.h"

// Populate the LUTs
static const uint16_t cs_lut_data[] = {(uint16_t)CS0, (uint16_t)CS1, (uint16_t)CS2, (uint16_t)CS3};
const uint16_t *Cyclops::_cs_lut = cs_lut_data;
static const uint16_t a_in_lut_data[] = {(uint16_t)A0, (uint16_t)A1, (uint16_t)A2, (uint16_t)A3};
const uint16_t *Cyclops::_a_in_lut = a_in_lut_data;
static const uint16_t trig_lut_data[] = {(uint16_t)TRIG0, (uint16_t)TRIG1, (uint16_t)TRIG2, (uint16_t)TRIG3};
const uint16_t *Cyclops::_trig_lut = trig_lut_data;
static const uint16_t trig_port_pos_lut_data[] = {4,5,6,7}; 
const uint16_t *Cyclops::_trig_port_pos_lut = trig_port_pos_lut_data;

Cyclops::Cyclops(uint16_t channel) {

    // Set the global _channel property
    if (channel != CH0 || channel != CH1 || channel != CH2 || channel != CH3) {
        //Inappropriate channel specification.
        //exit(0);
        // Something that does not screw up serial communication
        // indefinately would be nice here.
    }
    _channel = channel;

    // Set pin modes
    pinMode(_cs_lut[_channel], OUTPUT);
    pinMode(_trig_lut[_channel], INPUT);

    pinMode(WIPER_UD, OUTPUT);
    pinMode(LDAC, OUTPUT);
    pinMode(OC_COMP, OUTPUT);

	// Pull the trigger line down
	digitalWrite(_trig_lut[_channel], LOW);

    // Get the CS and load-dac lines ready
    digitalWrite(_cs_lut[_channel], HIGH);
    digitalWrite(LDAC, HIGH);

    // Initialize the OC_COMP pin
    digitalWrite(OC_COMP, LOW);
	
	// Initialize SPI bus
    SPI.setDataMode(SPI_MODE0);
    SPI.setBitOrder(MSBFIRST);
    SPI.begin();

    // Initialize private variables
	_initialized = true;
}

// Public Accessors
uint16_t Cyclops::get_channel( void ) {
    return _channel;
}

uint16_t Cyclops::get_chip_select_pin( void ) {
    return _cs_lut[_channel];
}

uint16_t Cyclops::get_analog_pin( void ) {
    return _a_in_lut[_channel];
}

uint16_t Cyclops::get_trigger_pin( void ) {
    return _trig_lut[_channel];
}

void Cyclops::over_current_protect( float current_limit_mA) {

    // Measure the current
     float current_mA = measure_current();

    // If we are over-current, then adjust in the input voltage divider
    if (current_mA > current_limit_mA) {

        // Signal that we are in compenstation mode
        digitalWrite(OC_COMP, HIGH);

        // Raise the resistance of the top of the voltage divder
        mcp4022_decrement_pot(1);
    }
    // If the input stage is not at nominal resistance, then move toward it
    else if (_wiper_position[_channel] > NOM_WIPER_POS-1) {

        // Signal that we are in compenstation mode
        digitalWrite(OC_COMP, HIGH);
        mcp4022_decrement_pot(1);
    }
    // If the input stage is not at nominal resistance, then move toward it
    else if (_wiper_position[_channel] < NOM_WIPER_POS-1) {

        // Signal that we are in compenstation mode
        digitalWrite(OC_COMP, HIGH);
        mcp4022_increment_pot(1);
    }
    else {
        
        // Signal that we are out of compensation mode
        digitalWrite(OC_COMP, LOW);
    }
}

float Cyclops::measure_current(void) {
    
    int sensor_value = analogRead(_a_in_lut[_channel]);
    return 1000.0 * (float)sensor_value * (5.0 / 1023.0);
}

void Cyclops::mcp4921_send_test_waveform(void) {

    uint16_t v_out = 0;

    while (v_out < 4085) {
        v_out += 10;
        mcp4921_load_voltage(v_out);
        mcp4921_load_dac();
    }
    while (v_out > 10) {
        v_out -= 10;
        mcp4921_load_voltage(v_out);
        mcp4921_load_dac();
    }
}


void Cyclops::mcp4921_generate_waveform( int voltage[], uint16_t length, uint16_t sample_period_us) {

    for (int i = 0; i < length; i++) {
        mcp4921_load_voltage(voltage[i]);
        mcp4921_load_dac();
        delayMicroseconds(sample_period_us);  
    }
}

void Cyclops::mcp4921_load_voltage( uint16_t voltage) {

    // Create data packet
    unsigned int spi_out = DAC_CONF_ACTIVE | (voltage & 0x0fff);

    // take the SS pin low to select the chip
    digitalWrite(_cs_lut[_channel], LOW);

    //  send in the address and value via SPI:
    SPI.transfer(spi_out >> 8 & 0xff);
    SPI.transfer(spi_out >> 0 & 0xff);

    // take the SS pin high to de-select the chip:
    digitalWrite(_cs_lut[_channel], HIGH);

}

void Cyclops::mcp4921_load_dac(void) {

    digitalWrite(LDAC, LOW);
    __asm__("nop\n\t");
    __asm__("nop\n\t");
    digitalWrite(LDAC, HIGH);
}

void Cyclops::mcp4921_shutdown_dac (void) {

	// Create data packet
    unsigned int spi_out = DAC_CONF_SHDN;

    // Take the CS pin low to select the chip
    digitalWrite(_cs_lut[_channel], LOW);

    // Send in the config and data via SPI:
    SPI.transfer(spi_out >> 8 & 0xff);
    SPI.transfer(spi_out >> 0 & 0xff);

    // Take the CS pin high to de-select the chip:
    digitalWrite(_cs_lut[_channel], HIGH);

}

void Cyclops::mcp4022_set_nom_AW_resistance(void) {

	// This trimmer is 50k with 64 positions
	// Decrement the wiper 64 times to 0x00
	// ensures that the wiper is connected
	// to terminal B. Incrementing the wiper
	// 64 times ensures that the wiper is
	// connected to terminal A. 
	mcp4022_decrement_pot(64);

	// 5.6k = 50k * x/64. x ~ 7
	mcp4022_increment_pot(NOM_WIPER_POS);

    //_wiper_position[_channel] = NOM_WIPER_POS;

	// Write to EEPROM
	mcp4022_save_AW_resistance();
}

void Cyclops::mcp4022_unpulse_pot(byte n) {

	// Increcment n times
	for (int i = 0; i < n; i++) {
		digitalWrite(WIPER_UD, LOW);
		digitalWrite(WIPER_UD, HIGH);
	}
}

void Cyclops::mcp4022_pulse_pot(byte n) {

	// Decrement n times
	for (int i = 0; i < n; i++) {
		digitalWrite(WIPER_UD, HIGH);
		digitalWrite(WIPER_UD, LOW);
	}
}

void Cyclops::mcp4022_increment_pot( byte n) {
	
	//Bring WIPER_UD HIGH
	digitalWrite(WIPER_UD, HIGH);

    // Take the CS pin low to select the chip
    digitalWrite(_cs_lut[_channel], LOW);

	// Provide n U/D pulses
	mcp4022_unpulse_pot(n);	

    // Increment the wiper position
    if (_wiper_position[_channel] + n >= 63) {
        _wiper_position[_channel] = 63;
    }
    else {
        _wiper_position[_channel] += n;
    }

    // Take the CS pin high to deselect the chip
    digitalWrite(_cs_lut[_channel], HIGH);
}

void Cyclops::mcp4022_decrement_pot( byte n) {
	
	// Bring WIPER_UD LOW
	digitalWrite(WIPER_UD, LOW);

    // Take the CS pin low to select the chip
    digitalWrite(_cs_lut[_channel], LOW);

	// Provide n U/D pulses
	mcp4022_pulse_pot(n);	

    // Decrment the wiper position
    if (_wiper_position[_channel] - n <= 0) {
        _wiper_position[_channel] = 0;
    }
    else {
        _wiper_position[_channel] -= n;
    }

    // Take the CS pin high to deselect the chip
    digitalWrite(_cs_lut[_channel], HIGH);
}
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

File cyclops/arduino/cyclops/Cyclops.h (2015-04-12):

/*
Copyright (c) 2014 Jon Newman (jpnewman ~at~ mit <dot> edu) 
All right reserved.

This file is part of the Cyclops Library (CL) for Arduino.

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
You should have received a copy of the GNU General Public License
along with CL.  If not, see <http://www.gnu.org/licenses/>.
*/

#ifndef Cyclops_h
#define Cyclops_h

#if ARDUINO >= 100
 #include <Arduino.h>
#else
 #include <WProgram.h>
#endif
#include <SPI.h>
#include <Wire.h>

// Each 'channel' defines a board address.
// Corresponding pins numbers can be accessed through
// the look-up tables (_a_in_lut, _cs_lut, _trig_lut).
#define CH0 				0       	// Channels
#define CH1 				1       	//
#define CH2 				2       	//
#define CH3 				3       	//

// Pin Definitions
#define CS0 				3       	// Chip select pins
#define CS1 				4       	//
#define CS2 				5       	//
#define CS3 				6       	// 
#define TRIG0 				8     		// Trigger lines
#define TRIG1				9     		//
#define TRIG2 				10    		//
#define TRIG3 				11    		//
#define A0                  0           // Analog input lines
#define A1                  1           //
#define A2                  2           //
#define A3                  3           // 
#define WIPER_UD 			12 			// MCP4022 digital pot up/down pin
#define LDAC  				7      		// MCP4921 load DAC line (sync all channels)
#define OC_COMP  			2   		// Over-current compensation line

//MCP4921 commands
#define DAC_CONF_ACTIVE 	(0x1000)
#define DAC_CONF_SHDN 		(0x1000)

//MCP4022 
#define NOM_WIPER_POS       53          // This is the number of B --> A steps to get ~2.2k
                                        // between the W-A connection on the MCP4022

//Function macros for setting bits in registers
#define cbi(sfr,bit) (_SFR_BYTE(sfr) &= ~_BV(bit))
#define sbi(sfr,bit) (_SFR_BYTE(sfr) |= _BV(bit))

// Interupt handling stuff
typedef void (*voidFuncPtr)(void);
volatile static voidFuncPtr interupt_func[8] // One function pointer for each bit on PORTB
	= { NULL };
volatile static uint8_t interupt_last;		 // Last port state
static void isr( void ); 					 // Global interupt service routine	

class Cyclops {

  public:

    Cyclops( uint16_t channel );

    // Object properties
    uint16_t get_channel( void );
    uint16_t get_chip_select_pin( void );
    uint16_t get_trigger_pin( void );
    uint16_t get_analog_pin( void );

    // Onboard signal generation
	void mcp4921_send_test_waveform( void );
    void mcp4921_load_voltage( uint16_t voltage );
    void mcp4921_load_dac(void );
    void mcp4921_generate_waveform( int voltage[], uint16_t length, uint16_t sample_period_us );
	void mcp4921_shutdown_dac( void );
    
    // Current measurement and OC protection
    float measure_current( void );
    void over_current_protect( float current_limit_mA );
	
	// Attach/detach interupt
	void attach_interupt( void (*user_func)(void) );
	
    // Set/save input divider resistance
    void mcp4022_set_nom_AW_resistance( void );
    void mcp4022_decrement_pot( byte n );
    void mcp4022_increment_pot( byte n ); 
    void mcp4022_save_AW_resistance( void );
   
  private:
    
    // Low-level digital pot functions        
    void mcp4022_pulse_pot( byte n );
    void mcp4022_unpulse_pot( byte n );

	// Private properties
    uint16_t _channel;
	boolean _initialized;
    byte _wiper_position[4];

    // Channel --> physical pin LUTs
    static const uint16_t *_a_in_lut;
    static const uint16_t *_cs_lut;
    static const uint16_t *_trig_lut;
	static const uint16_t *_trig_port_pos_lut;

};

#endif

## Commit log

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2013-05-02 Fixed r2b in terms of extra traces, ground plane islands, and added extra tuning resistor that was available in r0, but was removed in r2.
    [cyclops_r2b.brd, cyclops_r2b.sch]
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2013-05-20 Fixed several problems with r2b.
    [cyclops_r2b.brd, cyclops_r2b.sch]
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2013-12-16 Added reverse polarity protection to power input.
    [cyclops_r3.brd, cyclops_r3.sch]
2013-12-17 Some additions/changes to the schematic. All the power comonents should occupy the bottom of the board. The Heat sink will be on top. Ample via connected the two sides. Mica insert will be needed to 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
    [cyclops_r3.brd, cyclops_r3.sch]
2013-12-21 Added phase-reversal protection circuit to user supplied input pin (which used to go right to the noninverting pin of the LM324.
    [cyclops_r3.brd, cyclops_r3.sch]
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2013-12-25 Almost finished. Still trying to understand the best N-Channel MOSFET for sinking LED current.
    [cyclops_r3.brd, cyclops_r3.sch]
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2013-12-30 Some fixes and updates to BOM.
    [cyclops_r3.brd, cyclops_r3.sch]
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2013-12-31 Alternative driver circuit that uses a NPN/PNP totem pole to drive a standard FET.
    [cyclops_r3_silk.brd, cyclops_r3p1.brd, cyclops_r3p1.sch]
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2014-01-02 Inserted a gate bias network to prevent oscillations when starting from 0 drain current.
    [cyclops_r3p1.brd, cyclops_r3p1.sch]
2014-01-02 Some updates to the library and board. Also, update the design rules so that vias are not exposed solder.
    [cyclops_r3p1.brd, cyclops_r3p1.sch]
2014-01-02 Reimplemented NMOS bias network after merge issues.
    [cyclops_r3p1.brd, cyclops_r3p1.sch]
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2014-01-04 The board is pretty much finished. I need to verify a few components and add a bottom silkscreen with detailed board info before fabrication, though. Also, there are some ERC issues that are not real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
    [cyclops_r3_label.brd, cyclops_r3_top-tag.brd, cyclops_r3p1.brd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]
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2014-01-14 Added a low profile BNC connection for getting input from an amplified photodiode.
    [cyclops_r3p1.brd, cyclops_r3p1.sch]
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2014-01-15 Put the circuit on the breadboard today and found several mistakes/improvments to the design. I implemented some of those here and documented what else needs to be done in the notes.
    [cyclops_r3p1.brd, cyclops_r3p1.sch]
2014-01-16 Added some test points to the the circuit and a design note.
    [cyclops_r3p1.brd, cyclops_r3p1.sch]
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2014-01-17 Substantial changes to the layout of the analog frontend of the circuit.
    [cyclops_r3p1.brd, cyclops_r3p1.sch]
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2014-01-19 Added an overcurrent kill circuit. This needs to be tested. Also, a reset switch needs to be added.
    [cyclops_r3p1.brd, cyclops_r3p1.sch]
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2014-01-26 Added a negative rail, used exclusively by the opamp, to allow a wider bandwidth. Finished routing everything. Need to make bottom silkscreen and finish testing comparitor circuit.
    [cyclops_r3p1.brd, cyclops_r3p1.dxf, cyclops_r3p1.sch]
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2014-01-26 Added back silkscreen to board. Modified the CAM processor so that the SOL silkscreen includes this bitmap.
    [cyclops_r3.brd, cyclops_r3.sch]
2014-01-28 Minor fixes.
    [cyclops_r3.brd]
2014-01-28 Started doing the CAM work. Added a CAM job for the solder stencil.
    [cyclops_r3.GBL, cyclops_r3.GBO, cyclops_r3.GBS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]
2014-02-01 While breadboarding the overcurrent protection circuit, I found a problem with the PFET power switch. Documented in notes, but not fixed yet.
    [cyclops_r3.brd, cyclops_r3.sch]
2014-02-02 Fixing the overcurrent protection circuit.
    [cyclops_r3.brd, cyclops_r3.sch]
2014-02-02 Almost finished with the layout. I need to fix the top silskcreen which provides pin information.
    [cyclops_r3.brd, cyclops_r3.sch]
2014-02-02 Almost done fixing the top/bottom side I/O labels. Also, found a big mistake in the 10-pin screw terminal header: I replaced the +LED supply with the -5V supply rail. I had to shift all the pins to g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
    [cyclops_r3.brd, cyclops_r3.sch]
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2014-02-07 Minor fix to pcb.
    [cyclops_r3.brd]
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2014-02-10 Fixed the pads of the RSense resistor.
    [cyclops_r3.brd, cyclops_r3.sch]
2014-02-11 Fixes to the BOM.
    [cyclops_r3.brd, cyclops_r3.csv, cyclops_r3.sch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]
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2014-04-01 Added more components for the photodiode circuit. Needs voltage regulators to get the voltage supplied from the cyclops down to proper rails. See notes.
    [cyclops_r3.brd, cyclops_r3.sch]
2014-04-02 The PD daughter circuit is pretty much done. Need to add new parts to the BOM.
    [cyclops_r3.brd, cyclops_r3.sch]
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2014-04-02 Fixed a couple of circuit issues.
    [cyclops_r3.brd, cyclops_r3.sch]
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2014-04-16 Added a compensation cap and offset null pot to the PD circuit.
    [cyclops_r3.brd, cyclops_r3.sch]
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2014-04-17 Added PD design files. Updated BOM to account for PD daughter board.
    [BOM.csv, frequency-response.csv, noise-gain.csv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]
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2014-05-01 Started fixing and documenting problems form the first r3.0 build.
    [cyclops_r3.brd]
2014-05-03 Fixed some wiring problems, added some notes.
    [cyclops_r3.brd, cyclops_r3.sch]
2014-05-04 More revisions due to circuit assembly and UI considerations. More design notes.
    [cyclops_r3.brd, cyclops_r3.sch]
2014-05-09 Making fixes based on previous assembly.
    [cyclops_r3.brd, cyclops_r3.sch]
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2014-05-12 Finished basic layout. Need to go through notes and check things off. Need to perform ERC and DRC. Need to finish silkscreen.
    [cyclops_r3.brd, cyclops_r3.sch]
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2014-05-17 Decided the BNC to the PD board is nessesary. Added. Need a 50 ohm coax (video) amp at as the last stage of the PD amp output to drive this line.
    [cyclops_r3.brd, cyclops_r3.sch]
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2014-05-24 Fixed schematic and board errors.
    [cyclops_r3.brd, cyclops_r3.sch]
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2014-08-04 Started r3.3 to fix some issues with the enclosure etc.
    [cyclops_r3.brd, cyclops_r3.sch]
2014-08-08 Modified the board to incorporate most of the improvements frr3.3. Need to test optical feedback.
    [cyclops_r3.brd, cyclops_r3.sch]
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2014-08-12 Finished up BOM for revision 3.3. Also fixed up spice simulation.
    [cyclops_r3.brd, cyclops_r3.sch]
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2014-08-20 Added some components for the photodiode. Fixed up power supply rails for driver.
    [cyclops_r3.brd, cyclops_r3.sch, photodiode_r1.brd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]
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2014-08-23 Added i2c line to the LED bus so that LEDs can come with eeprom.
    [cyclops_r3.brd, cyclops_r3.sch]
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2014-09-04 Fixed minor issue with bottom layer solder mask.
    [cyclops_r3.brd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]
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2014-10-03 The hole size for the solder lugs on the DAC/VCTL switch were too small. This has been fixed.
    [cyclops_r3.brd, cyclops_r3.sch]
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2014-10-04 Asthetic fixes to board. Driver has limited functionality and is pretty inefficient, but the base stuff is there.
    [cyclops_r3.brd, cyclops_r3.sch]
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2014-10-07 More fixes to library.
    [Cyclops.cpp, Cyclops.h]
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2014-10-10 Front panel dimensions have been tested and look good. Started integrating light pipes on front panel LEDs. The LEDs need to be moved and swapped for normal verical ones.
    [cyclops_r3.brd, cyclops_r3.sch]
2014-10-14 Fixed most of the TODO issues. Need to rearrange front panel layout a bit to acomidate light pipes.
    [cyclops_r3.brd, cyclops_r3.sch]
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2014-10-22 Some minor fixes.
    [cyclops_r3.brd, cyclops_r3.sch]
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2014-12-19 Updates to TODO. Fixed MAX4564 package type.
    [cyclops_r3.brd, cyclops_r3.sch]
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2014-12-21 Layout of rev. 3.5. It needs to be double checked before fabrication.
    [cyclops_r3.brd, cyclops_r3.sch]
2014-12-21 Fixed power switch arrangment.
    [cyclops_r3.brd, cyclops_r3.sch]
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2014-12-22 Updated panels for revision 3.5. Updated BOM for revision 3.5. Did inventory check to see what nees to be ordered.
    [cyclops_r3-5.csv, cyclops_r3-5.xlsx, cyclops_r3.brd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]
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2014-12-22 Fixed several issues noticed during gerber rendering.
    [cyclops_r3.GBL, cyclops_r3.GBO, cyclops_r3.GBS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]
2014-12-23 Almost ready to fabricate PCB. I need to do one last look over, concentrating on schematic.
    [cyclops_r3-5.xlsx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]
2014-12-26 Built the LT1963 circuit next to the LM317, I will now replace the LM317.
    [cyclops_r3.brd, cyclops_r3.sch]
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2014-12-27 Minor layout fixes.
    [cyclops_r3.brd]
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2015-01-17 Added some TODO notes and small changes to board during the 3.5 assembly process.
    [cyclops_r3.brd, cyclops_r3.sch]
2015-01-19 More TODOs and small fixes to circuit.
    [cyclops_r3.brd, cyclops_r3.sch]
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2015-02-09 Finished going through the TODO list by updating BOM for rev 3.5a.
    [cyclops_r3.brd, cyclops_r3.sch]
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2015-02-16 Updated gerbers to account for silkscreen fixes.
    [cyclops_r3.GBL, cyclops_r3.GBS, cyclops_r3.GTL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]
2015-02-25 Fixed the front panel design. This is revision 3.5A.
    [cyclops_r3.brd]
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2015-03-01 Added a cli call to the isr attached to trigger inputs. Prevents interupt call during isr execution.
    [Cyclops.cpp]
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2015-04-30 Replaced LT1963 with LT1764 to increase current capabilites.
    [cyclops_r3.brd, cyclops_r3.sch]
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2015-07-08 Fixed reference voltage issues.
    [cyclops_r3.brd, cyclops_r3.sch]
2015-07-30 Started cleaning repo
    - Added jonnew-lbr submodule
    - All parts, cam, and dru routines should moved to reference jonnew-lbr
    instead of fragmented libs in this repo
    - Photodiode moved to experimental folder
    [BOM.csv, frequency-response.csv, noise-gain.csv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]
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2015-09-08 Moved thermal vias away from DPAK solder pads because solder was leaking through.
    [cyclops_r3.brd]
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2015-10-30 A few changes made to comply with CircuitHub stuff
    - Almost ready to do a circuit hub run.
    [cyclops_r3.brd, cyclops_r3.sch]
2015-12-01 Reworked overcurrent circuit.
    [cyclops_r3.brd, cyclops_r3.sch]
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2015-12-02 Minor fix to the input circuit.
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2015-12-15 Replaced edge mount BNC with cheaper alternative
    - Less than half the price
    - Much more available (made by molex)
    - Huge BOM money saver
    - Worried about production run with this many changes...
    [cyclops_r3.brd, cyclops_r3.sch]
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2016-01-06 Fixed mask/heatsink alignment.
    [cyclops_r3.brd]
2016-01-28 Fixed missing solder mask on power switch connection.
    [cyclops_r3.brd]
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2016-01-28 Fix more minor silkscreen and mask issues.
    [cyclops_r3.brd]
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2016-02-21 Lots of cleanup for 3.5D tag.
    - Got rid of versioning info in file names
    - Got rid of old BOM managment method since we can just point to
    circuithub instead
    [cyclops.brd, cyclops.sch]
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2016-04-04 Update MANUAL.*
    - Fixes #3
    - Partially merged the kit assembly instructions with the main manual
    - Added a bunch of TODOs that generally concern interfacing the cyclops
    with external devices and LEDs, installing the Arudino, programming
    the Arrduino etc.
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2016-05-05 Added teensy related docs, datasheets. Refactored Task
    Stylistic corrections to Task like camelCase-ing and better variable names.
    Made the static `Task::taskCount` private, now its called Task::_taskCount.
2016-05-29 Added Task Queue and updated Source interface
    * Restructured Task a bit.
    * Added Queue (fixed size)
    * `Source::nextVoltage()` renamed -> `Source::getVoltage()`
    - A better name, since this function computes/retrieves voltage _at_ `Source::cur_ind`.
    * **!** Did not test Queue, will add example later.
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2016-05-30 Bumped `Source::holdTime` to double.
    * Made `Cyclops::channel` public
    * Fixed broken examples.
    [Cyclops.cpp, Cyclops.h]
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2016-06-01 Removed volatile and fixed main_loop!!
    * The ISR and waveformList::process both change contents of waveformList. To avoid disaster, the CPU should not be interrupted for critical sections of process().
    The critical sections are wrapped inside a Timer1 Overflow Interrupt disable/enable.
    * waveformList need not be volatile since r/w access to it is serialised by the software.
    * Fixed main_loop.ino, a trivial bug whose compiler message led me far astray...
    [Cyclops.h]
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2016-06-07 Added documentation and examples
    * nbSPI is not effective for Arduino devices, see docs/nbSPI
    * nbSPI tested [pass] and documented.
    * Added logo to docs :)
    * Fixed subtle bug in Waveform::outFrame_id, it should be initialised to DAC_BLOCK_SIZE.
2016-06-08 Fixed bugs in Waveform, WaveformList, added docs.
    * Added another test sketch, `pseudo_loop.ino`
    * Waveform::outFrame_id` must be initialised with 2.
    * Fixed semantic bugs in ISR and `WaveformList::initialPrep()`
    * Changed condition for selection of Waveform "for next latch interrupt".
2016-06-08 Fixed WaveformList (atleast for single channel)
    Now I can confidently start testing and porting on teensy
2016-06-10 Start porting to teensy
    * Commented Cyclops::attachInterrupt and isr() as it has references to PCINT
    * Better #ifdef in nbSPI
    * ONE_SHOT Source will FREEZE upon completion. Must be explicityly reset()
    * Cross-platform Timer1 INT enable/disable in Waveform.cpp
    Off Topic
    * Moved /src/teensy/* in /cyclops/
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2016-06-15 Fixed Timer issues, made library.
    Also,
    * Waveform_t is complete. Can handle upto 4 channels
    * TimerOne fixed for our use.
    * Added example wave2_teensy. Uses latest libs
2016-06-16 SPI work complete. Restructuring Cyclops
    * Cyclops lib can be used with both arduino and teensy.
    * Teensy will use SPI_fifo.
    * Arduino libs are broken
2016-06-17 Started Arduino --> Teensy circuit transformation
    - Schematic fairly finalized
    - PCB not finished. Lots of movement in panel components so this will
    require a panel redesign as well.
    [cyclops.brd, cyclops.sch]
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2016-06-18 RPC draft implementation, see /src/teensy/rpc_loop
    * Serial comms are non-blocking
    * Fixed typos in RPC_defs.h (still buggy)
    * Added logic to task, Queue
    * Changed holdTime return type (once again) to uint32_t
    * Changed constructor calls to accomodate for N_SHOT, see wave2_teensy.ino
2016-06-22 Restructuring into lib/arduino and lib/teensy
    * Arduino libs are broken. Teensy is golden :)
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2016-07-04 Added some notes for the PBB refactor
    - Also, added the triggered waveform example to the srce/teensy folder
    [cyclops.brd, cyclops.sch]
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2016-07-07 Lots of circuit improvments
    - Cleaned up/flattened spice folder
    - Created a nice high-side current sense circuit in spice that I will
    need to prototype before integrated with cyclops drivetrain
    - Physically tested and spice modeled LED active "TTL" signal that will
    can be switched to the VREF output
    [cyclops.brd, cyclops.sch]
2016-07-08 Lots of minor circuit mods
    - Replace OC SPDT with a SPST with better bandwidth and larger voltage
    rail capabilities since id does not need the other terminal
    - Spice modeling of input circuitry
    - Etc
    [cyclops.brd, cyclops.sch]
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2016-07-14 Fixes issue with both rising and falling edge triggering ISR
    - Reported on the OE google group
    - The triggerable function was being called on both rising and falling
    edges of trig input. This fixes that but strickly limits the
    attach_interupt function to single cyclops boards. This is a
    limitation of the Arduino Leonardo.
    [Cyclops.cpp, Cyclops.h]
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2016-07-16 Very close to finished with Rev. 3.6-beta PCB
    - A couple lingering TODOs as stated on the first page of the schematic.
    Mostly mechnical/overlap issues at this point
    [cyclops.brd, cyclops.sch]
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2016-07-29 Fixed heatsink overlap issue and removed teensy AREF
    - Moved to 1.7in x 1.7in heatsink because the AREF/TTL switch had a
    through hole contact that would have overlapped with the 1.8in
    version.
    - Teensy AREF pin was in the way of the TRIG BNC and not needed, so I
    removed it. BOM has yet to be updated (3 pin header --> 2 pin).
    [cyclops.brd, cyclops.sch]
2016-07-30 Added Board identification and more RPC for GUI
    * Board identification LUT added.
    * gitignore -> ignore .pyc
    * Added REGISTER_SOURCE_LIST macro.
    * The GUI example has a separate "MySources.h"
    * Added Waveform::groundAll(), to turn off LEDs when experiment is stopped.
    * Added Source::resetAll() to reset all (registered) Sources when experiment is stopped, in preparation of re-launch.
    * Added docs in RPC-defs.h
    * A global variable (defined in Cyclops.h) cyclops::AquisitionStatus maintains state and control of the teensy.
    * CLTask.cpp:
    - Expanded RPC with LAUNCH (launches main-loop) and LAND (ends experiment, prepares for re-launch)
    - Return Codes added
    - Send connected board IDs wi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
2016-08-01 Fixed a few minor issues found during circuit hub uploading process.
    [cyclops.brd, cyclops.sch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]
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2016-08-03 Reduced DRC tolerances to get discount with CircuitHub.
    [cyclops.brd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]
2016-08-05 Update MANUAL.md
    Fixed link for Arduino Compatible Reflow Oven Controller Shield. Added link for DIY reflow oven.
2016-08-24 Fixed a couple circuit bugs found during prototype build.
    [cyclops.brd, cyclops.sch]
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2016-08-27 Changes from benchtop testing 3.6
    - Buck got replaced with LT uModule to reduce switching noise
    - low pass filter input to LED on circuit to prevent glitching.
    [cyclops.brd, cyclops.sch]
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2016-10-14 Moved the LED to drain side of FET
    - This prevents Vgs from dropping in nonlinear fashion as LED turns on.
    Not sure why LED was on low side to begin with.
    [cyclops.brd, cyclops.sch]
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2016-10-30 Fix silkscreen.
    [cyclops.brd, cyclops.sch]
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2016-11-27 Minor fixes after assembly of 3.6
    [cyclops.brd, cyclops.sch]
2016-11-28 Panel fixes after testing.
    [expansion-b-cutout.dxf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]
2016-12-19 Final fixes for 3.6
    - Fixed issue with parasitic oscillation in BJT booster stage
    - Fixed issue with bandwidth limit selection by simply removing cold
    switch and using the straight panel switch -- extra trace length does
    not matter because it engages the BW limit (self correcting)
    - Should be ready for production and master merge
    [cyclops.brd, cyclops.sch]
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2017-01-04 Thermal fixes after testing.
    [cyclops.brd, cyclops.sch, pcb-thermal-copper.sldprt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]
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2017-02-12 Level shifter and improvied thermal dissipation
    - Level shifter is required since DAC's logical thresh is 0.7 VDD which
    is 6V
    - Improvied thermal dissiplation for FET
    - Replaced finicky analog switch with a signal relay.
    [cyclops.brd, cyclops.sch]
2017-02-26 Minor silkscreen fix.
    - Updated gerbers.
    [cyclops.brd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]
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2017-03-31 Fixed erros found in pre-production check by Filipe.
    [cyclops.brd, cyclops.sch]
2017-04-09 Maual update for 3.6
    - Device assembly is no relatively up to date for 3.6 production.
    - Fixed more erros found in pre-production check by Filipe.
    - Added images of production process.
2017-04-17 More pre-production fixes for Filipe.
    - Better cutouts on Exapansion B in panel
    - Panel alignment
    - Schematic fixes (remove teensy cut trace/diode requirement)
    [cyclops.GBL, cyclops.GBO, cyclops.GBS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]
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2017-05-02 Small fix to panels
    - Replaced +12V label on expansion A with +6V which is correct.
    [panels.brd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]
2017-06-26 Added missing dimensions on heatsink drawings.
    [alu-heatsink.SLDDRW, alu-heatsink.SLDPRT]
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2017-12-02 Updated arduino examples for new Teensy 3.2 library
    - Fixes #19
    - Also several other fixes
    - Update MANUAL to account for changes
    - Added QC protocol used by OEPS
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2018-06-23 MANUAL update
    - Switch to pandoc markdown
    - Added descriptions of device controls
    - Lots of other fixes
2018-06-24 Replaced RSense with something more appropriate
    - 30W power resistor
    - Better heat sinking
    - Got ride of useless FET heat sink
    [cyclops.GBL, cyclops.GBO, cyclops.GBS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]
2018-06-25 Updates to MANUAL
    - Also minor PCB silk screen fixes
    [cyclops.brd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]
2019-09-27 Cyclops 3.7a
    - Replace 1 turn pot with 10 turn pot
    - Update panels to fit it
    - Add JST wire to board connector to connect it
    [cyclops.GBL, cyclops.GBO, cyclops.GBS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]
2020-07-14 Update Cyclops.h
    - Fixes #21
    - RISING/FALLING interrupt edge specification was misidentified as CHANGED instead of the actual macro, which is CHANGE
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2021-03-19 Added 13.3V enable delay to prevent LED flash at power up
    - Has a quick discharge circuit to prevent flash at power down as well
    - Relies on 3.3V rail produced by teensy. This means the teensy is
    required, but this was already the case with the OC proteciton circuit
    so I don't feel Im making a breaking change here.
    [cyclops.brd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]
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2021-04-10 Slightly increased some switch holes to accommodate TH assembly tolerances
    [panels.brd]
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2023-06-19 Corrected the potentiometer fixing hole.
    [panel_front.brd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]

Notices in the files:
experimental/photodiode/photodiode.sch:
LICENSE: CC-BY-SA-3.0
